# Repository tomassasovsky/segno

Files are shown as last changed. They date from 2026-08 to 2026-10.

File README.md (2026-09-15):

# Segno

A loopstation for recording and layering live music, with a Flutter interface, a native audio engine, and built-in foot controls.

Record a phrase, let it repeat, and add another part over it. Segno brings the recording controls, track state, and audio engine into one application. Its current product direction is a dedicated Linux appliance.

## See the interface

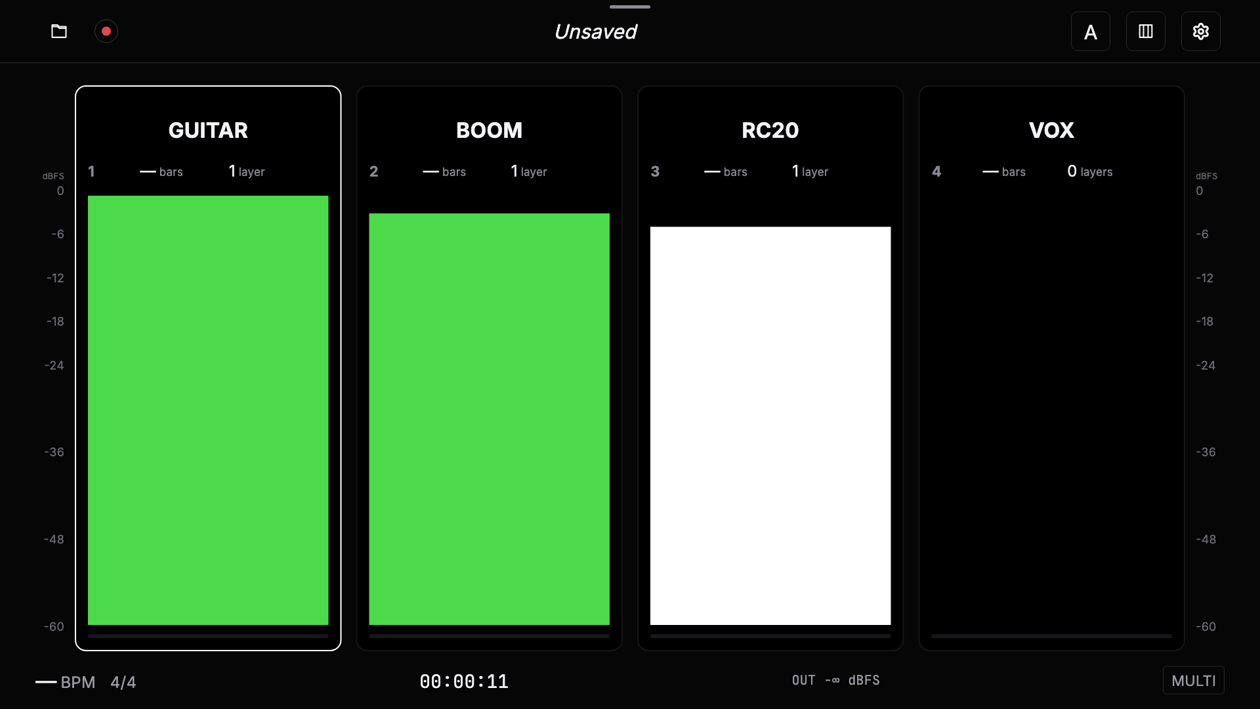
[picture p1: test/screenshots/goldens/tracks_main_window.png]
Segno’s Tracks interface showing four named tracks


*Flutter UI-test capture with simulated track state. Live audio demo pending.*

## Implemented capabilities

- **Record and layer audio.** The native engine implements loop recording, playback, overdubbing, undo, and redo.
- **Operate the looper by foot.** The console board connects ten footswitches, an encoder, and LED feedback to the app. External MIDI controllers use the controller mapping layer.
- **Save a session.** The session layer writes recorded audio and a manifest so the application can restore a loop’s state.
- **Keep the interface and audio engine separate.** Flutter handles the interface; a Dart engine interface connects the application to the native implementation through FFI.

## Explore the engineering

Created by [Tomás Sasovsky](https://github.com/tomassasovsky). The project includes the application, native audio engine, controller integration, pedal firmware, and hardware designs.

- [Audio engine and Dart interface](https://github.com/tomassasovsky/segno/tree/master/packages/segno_engine)
- [Console board and firmware](firmware/console_board/README.md)
- [Controller mapping](https://github.com/tomassasovsky/segno/tree/master/packages/controller_repository)
- [Session storage](https://github.com/tomassasovsky/segno/tree/master/packages/session_repository)

## Development and project status

Start with the [build and test notes](https://github.com/tomassasovsky/segno/blob/master/docs/PROGRESS.md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) for the development environment, native engine checks, and Flutter test commands.

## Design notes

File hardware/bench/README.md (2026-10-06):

# Bench tests

Tools that only mean something with hardware in front of you. They live here
rather than in `firmware/test/` because nothing in CI can run them.

| Script | What it proves |
| --- | --- |
| `midi_din_test.py` | The console board's two DIN MIDI sockets carry exact bytes in both directions ([#1007](https://github.com/tomassasovsky/segno/issues/1007)) |

---

## midi_din_test.py — DIN MIDI, after fitting the SN74AHCT125N

**Resolved on 2026-09-17: the OUT socket had DIN pins 4 and 5 swapped.** The
chip was not the cause. The test below is what proved it, and it is the test to
re-run whenever this wiring is touched.

The record of the September 4 session is
[`docs/research/2026-09-05-din-midi-bench.md`](../../docs/research/2026-09-05-din-midi-bench.md):
MIDI IN passed 48/48 bytes, MIDI OUT sent 48 bytes from the UART and the Scarlett
received none. U1 was fitted with an **SN74HC125N** where the design asks for an
**SN74AHCT125N**, which is a plausible cause and was never confirmed. This script
is that session's procedure, so the retest is one command instead of an evening.

### Before the swap, look at the panel

**The same chip drives the ring and the indicator pills** on this board (U1 gate B
and gate A; MIDI OUT is gate C). They work today with the HC part fitted. So if
the LEDs keep working after the swap but MIDI OUT still fails, the chip was never
the fault, and the DIN wiring or J4 is where to look next. Note what the panel
does now, before you change anything.

### Fit the part

1. Power the console down and unplug it. Fit the **SN74AHCT125N** at U1.
2. Read the top of the part: it must say `SN74AHCT125N`. `HC` is the part that is
   coming out; the letters are the whole difference.
3. Pin 1 goes where pin 1 went: the notch faces the same way as the old part and
   as the silkscreen. Check every pin sits in its hole before soldering.
4. Power up and confirm the ring and the pills still light. If they stopped, the
   part is in backwards or a pin is folded under the body — stop and fix that
   before testing MIDI.

### Cable it up

- Appliance **MIDI OUT** to the interface's **MIDI IN**.
- The interface's **MIDI OUT** to the appliance **MIDI IN**.

Check the labels on the sockets rather than trusting the last person's cabling:
the plugs were deliberately swapped during an earlier diagnostic.

### Run it

Copy the script to the appliance and run it there:

```bash
scp hardware/bench/midi_din_test.py root@192.168.50.124:/tmp/
```

```bash
ssh root@192.168.50.124 'python3 /tmp/midi_din_test.py --preflight'
```

`--preflight` changes nothing. It reports whether `/dev/ttyAMA0` exists, whether
`amidi` is installed, and which MIDI ports ALSA can see. If the UART is missing,
UART0 is not enabled: the earlier session applied the image's own `uart0-pi5`
overlay at runtime, and that does not survive a reboot.

```bash
ssh root@192.168.50.124 'python3 /tmp/midi_din_test.py --loopback'
```

The UART's internal loopback, with no board and no cables in the path. It proves
the script, the UART and the baud rate before any result about the board means
anything. The real test always runs with loopback off.

```bash
ssh root@192.168.50.124 'python3 /tmp/midi_din_test.py'
```

The acceptance test. Three trials per direction — notes 60, 61 and 62 — each one
sixteen bytes: note on, note off, three CC 22 values and a clock byte. It prints
every trial, the bytes when they differ, and the UART's own error counters. It
exits 0 only on a pass.

`--port` names the interface when more than one is connected (`--port scarlett`),
`--only in` or `--only out` runs a single direction, and `--uart` moves off
`/dev/ttyAMA0`. The pedal link's UART is refused by name — it carries the console
board's traffic and must not be reconfigured.

### What counts as a pass

**48 of 48 bytes in each direction, byte for byte, with no framing, parity or
overrun errors, and the internal loopback off.** Anything less is a fail, and a
direction that passes two trials out of three is a fail.

### If OUT still fails

The script prints the measurement list. In short: 5 V at U1 pin 14, enable
(pin 10) at 0 V, about 3.3 V on pin 9 and 5 V on pin 8 with TX idle, then
continuity from J4 through its 220 Ω resistors to the DIN pins. The bench doc has
the full connector map, and a DIN socket's front and rear views are mirrored —
read the pin numbers rather than inferring them.

### What this does not prove

That Segno sends or receives MIDI through these sockets. The app's MIDI input was
connected to ALSA Midi Through, not to this UART, and nothing here makes the UART
configuration persist across a reboot. That integration is separate work; raw DIN
traffic passing is only the hardware half.

Record the result on [#1007](https://github.com/tomassasovsky/segno/issues/1007),
including which cause turned out to be the real one.

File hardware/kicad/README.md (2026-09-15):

# Board generators

SKiDL scripts that emit KiCad netlists. One per board:

| script | board |
|---|---|
| `main_board.py` | standalone pedal — Pro Micro (ATmega32U4) |
| `ring_board.py` | encoder + LED ring + XIAO RP2350, behind the faceplate (4-way link, #987) |
| `console_board.py` | console v3 — Pico 2 on the Pi's GPIO (#747); v3 adds the 4-way ring link (#987) and the CTRL ring sense |

## Running them

```bash
python3.12 -m venv .venv && ./.venv/bin/pip install -r requirements.txt
cd hardware/kicad && ./.venv/bin/python console_board.py
```

**Run from `hardware/kicad/`.** `generate_netlist()` writes `<script>.net` into the
current working directory, so running from the repo root silently drops the netlist
in the wrong place while reporting success.

## Two things that will mislead you

**A netlist diff is not a design change.** SKiDL assigns a *random* `SKiDL Tag` to
every `Part` without an explicit `tag=`, and component `tstamps` derive from it. Two
runs of the **same** version on unchanged source differ by ~190 lines — all tags,
timestamps and the tool version string, with **zero** net changes. Pinning skidl does
not fix this. Judge a run by `0 errors found while running ERC` and the `(net ...)`
blocks, not by `git diff`.

**Prefer upstream footprints.** `segno.pretty/` exists for parts KiCad does not ship
(the NeoPixel Ring 24, the EC11 on its ring board, the module mount-pad and wire-pad
helpers). It is not a place to re-draw something that already exists. The Pico 2, for instance, is KiCad's own
`Module:RaspberryPi_Pico_Common_THT` — its description explicitly says it supports
Pico 2, and it is maintained upstream.

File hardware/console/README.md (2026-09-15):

# Segno Floor Console — hardware design

Hardware for the standalone Pi 5 floor console. The BOM is
[`hardware/segno_console_shopping_list.md`](../segno_console_shopping_list.md).
Footswitches, the encoder, the CTRL jacks, MIDI and the WS2812 drive all
terminate on the **console board v2** — a Pico 2 (RP2350) board on a short
keyed ribbon to the Pi's 40-pin header
([`hardware/kicad/console_board.py`](../kicad/console_board.py), #747). The Pi
reads no controls directly and never bit-bangs WS2812; the earlier plan of a
USB-MIDI pedal board plus a separate RP2040 LED driver is dead. The Pico runs
[`firmware/console_board`](../../firmware/console_board/), and
[`pedal_link.h`](../../firmware/console_board/pedal_link.h) is the wire format
of the link to the Pi.

> **Status:** the board is fab-ready (#747); the enclosure is designed under
> `hardware/enclosure/`; the assembled-unit gates (latency soak, stage-abuse)
> are physical work, tracked as the on-hardware checklist in
> [`docs/RUNNING_ON_RPI.md`](../../docs/RUNNING_ON_RPI.md).

## Power

Canonical since #754: **one 20 V USB-C PD contract at a rear-panel coupler,
two 20→5 V bucks split by rail** — BUCK_PI feeds the Pi (via its USB-C, 25 W
worst case), BUCK_AUX feeds both screens, the console board and the LEDs (34 W
worst case). No mains enters the enclosure; the fuse sits in the 20 V feed.
The full budget, the trim/window arithmetic, and the wiring live in
[`segno_wiring.md` §2](../segno_wiring.md) — this README no longer keeps its
own copy of the table, because two copies of a power budget is how one goes
stale.

Rules that survive any future edit:

- The LED chain must **not** draw off the Pi's 5 V pin (ribbon pins 2/4 are
  deliberately unconnected — the board's `PI_POWER` gate enforces it).
- WS2812 peak is ~60 mA/LED at full white; cap brightness in firmware to keep
  the worst case inside BUCK_AUX's budget.
- The Pi caps downstream USB at 600 mA unless `usb_max_current_enable=1` is in
  `config.txt` — required, the touch panels and audio interface hang off it.

## Thermals

A Pi 5 in a closed enclosure under sustained audio + dual-display GPU load will
throttle without help:

- **Active cooling is required** — the official active cooler or an equivalent
  heatsink+fan, with an intake/exhaust path in the enclosure.
- **Soak gate (on-hardware):** ≥2 h of audio + dual-display + GPU load in the
  closed enclosure with **no thermal throttle** (`vcgencmd get_throttled` stays
  `0x0`) and no xrun-rate regression. Record results in `docs/RUNNING_ON_RPI.md`.

## Enclosure

Designed and generated under [`hardware/enclosure/`](../enclosure/) (sheet
metal, printed platforms, rear-panel stations); `segno_enclosure_design.md`
carries the design story. The 16″ touchscreen and 7″ waveform panel mount up
top; the footswitch + encoder deck is the stomp face; the Pi and the console
board both sit under the 16″ screen with the rear I/O cluster directly above
the board.

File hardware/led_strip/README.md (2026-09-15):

# segno LED strip

> **NOT USED BY THE CONSOLE, and do not order it for one (#930).** The console's
> pill indicators are eight-LED segments cut from 144 LEDs/m bare strip, and the
> diffuser channel is sized for a 12 mm x 0.53 mm strip — this 16 x 8 x 1.6 mm
> board will not go in. `hardware/MANUFACTURING.md` carries it at quantity 0.
> The design below is kept because it is finished and may suit another build.

Single-LED WS2812B indicator puck for the Segno console: **one board per
indicator pedal**, sitting under that pedal's small pill diffuser slot in the
faceplate. One board is 16 x 8 mm, 2-layer, 1.6 mm, carrying **1x WS2812B
5050 addressable LED** (with its 100nF 0603 decoupling cap) and **castellated
half-hole pads on both 8 mm ends**.

```
 left edge                                right edge
 [5V ]──── +5V rail (top edge) ──────────────[5V ]
 [DI ]───────────D1──────────────────────────[DO ]
 [GND]──── GND rail (bottom edge) ───────────[GND]
           + full GND pour on the bottom copper
```

## How boards chain

Boards daisy-chain **pedal to pedal with three short wires** (5V / DATA /
GND, same pad order top-to-bottom on both ends — left-end DATA is DIN,
right-end DATA is DOUT) soldered to the castellated end pads. The
castellations also allow butting boards edge-to-edge (the LED sits 8 mm from
each end, so a butted pair keeps a 16 mm pitch) if a bar is ever wanted.

Console usage:

| row | pedals with LEDs | boards | LEDs |
| --- | --- | --- | ---- |
| above pedal 1 | MODE | 1 | 1 |
| front row | TRACK1..TRACK4 | 4 | 4 |
| mid row | CLEAR, BANK | 2 | 2 |
| per console | | 7 | 7 |

Feed 5V/GND once (seven indicator LEDs draw ~420 mA absolute worst case, far
less in practice). Data enters at DI on the first puck and daisy-chains
through every LED.

## Buy instead of build

Off-the-shelf single-WS2812B modules (round or square breakout pucks, sold in
tens for pocket change) are electrically identical — 5V/DIN/GND/DOUT, one
5050 — and drop into the same slots and wiring. This board exists for a
cleaner form factor and castellated wire pads; use whichever is at hand.

## Ordering (JLCPCB)

- 2-layer, 1.6 mm, any colour; the board is 16 x 8 mm — well under the
  100 x 100 mm cheap-tier limit.
- **Tick the "Castellated Holes" option.** The end pads are full plated 1.6 mm
  pads (0.8 mm drill) centred exactly on the board edge; the castellation
  process mills the edge through them leaving half-holes. Without the option
  the fab may flag the edge-breaking holes.
- Upload `out/segno_led_strip_gerbers.zip` (gerbers + Excellon drills).
- Parts if hand-placing: 4x WS2812B (5050 PLCC4), 4x 100nF 0603 per segment.

## Regenerating

The board is generated programmatically with KiCad 10's `pcbnew` module —
plain `python3` does **not** have it, use KiCad's bundled interpreter:

```sh
cd hardware/led_strip
/Applications/KiCad/KiCad.app/Contents/Frameworks/Python.framework/Versions/Current/bin/python3 ledstrip_pcb.py
```

This runs a geometry assertion suite, builds the board, fills the GND pour and
runs DRC via `kicad-cli` (the run fails loudly if DRC does), and writes to
`out/`:

- `segno_led_strip.kicad_pcb` — openable in KiCad
- `gerbers/` + `segno_led_strip_gerbers.zip` — fab package
- `drc.json` — full DRC report (expected: 0 violations, 0 unconnected)

All dimensions (LED count, pitch, rail widths, via rows…) are parameters at
the top of `ledstrip_pcb.py`; the netlist, routing and silkscreen are derived.

Design notes live as comments in the generator — in particular why the +5V
rail runs on the top edge and GND on the bottom (the WS2812B PLCC4 pinout
1=VDD 2=DOUT 3=GND 4=DIN puts VDD/GND on the package diagonal), and why the
data chain hops on the bottom copper (each LED's rail-to-rail decoupling cap
blocks the top-layer corridor).

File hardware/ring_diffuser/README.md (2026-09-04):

# Ring 16 snap-on diffuser — temporary bench part

A diffuser cap that clips onto a **16-pixel WS2812 NeoPixel ring** with nothing
else involved: no faceplate, no glue, no standoffs. The top face is **solid right
across**; the only opening is a Ø7 hole for the EC11's threaded bush. It exists
so a bare ring on the bench reads as a soft lit face instead of 16 point sources,
before there is any panel in front of it.

**This is not the console ring window.** That one is a Ø67 / Ø51.5 annulus cut
in the faceplate over a **Ring 24**, with the diffuser glued to the faceplate
underside — `RING_OD` / `RING_ID` in [`../enclosure/segno_enclosure.py`](../enclosure/segno_enclosure.py),
issues #791 / #794. The two parts do not interchange.

Generated by [`ring16_diffuser.py`](ring16_diffuser.py) (cadquery); run with the
enclosure venv:

```bash
../enclosure/.venv/bin/python ring16_diffuser.py
```

Outputs in `out/`: `segno_ring16_diffuser.step` (editable CAD) + `.stl` (print)
+ three SVG views. `segno_ring16_diffuser_skirt.*` is the no-hooks variant.

| | |
|---|---|
| fits | Adafruit NeoPixel Ring 16 (1463), Ø44.45 / Ø31.75, 1.6 mm PCB |
| part | Ø47.25 outer, solid face, Ø7 bush hole, 8.9 mm tall, ~3.3 g |
| face | 1.0 mm white PLA, 3.0 mm over the LEDs, 2.5 mm over the encoder body |
| holds on | 3 snap fingers, 0.5 mm under the PCB, 1.6 % strain |
| needs | **1.7 mm of air under the ring** for the hooks to swing under |

## Why the face can be solid

Because the EC11's own top face sits only **~0.5 mm above the LEDs**
(`ENC_FACE_RISE`, measured on the real assembly). Nothing in the middle is tall
enough to need clearing — only the bush carries on upward. That is the single
measurement this whole shape rests on, so the script asserts it: the roof
underside has to clear the encoder's body envelope, or `build()` refuses.

If your encoder turns out to stand proud of the LEDs by more than ~2.5 mm, raise
`AIR_GAP` and the face lifts with it.

### The bush hole

Ø7.0, as asked. Worth knowing: the console faceplate uses **7.2** for the same
encoder — *"M7 thread; 7.0 was nominal-tight, the vendor STEP shows the thread
OD needs the 0.2"* (`D_ENC`, #762). FDM holes also tend to come out under
nominal. If it will not pass the bush, that is why:

```bash
../enclosure/.venv/bin/python ring16_diffuser.py --enc 7.2
```

## Measure your ring first

Sellers ship "NeoPixel Ring 16" clones that are **much** larger than Adafruit's
— 68 mm and up. Electrically identical, mechanically a different part, and one
of those will not go on this cap. Put calipers across the ring before you print:

```bash
../enclosure/.venv/bin/python ring16_diffuser.py --od 68 --id 55 --pads 70 115 205 295
```

`--pads` matters as much as `--od` — and pass **every** pad, since the fingers
are placed in the gaps between the ones you name. Four evenly spaced pads leave
no three-way spread that encloses the centre; that case wants `--arms 4`, and the
assertion says so.

The three fingers are clocked into the gaps
between the ring's four **back-side** solder pads (JP1–JP4), which on the
Adafruit Ring 16 sit at **79° / 124° / 214° / 304°**, r ≈ 21 mm. Those angles are
lifted from `../kicad/segno.pretty/ModuleMountPads_4.kicad_mod`, which was
extracted from Adafruit's own board file for this exact ring — they are geometry,
not a guess, and they do **not** carry across ring sizes. A finger landing on a
soldered wire simply will not seat, so the script asserts the clearance and
warns when you feed it a ring that is not the one those angles came from.

## Print it

- **White PLA**, same call as the pill diffusers in the enclosure (#239). Not
  clear, not natural — white is what scatters.
- **Face down on the bed. No supports.** The face is a solid 1715 mm² disc, so
  the part is flat and well anchored — none of the stilt-warping that bit the
  mini tray. Both barb faces are 45°, so the fingers self-support.
- 0.2 mm layers are fine. The face is 1.0 mm ≈ 5 layers; **solid infill in the
  face** or light leaks through the sparse pattern as a visible grid.
- Do not iron it. The bed's own texture scatters better than a glassy face.

## Fit it

1. Check there is ~1.7 mm of clear air under the ring. Pin-mounted on the ring
   board or on standoffs, there is. **Flat on a bench or bonded down, there is
   not** — print `--skirt-only` instead. Note what that gives up: the hooks are
   the only thing holding the cap on, and the shroud is a **slip fit** (0.20 mm
   radial), so the no-hooks variant will lift straight off. If it has to stay
   put, tighten it — `--skirt-only --clr 0.05` — and expect to adjust once on
   your own printer, because ±0.1–0.2 of FDM tolerance on a Ø44 bore covers both
   "will not go on" and "falls off".
2. Drop it over the bush and line the three fingers up with the bare stretches
   of the ring's back, away from the four solder pads.
3. Press straight down until all three click. Spread them slightly by hand if it
   fights you — the fingers run at 1.6 % strain, which PLA is happy with for a
   handful of cycles, not fifty.
4. To remove: lever one finger out at a time. The 45° retention face is
   deliberately easy to release.

There is ~0.2 mm of axial play once it is on — the barb rests on the PCB's back
corner, and nothing pulls the cap down against a stop. It rattles a little and
diffuses the same. If your bush is long enough to reach past the face, the
encoder's own M7 nut will clamp the cap down and take the play out.

## Tuning

Everything worth changing is a constant at the top of the script.

- `AIR_GAP` (3.0) — the blending knob, and the encoder clearance. 16 pixels at
  r ≈ 19 mm are 7.5 mm apart, so 3 mm reads as *soft dots*. Raise it to 5 mm for
  a continuous band; the part grows by the same amount.
- `ROOF_T` (1.0) — thicker scatters more and passes less.
- `ENC_D` (7.0) — the bush hole. See above.
- `HOOK_ENGAGE` (0.5) / `ARM_T` (0.9) — grip vs. snap strain. `_check()` refuses
  anything over 3 % strain, so you cannot quietly design a finger that snaps off.

The script's `_check_clearances()` probes the finished solid: the bush passage
open end to end, nothing below the encoder's face plane inside its body
envelope, nothing sitting where the ring's PCB and LEDs live, and a face that is
solid at every radius from the bush hole out to the rim. It is there because a
bad boolean in CAD fails *quietly* — an early draft revolved the barb about the
wrong axis, produced a zero-volume solid, and the intersect handed back the full
pie wedges. That STL exported and rendered fine and was completely wrong.

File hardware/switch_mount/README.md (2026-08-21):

# Cherub WTB-006 silent switch platform

The printed platform that carries a silent switch inside a Cherub WTB-006
footswitch shell, replacing the pedal's own clicky switch (#729).

| | |
|---|---|
| Source of truth | Fusion document **"Cherub WTB-006 silent switch platform"** (Default Project) |
| Exports here | `switch_platform.step` (CAD interchange), `switch_platform.stl` (print) |
| Envelope | 66.85 x 57.38 x 10.60 mm, 8.06 cm3 |
| Print | PLA is fine — the part takes compression from the stem, not impact |

## Provenance

Authored **by hand in Fusion**, not generated. An earlier CadQuery attempt
(`generate_stl.py`, box-and-pins parametric) was abandoned: its default
`PIN_CLEARANCE` produced a 12.1 mm box whose stem overshot the pedal interior
by ~3 mm, so the lid could not close, and the fix was never settled. The Fusion
part solves the same problem at 10.60 mm. Do not resurrect the generator —
edit the Fusion document and re-export.

## Re-exporting after a Fusion edit

Open the document, then export the root component to both formats, replacing
the files here (STL: binary, high refinement). Keep the two exports in the same
commit so the STEP and the STL never describe different revisions.

## Still open on #729

The physical fit check. #729 is `blocked-verify`: it closes when a printed
platform is confirmed in the pedal shell with the lid closing and the switch
actuating at the intended pre-travel.

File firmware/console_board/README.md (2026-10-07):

# Segno console board v2 — Pico 2 firmware

The console's pedal firmware: `console_board.ino` on the board's Pico 2 (RP2350,
`hardware/kicad/console_board.py`, #747). A pure thin client, like the pedal it
replaces — it holds no looper state. It sends raw footswitch and encoder events
to segno over the link and renders the encoder ring and all ten eight-pixel indicator pills from
the state frames segno pushes back. segno runs the behavior machine.

| Signal | GPIO | Notes |
|---|---|---|
| Link TX / RX | GP16 / GP17 | UART0 → Pi uart3 (GPIO8/9, `/dev/ttyAMA3`), 115200 8N1 |
| Footswitches | GP2–GP11 | REC/PLAY, STOP, UNDO, MODE, TRACK1–4, CLEAR, BANK. Internal pull-up, active low, 8 ms stable-edge debounce |
| Ring data | GP12 | **v2 only**: via 74AHCT125 → J6 pin 5, one continuous 40-pixel GRB strip. On v3 (#987) the ring board clocks its own LEDs and GP12 is on the expansion header |
| Encoder A / B / SW | GP13 / GP14 / GP15 | **v2 only**: internal pull-ups plus the board's 10 k to the Pi's 3V3; one message per detent, decoded from pin-change interrupts. The push switch (SW) is active low and debounced like a footswitch (8 ms stable edge), one `ENCODER_BUTTON` message per press and per release |
| Ring link | GP13 / GP14 | **v3** (#987): full-duplex UART to the ring board's XIAO RP2350 — GP13 drives, GP14 listens, 115200, PIO UART (neither pin is on a free hardware UART). The console board's 10 k pull-ups hold both lines. **Not implemented in this firmware yet**: it still drives GP12 and reads GP13–15 as an encoder, which is the v2 board |
| Indicator data | GP18 | via 74AHCT125 → J7 pin 2, **80** GRB WS2812 pixels, eight per pill, sent with PIO/DMA |
| CTRL1 / CTRL2 tip | GP26 / GP27 | ADC0 / ADC1: a footswitch at the rails, an expression pedal's wiper between them. The first press on a jack the board has not yet classified is held 200 ms (a plug sliding in drags the tip low the same way); once the jack is known to hold a footswitch, edges are debounced at 8 ms and sent at once |
| CTRL1 / CTRL2 ring | GP20 / GP21 | On v3 a trace from each jack's ring through 4.7 kΩ (R19/R20). **Not a trace on v2** — one wire from each jack's ring pin to the J22 expansion pads does the same. With it, the B switch of a two-switch pedal (a BOSS FS-6's A&B jack) reports as `CTRL n · footswitch B` (its first press on a jack the board has not yet seen a switch on is held 200 ms, so a plug brushing the contact cannot fake it); without it the pin's internal pull-up holds it open and nothing reports |
| CTRL1 / CTRL2 present | GP19 / GP22 | Internal pull-down, **present = low**. On v3 the switched jack's tip-normal contact (Neutrik NJ6FD-V, through 4.7 kΩ R21/R22) drives it high only while the jack is empty; an empty jack reports CTRL kind `NONE` and is classified afresh on the next plug. On v2 these are J22's unpopulated pads: they float low, every jack reads "plugged", and the firmware's plug heuristics (a 40% jump starts a 200 ms quiet period; a jump that parks on the top rail for 1 s is an empty jack) do the same job less certainly |
| SMPS mode | GP23 | Driven high: PWM mode, less ADC ripple |
| PD trigger I2C | GP0 / GP1 | **v3** (J23): I2C0 SDA/SCL to the STUSB4500 on the SparkFun PD board, to read the negotiated contract (RDO 0x91–0x94, capability mismatch; voltage at 0x21) and report it up the pedal link. **Not implemented in this firmware yet.** On v2 the same read is possible from J22's GP20/GP21 when those pads are free |

## Physical rendering and source boundary

Firmware 1.13 uses public UART protocol 9 (protocol 8 plus `ENCODER_BUTTON`;
the STATE layout is unchanged). The physical renderer is reconciled
from PR #1079 (`ecea3af76fdb0708ca04632e260de5aa3fde09cd`), whose old-v2
firmware 1.11 used protocol 7 with a different 21-byte Song queue payload.
PR #1082 also uses public protocol 7 (and historical 6 for PD telemetry), with
a separate new-v3 pin map and private ring link. Neither format is accepted
here. Reconstructed Custom protocol 6 was a software intermediate and is not a
standalone hardware recommendation. Update this firmware and its matching app
together; no downgrade or compatibility format is emitted.

The fitted chain order is Track4, Track3, Track2, Track1, Mode, Undo, Stop,
Record/Play, Clear, Bank. The first eight groups enter from the right;
Clear/Bank enter from the left. Button IDs on the wire keep their existing
Record/Play, Stop, Undo, Mode, Track1–4, Clear, Bank order.

The app supplies every pill's active bit and RGB hue. Inactive means dark;
local switch contact, legacy track colors and mode do not override that fact.
Optical output retains the sourced peak 191, center weights
38/92/201/255/255/201/92/38, color gamma and total channel budget 6000.
The limiter recomputes from the source frame so refreshes do not progressively
dim the display. NeoPixelBus PIO/DMA preserves interrupts during the longer
80-pixel transfer. Forced refresh, goodbye and stale-link darkening cover the
whole chain. RGB black is a valid deliberately dark hue.

The independent 40-pixel ring retains the sourced sustained comet: 1100 ms per
turn, 30 lit positions, fractional circular interpolation, peak duty 192 and
color-only gamma. It freezes position/color on a stopped loaded loop, shows
master gain for 900 ms, and breathes green when empty. Ambient/startup output
retains brightness 96; every transfer has a total channel budget of 11520.
The combined estimated current is about 1.635 A including assumed pixel idle
and logic consumption. This is a planning bound, not a measured guarantee.
The app's semantic activity fields drive the ring independently of pill hue.

Only this physical renderer and its limits are sourced from #1079. Its Song
queue fields and progress-fill behavior, native audio changes, bench diagnostic
and CAD are excluded. New-v3 ring UART/PD firmware is a separate hardware
boundary. No physical deployment or electrical/optical validation is implied
by the host tests or a successful Arduino compile.

## Wire format: the pedal link

`pedal_link.h` / `pedal_link.c` is the whole protocol, plain C99, and it is
mirrored byte for byte by `PedalLinkCodec` in `packages/pedal_repository`. Every
message is one frame: `A5 <type> <len> <payload> <xor>`, where `xor` covers
type, length and payload. Plain 8-bit bytes — no MIDI, no 7-bit packing, no
version byte on the state frame; `HELLO` carries the protocol version so a
mismatched build shows up in segno's log and cannot exchange control/state.
STATE bytes 0–18 retain their current meanings; bytes 19–48 hold ten RGB
triples, and bytes 49–50 hold the physical activity mask (bits 10–15 must be
zero). The parser accepts exactly 51 bytes and preserves the last good frame
on malformed input. Logical track LEDs remain snapshot facts; they do not
compete with the ten-button mask for physical output.

| Type | Direction | Payload |
|---|---|---|
| `0x01 BUTTON` | board → segno | `button (0–9), pressed (0/1)` |
| `0x02 ENCODER` | board → segno | `int8 detents` (positive = clockwise) |
| `0x03 HELLO` | board → segno | `protocol, fw major, fw minor` — at boot and once a second; segno counts the board as connected while these keep coming |
| `0x04 CTRL` | board → segno | `jack, contact, kind, value` (unchanged four bytes) |
| `0x05 ENCODER_BUTTON` | board → segno | `pressed (0/1)` — the encoder's push switch, one message per debounced edge (protocol 9) |
| `0x10 STATE` | segno → board | 51 bytes: flags, mode, looper mode, global colour, bank, selected track, 8 track LEDs, loop length µs (LE32), master gain, ten RGB triples, active mask (LE16) — see `pedal_link.h` |

segno answers every compatible protocol-9 `HELLO` with its current `STATE`, so a board that just
(re)connected is current within a second; the board goes dark if no `STATE`
arrives for `PEDAL_LINK_FRAME_TIMEOUT_MS` (5 s) and on the goodbye flag, and
segno reads the board as disconnected after three silent hello intervals. Both
cadences live in `pedal_link.h`; the package's header test pins them. Frames the parser drops (bad type,
length or checksum) are counted on both ends; segno logs the count.

**Contract test.** `packages/pedal_repository` generates golden frames
(`test/fixtures/*.bin`) from the Dart codec; `firmware/test/run_tests.sh` decodes
and re-encodes every one with this C unit. Run it after touching either side:

```sh
bash firmware/test/run_tests.sh
# after changing the golden frames:
(cd packages/pedal_repository && flutter test tool/generate_golden_fixtures.dart)
```

## Build

Needs `arduino-cli`, the arduino-pico core (`rp2040:rp2040`, RP2350 support) and
`Adafruit NeoPixel@1.15.5` and `NeoPixelBus by Makuna@2.8.4`.

```sh
arduino-cli core install rp2040:rp2040 --additional-urls https://github.com/earlephilhower/arduino-pico/releases/download/global/package_rp2040_index.json
arduino-cli lib install "Adafruit NeoPixel@1.15.5" "NeoPixelBus by Makuna@2.8.4"
arduino-cli compile --fqbn rp2040:rp2040:rpipico2 firmware/console_board --output-dir firmware/console_board/build
```

`build/console_board.ino.elf` is what OpenOCD flashes; `.uf2` is for BOOTSEL drag-and-drop
if the module's USB is ever reachable (it is not, once the board is in the console).

## Flashing

The appliance does it. The image carries this firmware, an OpenOCD built for
the one adapter that reaches the board (`segno-openocd`), and a marker naming
the firmware version and link protocol the app expects; a oneshot before
`segno.service` listens for the board's `HELLO` and reprograms it over SWD only
when it is not already running what shipped (#989). So the two halves of a
build cannot ship out of step, and a board is repaired by a reboot rather than
by a laptop.

The board routes the Pi's GPIO24 (SWCLK, ribbon pin 18) and GPIO25 (SWDIO, pin
22) straight to the module's debug pads, so the Pi is the programmer. SWDIO
needs a pull-up the Pi firmware does not apply by default — `gpio=25=pu` in
`config.txt`, which the image sets.

To flash by hand during bring-up, on the unit:

```sh
segno-openocd -f /usr/lib/segno/console-board/pi5-swd.cfg \
  -c "program /usr/lib/segno/console-board/console_board.elf verify reset exit"
```

Point `program` at your own build to try a change; the next boot puts the
shipped firmware back, which is the intended behaviour — the image is the
source of truth for what the board runs.

## Talk to it from the Pi

With `dtoverlay=uart3-pi5` in place the link is `/dev/ttyAMA3` and segno opens it
itself (`UartPedalLink` in `packages/pedal_repository`). For a bench check
without the app, watch the hellos arrive:

```sh
stty -F /dev/ttyAMA3 115200 raw -echo
od -An -tx1 -w7 -v /dev/ttyAMA3    # a5 03 03 09 01 0d 05 (HELLO, protocol 9, fw 1.13), once a second
```

## Bring-up record

**2026-09-03, first unit.** Flashed over SWD from the appliance image (kernel 6.18,
RP1 = `gpiochip0`); OpenOCD found both Cortex-M33 cores, programmed and verified
the ELF, and the board came up on `/dev/ttyAMA3` at the first try. Verified on the
bench: all ten footswitches (clean DOWN/UP, correct order), encoder button, encoder
rotation (one message per detent, sign fixed so clockwise counts up), Ring 24 lap
in three colours and solid fill via J6, CTRL1/CTRL2 reading full scale through their
pull-ups with nothing plugged in — all with the bring-up text console this
firmware started as. Not yet exercised: indicator chain on J7 (no pucks
fitted), MIDI in/out (Pi side), CTRL jacks with a pedal, and the pedal-link
firmware itself against the app.

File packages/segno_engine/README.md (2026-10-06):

# segno_engine

Native low-latency **duplex audio engine** for Segno, exposed to Dart over FFI.

This is the data-layer foundation of the loopstation: a hand-written
[miniaudio](https://miniaud.io)-based engine that owns the real-time signal path
on the OS audio callback thread, with a typed Dart API for control and state.

> **Phase 1 scope.** Today the engine does duplex passthrough, level metering, a
> loopback round-trip **latency harness**, and ships the lock-free command-ring
> foundation. Recording, overdub, looping, and multi-track mixing arrive in later
> phases on top of this same boundary.

## The FFI boundary contract

```text
Dart (UI isolate)                         Native engine (C)
─────────────────                         ─────────────────
AudioEngine API  ──► le_engine_post_command ──► SPSC ring ─┐
                                                           ▼
snapshot() ◄── le_engine_get_snapshot ◄── atomics ◄── AUDIO CALLBACK THREAD
```

- **Commands** flow Dart → engine through a single-producer/single-consumer
  lock-free ring (`lockfree_ring.[ch]`), drained at the top of each callback.
- **State** flows engine → Dart through per-field atomics, read by
  `snapshot()` on a render-rate timer. Readers never dereference engine memory
  from the audio thread.
- Dart **never** blocks or allocates on the audio thread.

### Real-time safety rules (audio callback)

The audio callback (`le_engine_process` in `src/core/engine_process.c`) must
never:

- `malloc`/`free`, take a lock/mutex, or perform file/socket I/O;
- run an unbounded loop or call back into Dart.

All buffers are pre-allocated before the device starts. State is published with
relaxed atomic stores; control commands arrive only through the SPSC ring.

## Layout

The native sources under `src/` are grouped by concern:

| Path | Role |
| --- | --- |
| `src/core/segno_engine_api.h` | The C ABI consumed by ffigen (POD + opaque handle). |
| `src/core/` | The portable engine, split into per-concern TUs: `engine.c` (control-thread core + shared helpers), `engine_process.c` (the audio-thread TU — `le_engine_process`, transport, `apply_command`), `engine_fx.c` (effects DSP), `engine_commands.c` (control-thread setters), `engine_devices.c`, `engine_snapshot.c`, `engine_session.c`, `engine_convert.c`, `engine_digest.c` (SHA-256, file digests and directory sync; engine-free), `engine_miniaudio.c` (the miniaudio backend), plus the `lockfree_ring` / `loop_clock` primitives and the private/internal headers. |
| `src/platform/` | Per-OS device seams (`engine_apple.c` / `engine_linux.c` / `engine_windows.c`). |
| `src/midi/` | Native MIDI seam: `midi.c` (portable core) + per-OS backends. |
| `src/asio/` | Windows ASIO backend (`win_asio_device` / `win_asio_labels`). |
| `src/miniaudio/` | Vendored miniaudio (MIT-0 / public domain) + `miniaudio_impl.c`. |
| `src/test/` | Native unit tests + `run_native_tests.sh`. |
| `lib/src/audio_engine.dart` | `AudioEngine` interface (the test seam). |
| `lib/src/native_audio_engine.dart` | FFI-backed implementation. |
| `lib/src/generated/` | ffigen output — do not edit by hand. |

Every `src/` subdirectory holding headers is on the compiler include path
(`src/CMakeLists.txt`), so the sources use flat `#include "engine_private.h"`
regardless of which folder they live in.

## Building

The plugin builds automatically as part of `flutter run`/`flutter build` for
macOS, Windows, and Linux:

- **macOS** — compiled via `macos/segno_engine.podspec` (CoreAudio).
- **Linux** — `linux/CMakeLists.txt` → `src/CMakeLists.txt` (ALSA/PulseAudio/JACK
  loaded at runtime by miniaudio).
- **Windows** — `windows/CMakeLists.txt` → `src/CMakeLists.txt` (WASAPI; links
  `ole32`, `winmm`).

C11 is required for `<stdatomic.h>`.

### Regenerate FFI bindings

```sh
dart run ffigen --config ffigen.yaml
```

Requires `libclang` (ships with Xcode / LLVM).

### Run the native core tests

`src/test/run_native_tests.sh` builds and runs both native suites (engine + MIDI)
with the right per-OS toolchain flags and source/include paths:

```sh
bash src/test/run_native_tests.sh
```

It expects "ALL PASSED" from each suite. The engine source list it compiles
mirrors `src/CMakeLists.txt`; keep the two in sync when adding a TU.

## Usage

```dart
final engine = NativeAudioEngine();
final result = engine.start(const EngineConfig(sampleRate: 48000));
if (result.isOk) {
  final snap = engine.snapshot(); // levels, frame counters, latency
  engine.measureLatency();        // requires an output→input loopback
}
engine.stop();
engine.dispose();
```

## Latency measurement

`measureLatency()` emits a single full-scale impulse on the output and counts
the frames until it returns on the input, publishing the round-trip time via
`EngineSnapshot.measuredLatencyMs` (valid when `latencyState == done`). It
requires a **physical output→input loopback** (loopback cable or virtual
loopback device). With no loopback the harness reports `timeout`.

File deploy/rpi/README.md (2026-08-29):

# Segno floor-console kiosk deployment (Raspberry Pi 5)

Boots the Pi straight into Segno full-screen across both displays — 16″ main UI,
7″ waveform — under the **labwc** Wayland compositor chosen in Part 1. No
keyboard or mouse.

> **Status: unverified on hardware.** These units and scripts are written from
> the Part 5 plan but have not been brought up on a real Pi 5 + panels. The real
> acceptance gates — cold boot to the right panels, display pinning stable across
> ≥5 reboots, and usable per-panel scale — must be checked on hardware. See
> [`docs/RUNNING_ON_RPI.md`](../../docs/RUNNING_ON_RPI.md).

## Files

| File | Goes to | Purpose |
|---|---|---|
| `segno-kiosk.service` | `/etc/systemd/system/` | Boots the kiosk on tty1, respawns on crash |
| `boot-integrity-check.sh` | (unit `ExecStartPre=+`, root) | fsck + mount the writable data partition |
| `start-kiosk.sh` | (unit `ExecStart`) | Execs labwc, or shows the "needs attention" screen |
| `compositor/labwc/autostart` | `~/.config/labwc/autostart` | Pins displays, then launches the app |
| `compositor/labwc/rc.xml` | `~/.config/labwc/rc.xml` | Chromeless, maximized, no kill chord |
| `pin-displays.sh` | (run from autostart) | Deterministic output pinning by name |
| `profile-on-device.sh` | (run from your workstation) | Runs a profile bundle + tunnels the VM service for DevTools |
| `overlayfs/README.md` | — | Read-only root + writable data partition setup |

## Install

1. Build the release bundle:
   ```bash
   flutter build linux --release --target lib/main_production.dart
   ```
   segno builds only for the console now: no on-screen tracks toolbar (the
   foot pedals drive transport/mode/clear) and a layout fixed to the 16″
   panel. (The `build-linux-arm64` CI job guards that this compiles for
   arm64.)

   From a Mac (which cannot build a Linux bundle natively), run the containerized
   arm64 build instead — it wraps the exact command above and can `rsync` the
   result to the Pi:
   ```bash
   deploy/rpi/build/build-arm64-bundle.sh --deploy pi@<host>
   ```
   See [`build/build-arm64-bundle.sh`](build/build-arm64-bundle.sh) and
   [`build/Dockerfile.arm64`](build/Dockerfile.arm64).
2. Enable the labwc Wayland compositor (Pi OS default on Pi 5; confirm with
   `wlr-randr`, which must list outputs — see `docs/RUNNING_ON_RPI.md`).
3. Install the kiosk (systemd unit + labwc config) with the one-command installer,
   which sets it up for **your** user — no `pi` user required:
   ```bash
   deploy/rpi/install-kiosk.sh
   ```
   It substitutes your user/home/uid into the unit, copies the compositor config
   to `~/.config/labwc/`, sets the Pi to boot to console (so the kiosk owns the
   display), and enables the service. The boot integrity check is **opt-in** — a
   stock single-partition SD card boots straight to the app; set `SEGNO_DATA_DEV`
   only if you follow the read-only-root + writable-data-partition setup in
   [`overlayfs/README.md`](overlayfs/README.md).
4. **Edit `pin-displays.sh`** for your wiring: run `wlr-randr` to get the real
   connector names (e.g. `HDMI-A-1`, `HDMI-A-2`, or `DSI-1`) and set
   `SEGNO_MAIN_OUTPUT` / `SEGNO_WAVE_OUTPUT` and the per-panel scales.
5. Reboot. The unit starts labwc, which pins the displays and launches Segno.

## Display mapping & fallbacks

- **Pinning** is by connector name in `pin-displays.sh`, so the 16″ and 7″ never
  swap. The app's waveform second window lands on the secondary output; verify
  the actual window→output placement on hardware and adjust positions if needed.
- **Second-window failure is surfaced**, not silent: if the waveform window does
  not become ready, the app shows an operator-visible banner
  (`app_waveformWindowFailed_banner`).
- **Single display**: if only one display is connected, the app skips the
  waveform window and shows a notice (`app_singleDisplay_banner`) instead of a
  half-blank console. The Pi entrypoint wires the real display count
  ([`run_segno.dart`](../../lib/app/run_segno.dart)).
- **Per-display scale** is set with `wlr-randr --scale` in `pin-displays.sh`.
  Final values depend on the Part-6 HDMI-vs-DSI panel choice; tune on hardware.

## Profiling the UI on real hardware

The shipped bundle is **release-mode AOT** — no `kernel_blob.bin`, no Dart VM
service — so DevTools cannot attach to it, and the Yocto image is a pure runtime
with no `flutter`/`dart`/`gcc`/`ninja` so it cannot build a profile bundle
itself. macOS cannot cross-compile a Linux arm64 bundle either.

The containerized builder above (`build/build-arm64-bundle.sh`) is **release-only
today** — `segno-build.sh` hardcodes `flutter build linux --release`. Teaching it
a profile mode is the better long-term answer and would drop the CI round-trip;
until then the arm64 CI runner is the path that needs no local Docker.

1. Get a profile bundle from the `appliance-profile-bundle` workflow
   ([`.github/workflows/appliance-profile.yaml`](../../.github/workflows/appliance-profile.yaml)),
   which runs on demand or on any push to a `perf/**` branch:
   ```bash
   gh run download <run-id> -n segno-linux-arm64-profile -D /tmp/segno-profile
   ```
2. Run it on the device and tunnel the VM service to your workstation:
   ```bash
   deploy/rpi/profile-on-device.sh /tmp/segno-profile
   ```
   The script stops `segno.service` for the duration and restarts it on exit
   however the run ends, stages the bundle under `/data/profile` so the release
   install at `/opt/segno` and the ~1 GB rootfs are both left alone, and
   forwards the VM service to `127.0.0.1:8181` for DevTools.

**Read the result as a split, not a score.** UI thread over budget points at the
snapshot poll cadence and `context.watch` fan-out; raster thread over budget
points at missing `RepaintBoundary`s, the per-sample waveform rects, and card
elevation. Which half is over budget decides the work — see #638.

**Check the appliance is in a sane state first.** A full `/data`, a capture left
running, or a stale bundle all make the numbers measure something other than the
UI. `df -h /data` before you start.

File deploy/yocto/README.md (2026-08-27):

# Segno appliance — Yocto/weston image

The image the floor console boots: a lean Yocto build running the **prebuilt**
aarch64 Flutter GTK bundle under weston, with RAUC A/B updates over the Raspberry
Pi firmware's `tryboot`.

The shipping board is the **Raspberry Pi 5**, booting from NVMe. The Pi 4 is
retired (owner's call, 2026-08-25): its kas project is kept so the layer stays
honestly board-parameterised and the board remains buildable on request, but
nothing publishes for it and push/tag triggers do not build it.

| kas project | MACHINE | Boots from | `SEGNO_BOOT_DISK` | |
|---|---|---|---|---|
| `kas-segno-rpi5.yml` | `raspberrypi5` | NVMe in the M.2 slot | `nvme0n1` | **shipping** |
| `kas-segno-rpi4.yml` | `raspberrypi4-64` | SD card | `mmcblk0` | retired |

Everything the two share lives in **`kas-segno-common.yml`** — put changes there
unless they are genuinely board-specific. The boot device is a single variable
threaded through the WIC layout, the RAUC slot table and the per-slot
`cmdline.txt`, so those three cannot drift apart.

Origin: the Tier 3a spike ([#284](https://github.com/tomassasovsky/segno/issues/284),
child of #271). Pi 5 + NVMe: [#799](https://github.com/tomassasovsky/segno/issues/799).
Plan: [`docs/plan/2026-07-23-spike-tier3a-yocto-gtk-plan.md`](../../docs/plan/2026-07-23-spike-tier3a-yocto-gtk-plan.md).

## What's here

```
kas-segno-common.yml        shared: poky + meta-openembedded + meta-raspberrypi + meta-rauc (walnascar, commit-pinned)
kas-segno-rpi4.yml          raspberrypi4-64, SD
kas-segno-rpi5.yml          raspberrypi5, NVMe (+ dtparam=pciex1)
meta-segno/
  conf/layer.conf
  classes/tryboot-cmdline.bbclass                    rewrites root= per boot slot inside the .wic
  wic/segno-tryboot.wks.in                           A/B layout template (${SEGNO_BOOT_DISK})
  recipes-core/images/segno-kiosk-image.bb           core-image-weston + our bundle + GTK3/Mesa/ALSA
  recipes-core/images/segno-update-bundle.bb         the signed .raucb
  recipes-core/rauc/                                 slot table (templated) + keyring
  recipes-bsp/rauc-rpi-backend/                      tryboot bootloader backend
  recipes-segno/segno-bundle/                        installs the PREBUILT bundle + launcher + units
  recipes-graphics/weston-init/weston-init.bbappend  weston.ini: kiosk-shell + dual outputs
```

**No meta-flutter** — it has no GTK embedder (that's what 3b/ivi-homescreen is for).
This is a stock weston image plus our prebuilt bundle. **ALSA-only** (no
PipeWire/JACK → no `pw-jack`; the engine drives ALSA directly).

## Getting an image

### The easy way — CI

`appliance-release.yml` builds both the `.raucb` and the flashable `.wic`.
Dispatch it, pick the board, and download the image artifact:

```bash
gh workflow run appliance-release.yml -f channel=experimental -f runner=self-hosted -f board=rpi5 -f publish=no
```

The run publishes a `segno-image-<board>-<version>` artifact holding
`*.wic.gz`, its `.bmap` and `SHA256SUMS`. `board` defaults to **rpi5** everywhere, and on dispatch `publish`
defaults to **no**, so a bench build cannot move the OTA channel. Note push to
`experimental` and `v*` tags still publish — that is what they are for. Publishing any
board other than rpi5 is refused outright: `manifest.json` has no board field and
the client selects on version alone, so a channel can serve exactly one board.

### The local way — kas-container

Needs Docker Desktop (or colima/podman) with **≥120 GB disk, ≥16 GB RAM, 4–6
cores**. First build is **~2–5 h**.

1. **Build the aarch64 bundle** and stage it where the container can see it
   (under the repo, so kas's mount picks it up):
   ```bash
   deploy/rpi/build/build-arm64-bundle.sh
   mkdir -p deploy/yocto/prebuilt
   cp -a build/linux/arm64/release/bundle deploy/yocto/prebuilt/bundle
   ```
   (`deploy/yocto/prebuilt/` is gitignored — it's a 26 MB binary artifact.)

2. **Get `kas-container`** (Siemens' image runs **native arm64** on Apple Silicon —
   do **not** use crops/poky, which is amd64-only):
   ```bash
   curl -O https://raw.githubusercontent.com/siemens/kas/master/kas-container
   chmod +x kas-container
   ```

3. **Build:**
   ```bash
   ./kas-container build deploy/yocto/kas-segno-rpi5.yml
   ```
   Keep BitBake's `tmp/`/`sstate`/`downloads` **off** any `/Users` bind mount
   (VirtioFS is a perf cliff); kas-container's default in-container build dir is fine.

## Flashing

The image is ~8.4 GiB whatever the target size — two 3 GiB rootfs slots, two boot
slots, a 2 GiB `/data` seed. `segno-data-grow` expands `/data` to fill the media
on first boot, so a 1 TB NVMe ends up with ~990 GiB of user space.

Decompress **first**: Etcher has a bug where a compressed image yields an
unbootable card.

```bash
gunzip -k segno-appliance-*.wic.gz
diskutil list                      # find the target, e.g. /dev/disk5
diskutil unmountDisk /dev/disk5
sudo dd if=segno-appliance-*.wic of=/dev/rdisk5 bs=4m status=progress
sync
```

(or `bmaptool copy --bmap segno-appliance-*.wic.bmap segno-appliance-*.wic.gz /dev/rdisk5`,
which skips the unwritten blocks.)

### Pi 5: the EEPROM settings no image can carry

The bootloader EEPROM lives on the **board**, not on the drive. Nothing in the
`.wic` can set it, and reflashing never changes it. Do this once per board, from
whatever OS is on it now:

```bash
sudo rpi-eeprom-config --edit
```

```
BOOT_ORDER=0xf416
PSU_MAX_CURRENT=5000
```

- **`BOOT_ORDER=0xf416`** — right-to-left: `6`=NVMe, `1`=SD, `4`=USB,
  `f`=restart the loop. Without it the firmware never looks at the NVMe, and a
  perfectly good image is indistinguishable from a broken one.
- **`PSU_MAX_CURRENT=5000`** — declares a 5 A supply. A Pi 5 that can't confirm
  one budgets **600 mA across all USB ports combined**, which this console blows
  through with a hub, a touch controller, the pedal and the Scarlett. See
  [#740](https://github.com/tomassasovsky/segno/issues/740). Only set this behind
  a real 5 V/5 A supply — on a 3 A brick a loaded bus browns the board out.

The image side of the same two concerns is already baked into
`kas-segno-rpi5.yml`: `usb_max_current_enable=1` (stops the firmware capping USB
when it can't identify the supply — the EEPROM value above is the stronger half)
and `dtparam=pciex1`, without which the kernel never enumerates the NVMe
controller even though the firmware booted from it.

One mechanical trap while you're in there: the M.2 carrier's PCIe ribbon latches
at **both** ends, and a half-seated one enumerates intermittently rather than
failing outright.

### Hostname: the unit is `segno`

The appliance announces itself as **`segno`** (#496) — that is the name on the
router/AP client list (NetworkManager sends it in DHCP requests) and the SSH
prompt. Set as image policy in `kas-segno-common.yml`
(`hostname:pn-base-files`); older images announced the `MACHINE` name
(`raspberrypi5`, or `raspberrypi4-64` before the Pi 5 switch).

No mDNS ships (no avahi), so the name does **not** buy `segno.local` — connect
by IP unless your router resolves DHCP hostnames.

After updating a unit from an old-name image: `known_hosts` entries keyed by
the old name go stale (`ssh-keygen -R raspberrypi5`), but the dropbear host
keys live on `/data` and do not move — expect a re-learn under the new name,
never a key-change warning. IP-keyed entries are untouched.

## Iterating

App-only changes don't need a reflash — `rsync` the bundle to `/opt/segno` on the
running unit. OS changes go out as a `.raucb` through the normal update flow.

## When to bail to a cloud builder

The local container route usually works, but two things can make it painful:
**arm64-host recipe breakage** (any vendor layer shipping prebuilt x86_64 host
binaries) and the **Docker-on-macOS filesystem tax**. If either costs more than it
saves, build on the self-hosted Proxmox runner (`-f runner=self-hosted`) or a
native x86_64 Linux host — the reference arch Yocto/meta-raspberrypi CI validate
against.

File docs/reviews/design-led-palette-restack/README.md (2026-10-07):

# Reusable pedal LED colors

Pedals now includes an LED colors context for all ten physical switches. The
same custom color can be reused on several switches; editing it changes their
shared definition. Assignments and colors share one local draft with Save and
Cancel. The activity of an indicator continues to come from the actual function
state, independently of its hue and the pedal selected for editing.

Base: `27b13351a7ad43828a4bd83d14305ed5978572b4`.
Original proposal parent: `1e1dbc6088ccd438f5c3d93086c6cd6eef2d3310`.
The [source binding](source.json) covers implementation, tests, images and saved
Pen changes before these report-only additions.

## Behavior

- Eight named colors and reusable custom colors. Hue, Saturation and Brightness
  edit an exact RGB value. New setups use full white; black is a valid choice.
- Colors belong to physical switches across banks. Superseded by #1274: the
  palette applies only in Custom mode and only to Custom-assignable switches;
  Record, Mute and FX light in fixed state colours.
- Draft colors preview only in setup. The confirmed pedal frame is unchanged
  until a successful durable Save. Selection never changes the activity mask.
- Saving only colors preserves held contacts, pending Press/Hold gestures,
  accepted Hold ownership, delayed action results and the FX return context.
  Changing the actual assignments still retires those gestures.
- Stable custom IDs, detached immutable maps and canonical serialization
  prevent accidental changes through shared data. Malformed explicit palettes
  are refused through the existing unavailable-settings recovery path.
- Clear custom assignments and Restore retain later color and Track edits.
  Failed writes retain the existing durable rollback and uncertainty behavior.

The accepted hardware geometry is retained. Context buttons sit together above
the lower pedal row without overlapping Clear and Bank. Swatches remain
reachable by touch and encoder as the palette grows. The color editor uses
the shared slider and restores its preview when encoder editing is canceled.
All new strings are present in English and Spanish.

## Verification status

The full application suite passes 2,371 tests with six existing skips and
90.045% line coverage (20,397 of 22,652 lines), above the required 90%. The
source stayed unchanged during the final run. Formatting, strict analysis,
real Bloc lint across 672 files and whitespace checks pass. The one test-only
change after the first run also passes its focused static checks.

The first aggregate found a token-adoption scanner matching the saved hardware
RGB palette. Its existing, documented exception mechanism now names only that
model file: saved physical hues must stay independent of screen theme. Product
code did not change for that repair; the original failure log is retained.

An independent source reviewer completed the bug gate and five quality roles;
the five roles share one reviewer. A separate adversary passed nine model and
real-engine cases plus four widget cases, using expectations frozen before the
implementation. The adversarial report distinguishes fixture corrections and
unexecuted permutations from observed passing cases. No unresolved actionable
finding remains.

Nine setup images were generated and independently inspected. Native macOS
interaction confirms adding a custom color, sharing it between Mode and Bank,
Save and app restart retain the choices. A layout overlap caught in the visual
pass was fixed before the final source freeze. Pen contains the saved color
context and behavior note. These are author desktop/design checks, not device
proof. Remote CI still must pass on the exact published PR head.

No protocol, firmware, native audio or package source changes are part of this
slice. Their earlier checks are reused only after verifying unchanged source,
dependencies and workflow definitions. The current app uses protocol 8 and the
ten-indicator state established by PR #1031; obsolete protocol code is not
restored. No device was flashed. Physical brightness, perceived hue and
electrical behavior still need appliance validation.

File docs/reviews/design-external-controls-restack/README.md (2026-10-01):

# External pedals: complete setup and dispatch

Both CTRL jacks now offer Single, Dual and Expression through one setup page.
Each profile retains its own assignments. Switches support independent actions,
several effect activations and parameter values; expression supports several
heel/toe ranges and directed calibration. Missing targets remain visible for
repair. Draft edits do not affect saved configuration before confirmed Save.

The console UART route remains authoritative. The obsolete generic console
editor and calibration store are removed, while the separate MIDI route remains
available for its next slice. Contact edges, source absence, session changes and
refused writes share one dispatch owner. Accepted source state is distinct from
confirmed persisted state; failed storage remains visible and retryable.

## Evidence

The frozen 100-path candidate is in [source.json](source.json), based on
`63607bdba8e5a41359c83b45087204bec9ca1a2b`. Source hashes include new files,
deletions, firmware, goldens and the saved Pen. Public review documents are
additional evidence, not changes to the tested code.

- [Verification](verification.md): 2,467 app tests and five affected package
  suites pass; all required coverage floors pass, with no input drift.
- [Independent adversarial review](adversarial-review.md): 54 probes pass,
  including three failures reproduced before repair with unchanged assertions.
- [Source review](source-review.md) and the five quality-role reports: no
  unresolved actionable finding. One independent reviewer covered those five
  perspectives; a separate adversary performed behavioral execution.
- [Bug-focused gate](../../code-review/design-external-controls-restack/review.md).

Eleven External and nine parent-page author goldens pass. The native app was
checked after restart: independent Track 5/6 assignments survived, and Cancel
restored the saved Dual configuration after an Expression draft. Pen contains
12 matching native render references in its grouped External section; its save
and file hash were verified. Full older-canvas reconciliation remains M7 work.

Published-head CI is a separate readiness gate. This is not physical hardware
validation: contact bounce, electrical calibration, latency and no-presence-jack
unplug ambiguity remain bench checks. Nothing was flashed, deployed or merged.

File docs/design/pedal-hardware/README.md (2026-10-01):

# Pedal widget reference

The owner requested the actual hardware shape in the pedal setup comparison,
then clarified that it should be reconstructed as a reusable widget.

`pedal-hardware-widget.js` supplies the scalable vector face. Its enclosing
button owns selection, input events and encoder focus; the decorative parts
never add focus stops. The browser prototype supplies the physical label,
selected state and disabled appearance. No audio or physical switch dispatch
is implemented here.

The native Pen counterpart is **Hardware / Segno pedal face**. The accepted A
setup and new performance studies use instances with label, size and appearance
overrides. B and C remain superseded Pen references; A is the only live layout.

## Geometry and lettering

- The live **VAMP console (populated)** Fusion document supplied the case and
  top-pad measurements in `geometry.json`. The body is approximately
  76.35 × 109.87 mm, tapering toward the toe, with side hinges.
- The pad has five columns and six rows of raised grips. Its circular bases
  measure 8 mm in diameter, with 6 mm top surfaces. The widget simplifies
  lighting and bevels while preserving the arrangement and proportions.
- The label plate follows the manufacturing generator's trapezoid:
  54.359 mm at the back, 53.755 mm at the toe, and 19.90 mm long.
- `labels.json` contains outlines generated by
  `segno_enclosure._tile_ink`. Track pedals carry numbers; Record/Play and Stop
  use their physical symbols. The prototype loads these through
  `pedal-hardware-labels.js`, with no browser font dependency.
- PNGs are direct Fusion reference exports, not the UI implementation.
  `manifest.json` identifies the pedal and nameplate paired in each export.

The live Flutter counterpart is
`lib/control/view/pedal_setup/pedal_hardware_face.dart`. It keeps the measured
outlines and paint order while the enclosing setup map owns selection, focus,
labels and LED activity. Its fresh indicator color is RGB `FFFFFF`.

## Validation

Chrome and Firefox checks cover assignment editing, independent gestures,
bank isolation, Save/Cancel, keyboard selection, visible selected state and
single-stop encoder focus. The A and C layouts were visually inspected at
1920 × 1080. Native Pen text and instance counts are recorded alongside the
exported layouts. Physical display comfort remains unverified.

Fusion export isolated visibility temporarily. Geometry, appearances and
references were not changed, and the CAD document was not saved. Assembly
visibility was restored; the viewport was returned to a top view.

## Indicators and availability

The study widget supplies a decorative pill indicator with independent
`color`, `active` and `disabled` inputs. The map uses the hardware's visible
60 × 6 mm lens proportions. Selection belongs to the pedal face/encoder outline;
LED illumination follows the assigned function's active state.

Momentary functions illuminate while held; toggles remain illuminated until
the next activation turns the function off. The widget does not infer either
behavior from switch edges. The live app derives activity from its control
state and offers a color palette for every physical LED in Settings → Pedals.
Normal fixed actions remain disabled, even though their LED color can be edited.

The prototype and Fusion exports record the artwork's origin; the Flutter
setup map is the current application host.

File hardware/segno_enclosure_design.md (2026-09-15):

# Segno — sheet-metal enclosure for the segno Pi loopstation

A wedge-shaped folded-aluminium console that houses this repo's standalone build
(a Raspberry Pi 5 + the [console board v2](kicad/console_board.py), #747)
and **integrates ten foot pedals
into the chassis** the way the real "Chewie II" / Sonnit reference does. Form
(850 × 465 × 100 mm, top sloping toward the player) and layout from the reference;
internals are this project's. Branded **Segno**.

The deliverable is a **manufacturing package** (STEP + DXF + PDF) produced by the
parametric generator [`enclosure/segno_enclosure.py`](enclosure/segno_enclosure.py),
validated by an in-generator **assertion suite** (see §8). Decisions came from
[brainstorm](../docs/brainstorm/2026-06-27-segno-enclosure-brainstorm-doc.md) →
[research](../docs/research/2026-06-27-segno-components-research.md) →
[plan](../docs/plan/2026-06-27-feat-segno-enclosure-rework-plan.md) → technical review.

> **Integrated pedals.** The foot controls are ten **whole Cherub WTB-006
> footswitches** (109.87 × 76.35, 29.3 mm tall incl. anti-slip pads, caliper-
> measured — `hardware/cherub_wtb006_pedal/`), modded so their switch leads wire
> straight to the board. Each **stands on a printed pedestal**; the pedal
> protrudes through a ~79 × 116 mm slot (slot depth is slope-corrected: the slot
> lives in the 12.5° faceplate but the pedal is horizontal). **No top-face
> fasteners; no cables leave the box.**

---

## 1. Overall geometry & construction

| dimension | value | note |
|---|---|---|
| Width `W` | **850 mm** | reference footprint |
| Depth `D` | **397 mm** | sized to a comfortable gap behind the front row (no dead band) |
| Rear height | **100 mm** / front lip **12 mm** | low-raked wedge |
| Top slope | **12.5°** | sloped length 407 mm |
| Material | **2.0 mm 1050 aluminium** (shop stock, owner 2026-09-04) | bend R 2.0, K 0.33 |

**Construction = folded lower body + removable top lid.** **Nothing on this build
is welded.** `segno_base` is ONE flat blank: the bottom plate in the centre with
the front, rear and both side walls as flaps that fold up 90° on its four bottom
edges, and the rear flap folding a second time into the transition shoulder. The
four vertical corners are open butt seams closed by **riveted internal
L-brackets**. That keeps the whole shell inside a cut + bend + powder-coat
instant quote, with no fabrication step that needs a welder. The
**faceplate is a removable lid**. The faceplate is **not a bare plate** — it is a
shallow pan whose front lip, rear edge and **both sides fold down into skirt
flanges**, and the **screws go through those skirt flanges**, never through the
faceplate's top face. The lid drops over the body, **resting on the walls' inward
top flanges** (a support ledge), and M4 screws pass through each **wall web** into
the down-turned **lid skirt** behind it — so every fixing sits on a vertical face
(front lip + the two sides), hidden from the playing surface. Lifting the lid takes
the **screens, the encoder/ring PCB and the indicator LEDs** with it, while the
**pedals stay on their printed platforms** in the lower body (the slots clear the
pedals straight up) — so service is "back out the side + front-lip screws and lift
the lid," and the Pi/board are reached from the open top.

```
  REMOVABLE TOP LID                       FOLDED LOWER BODY (weld-free)
  └ faceplate pan (cutouts) + down-turned ├ front wall (12) + top flange (lid ledge)
    front/side/rear skirt flanges +       ├ rear wall (100) + I/O + vents + top flange
    screens + encoder/ring PCB + LEDs     ├ 2× side panel + top flange (lid ledge)
    (screws through the skirts)           ├ bottom plate (centre of the blank)
                                          └ 10× printed ring + sled + pedals
```

Per-edge intent: the wall **bottom edges fold** up from the bottom plate (they are
the same piece of metal, so there is no joint at all); the wall+side **top edges fold** to an
inward flange that the lid **rests on** (support ledge, no fixings on the top face);
the lid's **down-turned skirt flanges** take M4 screws driven horizontally through
the **wall webs** (front lip + both sides), so no fixing ever pierces the faceplate
surface.

---

## 2. Foot pedals on printed pedestals

Ten whole **Cherub WTB-006** footswitches stand inside on printed pedestals,
toe toward the player, protruding through the top slots — giving the
reference's piano-key look with no visible fasteners and the switch wiring
fully internal.

- **Slot:** `FSW_SLOT_W` 79.35 (u) × `FSW_SLOT_D` 115.61 (v) mm — the WTB-006
  envelope (76.35 × 109.87) + 3 mm clearance, with the slot depth divided by
  cos(slope) because the slot lives in the sloped faceplate while the pedal is
  horizontal. **No mounting holes** in the faceplate.
- **Pedestal = RING + SLED** since #719 (`segno_platform_front_ring` ×8,
  `_mid_ring` ×2, and ONE `segno_platform_sled` ×10). The pedal bolts to the sled
  on the bench, sled and pedal drop into the ring as a unit, and the **four
  existing chassis screws** pass up through clearance holes in the ring's floor
  and thread into the sled — clamping ring + sled + base plate in one joint, so
  the ring needs no fastener of its own and `segno_base.dxf` does not change.
  The ring's seat sits `CONSOLE_SLED_T − 1.0` below the old deck line, so once
  the sled is on it the pedal's CASE TOP still lands **flush with the slot's
  upper (rear) rim** exactly as `platform_h(v)` (front ≈ 15.2, mid ≈ 59.3 mm)
  put it — issue #373's rule is untouched, and an assertion holds the metal base
  to the same z to 1e-9 rather than trusting the arithmetic. Perimeter strips
  outside the opening are relief-shaved to ~0.3 under the real plate
  (drift-calibrated); side-screw bosses keep ~1 mm under the faceplate. The
  bottom anti-slip pad now comes **off** (the base holes are under it), so the
  1.2 mm pad pocket is gone and the joint clamps metal-to-plastic. The
  `PLATFORM_HEADROOM` assertion still enforces headroom against the local lid
  height.
- **Layout (two rows, per the reference):** a front row of **8 evenly-spaced**
  pedals (REC/PLAY · STOP · UNDO · MODE · TRACK 1–4) and an upper pair **CLEAR /
  BANK aligned in `u` over UNDO and MODE**, placed so the **front edge of their
  slot sits ON the 16" aperture's front edge** — the two pedals and the big
  screen share one hard bottom line (issue #796, owner call; this replaced
  #366's label-top anchoring, a soft glyph edge that lined up with nothing). **An LED pill indicator sits
  above EVERY pedal (10 total)** — the board's `indicatorLeds[7]` chain contract
  must widen to 10 (open firmware follow-up). The mid-row platforms are taller (the lid is higher there); the generator
  computes both heights and the depth assertions confirm the 16" screen fits behind.

> The `PEDAL_*` constants are **caliper-measured from a real WTB-006**
> (2026-07-28, issues #358/#360) — unlike the earlier ASP-1 placeholder they are
> no longer provisional. Pedestal **retention** was the last PROVISIONAL piece
> (pocket + gravity; no fastener engaged the pedal) — **retired by #719**: the
> pedal is now bolted to a sled with four M3s.
>
> **Base screw holes (issue #716).** The underside does carry four M3-ish holes
> after all, in two rows — the `PEDAL_BASE_*` constants. They sit *under* the
> anti-slip pad, so both rows are dimensioned off the **side screw axis**, the
> only datum findable without pulling the pad: rear row = axis **+4.0 toward the
> back**, front row = rear row **+80.0 toward the toe**, spans **55.75** (rear)
> and **53.00** (front), symmetric about the centre-line. Bolting through these
> is what will retire the PROVISIONAL retention above — but not before the
> **fit-test jig** proves the pattern on a print (§8).
>
> **The sled (issue #719) — shipped on BOTH the mini console and the 10-pedal
> console.** Those screws go DOWN
> through the base, so the head lands *inside* the pedal and the pedal must be
> open to be fastened. But the shell halves are held by one ~83 mm through-pin
> needing ~91 mm of clear axial run, and the widest gap beside a seated pedal is
> **12.4 mm** in either enclosure — so no wall shape fixes this; the neighbouring
> pedal is the blocker, not the tub. The pedal can therefore only be closed on
> the bench, which means it must be screwed down on the bench too. The deck comes
> out as a separate **sled** (`SLED_T` 7.0) the pedal bolts to, dropped into the
> tub as one unit and retained by a single M3 up through the tub deck. It is a
> `SLED_CLR` 0.2 mm/side slip fit with a 0.6 mm bottom lead-in chamfer — 0.5/side
> printed and seated but wiggled, and since the retention screw only clamps, the
> bore fit is the **only** thing locating the pedal. The clearance lives on the
> SLED (it derives from `SKIRT_IN_*`), so re-tuning it reprints a 19 g part
> rather than the tray. The tub
> deck drops by `SLED_DECK_DROP` = 6.0 so the pedal's metal base lands exactly
> where the pad-on design put it — **nothing above the base moves**, so the
> faceplate, the slot and the flush-at-rim rule are untouched. The bottom
> anti-slip pad comes off (it has to; the base holes are under it), which also
> means the joint clamps metal-to-plastic instead of through 2.2 mm of rubber.
>
> On the **10-pedal console** the ring is a free part, and a ring held only by
> the faceplate keeps 0.30 mm of vertical play — the buzz `SKIRT_GAP` already
> warns about. So it is **SANDWICHED**: the ring gets a floor, the sled lands on
> it, and the four chassis screws pass up through clearance holes in that floor
> into the sled. One joint clamps ring + sled + base plate; the ring carries no
> insert and no fastener. `CONSOLE_SLED_T` 12.633 (thicker than the mini's 7.0,
> because this sled takes M3×5 from **both** faces) leaves `RING_FLOOR` 1.6 on
> the front row and a tall deck on the mid row — same formula, only the front is
> tight. The four stations come from `platform_foot_xy()`, which the ring, the
> sled and `platform_foot_holes()` all read, so **`segno_base.dxf` is unchanged**
> — proven by diffing it to zero substantive lines after the refactor.
>
> **The mini tray is symmetric about `CX = Wt/2`.** It used to inherit the
> pedals' absolute console `u` with its left edge at 0, which left the pair
> 1.74 mm right of centre: the right tub fused into its wall while the left
> needed a filler block, and every hard-coded x — anchors, feet, ribs, lid tabs —
> was tuned around that. Only the *pitch* has to be faithful, so the width now
> follows from the pitch and every x is `CX ± something`; both tubs fuse and the
> filler is gone (195.29 wide, was 198.775). `MINI_SYM` holds it by splitting the
> solid at `CX` and comparing the halves' **mass properties** — volume, centroid
> and inertia tensor. Not by cutting the solid against its own mirror: when the
> part is symmetric the two are geometrically identical, every face is
> coincident, and OCC's boolean returns *empty*, which reads as "totally
> asymmetric" and is the exact opposite of the truth.
>
> **The lid now sits flush on all four sides.** As a flat plate raked to 12.5°
> with square-cut edges, its top face used to stand `T·sin` = 0.43 mm proud of
> the front wall and 0.43 mm shy of the rear, and its square plan corners
> overhung the tray's R6 fillets by `6 − 6/√2` = 1.76 mm. Both dated from the
> first tray. Fixed in one exact operation rather than two computed bevels: the
> lid is built `T·tan` longer at the rear, then — **in the seated frame** —
> intersected with a vertical prism of the tray's own plan outline. Front and
> rear come out plumb and the corners land on the tray's radius at *every*
> height, which a fillet applied in the flat frame could not do (it would rake
> over with the plate). `MINI_FLUSH` holds the seated bbox to the tray outline.
>
> **The case is a wedge in plan, not only in height.** `PEDAL_W` 76.35 is the
> width at the **back edge**; it tapers to `PEDAL_TOE_W` 73.08 at the toe, so a
> clearance quoted off `PEDAL_W/2` is understated by up to 1.63 mm per side.
> Anything sitting close to a side wall must ask **`pedal_half_width(x)`** where
> along the case it actually stands — the faceplate slot already reasons this way
> (its real per-side clearance is ≥1.15, not 1.0), and the fit-test jig's columns,
> scribed outline and clash stand-in all do now too.

---

## 3. Top faceplate — control layout (Chewie-II)

`u` = 0…843 L→R (player's left→right), `v` = 0…468 front→rear.

| feature | qty | size (mm) | maps to |
|---|-----|---|---|
| WTB-006 pedal slot | 10 | 79.35 × 115.61 | 8 front (evenly spaced) + CLEAR/BANK over UNDO/MODE, no fasteners |
| indicator LED pill | 10 | 60 × 6 slot | one above every pedal (#366; `indicatorLeds` chain must widen 7 → 10) |
| 7" touchscreen | 1 | 156 × 88 aperture | waveform / loop view (left), top-aligned |
| 16" touchscreen | 1 | 350 × 199 aperture | main segno UI (right), top-aligned |
| encoder + diffused ring | 1 | Ø7 + Ø58/40 | centred under the 7" screen at `ENC_V` (does NOT follow CLEAR/BANK rearward — it would hit the 7" screen); EC11 + 12 THT LEDs |
| power / mode LED | 2 | Ø8 | bezel, flanking the encoder |

- **Screens mount from behind**; the aperture is **smaller than the bezel** so the
  monitor clamps against the panel. They are retained by **printed stands anchored
  to the base floor** (#762), not by sheet-metal brackets — the old
  `segno_screen_bracket` parts were dropped (see `MANUFACTURING.md`). The
  16" is a ViewSonic TD1655-class portable touch monitor (355 × 223 × 15 mm).
- **LEDs are 5 mm through-hole, cabled.** The ring is a cut annulus with a diffuser
  + 12 THT LEDs behind.
- **No logo cutout** on the panel (removed). "Segno" remains the product/drawing name.

---

## 4. Rear I/O & ventilation

Rear wall (`u` = 0…850, `z` = 0…90). **There is no I/O window and no bolt-on
sub-panel** (#743): the Pi moved inboard and every connector is a panel-mount
part fitted straight into the wall — which is a **folded face of `segno_base`,
not a welded panel** (`segno_base` is one blank: floor + 4 walls, weld-free,
corner brackets rivet). Losing HDMI / Ethernet / SD access from outside is
deliberate — reflashing or a wired network means opening the case.

Nine stations on one centreline at `REAR_IO_Z` (= wall mid-height, 45), left to
right, power first and away from signal:

| ref | cutout | keep-out | note |
|---|---|---|---|
| `PD_IN` | Ø24 D punch + 2 × Ø3.2 diagonal @ 19×24 | 30.4 | USB-C PD coupler (QIANRENON, #754) — the SAME D punch + M3 pair the TRS jacks use; the 9 V DC-099 barrel died with the 9 V architecture |
| `POWER` | **Ø19.5** | 29.2 | APIELE 19 mm **high-round** momentary, stainless. **Unlit**; M19 nut, no screws |
| `FUSE` | Ø12.0 | 18 | generic 5×20 screw-cap holder, 10 A / 250 V AC; panel nut, no screws |
| `MIDI_IN` / `MIDI_OUT` | Ø15.1 + 2 × Ø3.2 @ 22.2 | 28.6 | REAN NYS325 (pitch = RS "Mounting Hole Distance 0.874 in"); **IN needs opto-isolation on the board**, not here |
| `CTRL_1` / `CTRL_2` | **Ø24** + 2 × Ø3.2 diagonal @ 19×24 | 30.4 | **D-series** punch (MEIRIYFA), not a threaded bushing |
| `USB3_1` / `USB3_2` | 22.5 square, **R8.84** | 28.5 | PENGLIN M24 bulkhead: a round barrel with two flats, **nut-mounted, no screws** — the square cut grips the flats; flange Ø28.5 is the keep-out, not the hole |

The keep-out column is the **nut, bezel or flange a spanner has to clear**, not
the hole — for the USB coupler that is 6.4 mm wider than its own cutout, and
spacing on cutouts alone would have the two flanges fouling. `rear_io_layout()`
spreads the nine across `REAR_IO_SPAN` = 360, left-justified against `EDGE`, with
**equal clear gaps** of 15.99 mm.

> **The TRS is D-series.** The chosen jack (MEIRIYFA, "fits standard D Series
> panel mount designs") takes the Neutrik D punch — Ø24 with an M3 pair — not the
> Ø10 round hole a threaded-bushing jack wants. Neutrik's own datasheet calls it a
> "standardized D sized 24 mm panel cutout". This was wrong in the first cut of
> the panel and is the reason `REAR_IO_KEEPOUT_CONTAINS` exists (below).
>
> **Any substitute must also be D-series.** A plain threaded-bushing 6.35 chassis
> jack — the default in most shops — wants ~Ø10 and has nothing to clamp in a Ø24
> punch. The genuine article is the **Neutrik NJ3FP6C**, which is also *latching*,
> so a kicked control-pedal lead cannot pull out; it drops straight into this
> cutout.

That swap took the TRS keep-out from 16 to 30.4 and squeezed the old 290 mm strip
to 7.2 mm gaps, so the cluster was widened to 360. That was only possible because
`REAR_IO_U` used to do **two** jobs — placing the window *and* anchoring the
board, Pi and buck. They are now split: `BOARD_ANCHOR_U` (175) keeps the internal
layout exactly where it was, so a rear-panel change cannot move anything inside.
The width comes out of the vent block, which drops 70 → 63 slots and still runs at
14 880 mm² against a 4 000 minimum.

**22.1 / 24.1 are the coupler's BODY, not the hole it wants**, so the cutout is
body + `USB3_FIT` = **0.2 per side → 22.5 across flats, 24.5 across corners**.
That is deliberately the tight end of a panel fit, because the errors are not
symmetric: too tight is one hole eased with a file in a minute, while too loose
either rattles under the Ø28.5 flange or — if the coupler turns out to be a
snap-in — never grips, and that cannot be undone on a cut blank.

The corner radius is **derived, not typed**: `_rr_from_corner_circle()` solves the
across-flats / across-corners pair, giving **R8.836** and only 4.83 mm of straight
edge — that cutout is much closer to a circle than to a square, which is worth
knowing before someone "fixes" it.

**The D-series fixings ARE cut, on the sourced diagonal.** The two M3 sit on
*diagonally opposite* corners of the flange, not on a horizontal pair. The
pattern was sourced 2026-08-18 from the QIANRENON PD coupler's own listing —
"D-type panel mounting dimensions (19 mm × 24 mm)": hole centres at (±9.5, ∓12)
about the bore, one per diagonal. That puts each screw centre 15.3 mm from the
bore centre, 1.7 mm of land clear of the Ø24 bore + M3 radius, so the land gate
(now measuring the true 2-D distance, not just Δu) passes. The widely-repeated
flat "24 mm" pitch remains provably wrong — on a Ø24 bore it puts the centres on
the bore edge. A D shell is point-symmetric about its bore, so a part whose holes
run the other diagonal mounts by turning it 180°; one cut diagonal fits all of
them. The same pair serves `PD_IN`, `CTRL_1` and `CTRL_2`.

### Gates

Seven, all negative-controlled. The important one is **containment**: each station's
own cutouts must fit inside the keep-out it reserved. Without it a station can
reserve less than it cuts and the overlap check passes *on a lie* — which is
exactly what a Ø24 bore behind a Ø10 keep-out did. Next most useful is **land**:
a fixing hole must leave ≥1.5 mm of metal against its own bore, which is what
disproved the 24 mm D-series pitch. The rest: no two keep-outs overlap, none
crosses `EDGE`, the cluster centre really is `EDGE + span/2`, the gap to the first
vent column still fits the earth stud plus a spanner, and the widest keep-out
leaves 4 mm of wall above and below.

### Provenance — every dimension says where it came from

`REAR_IO_PROVENANCE` tags each number `measured` (user's calipers), `datasheet`
(with the source named) or `UNCONFIRMED`. `rear_io_unconfirmed()` returns the
unsourced ones and the build prints them as a **`DO NOT CUT`** line; a gate
refuses any rear-I/O dimension with no entry at all, so a new connector cannot be
added without declaring where its numbers came from.

Currently unconfirmed — **`D_TRS_SCREW_PITCH`** and **`MIDI_SCREW_PITCH`**, both
fixing pitches. Every bore on the wall is now sourced.

### Power button and fuse

Both were the last stations with no component behind them (they predate #743 and
were briefly mis-recorded as "datasheet: generic …" — "generic" is not a datasheet,
and that was exactly the false authority this table exists to catch). Resolved:

**Button — [APIELE 19 mm high-round momentary](https://www.amazon.com/dp/B079HTQ7XD),
$8.99/2 = $4.50 each.** Stainless, IP65, M19×1, screw terminals, 1,000,000
mechanical cycles, 3-year replacement warranty, **4.7★ over 1,039 reviews**. It
ships a full dimensioned drawing: hole 19 (M19×1), hex bezel **21.9 across flats /
25.0 across corners**, Ø14.1 dome face, 6 mm of dome proud of a 3.5 mm bezel,
24.4 behind the panel.

Chosen over the [UL+CE ZJWZJH](https://www.amazon.com/dp/B09CCPDC1C) at **half the
price**. That part is nicer on paper — UL + CE listed, IP67/IK10, 316 head — but
none of it earns its keep here: this switch is a **dry contact to the Pi's own
3.3 V power-button pads**, not a mains switch on a wet deck, so the certification is
irrelevant to
safety and IP67-vs-IP65 is moot on an indoor rear panel. Against that, APIELE has
1,039 reviews at 4.7 versus 9 at 3.9, and a *taller* head — more dome, more feel.

> **The two constants deliberately bracket both candidates**, so the choice never
> re-cuts the panel. `D_PWRBTN` = **19.5**: an M19×1 thread needs more than 19.0 to
> pass, APIELE's drawing says "19" and ZJWZJH's says Ø19.5, and a Ø25 bezel covers
> the slop either way — cutting 19.0 would jam the ZJWZJH. `PWRBTN_HEAD_D` =
> **25.2**: across hex *corners*, ZJWZJH 25.2 / APIELE 25.0.

**Fuse — a generic 5×20 screw-cap panel holder**, e.g.
[NeoLum, 4 pcs $7.69](https://www.amazon.com/dp/B0GF33P9FF). Generic **by
decision**: it is a small black cap on a rear panel, the one station where generic
costs nothing to look at. Plastic body with a metal cap, which is also the right
way round — an insulating body around a live fuse inside an earthed metal chassis
beats a metal one. 10 A / 250 V AC, far above this job.

`D_FUSE` = **12.0**, from two independent listings ("12 mm diameter aperture";
"Installation Hole 12mm").

> **That 0.5 mm is the whole point of naming the part.** The
> [SCI R3-11](https://www.amazon.com/dp/B0752BGGRY) — the bayonet-cap holder used
> on guitar amps, nickel hex bezel, solder lugs — wants **Ø12.5**, and the panel
> was briefly cut for it. The error is not symmetric: a 12.5 hole around a 12.0
> thread sits loose and lets the holder **spin when the cap is turned**. So the
> hole follows the holder, never the other way round. If the SCI is ever wanted
> back, `D_FUSE` goes to 12.5 and the panel must be re-cut.
>
> **"Generic" is a class, not a part.** 12.0 holds across the screw-cap holders
> checked, but if a different one is bought, read its stated aperture before the
> panel is cut — this is the cheapest station on the wall and the only one whose
> exact part is not pinned.

> **Rating.** The input is **20 V USB-C PD** (#754): the 59 W worst case is
> ~2.95 A on the 20 V side (~3.3 A with buck efficiency), and these holders are
> **10 A / 250 V AC** — no rating problem. (An earlier 9 V-era note here worked
> the same conclusion from the dead architecture's numbers.)
>
> Fuse: **T5A slow-blow** (T5AL250V). Above the ~3.3 A coincident peak, at the
> 5 A PD contract ceiling, well under the holder's 10 A. **Slow-blow is not optional** —
> two bucks charging their bulk caps draw a large inrush, and a fast-blow fuse
> will nuisance-blow at switch-on. A
> [12-value T assortment](https://www.amazon.com/dp/B08779766V) is worth it over a
> single value: start at T5A and step up only if real measured draw says so.
>
> **Nothing on this unit hard-breaks power.** The button is a momentary contact on
> the Pi's own PWR pads — *not* a GPIO input, which on a Pi 5 could not do this job
> at all (RP1 and the SoC are unpowered until the PMIC brings them up); pulling
> the USB-C PD inlet is the only true off (the 9 V barrel died with the 9 V
> architecture — see `PD_IN` above). Deliberate, but worth knowing.

> **Fallout to settle separately:** the `nopi` build (external host, HDMI ×2 +
> USB touch ×2) had no home but that window, so it is **retired** — an
> external-host variant would now need its own rear-wall DXF. And `PI_RISER_H`
> (35.30) existed only to centre the Pi's port stack in the window; it is kept
> unchanged so this change does not move the internal stack, but it is now
> vestigial.

### The rear bay — where the Pi went (#743)

Removing the window did not just change the wall; it changed what has to fit
*behind* it. The Pi used to sit at `(BOARD_ANCHOR_U, bd − 56)`, putting its PCB
port edge **3.5 mm** off the plate's rear edge — correct while a window existed,
because its own USB/Ethernet stack poked through. With the window gone that stack
faces solid folded metal, and those 3.5 mm are exactly where nine connector bodies
and their wiring now live.

`REAR_CONN_DEPTH` = **45 mm**: deepest body ≈30 (D-series TRS, fuse holder), solder
lugs ≈5, wire bend ≈10.

**Sliding it straight forward was not the answer.** It fixed the depth but parked
the Pi on top of the main board with 4.3 mm of head, which made the bespoke 35.3 mm
riser load-bearing — one taller connector on the board and it fails.

**Moving it sideways, onto the floor under the 16" screen, is strictly better** —
and **rotated 90°** while it is there. The Pi 5 carries USB-A ×4 + Ethernet on one
56 mm edge and USB-C + both micro-HDMI on an 85 mm edge. Unrotated, that port edge
faced the **rear**, which made sense pointing at a window and makes none now:
every cable goes **left** — panel USB couplers (u 332/376), buck (u 300), 7" screen
(u 42…196) — and only the 16" screen is overhead. Rotated, the ports face −u and the
runs are straight; depth also drops 85 → 56, buying back rear-bay clearance.

Final position `(SCREEN_16_U, bd − 106)` = **u 625.3, v 313**, hole rect 58 × 49:

| | |
|---|---|
| PCB footprint | u 572.8…657.8, v 285…341 (85 along u, 56 along v) |
| clear bay behind it | **78 mm** (≥45 gated) |
| free height under the screen module | **71.4 mm** against a **44.2 mm** stack |
| stacked over anything | **nothing** |

**The stack now includes the NVMe board and the cooler.** `PI_STACK_H` = 44.2 =
`STANDOFF_H` 15 + `PI_N07_H` 11.6 + PCB 1.6 + `PI_TALLEST` 16. The GeeekPi N07
(B0CWD266XR) is a **bottom** board on an FPC, so it costs height, not footprint;
its 11.6 is the N07 PCB plus the standoffs that lift the Pi over its 2280 SSD. The
official Active Cooler is ~10 above the PCB, so the **USB-A double stack still sets
`PI_TALLEST`**, not the cooler.

That bay was simply empty: the main board, the buck and both mid-row pedestals all
sit left of u 454. And because nothing is stacked, **the bespoke riser disappears** —
`PI_RISER_H` drops from 35.3 to `STANDOFF_H` (15), the same plain M2.5 standoff the
main board uses. One fastener kind instead of two, a lower stack, more air over it,
and it now sits directly in front of the rear exhaust vents.

Cost, for the record: the run to the USB couplers gets ~250 mm longer, and the 7"
HDMI lengthens while the 16" shortens.

> **The buck stays where it is, and that is correct.** It sits inside the 45 mm
> bay, but its clearance is *vertical*: connectors are centred `REAR_IO_Z` up the
> wall, so the lowest metal on the widest of them is at **z 29.8**, and the buck is
> a 22.1-tall brick bolted flat to the floor — it passes 7.7 mm underneath. The Pi
> could not do that trick on a riser, which is what forced it to move in plan.
> Gated, so it is not a shrug.

Four gates hold all of this, each negative-controlled: rear-bay depth, no stacking
(**in both axes** — an earlier version checked only `v` and fired on a Pi 400 mm
away in `u`), the Pi footprint staying inside the screen bay, and the stack fitting
under the screen module.

**Ventilation** (Pi 5 ≤ 12 W; Active Cooler ramps 60/67.5/75 °C): a rear exhaust
vent block + a bottom-plate intake array give ≈ 17 000 mm² open area (`>` the
4 000 mm² floor the `VENT_FREE_AREA` assertion checks). The Pi mounts on **M3
standoffs ≥ 10 mm** off the bottom plate for under-board airflow and Active-Cooler
intake.

**Grounding:** the shell is FOLDED, so walls and bottom plate are literally the
same piece of metal — continuous by construction, no joint to bond across. The
joints that *do* exist are the four riveted corner brackets, and those are
mechanical: powder coat is an insulator, so a rivet through two coated faces is
not a reliable bond. Corner-bracket **faying surfaces must be masked** along with
the bottom-plate perimeter pads, and the rear earth stud is the bond point.
(Previously this paragraph argued from "welded joints are continuous" — true of a
welded shell, and not the shell that gets built.)

---

## 5. Internal mounting & the bottom plate

The pedal platforms hang from the walls at the front + CLEAR/BANK rows, so the
**rear strip of the bottom plate is the clear floor** for the electronics — and the
16" screen above it is shallow (mounts to the faceplate, ~18 mm deep), leaving head
height. The **Raspberry Pi and the console board v2 mount there on
standoffs** (≥ `STANDOFF_H` for under-board airflow), linked by the keyed 2×20
ribbon (~10 cm; they sit side-by-side). The **EC11 ring board** mounts to the
faceplate underside behind the encoder cutout; the **screens** clamp from behind
against **printed stands anchored to the base floor** (#762) — not sheet-metal
`screen_bracket` parts, which were dropped (see `MANUFACTURING.md`).

The **bottom plate** (`board_mounts()` drives the patterns) is the CENTRE of the
folded blank — the wall bottom edges are its own fold lines, not a joint — and carries: the **Pi** (58 × 49) and
**console board v2** (89.5 × 89.5 M3 — the number comes over the
`console_board_mount.json` seam, gated by `BOARD_MOUNT`, not copied by hand)
standoff holes in the rear; an **intake-vent block** in the clear gap between the
two platform rows (air crosses the boards to the rear-wall exhaust); and 4 rubber
feet. The electronics are reached from the **open top** once the lid is lifted.

**Rubber feet (#743).** Screw-on, not adhesive — glue lets go eventually on a
thing that gets kicked. The part is a **uxcell buffer foot, Ø18 (chassis face) ×
Ø15 (floor) × 5 mm tall**, rubber with a **metal washer insert** so the screw
pulls against metal rather than rubber. The screw is **not supplied** — an M4 ×
~12 self-tapping pan head. The plate gets a plain **Ø4.5 clearance hole** and the
screw is driven **downward from inside** the case, so its head lands on the
plate's *top* face. That head is the whole reason the
stations sit where they do: at `FOOT_INSET_X` = 14.3 they are **outboard of the
pedestal tubs** (which start at x 24.6), so no ring floor and no sled needs
relieving to clear a screw head. `foot_relief_xy()` reports any fixing that lands
under a pedestal and the gate asserts it comes back **empty**. A second gate pins
`FOOT_INSET_X` inside the 8.2…20.4 window between the bend relief (`RI + T`) and
the tub edge. Stance is 817 × 329.

---

### The slope convention — `v` is along the plate, so height is `v·sin` (#742)

`v` on the faceplate is measured **along the slope**, not in plan: `FP_V == L_SLOPE`
(406.64), the plate's own length, not `FACE_RUN` (397). Moving `v` along a plane
inclined at `SLOPE_ANGLE` lifts you by **`v·sin`**.

`lid_top_z` used to interpolate over `FACE_RUN` — i.e. treat an along-slope `v` as a
horizontal run — overstating the plate by `v·(tan − sin)` = **0.00525·v**: 0.36 mm at
the front row, 1.42 mm at the mid row, **1.95 mm** at the back of the 16" aperture.

**It was masked, not missed.** `face_drift`'s own docstring named it ("*lid_top_z uses
the tan-slope shortcut, the real plate follows sin*"), and a two-point fit
`face_drift(v) = 1.96 − 0.00533·v` was calibrated in the Fusion doc to cancel it. That
slope was never the plate: **−0.00533 is the tan/sin error (0.005253) to within 1.5 %.**
The fit was measuring the bug.

Re-reduce the same three measurements against a **sin** slope and they land on
**+1.955 / +1.942 / +1.939** — a constant, to within 0.016 mm. Three independent points
agreeing that closely is the evidence. So `FACE_SEAT = 1.95` is the real, physical
seating offset, and `SKIRT_DRIFT_ROW1/ROW2` (1.6 / 0.5 — the same fit, duplicated)
collapse into it.

> **Nothing already made is invalidated.** Correcting both together moves `platform_h`
> by **−0.0003 mm** at the front row and **+0.015 mm** at the mid row, and **every DXF
> is byte-identical apart from timestamps and GUIDs**. The printed rings and sleds stay
> valid.
>
> What it *does* fix is the **uncompensated** call sites — `lid_under_z` for screen
> depth and Pi headroom never had drift added, so the interior was overstated by up to
> 1.95 mm, in the direction that makes you think there is more room than there is.

Gated at the **top** of `_check()`, before anything derived from it: `FP_V == L_SLOPE`,
`lid_top_z` is exactly `H_FRONT + v·sin`, the top of the slope is `H_REAR`, and
`face_drift` is **constant** — the moment it grows a `v` term again it is almost
certainly re-absorbing a unit error, which is exactly how this hid. All four
negative-controlled.

## 6. Sheet-metal notes

- Folded edges (wall bottom flanges): 90°, inside R = `t` = 2.0, **K 0.33** → bend
  allowance 4.18 mm. The vertical corner seams are open butt joints (relief hole
  each) closed by riveted L-brackets, so they take no allowance.
- **Lid seam fixings — NO clinch nuts / PEM anywhere** (superseded; see
  `MANUFACTURING.md`). The lid front lip + rear lap screw into **hand-tapped Ø2.5
  M3 pilots** in the body (one tap, one screw SKU); no drawing carries PEM clinch
  holes or masks any more. The old Ø6.3-clinch-in-the-side-skirt scheme is gone.
- DXF layers: `CUT` (thru) · `BEND` (score) · `VENT` · `ENGRAVE` · `NOTE`.
  There is no `WELD` layer: it was declared in all seven DXFs and **empty in every
  one** — a vestige of the original welded-shell plan — so it was removed.
- Finish: deburr → powder coat (mask bond pads).

---

## 7. Material & weight

| material | thickness | mass |
|---|---|---|
| **5052-H32 aluminium** *(default)* | 2.0 mm | **≈ 5.3 kg** |
| Mild steel (CRS) | 2.0 mm | ≈ 15.4 kg |

---

## 8. Generating the package & the assertion gate

```bash
cd hardware/enclosure
python3.12 -m venv .venv && .venv/bin/pip install ezdxf cadquery matplotlib  # one-time
.venv/bin/python segno_enclosure.py            # check + STEP + DXF + PDF -> out/
.venv/bin/python segno_enclosure.py --report   # report + assertions only
.venv/bin/python segno_enclosure.py --no-step   # DXF + PDF only
.venv/bin/python _pedal_base_fit_test.py       # base-hole fit-test jig -> out/
.venv/bin/python _print_check.py out/segno_pedal_base_fit_test.stl   # FDM check
```

**Base-hole fit-test jig** (`_pedal_base_fit_test.py`, issue #716) — a
throwaway print that carries *only* four locating pins on the `PEDAL_BASE_*`
pattern plus the two side columns that capture the horizontal screw bosses
(same `SKIRT_BOSS_CH_*` idiom as the tray tubs). Print it, drop a pedal on it:
all four pins in, both bosses in their channels, case sitting flat = the
pattern is right and the pedestal decks can be bored for heat-set inserts. Its
`SEAT` assertion intersects the jig with a seated pedal stand-in, so a jig that
cannot accept the pedal fails in CAD instead of on the bed. Pins engage only
3.0 mm past the pad — the hole *depth* is unmeasured, and a pin that bottoms
out would hold the pedal proud and read exactly like a placement error.

Before any output the generator runs `_check()` — **the real acceptance gate**.
It raises (build fails) unless every geometry rule holds:

| assertion | guards |
|---|---|
| `WIDTH_BUDGET` | the 10-pedal row + gaps fit across the faceplate |
| `NO_OVERLAP` / `BOUNDS` | no two cutouts intersect; all inside the usable area |
| `PLATFORM_HEADROOM` | foot-plate flush+proud, body fits under the sloped lid |
| `SCREEN_DEPTH` | each module + cable clears the interior; pedal row clears the 16" |
| `VENT_FREE_AREA` | open vent area ≥ target; standoff gap adequate |
| `SCREEN_RETENTION` | aperture < bezel (mount from behind) |
| `PEM` | bottom-flange edge distance ≥ `PEM_EDGE`+2 — a frozen guard named for the **retired** clinch scheme; there are no clinch nuts now, but the land width stays pinned |

Outputs in `enclosure/out/` (mm): **STEP** (`segno_assembly` + per-part incl.
`segno_platform_*_ring`, `segno_platform_sled`, `segno_bottom`), **DXF** flat patterns, **PDF** drawing sheets
(the platform parts are print-only). Verification renders
(`out/_hero.png`, `out/_fp_top.png`) confirm 7" left / 16" right.

Everything is parameterised at the top of the script — change a value, re-run, and
the assertions re-validate before re-cutting every panel.

---

## 9. Bill of materials (enclosure only)

| item | qty | note |
|---|-----|---|
| 2.0 mm 5052-H32 sheet | ~1.1 m² | shell + bottom + platforms + brackets |
| M3 × 8 lid-seam screws | ~18 | front lip + rear lap, into **hand-tapped Ø2.5 M3 pilots** — **NO clinch nuts / PEM** (#760, replaces the old M4-skirt-into-PEM scheme) |
| M3 standoffs (≥10 mm) | ~6 | Pi / board, airflow gap |
| M6 earth stud + hardware | 1 | chassis bond |
| Rubber feet (uxcell Ø18×15×5, screw-on) | 4 | bottom, `FOOT_INSET_X/Y`; screws not supplied |
| M4 × 12 self-tapping pan head | 4 | foot fixings, driven from inside |
| Diffuser disc (ring) + 12 THT LEDs | 1 | encoder ring |

Screens are retained by **printed stands anchored to the base floor** (#762), a
3D-printed part — not the sheet-metal `segno_screen_bracket` this table used to
list, which was dropped. See `MANUFACTURING.md`.

Pedals, screens, encoder, LEDs, Pi, board and the (external) audio interface are in
`segno_console_shopping_list.md` and the board BOM
(`kicad/fab/segno_console_board_bom.csv`).

---

## 10. Confirm before cutting

The pedal figures (`PEDAL_*`) are now caliper-measured (2026-07-28); the one
family still to confirm from physical parts is the exact **`BIG_*`/`SMALL_*`**
touch modules (one-line param changes, then re-run — the assertions
re-validate).

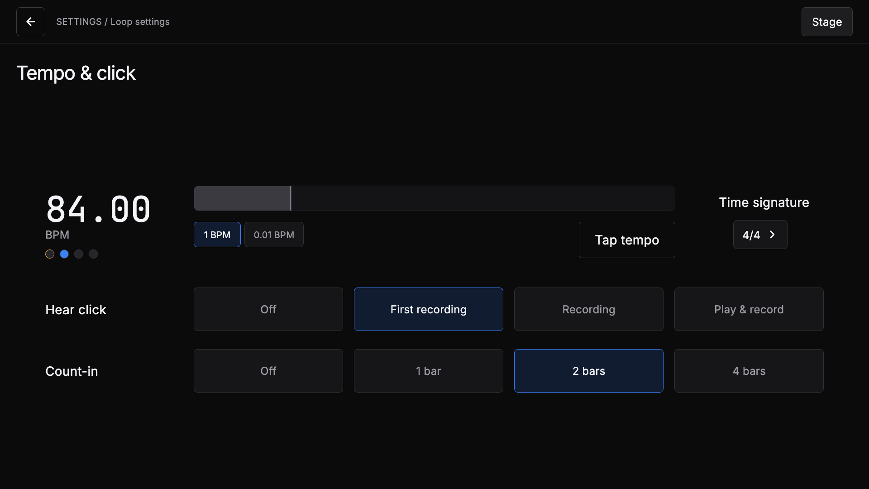
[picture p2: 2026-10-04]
docs/design/native-record-start/tempo_count_in_2.png

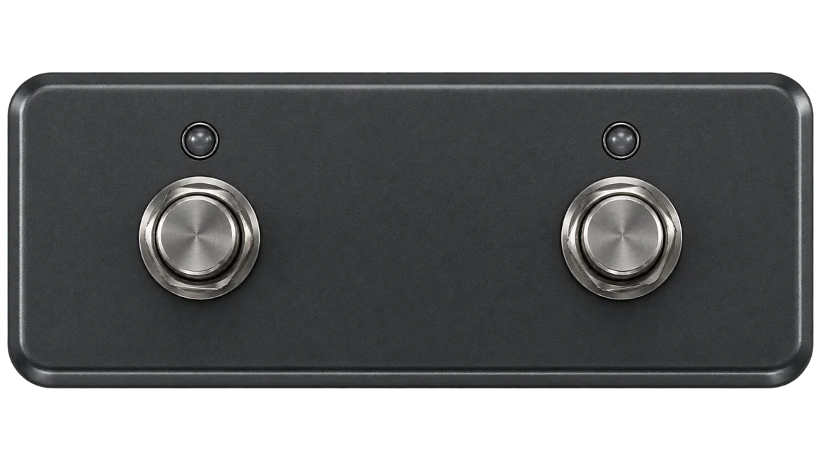
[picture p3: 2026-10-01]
assets/hardware/external_dual.webp

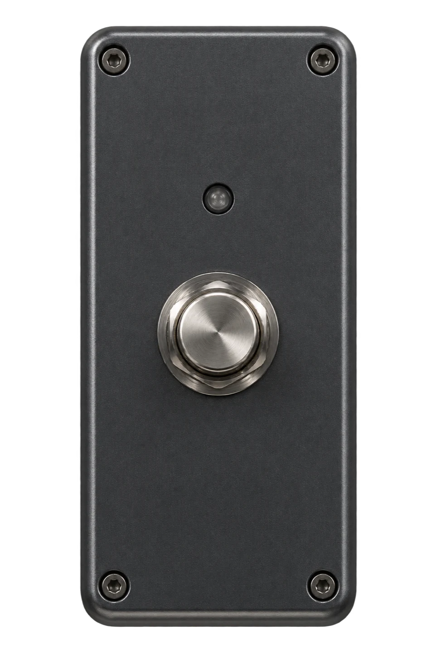
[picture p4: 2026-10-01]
assets/hardware/external_single.webp

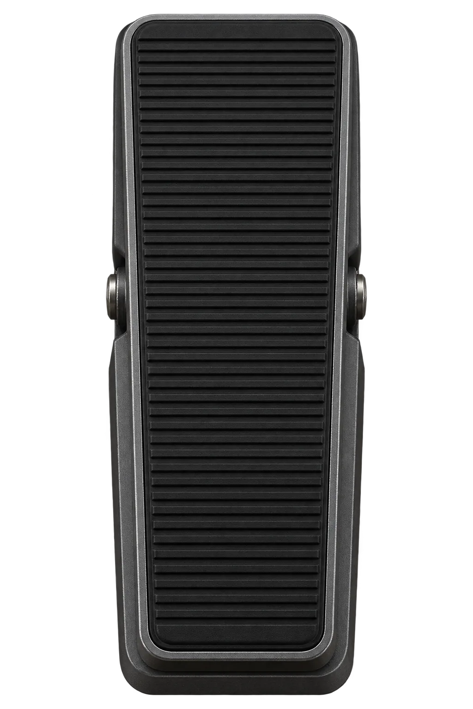
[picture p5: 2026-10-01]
assets/hardware/external_expression.webp

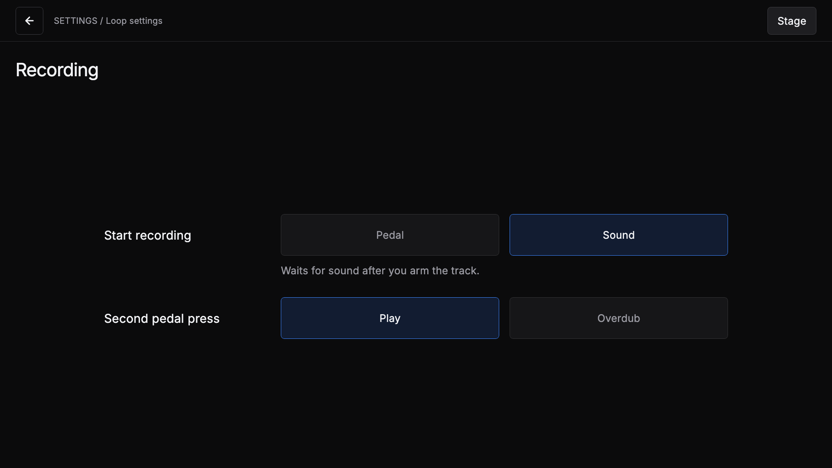
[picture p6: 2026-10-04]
docs/design/native-record-start/recording_sound_on.png

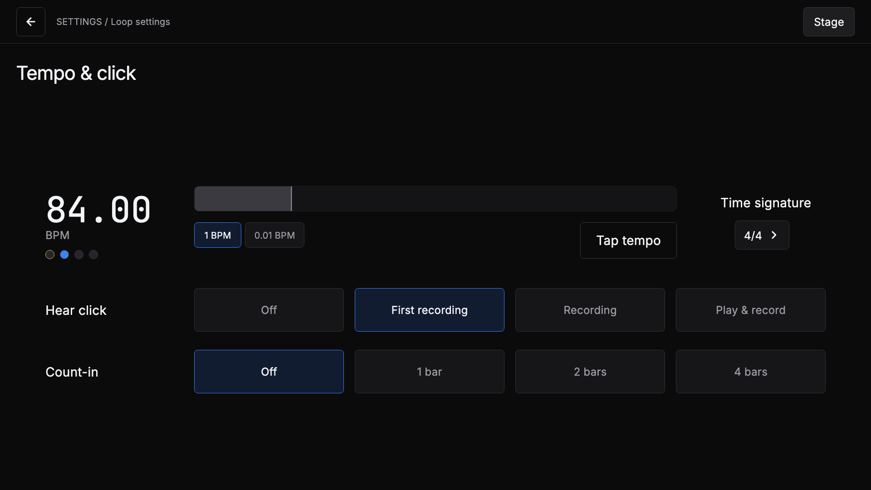
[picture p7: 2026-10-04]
docs/design/native-record-start/tempo_count_in_off.png

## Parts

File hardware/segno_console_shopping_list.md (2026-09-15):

# Segno Floor Console — Local Shopping List (Argentina)

Quantities are **per console**. All parts are standard and available at local
electronics shops / MercadoLibre, except the Pi 5, screens, and USB interface
(import or specialty).

> The console is a **standalone Pi 5 appliance**. The foot controls
> (footswitches + encoder), the WS2812 drive and the MIDI front end all live on
> the **console board v2** — a Pico 2 (RP2350) board linked to the Pi's 40-pin
> header over a short keyed ribbon (`hardware/kicad/console_board.py`, #747).
> The Pi reads no controls directly and never bit-bangs WS2812. The console is
> the only product; there is no separate USB-MIDI pedal.

---

## Compute + displays

- [ ] Raspberry Pi **5** (8 GB recommended; 4 GB OK) ×1
      *(Pi 4 Model B 8 GB also works — see the Pi-4 note in
      [`docs/RUNNING_ON_RPI.md`](../docs/RUNNING_ON_RPI.md); tighter latency/thermal margin.)*
- [ ] Pi 5 **active cooler** (official, or a heatsink+fan) ×1 — **required** for a
      closed enclosure under sustained audio + GPU load
- [ ] microSD card, A2, 64 GB+ ×1
- [ ] **16″ touchscreen** monitor, 1080p, HDMI + USB-touch ×1 — main UI
- [ ] **7″ HDMI** display ×1 — waveform. **HDMI, not DSI** (decision below)
- [ ] micro-HDMI → HDMI cables (Pi 5 has 2× micro-HDMI) ×2
- [ ] USB-A → USB-B/-C cable for the touchscreen's touch panel ×1

## Audio

- [ ] USB **class-compliant** audio interface, Scarlett-class (e.g. Focusrite
      Scarlett 2i2 / Clarett, or any UAC2 interface) ×1
- [ ] Instrument (TS) + mic (XLR) cables as needed
- [ ] TS→TS loopback cable ×1 *(one-time latency calibration only)*

## Foot controls

Terminated by the **console board v2** (`hardware/kicad/console_board.py`, #747)
— the loose parts here are only what bolts to the panel and plugs into it.

- [ ] Momentary **SPST footswitches** (stomp-rated, Cherub WTB-006 per
      [`MANUFACTURING.md`](MANUFACTURING.md)) ×10 — one per pedal, J10..J19
- [ ] **EC11 rotary encoder** (with push switch) ×1 — mounts on the encoder
      ring PCB (also in `MANUFACTURING.md`)
- [ ] Knob for the EC11 ×1
- [ ] JST-XH pre-crimped 2-pin leads for the footswitch looms ×10
- [ ] **CTRL jacks, board v3: Neutrik NJ6FD-V ×2** — D-series 6.35 mm TRS
      **with switching contacts**. Same Ø24 D punch and M3 pair as the MEIRIYFA
      jack it replaces; what it adds is the tip-normal contact the board reads as
      "something is plugged in" (J20/J21 pin 4), which is what makes plugging a
      pedal in or out clean. Four leads per jack: tip, ring, sleeve, TN. A v2
      board keeps the plain jack (3 leads) and the firmware's heuristics.

## LEDs

Driven by the console board's own Pico 2 — there is **no separate LED-driver
board, shifter, bulk cap or series resistor to buy**; all of that is on the v2
board's BOM.

- [x] WS2812 **ring, 24 LEDs** — Adafruit NeoPixel **Ring 24**, 65.5 mm OD /
      52.3 mm ID / 3.2 mm thick. **Owner already has it.** This line said
      "Ring 16, 44.5 mm OD" until 2026-08-28 — stale since #792/#794 moved
      the faceplate window to Ø67 and the ring board to Ø68 for the 24.
      A Ring 16 will NOT fill the window it is now cut for
- [ ] WS2812B **indicator pills** — **144 LEDs/m, bare/non-waterproof
      (labelled IP20 or IP30 — the same uncoated strip either way), 12 mm
      wide**, ×**1 m**. Cut into **10** eight-LED segments of 55.56 mm,
      one per pedal. You need 0.556 m; 1 m covers mis-cuts.
      Candidate: LOAMLIN WS2812B 144LED/m, 3.2 ft, **IP30 non-waterproof**,
      white PCB, DC5V —
      [LOAMLIN 144/m 3.2 ft](https://www.amazon.com/dp/B0BDS7NHQM), $9.99. Right part on every axis that
      matters, and its own listing states 0.1 W/LED per colour, which confirms
      the power model below.
      The spec is load-bearing, not a preference:
      **144/m** because the pill only has 3.2 mm of diffuser to spread through,
      so anything sparser reads as separate dots (60/m is 5.2:1 — three blobs),
      and because the pill is rendered as a gradient, which needs steps to be
      smooth; **non-waterproof** because it is inside a sealed console and is the
      thinnest — IP65/IP67 add 0.87/1.72 mm and push the LED further from the
      lens.
      ⚠️ **MEASURE THE STRIP BEFORE PRINTING THE DIFFUSERS.** The candidate's own
      listing contradicts itself on width — product image says 12 mm, its
      compare-with-similar row says "IP30/65 - 10mm; IP67 - 12mm". The channel
      grips 0.4 mm per side, so 2 mm of error either jams the strip or drops it
      straight through. Width reaches **only the 3D-printed diffuser**, never
      anything a shop cuts, so print those after the strip lands. Confirm width,
      pitch and PCB thickness together.
      Note it is built from 50 cm PCBs, so there is a **solder joint every
      50 cm**. 80 LEDs are needed of 144, so there is room to cut around it

## Power (#754 — one 20 V PD contract, two bucks)

- [ ] **CTRL jacks: Neutrik NJ6FD-V ×2** — 6-pole switching 1/4" jack, vertical
      PCB pins, rear-mounted through the panel's Ø12 hole with its snap-on cap
      (Neutrik: panel 1.2–1.5 mm, which is why the rear panel is 1.5 mm). Solder
      leads to T/R/S. Mouser/TME stock it; the Amazon listing is B09ZNHVYG8 (25-pack).
- [ ] **USB-C PD panel coupler**, D punch — QIANRENON
      [B0CQ4VD2N2](https://www.amazon.com/dp/B0CQ4VD2N2) ×1 (100 W, 10 Gbps —
      the 10 Gbps grade matters: all 24 ways wired means CC reaches the trigger;
      charge-only couplers drop CC and nothing powers up)
- [ ] **STUSB4500 PD trigger board** (SparkFun) ×1 — program the PDO to
      **20 V / 5 A** before first power-up; the shipped default asks 20 V at
      only 1 A
- [ ] **20 V → 5 V buck** (eleUniverse 8–36 V→5 V 10 A IP67,
      [B0GGHN97TK](https://www.amazon.com/dp/B0GGHN97TK)) ×**2** — BUCK_PI and
      BUCK_AUX, split by rail, never paralleled (wiring doc §2)
- [ ] **100 W-class USB-C PD supply** (20 V / 5 A capable) + 5 A-rated C-to-C
      cable ×1 — the external brick; no mains enters the enclosure
- [ ] **2×20 keyed IDC ribbon**, ~10 cm ×1 — console board J2 → Pi header
- [ ] **Panel fuse holder**, generic 5×20 screw-cap, 10 A / 250 VAC, **Ø12.0**
      aperture ×1 — e.g. [NeoLum 4-pack](https://www.amazon.com/dp/B0GF33P9FF).
      Generic by decision. NOTE the aperture: the SCI R3-11 upgrade wants
      Ø12.5 and the panel is no longer cut for it
- [ ] **T5A slow-blow** 5×20 fuses (T5AL250V) ×1 pack — NOT fast-blow; the two
      bucks' inrush will nuisance-blow a fast fuse
- [ ] **Momentary HIGH-ROUND** push button, 19 mm hole (Ø19.5), **unlit**,
      stainless ×1 — [APIELE, $4.50 ea](https://www.amazon.com/dp/B079HTQ7XD).
      Must be momentary: it pulses the Pi 5's own power-button pads (its J2,
      through the console board's J8→J9 lead) — no GPIO is involved and it does
      not break power. Domed, not flat — the dome is what gives it a real click
> **Everything on this list is bought from Amazon.com** (decision, 2026-08-17).
> A MercadoLibre comparison was run and is in git history at `d5295b69` /
> `1621f676` if local sourcing ever comes back up; the one finding worth keeping
> is that a plain local 6.35 chassis jack will NOT fit a D punch. Moot since
> 2026-09-04: the CTRL jacks are Neutrik NJ6FD-V in a plain Ø12 hole (#993).

- The power budget is [`segno_wiring.md` §2](segno_wiring.md) — canonical since
  #754.

## Console board v2 (#747) — supersedes the link + MIDI daughterboard (#746)

MIDI, the pedal link, the footswitch headers, the CTRL jacks and the LED
buffers all live on the **console board v2** now. Its parts list is generated
with the board — order from
[`kicad/fab/segno_console_board_bom.csv`](kicad/fab/segno_console_board_bom.csv),
not from a list transcribed here. What died with the daughterboard: the
1k8/3k3 divider (the RP2350 link is 3.3 V at both ends — no level shifting,
only a 10 k series pair bounding cross-domain current), the perfboard, and the
"do not populate J4/J5/U2" note for the V1 board — the console does not use
the V1 board at all. The DIN-5 sockets stay in the rear-panel list and wire to
the v2 board's J4/J5.

One purchasing rule from that BOM that is easy to violate under stock pressure:
**U1 must be AHCT (74AHCT125), not HC or HCT.** The TTL-level inputs
(V_IH = 2.0 V) are the whole point — a 74HC125 at 5 V wants V_IH ≈ 3.15 V, and
a 3.3 V drive would leave all three 3.3→5 V crossings (MIDI OUT, ring data,
indicator data) ~0.15 V of margin: works on the bench, flaky in the field.

## Mechanical / enclosure

- [ ] Enclosure material (plywood / aluminium / 3D-printed panels) — tilted body
- [ ] M2.5/M3 screws + standoffs for the Pi, the console board, and screen mounts ×1 set
- [ ] Stomp-panel face (steel/aluminium) for the footswitches ×1
- [ ] Rubber feet / non-slip base ×1 set
- [ ] Cable strain reliefs / grommets ×1 set

---

### 7″ display: **HDMI, not DSI** (spike outcome)

Both screens are wired as **HDMI** outputs, so they enumerate as uniform
`HDMI-A-1` (16″) / `HDMI-A-2` (7″) wlr outputs. This gives clean, deterministic
`wlr-randr` output-name pinning (matching Part 5's
[`deploy/rpi/pin-displays.sh`](../deploy/rpi/pin-displays.sh)) with no DSI ribbon
or DSI-specific compositor mapping. The official 7″ DSI panel's only advantage —
freeing a micro-HDMI port — is moot here since nothing else uses the second
HDMI, and its 800×480 is lower-res than an HDMI 7″. Resolution matters little for
a waveform, so pick any 7″ HDMI panel; set its per-output `--scale` in
`pin-displays.sh`.

### Notes

- Keep the engine at **48 kHz** with the PipeWire **Pro Audio** profile for the
  full channel count + lowest stable latency (see
  [`docs/RUNNING_ON_LINUX.md`](../docs/RUNNING_ON_LINUX.md)).
- The LEDs and foot controls all terminate on the **console board v2**
  (`hardware/kicad/console_board.py`); Pi GPIO14/15 carry MIDI, and the pedal
  link rides uart3 (GPIO8/9) over the ribbon.

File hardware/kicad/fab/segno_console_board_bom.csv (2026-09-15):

Comment | Designator | Footprint | LCSC | Qty | Type
MIDI_IN, PWR_BTN, PI_PWR_PADS, FSW_RECPLAY, FSW_STOP, FSW_UNDO, FSW_MODE, FSW_TRACK1, FSW_TRACK2, FSW_TRACK3, FSW_TRACK4, FSW_CLEAR, FSW_BANK | J5,J8,J9,J10,J11,J12,J13,J14,J15,J16,J17,J18,J19 | JST_XH_B2B-XH-A_1x02_P2.50mm_Vertical |  | 13 | Component
100nF | C1,C2,C3,C4,C5,C6,C7,C8,C9,C10,C11,C20 | C_Disc_D5.0mm_W2.5mm_P2.50mm |  | 12 | Component
10k | R6,R8,R10,R11,R12,R17,R18 | R_Axial_DIN0207_L6.3mm_D2.5mm_P10.16mm_Horizontal |  | 7 | Component
5V_IN, RING_LINK, CTRL_TRS_SW, CTRL_TRS_SW | J3,J6,J20,J21 | JST_XH_B4B-XH-A_1x04_P2.50mm_Vertical |  | 4 | Component
4.7k | R19,R20,R21,R22 | R_Axial_DIN0207_L6.3mm_D2.5mm_P10.16mm_Horizontal |  | 4 | Component
MIDI_OUT, INDICATORS, PD_I2C | J4,J7,J23 | JST_XH_B3B-XH-A_1x03_P2.50mm_Vertical |  | 3 | Component
220 | R3,R4,R5 | R_Axial_DIN0207_L6.3mm_D2.5mm_P10.16mm_Horizontal |  | 3 | Component
10nF | C13,C14 | C_Disc_D5.0mm_W2.5mm_P2.50mm |  | 2 | Component
100k | R14,R16 | R_Axial_DIN0207_L6.3mm_D2.5mm_P10.16mm_Horizontal |  | 2 | Component
1k | R7,R9 | R_Axial_DIN0207_L6.3mm_D2.5mm_P10.16mm_Horizontal |  | 2 | Component
470uF 25V low-ESR <=0.15R | C30 | CP_Radial_D10.0mm_P5.00mm |  | 1 | Component
100uF 16V | C31 | CP_Radial_D6.3mm_P2.50mm |  | 1 | Component
74AHCT125N | U1 | DIP-14_W7.62mm |  | 1 | Component
H11L1 | U2 | DIP-6_W7.62mm |  | 1 | Component
1N4148 | D1 | D_DO-35_SOD27_P7.62mm_Horizontal |  | 1 | Component
PI_RIBBON | J2 | IDC-Header_2x20_P2.54mm_Vertical |  | 1 | Component
EXPANSION | J22 | PinHeader_2x03_P2.54mm_Vertical |  | 1 | Component
330 | R2 | R_Axial_DIN0207_L6.3mm_D2.5mm_P10.16mm_Horizontal |  | 1 | Component
Pico2 | J1 | RaspberryPi_Pico_SMD_HandSolder |  | 1 | Component

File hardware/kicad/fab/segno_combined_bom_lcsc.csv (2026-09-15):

LCSC | Comment | Value | Package | Qty | Designator | Notes
 | Ceramic capacitor | 100nF | C_Disc_D5.0mm_P5.00mm (THT) | 2 | RING:C2,C3 | Any in-stock 100nF 50V THT disc or 5mm-pitch MLCC
 | Electrolytic | 470uF 16V low-ESR <=0.15R | CP_Radial_D8.0mm_P3.50mm | 1 | RING:C1 | Low-ESR grade (e.g. Panasonic FC / Nichicon PW) -- GP parts in the same can run ~0.5R and ripple the LED rail
C202365 | Rotary encoder | EC11 | EC11 vertical w/switch 20mm | 1 | RING:ENC1 | ALPS EC11E type
C157972 | JST B8B-XH-A | 8P 2.5mm | JST_XH vertical | 1 | RING:J1 | Board-to-board link to J6 on the console board (one cable between them)

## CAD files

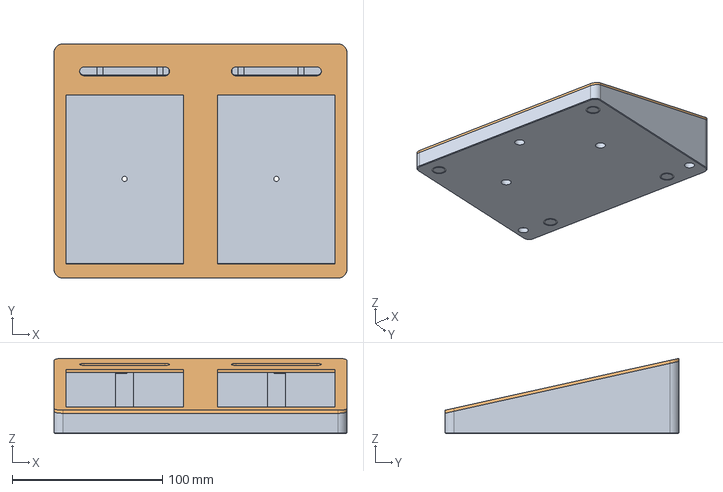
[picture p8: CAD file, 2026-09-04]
hardware/enclosure/out/segno_mini_console_assembly.step
195.3 x 156.2 x 50.3 mm

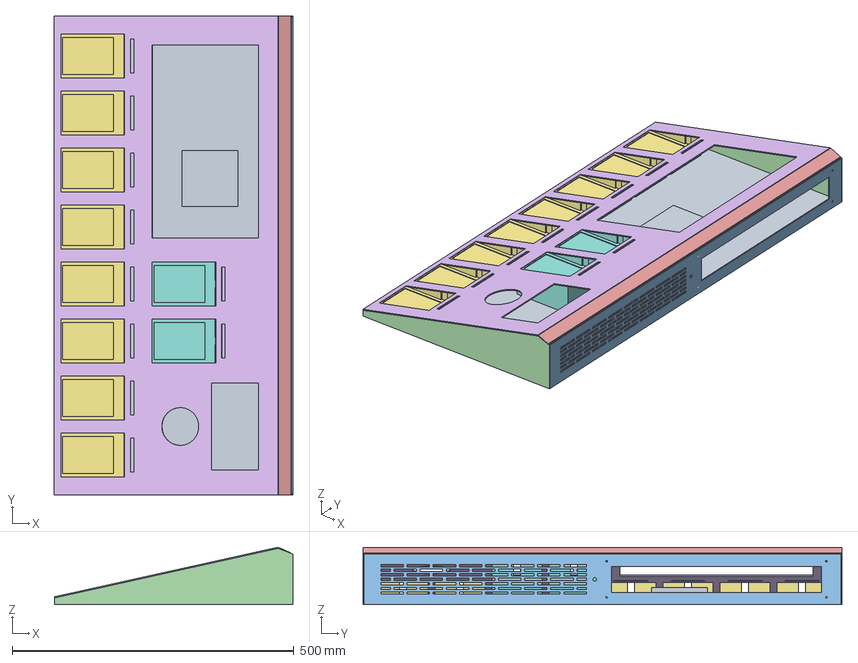
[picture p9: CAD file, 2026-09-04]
hardware/enclosure/out/segno_assembly.step
423.4 x 850.0 x 102.0 mm
bottom
front
rear
side_L
side_R
transition
faceplate
platform_0
platform_1
platform_2
platform_3
platform_4
platform_5
platform_6
platform_7
platform_8
platform_9
console_board
console_board_standoff_u515_d229
console_board_standoff_u515_d318
console_board_standoff_u604_d229
console_board_standoff_u604_d318

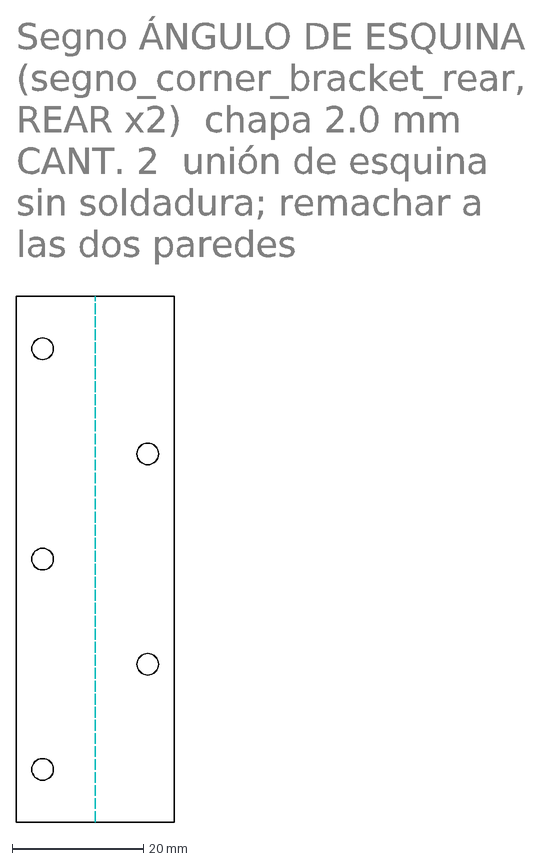
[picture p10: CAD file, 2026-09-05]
hardware/enclosure/out/segno_corner_bracket_rear.dxf
Segno ÁNGULO DE ESQUINA
(segno_corner_bracket_rear,
REAR x2) chapa 2.0 mm
CANT. 2 unión de esquina
sin soldadura; remachar a
las dos paredes

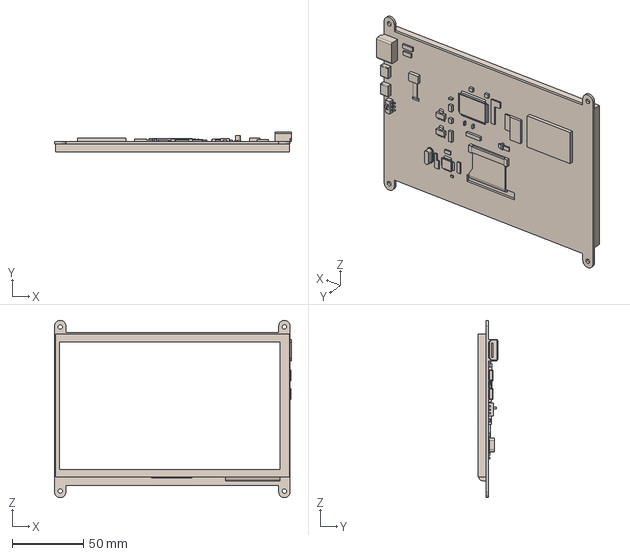
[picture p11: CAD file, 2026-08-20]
hardware/enclosure/ref/screen7_module_measured.step
166.1 x 13.7 x 124.3 mm

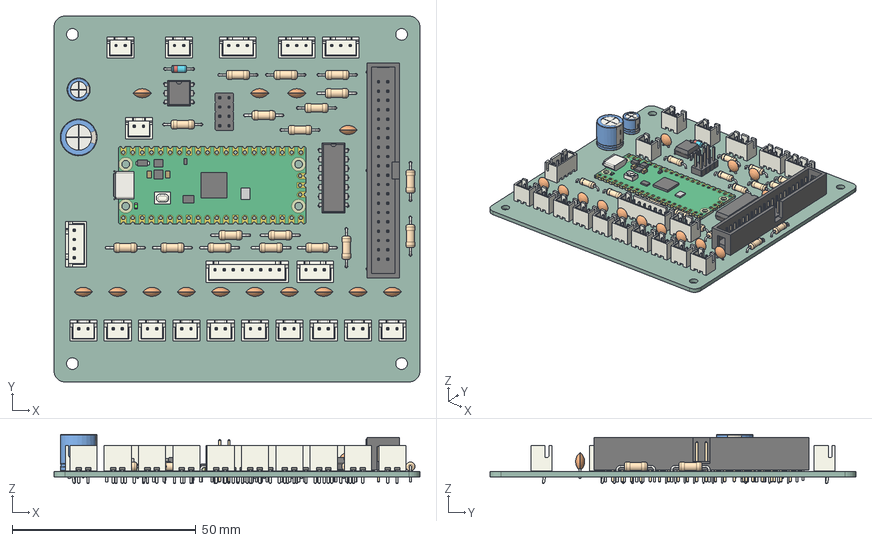
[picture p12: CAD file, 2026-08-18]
hardware/kicad/out_console/segno_console_board.step
99.5 x 99.5 x 13.4 mm
C_Disc_D50mm_W25mm_P250mm x 14
R_Axial_DIN0207_L63mm_D25mm_P1016mm_Horizontal x 18
JST_B2B_XH_A x 13
CP_Radial_D100mm_P500mm
JST_B3B_XH_A x 4
CP_Radial_D63mm_P250mm
D_DO-35_SOD27_P7.62mm_Horizontal
PinHeader_2x04_P254mm_Vertical
JST_B8B_XH_A
JST_B4B_XH_A
RaspberryPi_Pico_Module_KiCad
DIP-6_W7.62mm
DIP-14_W7.62mm
IDC_Header_2x20_P254mm_Vertical
segno_console_board_PCB

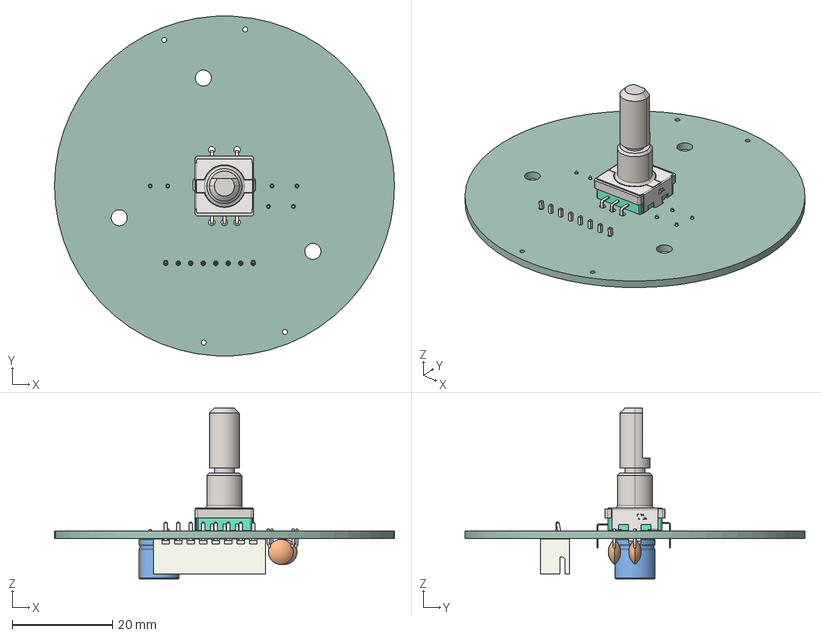
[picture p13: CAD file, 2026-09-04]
hardware/kicad/out_ring/segno_ring_board.step
68.0 x 67.9 x 34.2 mm
SW-TH_EC11XXXXXXXX-L11.7-W12.0-H24.5-P2.5-LS14.5
C_Disc_D50mm_W25mm_P500mm x 2
JST_B8B_XH_A
CP_Radial_D80mm_P350mm
segno_pedal_ring_PCB

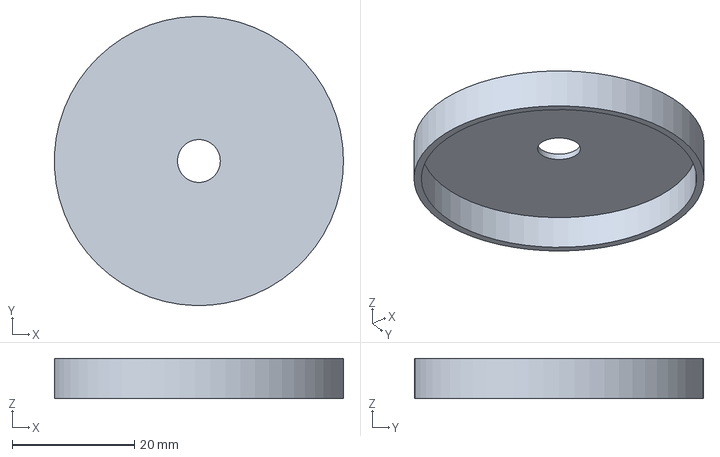
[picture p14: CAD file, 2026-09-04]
hardware/ring_diffuser/out/segno_ring16_diffuser_skirt.step
47.2 x 47.2 x 6.60 mm

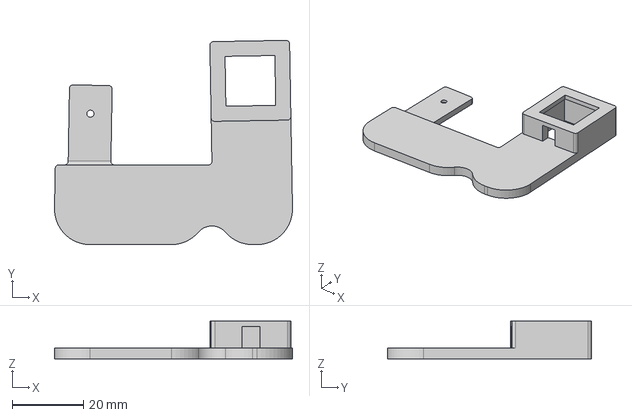
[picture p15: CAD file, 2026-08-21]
hardware/switch_mount/switch_platform.step
66.8 x 57.4 x 10.6 mm

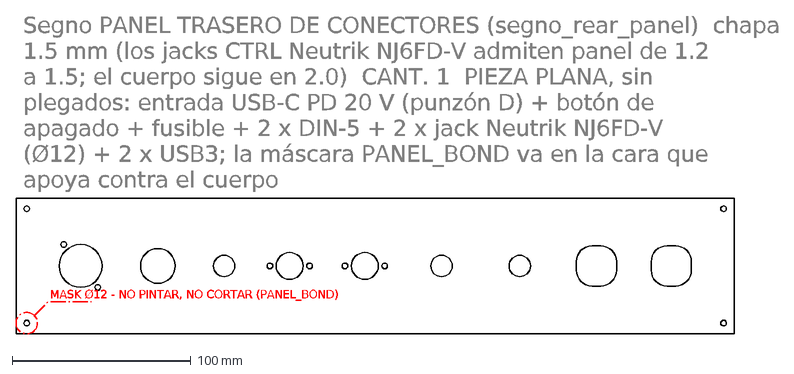
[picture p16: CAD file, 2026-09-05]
hardware/enclosure/out/segno_rear_panel.dxf
MASK Ø12 - NO PINTAR, NO CORTAR (PANEL_BOND)
Segno PANEL TRASERO DE CONECTORES (segno_rear_panel) chapa
1.5 mm (los jacks CTRL Neutrik NJ6FD-V admiten panel de 1.2
a 1.5; el cuerpo sigue en 2.0) CANT. 1 PIEZA PLANA, sin
plegados: entrada USB-C PD 20 V (punzón D) + botón de
apagado + fusible + 2 x DIN-5 + 2 x jack Neutrik NJ6FD-V
(Ø12) + 2 x USB3; la máscara PANEL_BOND va en la cara que
apoya contra el cuerpo

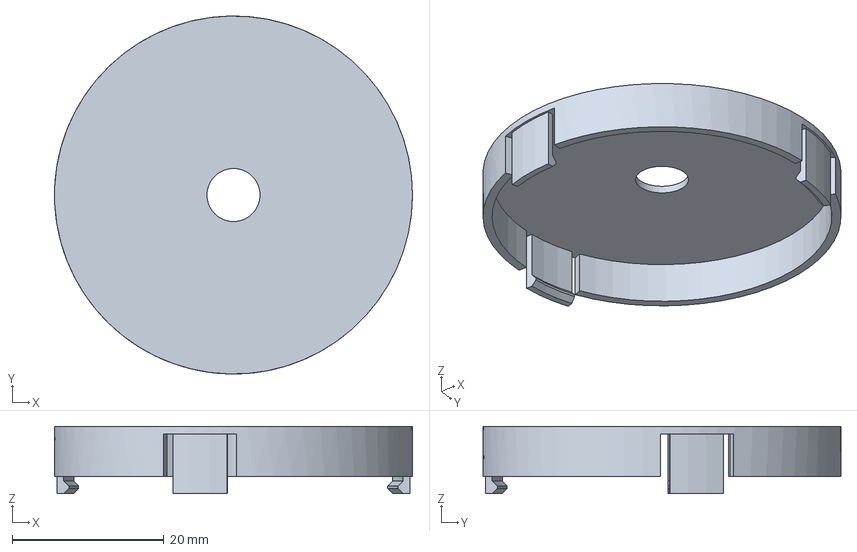
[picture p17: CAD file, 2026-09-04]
hardware/ring_diffuser/out/segno_ring16_diffuser.step
47.2 x 47.2 x 8.90 mm

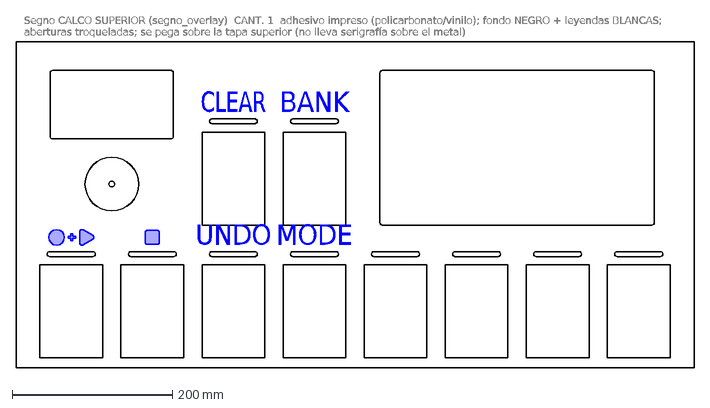
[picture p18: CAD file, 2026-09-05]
hardware/enclosure/out/segno_overlay.dxf
UNDO
MODE
CLEAR
BANK
Segno CALCO SUPERIOR (segno_overlay) CANT. 1 adhesivo impreso (policarbonato/vinilo); fondo NEGRO + leyendas BLANCAS;
aberturas troqueladas; se pega sobre la tapa superior (no lleva serigrafía sobre el metal)

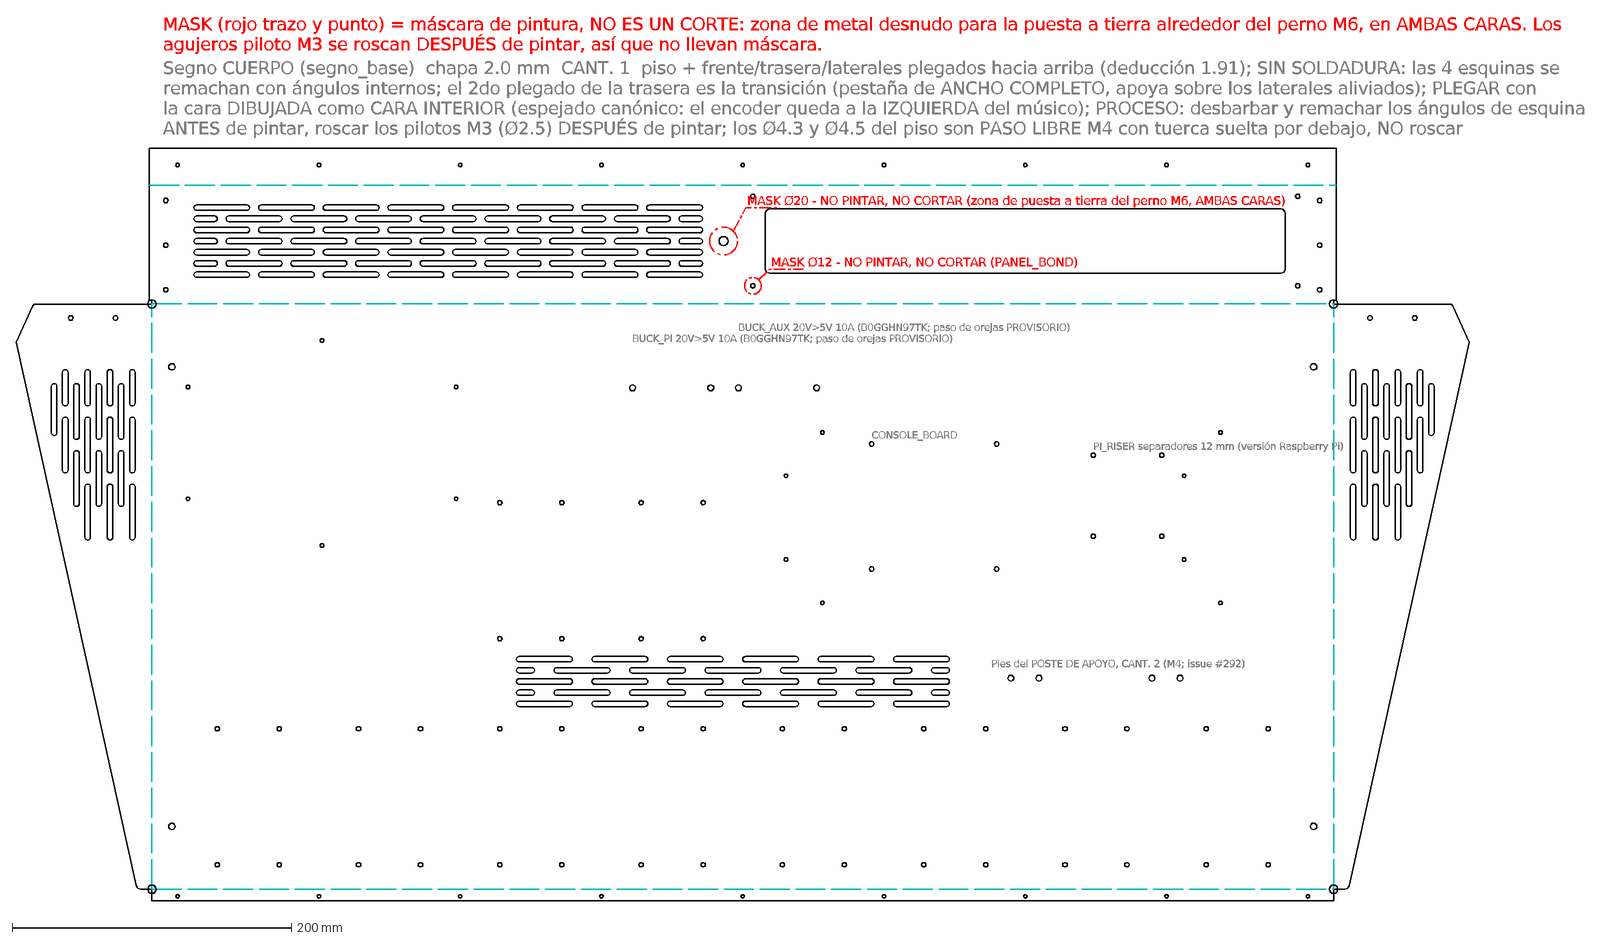
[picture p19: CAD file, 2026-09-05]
hardware/enclosure/out/segno_base.dxf
CONSOLE_BOARD
PI_RISER separadores 12 mm (versión Raspberry Pi)
BUCK_PI 20V>5V 10A (B0GGHN97TK; paso de orejas PROVISORIO)
BUCK_AUX 20V>5V 10A (B0GGHN97TK; paso de orejas PROVISORIO)
Pies del POSTE DE APOYO, CANT. 2 (M4; issue #292)
MASK Ø12 - NO PINTAR, NO CORTAR (PANEL_BOND)
MASK Ø20 - NO PINTAR, NO CORTAR (zona de puesta a tierra del perno M6, AMBAS CARAS)
Segno CUERPO (segno_base) chapa 2.0 mm CANT. 1 piso + frente/trasera/laterales plegados hacia arriba (deducción 1.91); SIN SOLDADURA: las 4 esquinas se
remachan con ángulos internos; el 2do plegado de la trasera es la transición (pestaña de ANCHO COMPLETO, apoya sobre los laterales aliviados); PLEGAR con
la cara DIBUJADA como CARA INTERIOR (espejado canónico: el encoder queda a la IZQUIERDA del músico); PROCESO: desbarbar y remachar los ángulos de esquina
ANTES de pintar, roscar los pilotos M3 (Ø2.5) DESPUÉS de pintar; los Ø4.3 y Ø4.5 del piso son PASO LIBRE M4 con tuerca suelta por debajo, NO roscar
MASK (rojo trazo y punto) = máscara de pintura, NO ES UN CORTE: zona de metal desnudo para la puesta a tierra alrededor del perno M6, en AMBAS CARAS. Los
agujeros piloto M3 se roscan DESPUÉS de pintar, así que no llevan máscara.

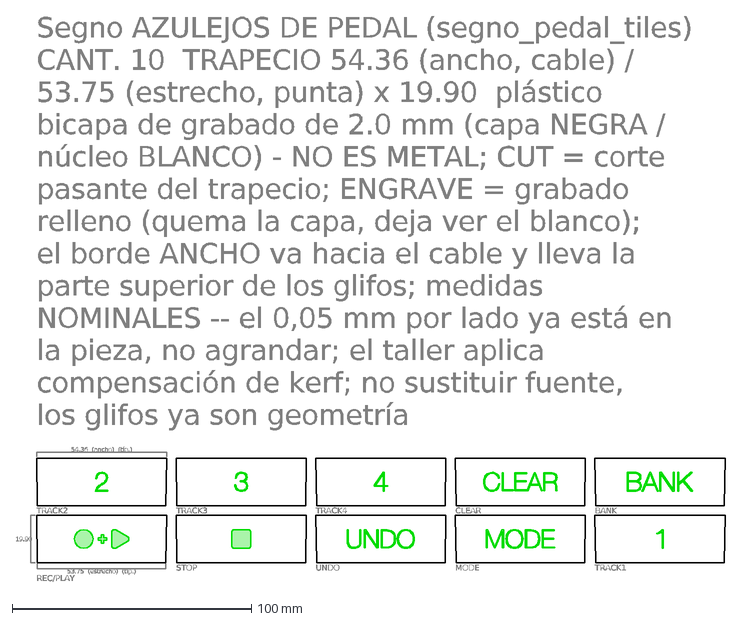
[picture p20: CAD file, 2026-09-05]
hardware/enclosure/out/segno_pedal_tiles.dxf
REC/PLAY
STOP
UNDO
MODE
TRACK1
TRACK2
TRACK3
TRACK4
CLEAR
BANK
53.75 (estrecho) (típ.)
19.90
54.36 (ancho) (típ.)
Segno AZULEJOS DE PEDAL (segno_pedal_tiles)
CANT. 10 TRAPECIO 54.36 (ancho, cable) /
53.75 (estrecho, punta) x 19.90 plástico
bicapa de grabado de 2.0 mm (capa NEGRA /
núcleo BLANCO) - NO ES METAL; CUT = corte
pasante del trapecio; ENGRAVE = grabado
relleno (quema la capa, deja ver el blanco);
el borde ANCHO va hacia el cable y lleva la
parte superior de los glifos; medidas
NOMINALES -- el 0,05 mm por lado ya está en
la pieza, no agrandar; el taller aplica
compensación de kerf; no sustituir fuente,
los glifos ya son geometría

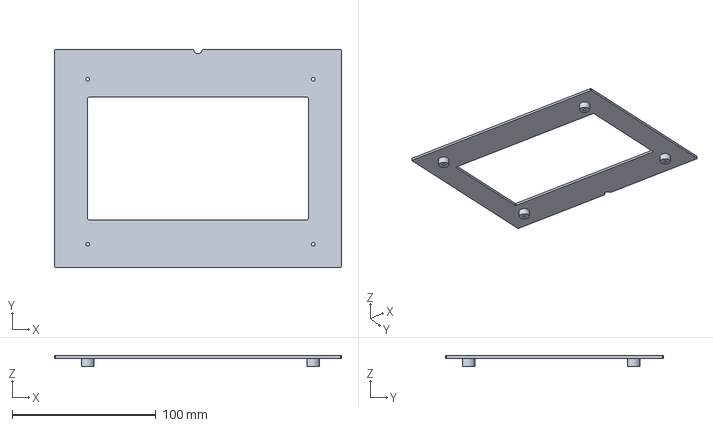
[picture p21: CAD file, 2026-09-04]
hardware/enclosure/out/segno_screen7_fit_test.step
200.0 x 152.0 x 7.40 mm

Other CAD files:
hardware/enclosure/out/segno_pedal_tile_TRACK2.step
hardware/enclosure/out/segno_pedal_tile_CLEAR.step
hardware/enclosure/out/segno_mini_console_tray.step
hardware/enclosure/out/segno_screen16_stand_L.step
hardware/enclosure/out/segno_encoder_knob.step
hardware/enclosure/out/segno_encoder_knob.stl
hardware/enclosure/out/segno_faceplate.dxf
hardware/enclosure/out/segno_faceplate.step
hardware/enclosure/out/segno_led_diffuser.step
hardware/enclosure/out/segno_led_diffuser.stl
hardware/enclosure/out/segno_mini_console_lid.step
hardware/enclosure/out/segno_mini_console_lid.stl
hardware/enclosure/out/segno_mini_console_sled.step
hardware/enclosure/out/segno_mini_console_sled.stl
hardware/enclosure/out/segno_mini_console_tray.stl
hardware/enclosure/out/segno_pedal_base_fit_test.step
hardware/enclosure/out/segno_pedal_base_fit_test.stl
hardware/enclosure/out/segno_pedal_base_gauge.dxf
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

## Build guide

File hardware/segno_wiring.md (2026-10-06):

# Segno console — system wiring plan

How the console's subsystems connect: the **console board v2** (Pico 2 / RP2350,
`hardware/kicad/console_board.py`, #747), the **ring board** (`segno_pedal_ring`),
the **Raspberry Pi 5**, the two touchscreens, the external audio interface,
power (#754), and the rear panel.

The console is the only product. It stopped sharing a board with the retired
standalone pedal when #747 gave it a board of its own, so the constraint this file
used to open with ("the main board is in production — it is NOT modified") no
longer applies to anything.

---

## 1. Block diagram

```
   POWER (#754)
     USB-C PD inlet -- rear panel, D punch, QIANRENON coupler (all 24 ways wired)
              |   STUSB4500 trigger: ONE 20 V / 5 A contract
              |   fuse, T5A slow-blow, in series with the 20 V feed
              +--> BUCK_PI  (20->5 V) --> Pi 5 via its USB-C  --> Pi USB + NVMe
              +--> BUCK_AUX (20->5 V) --> 7" + 16" screens | board J3 | WS2812

   DATA / CONTROL
     console board <---- keyed 2x20 ribbon, ~10 cm ----> Pi 40-pin header
        link  Pico uart0 (GP16/17) <-> Pi uart3 (GPIO8/9), 10 k series each way
        MIDI  DIN IN -> H11L1 (at 3V3) -> Pi uart0 RX (GPIO15)
              Pi uart0 TX (GPIO14) -> 74AHCT125 -> 220R loop -> DIN OUT
        SWD   Pi GPIO24/25 -> the Pico's debug pads (cold flashing)
     console board <-- footswitches x10 | ring board (4-way) | CTRL TRS x2
     Pi --HDMI x2--> 7" + 16" screens ;  screen touch --USB--> Pi (2 of 4 ports)
     Pi's other 2 USB --> internal leads to the rear USB couplers
                          (the audio interface plugs in there, outside the box)
     power button --J8 -> board -> J9 flying lead--> the Pi 5's own J2 pads
                          (PMIC wake -- no GPIO can wake a Pi 5)

   GND: single common ground -- the scheme, the earth-stud rules and the bench
        audit are Section 6's
```

---

## 2. Power distribution (#754)

**20 V in, 5 V made next to the loads.** 5 V at the inlet was tried and dropped:
the usable window is **5.0–5.25 V** (the Pi 5 browns out under ~4.8 V and it and
both screens cap at 5.25 V, so trimming low eats brown-out margin and trimming
high eats the ceiling), and at the console's ~12 A even a heavy 1.5 m lead drops
~0.3 V — *load-dependently*, so no single supply trim holds both idle and
full-tilt inside that 250 mV band without remote sense. At 20 V the same 59 W is
under 3 A, the lead drop is regulated away by the bucks, and the tight 5 V
tolerance only has to survive ~100 mm of internal wiring.

- **Inlet:** panel-mount USB-C coupler on a D punch (QIANRENON B0CQ4VD2N2,
  100 W, 10 Gbps). The 10 Gbps matters only because it means **all 24 ways are
  wired**, so CC reaches the trigger and PD can negotiate — a charge-only
  coupler drops CC and nothing powers up.
- **Trigger:** SparkFun STUSB4500 board, programmed to request **20 V / 5 A**.
  Its shipped default asks 20 V at only 1.0 A, which contracts 20 W — set the
  PDO before first power-up.
- **Is the contract really 20 V / 5 A?** The chip is I2C-readable: its RDO
  (`0x91`–`0x94`) carries the current the source actually granted and a
  capability mismatch bit that is set when that was less than the PDO asked for;
  `0x21` holds the negotiated voltage. A 65 W brick grants 20 V / 3.25 A with
  mismatch set: everything boots and the console browns out only when 26
  WS2812s go white under two lit screens. Console board **v3** has a 3-way
  JST-XH for it, **J23 `PD`** (GND, SDA, SCL on the Pico's GP0/GP1, I2C0),
  under the module's left end next to `5V IN`. Three wires on purpose: the
  breakout's VDD comes off VBUS on its own board and its I2C pull-ups go to
  that; the console's 3V3 is downstream of the contract being measured, so it
  must not feed the trigger. ~250 mm unshielded past two bucks: 100 kHz,
  twisted with the ground wire. On a v2 board the same read works from J22's
  GP20/GP21 (I2C0) unless those pads carry the CTRL ring wires. Firmware
  reads it and reports it up the pedal link; **not implemented yet**.
- **Fuse:** 5×20 **T5A slow-blow** in the 20 V feed, ahead of both bucks.
  Worst-case draw is ~3 A at 20 V, the PD contract ceiling is 5 A, and buck
  inrush wants the slow curve.
- **Two bucks (B0GGHN97TK ×2), split BY RAIL, never paralleled.** Two outputs
  tied together have no current sharing: one hogs the load until it limits,
  then they hunt.

| buck | loads | design figure |
|---|---|---|
| **BUCK_PI** | Pi 5 (via its USB-C) + its USB devices + NVMe | 5.0 A / 25 W (worst case) |
| **BUCK_AUX** | 7" + 16" screens + console board (J3) + all 104 WS2812 | 6.4 A / 32 W (**normal**, not worst case — see the state table) |

BUCK_PI's worst case is capped by device limits, not estimated: the Pi's own 5 A
budget. BUCK_AUX's figure is the screens' ratings plus the LEDs **as they are
actually driven** — see below, because the naive all-white number for 104 WS2812
is misleading in both directions.

**The LED load is dominated by COLOUR and the pill gradient, not by the count
(#930).** The pills went from 6 single LEDs to ten 8-LED segments of 144/m, and
the ring is a Ring **24**, so BUCK_AUX carries **104 WS2812**. The naive
"104 × 60 mA" reading of that is 6.2 A and it is wrong for two reasons: 60 mA is
all three channels at full (an indicator is normally ONE channel, ~20 mA), and
a pill is never all-on — it is rendered **centre-bright, dimming to both ends**,
which sums to ~62% of all-at-full. The vendor's own figure agrees: 0.1 W per LED
per colour at 5 V is exactly 20 mA.

| state | LED | BUCK_AUX | of 10 A |
|---|---|---|---|
| all off (controller quiescent only) | 0.10 A | 5.24 A | 52% |
| **normal — pills one colour + gradient, ring half** | **1.24 A** | **6.38 A** | **64%** |
| pills amber (2 ch) + gradient, ring one colour | 2.48 A | 7.62 A | 76% |
| pills white + gradient, ring full white | 4.44 A | 9.58 A | 96% |
| everything full white, no gradient | 6.24 A | 11.38 A | **114%** |

Normal operation is **1.24 A of LED**, and **the rail does not need a brightness
cap** — the gradient is inherent to how a pill is drawn, not a limiter bolted on.
Two things to keep in view: **white is the expensive colour**, and pills-white
*and* ring-white together reach 96% with no margin — so if a white lamp test or a
white "clipping" state is ever added, it is that combination, not the LED count,
that needs the thought.

**The rail is not the binding limit — the board path is.** BUCK_AUX is a 10 A
buck, but the LEDs reach it through J3 (two parallel JST-XH contacts, ~6 A) and
the console board's 0.6 mm +5 V track (~2 A per IPC-2152), both sized when the
chain was 26 WS2812. **Anything above ~2 A of LED is already past the track** —
which is rows 3, 4 and 5 of the table, and row 3 (pills amber, ring one colour)
is an ordinary operating state, not a lamp test. Only the top two rows are
comfortable. That is an **open call (#930)** and it is a board/firmware question,
not a rail one — see the J3 bullet below.

**And the whole table is a model of software that does not exist.** The gradient
duty (62%) and "one channel per indicator" are how a pill is *intended* to be
drawn; there is no console pixel renderer yet (`firmware/led_driver/` is the
standalone RP2040 driver, sized 24 ring + 8 indicators, with a fixed
`setBrightness(120)` ≈ 47%). So the numbers below are a design target for that
renderer to hit, not a measurement — and the 2 A track is the number it has to
hit them against. And the 5.14 A non-LED baseline is **rated maxima** for two
screens and the board, not measured; real draw is likely well under half, so the
true headroom is larger than this table admits. Measure it on the bench before
trusting either direction.

**The console firmware drives every LED at `LED_BRIGHTNESS = 128`, half of full
(#1064).** The table is at full, so each LED figure halves: normal ~0.6 A, pills
amber with the ring one colour ~1.2 A, everything full white ~3.1 A. That last
row is still past the 2 A track, so the open call stands. The ring's comet at 128
draws ~0.1 A in green and ~0.2 A in yellow.

- **The Pi is fed through its USB-C, not the header.** Ribbon pins 2/4 are
  deliberately not connected (`PI_POWER` gate): tying them would put BUCK_PI in
  hard parallel with the Pi's PMIC rail and land the WS2812 load on the Pi's
  5 V pin.
- A plain 5 V feed is not a PD source, so the Pi caps its downstream USB at
  600 mA unless **`usb_max_current_enable=1`** is set in `config.txt`. Required
  here: the touch panels and the audio interface hang off that budget.
- The console board takes 5 V from **BUCK_AUX on J3** — four ways as two
  parallel pairs, because JST-XH is ~3 A per contact. That pair is ~6 A, which
  covered the chain when it was 26 WS2812. **It no longer covers the all-white
  case**: 104 WS2812 flat out is 6.24 A through J3 *and* through the board's
  0.6 mm +5 V track, which IPC-2152 rates at ~2 A. Normal draw (1.24 A) is
  nowhere near either. **Open call (#930)** — cap global brightness in firmware,
  feed the pills from BUCK_AUX directly rather than through the board, or respin
  the board's 5 V path. See `kicad/console_board_pcb.py` (`TRACK_W`).
- **Unverified until a build (carried from #754):** the UPERFECT 15.6" is a
  USB-C portable monitor, and many of those expect PD and run dim — or refuse
  to light — on a plain non-PD 5 V feed. BUCK_AUX is exactly that. Verify the
  panel at full brightness on bench 5 V **before** committing the harness; the
  fallback is a dedicated PD trigger for the screen off the 20 V rail.

---

## 3. The console board's two internal data cables

### Console board ↔ Pi: the ribbon

One **keyed 2×20 IDC ribbon, ~10 cm** — both boards sit under the 16" screen
and the Pi is ~30 mm from the board (`board_mounts()` in `segno_enclosure.py`).
J2 is rotated so both connectors' pin-1 ends face the front: pin 1 meets pin 1
with no fold in the cable. 16 of the 40 ways carry something;
`console_board.py`'s `PI_HDR` is the authority:

| Pi pins | signal |
|---|---|
| 1, 17 | 3V3 — the board's 3V3 rail (opto + pull-up bias, ~15 mA) |
| 6, 9, 14, 20, 25, 30, 34, 39 | GND |
| 8 / 10 | uart0 TX / RX = MIDI OUT / MIDI IN (GPIO14/15) |
| 21 / 24 | uart3 RX / TX = pedal link (GPIO9/8, `dtoverlay=uart3-pi5`), **10 k series** |
| 18 / 22 | GPIO24/25 = SWD to the Pico's debug pads (flashing only) |
| 2, 4 | 5 V — deliberately **not connected** (`PI_POWER`) |

The link needs **no level shifting**: RP2350 and Pi are both 3.3 V. The old
1k8/3k3 divider and the AHCT gate on this path were the retired 5 V board's needs
and died with it. The series 10 k in each link line is not level shifting — it
bounds the cross-domain current when one side is powered and the other is not
(rationale and arithmetic: R17/R18 in `console_board.py`).

The **74AHCT125** remains for MIDI OUT's current loop and the indicator chain.
Its third gate still drives the ring-data pin (J6 pin 5) and that pin now goes
nowhere: since #987 the ring board generates its own WS2812 timing behind a XIAO
RP2350, so the level shifting for the ring moved onto **that** board. Gate B, R15
and J6 pin 5 stay fitted because the console board exists in copper and its
netlist has to keep matching it. **MIDI IN's H11L1 runs at 3.3 V** and
feeds the Pi directly — no shifter. GPIO4 (pin 7) is left alone: the GeeekPi
N07 NVMe board under the Pi claims it (`PI_RESERVED`).

### Console board ↔ ring board: the 4-way (#987)

The ring board carries its own **XIAO RP2350**, which owns the encoder and
generates the WS2812 timing 20 mm from the LEDs. What used to be eight
conductors across ~600 mm of box is now four.

**On console board v3 the cable is a plain 1:1 4-way, JST-XH at both ends:**

| ring J1 | console v3 J6 | console v2 J6 | conductor |
|---|---|---|---|
| 1 | 1 | 1 | +5V |
| 2 | 2 | 3 | GND |
| 3 | 3 | 6 | LINK_TO_RING — GP13 drives, the XIAO listens |
| 4 | 4 | 7 | LINK_TO_CONSOLE — the XIAO drives, GP14 listens |

**On a v2 console the cable is asymmetric and that was the whole hazard:** the
fabbed 8-way J6 stays, and the ring's 4-way lands on four of its eight positions
(the v2 column). Crimp *that* one 1:1 by position and pin 2 of the ring end lands
on J6 pin 2, which is +5V: the LED rail straight onto a link line. v3 removes the
hazard by construction; `RING_CONTRACT` asserts the map is the identity there.

The link is **full duplex** (owner call). One wire would have carried the traffic
— 115200 is ~11.5 kB/s against a 72-byte pixel frame and a few bytes per detent —
but a single wire forces a master-polled, collision-avoiding protocol on the
firmware, and the second conductor buys that away for one crimp. It cost nothing
in copper: J6 pin 7 was already wired to GP14 with its 10 k pull-up, doing
nothing. Neither pin is on a free hardware UART (GP13 is UART0 RX, but UART0 is
the Pi link on GP16/17, and GP14 is on neither), so the console end is a PIO
UART — of which the RP2350 has plenty spare.

The table above is *not* the source of truth — `RING_PINMAP` in
`console_board.py` is, and `RING_CONTRACT` checks it against `ring_board.net` on
every run.

Notes that are load-bearing:

- **GND is the middle pin** so the pulsed amp-scale LED return does not run
  beside the one signal in the cable.
- **The link pull-ups are on the console board** (J6 pin 6/7's 10 k to *its* 3V3).
  The ring board deliberately fits none — a second pull-up on the other board's
  rail is the split-rail fault `RING_LEVELS` exists to catch, and `LINK_BARE` in
  `ring_board.py` rejects it from the other side.
- **On v2, J6 pins 2, 4, 5 and 8 stay fitted and carry nothing.** Pin 5 could
  never have carried the link anyway: it is the AHCT125's gate-B output with /OE
  tied low, so it is only ever driven by the console. On v3 the ring-data path
  (GP12, gate B, R1, R15) is gone and GP12/GP15 went to the expansion header.
- One 5 V pair, not two: 24 LEDs at the firmware's brightness (128, #1064) are
  0.72 A even all white, half the 1.44 A figure the doubled pair was sized for,
  and the comet the firmware actually draws is ~0.2 A at most. If a bench
  measurement of the *capped* worst case exceeds ~0.7 A, a v2 console still has
  J6 pins 2/4 for a second pair; v3 would need a 6-way.

---

## 4. Raspberry Pi connections

- **Power** — BUCK_PI into the Pi's USB-C. Not the header, not BUCK_AUX.
- **USB** — the four ports are exactly consumed: 2× screen touch, 2× internal
  A-to-A leads to the rear-panel couplers. No hub, no hat. The audio interface
  plugs into a rear coupler from outside the box.
- **Screens** — 2× micro-HDMI out; touch comes back over USB.
- **Storage** — NVMe on the N07 board under the Pi (PCIe — no GPIO use beyond
  the GPIO4 claim noted above).
- **Position** — under the 16" screen (#743, #753). Its own ports face inward
  and are serviceable only with the case open, by intent; everything the build
  needs comes back out through the rear stations.

---

## 5. Rear panel mapping

Nine stations plus the earth stud, on one centreline. The list is generated:
the enclosure writes `rear_io_stations.json` and the board's `REAR_IO_COVER`
gate checks its connector set against it, so this table is commentary, not a
source of truth.

| station | wiring note |
|---|---|
| USB-C PD inlet (`PD_IN`) | D punch; coupler → STUSB4500 → fuse → both bucks. Never touches the console board |
| power button (`POWER`) | momentary, **unlit** → J8, through the board to J9 → the Pi 5's own J2 solder pads. Two wires; no 5 V run to the rear panel. The machine has no power indicator — the screens are the indicator |
| fuse (`FUSE`) | 5×20 screw-cap holder — value and placement are §2's (T5A slow-blow, in the 20 V feed) |
| MIDI DIN-5 ×2 (`MIDI_IN`/`MIDI_OUT`) | IN is opto-isolated **on the board** — the socket alone is not enough. IN's pin 2 stays unbonded (that isolation is the point) |
| Neutrik NJ6FD-V ×2 (`CTRL_1`/`CTRL_2`) | 6-pole switching 1/4" jack, rear-mounted through a Ø12 hole with its snap cap (needs the 1.5 mm panel). Vertical PCB pins, no lugs. On v2 connect T / R / S and leave TN / RN / SN open. An expression pedal OR footswitch on the same jack, auto-detected (tip → ADC with pull-up, ring → 3V3 through 1 k). A two-switch pedal on one TRS plug (BOSS FS-6 A&B) puts its B switch on the ring, which firmware ≥ 1.1 reads on GP20/GP21: a trace through 4.7 kΩ on board v3 (R19/R20); on v2 one wire from each jack's ring pin (J20/J21 pin 2) to J22's GP20/GP21 pads. Without either, use the pedal's separate A and B mono jacks, one per CTRL. **v3 jacks are Neutrik NJ6FD-V** (switched): a fourth lead, the tip-normal contact, tells the board whether anything is plugged in (J20/J21 pin 4 → GP19/GP22), so an empty jack never reads as a pedal at full toe |
| USB 3.0 coupler ×2 (`USB3_1`/`USB3_2`) | internal A-to-A leads to two Pi ports |
| M6 earth stud | between the cluster and the vent block; rules in the grounding doc |

---

## 6. Grounding & ventilation

Single common ground; DIN **IN** opto-isolated; exactly **one** hard chassis
bond, at the board's H1. The full scheme — what goes on the earth stud, what
deliberately does not, and the bench audit to run before trusting any of it —
lives in `docs/design/console-grounding-and-bonding.md` (#751). Vents: intake
in the bottom plate, exhaust in the rear wall; air crosses the boards and the
Pi's active cooler.

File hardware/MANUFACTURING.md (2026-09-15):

# Segno console — manufacturing package

Everything needed to build one console, grouped by vendor. All enclosure
outputs regenerate from `enclosure/segno_enclosure.py` (run it before quoting —
it also refreshes the vendor quote zips below, so they can never go stale).

The zips are **not tracked in git** (#236): they are per-quote artifacts,
rebuilt with a freshness gate by `build_quote_packages()`. **On each real
vendor order, freeze the record**: regenerate, let the freshness gate pass,
send, then attach the exact zips sent to a git tag / GitHub Release for that
order. The tag is the immutable record of what the vendor received; the
working tree never is.

## 1. Sheet metal (laser cut + bend + powder coat)

Send **`enclosure/out/segno_sheetmetal.zip`** (DXF flat patterns + PDF drawings
for every part) plus **`enclosure/out/segno_sheetmetal_step.zip`** (3D reference
STEPs incl. the folded assembly). The zip carries **metal only** — the printed
overlay is a separate package (section 4).

| Part | Qty | Material | Notes |
|---|---|---|---|
| `segno_base` | 1 | 2.0 Al | ONE folded blank: floor + 4 walls + rear transition. Weld-free (corner brackets rivet). |
| `segno_faceplate` | 1 | 2.0 Al | Sloped lid, full-width blank. Fold conventions in the drawing NOTE (chirality matters). |
| `segno_rear_panel` | 1 | **1.5 Al** | Dismountable I/O sub-panel (#751); flat, no bends. 1.5 mm, not 2.0: the CTRL jacks are Neutrik NJ6FD-V, whose snap cap only reaches a 1.2–1.5 mm panel (#993). |
| `segno_corner_bracket_rear` | 2 | 2.0 Al | Internal L-brackets; ONE part serves both corners (left = flipped). |
| `segno_ring_disc` | 1 | 2.0 Al | Encoder LED-ring centre disc. |
| `segno_post` | 2 | **1.6 CR steel** | Faceplate support posts — **1.6 mm cold-rolled STEEL**, not the 2.0 Al of the shell. |

(The old `segno_screen_bracket` ×8 row is gone deliberately: the screens mount
on printed stands anchored to the base floor (#762), not on sheet brackets.)

This table is the source of truth for quantity and material: `PART_SPECS` in
`segno_enclosure.py` carries the same numbers onto every PDF title block, and the
generator asserts it. Before #775 the drawing writer defaulted both, so every
sheet claimed "2.0 mm 5052-H32 Al, qty 1" — including the steel post, ×2.

### Reading the drawings

- **The sheets are written in SPANISH** (issue #778). The parts are fabricated in
  Argentina and the shop floor reads Spanish, so every instruction a fabricator
  acts on — part notes, bend tables and their footnotes, the layer legend, title
  blocks, mask callouts, the tolerance block — is Spanish. What is deliberately
  **not** translated: layer names (`CUT`, `BEND`, `VENT`, `MASK`, `NOTE`,
  `ENGRAVE`, `SILK`) and part stems (`segno_base`, …), because they are the
  identifiers inside the DXFs and the zips and are how a printed sheet is paired
  to its file; numbers, units, `Ø ± °` and standard designations (5052-H32, M3,
  K-factor, R2). The title block prints the Spanish part name **and** the stem.
- **Every sheet-metal drawing carries a general tolerance block**
  (`TOLERANCIAS (salvo indicación contraria)`): hole position ± 0,15 mm, hole
  diameter ± 0,10 mm, bend angle ± 0,5°, outside/flat dimensions ± 0,3 mm, and
  dimensions measured across a fold ± 0,5 mm. The last row is the honest one: a
  dimension that crosses a bend stacks deduction, springback and gauge scatter,
  and ± 0,3 mm is not holdable across the base's five folds.
- **Every sheet with folds carries a bend table**: line position, length, fold
  rotation, included angle, direction relative to the drawn face, inside radius
  and the development deduction the flat was built with. The base's five rows are
  printed **in fold order** — transition first while the blank is flat, then
  front and rear walls, then the two sides (their punch has to fit between the
  already-standing walls). The transition fold is **65.556° rotation / 114.444°
  included**, neither 90 nor 180; guess it and the lid's rear lap and its nine M3
  pilots all land in the wrong plane.
- **`CUT` and `VENT` are one and the same operation — both cut clean through.**
  `VENT` is 127 louvres, ~18 425 mm² and ~5.6 m of cut path. It must be in the
  quote; the alternative is a sealed box with a Raspberry Pi 5 inside it.
- **`BEND` lines are fold references only** (`no cortar, no marcar, no rayar ni grabar`).
  There are 3 380 mm of them on the base alone.
- **`MASK` is a no-paint coating mask, never a cut** — red dash-dot, and every
  ring carries its own `NO CORTAR` callout. The Ø20 ring on the base is the M6
  earth-stud bonding land: cut it and the base is scrap and the safety earth is
  gone.

Material: **2.0 mm 1050 aluminium** (the shop's stock; softer than 5052 and folds R2 without complaint), K-factor 0.33, R2 tooling (bend notes
on each drawing). `segno_post` is the exception: **1.6 mm cold-rolled steel**.
Finish: black powder coat, outside faces.

**Lid-seam threads (18x M3).** The Ø2.5 pilots on the base front wall and rear
transition are laser-cut, **tapped M3 after bending**, and the threads must be
**masked before coating or chased after it** — powder in a 2 mm-deep thread
binds the screw, and there are only ~4 threads to lose. (The old note here said
"front-lip M4": wrong on both counts since the #762 seam conversion — the lip
carries Ø3.4 *clearance* holes, the base carries the taps, and the size is M3.)

**Lid-to-base fit — READ THIS BEFORE FOLDING THE LID.** In CAD the lid's front
lip lands *flat* against the front wall: lid-to-base minimum distance measures
**0.0000 mm**. Both faces are outside faces and **nothing is masked** (owner
call: coat everything), so as drawn the joint is roughly 0.16 mm of interference
before any tolerance.

The fix is a **fit, not a dimension**: fold the front lip slightly open so that,
**after coating**, the lip inner face clears the front wall outer face by
**0.3 mm** — tight, but it slips on without force. Check it against the finished
base before setting the fold. The same note is on the lid drawing.

## 2. 3D printing (FDM)

Send **`enclosure/out/segno_3dprint.zip`** (STEP + STL for each part).

| Part | Qty | Material | Notes |
|---|---|---|---|
| `segno_platform_front` | 8 | **BLACK** PETG/ASA, ≥40% infill | Pedal pedestal TUB, 115.4×88.8 (deck 13.2, walls to ~37 with sloped top ~0.3 under the faceplate; deck raised for flush-at-rim seating, issue #373 — pedal case top flush with the slot's upper rim, pad above the metal). Perimeter strips outside the slot opening are relief-shaved to the same under-plate plane. Wall inner faces tucked 0.4 behind the slot cut line, so from above only faceplate shows and the reveal reads as a dark channel. Full-height boss drop-in channels in the side walls; 12-wide rear cable notch. Heat-set pilots Ø4.5 from below — the taller deck now takes the standard **M3 5×5 inserts** (4 per pedestal; short M3×3 no longer needed); 1.2-deep pad pocket in the deck. |
| `segno_platform_mid` | 2 | **BLACK** PETG/ASA, ≥40% infill | Tall CLEAR/BANK tub (walls to 73.7 — row 2 sits on the 16in aperture's front edge since #796, 37.6 mm forward of the #366 label-top position; deck raised for flush-at-rim seating #373), hollow with boss columns — standard **M3 5×5 inserts** (4 per pedestal) + the same pocket, channels, notch and perimeter relief. |
| `segno_led_diffuser` | 10 | **White PLA** | Pill lens on a 4 mm shoulder, pushes into the faceplate slot from inside; **the shoulder is GLUED to the faceplate underside**, so keep that face clean. 68 × 14 × 6.33. **Print LENS-DOWN** — the lens face is then the bed face, with no layer lines across the light; a TEXTURED bed frosts it for free. ⚠️ Lens-down also makes the shoulder a **4.1 mm-per-side unsupported step** onto the glue face, and the retaining lips cantilevers over open air; **slice it before printing ten** and decide whether that face takes support (support marks land on the glue seat) or the part goes on its side instead. An **8-LED, 55.56 mm segment of 144 LEDs/m bare IP20 12 mm strip** snaps into the channel on the back: **bow it slightly, drop it past the lips, let it flatten**. Its own adhesive is useless — the LEDs face the lens, which turns the tape to face away into the console. The strip is the spring; nothing printed flexes. Grip 0.4 mm per edge; both ends open for the 3 wires. One per pedal — all ten since #930 restored the four transport pills #792 had removed.
| `segno_pedal_tile_*` | 10 | **BLACK + WHITE** PLA/PETG | Pedal name tiles, one per pedal, dropping into the WTB-006 top pad's window. **TRAPEZOID**, 54.36 (back) / 53.76 (toe) × 19.90 × 2.20 — the pad is a wedge in plan, and the window keeps a 5 mm wall each side at every station, so the tile's sides run parallel to the pad's. Both widths are derived from the pad measured in the Cherub Fusion doc (window 54.46 / 53.86, less 0.05/side). **Fit the WIDE edge toward the cable end**; it carries the top of the glyphs, so the wrong way round reads upside down. The pad is a uniform 2.2 slab on a case top tilted to match, so the window is a parallel-sided pocket in depth and the tile is flat in Z. **Print FACE-DOWN with a filament change at z = 0.4**: the glyphs stand proud of the body, so face-down they are the first 0.4 mm off the bed — print that in white, swap to black, flip. One extruder. The letters finish flush with the pad and the black field sits 0.4 mm below it, out of the scuff line. Text is generated from the same `PEDALS`/`SILK_SYMBOLS` source as the faceplate legends, so REC/PLAY and STOP carry the dot+plus+triangle and square rather than words. |
| `segno_ring_diffuser` | 1 | **White PLA** | Annular lens for the encoder LED ring. Cut for the **Ring 24** (Ø67 window); its back-plate radii are hardcoded, not derived — re-derive them with any window resize. The back plate is OPEN over the LED circle (r 25.6–33.2): the PR #990 board carries the Ring 24 on a 2.54 mm pin strip, and a web there collided with it; the ring glows through the 2.4 mm lens. |

The Cherub WTB-006 has **no base screws** (one horizontal through-screw per
side): retention = the deck pocket + gravity + foot pressure, **PROVISIONAL**.

FDM tiles stay the prototype / fit-check path. Production nameplates are the
2-ply pack in the next section.

## 2b. 2-ply engraved plastic (pedal name tiles)

Send **`enclosure/out/segno_pedal_tiles.pdf`** to a 2-ply laser shop
(1:1, red cut / black fill). The zip also carries the DXF if they ask for
CAM. **Not metal, not vinyl, not a 3D print.**

| Part | Qty | Material | Notes |
|---|---|---|---|
| `segno_pedal_tiles` | 10 | **2.0 mm 2-ply** (black cap / white core) | Same trapezoid as the FDM tiles: 54.36 (back) / 53.76 (toe) × 19.90. 2.0 mm is the closest standard stock to the 2.2 mm pad pocket — the tile sits 0.2 mm recessed. **CUT** = outline (through-cut). **ENGRAVE** = filled glyphs (burns the black cap so the white core reads). Glyphs are geometry, never TEXT — do not substitute a font. **Fit the WIDE edge toward the cable end**; it carries the top of the glyphs. REC/PLAY and STOP are the same symbols as the faceplate overlay. Dimensions are nominal: the 0.05 mm per-side clearance is already in the part; the shop applies kerf compensation and must not enlarge the outline. |

Regenerate with `segno_enclosure.py` (or `--tiles-only`). The zip is a
per-quote artifact, same freshness gate as the other vendor packs (#236).

## 3. PCBs

| Board | Files | Qty | Notes |
|---|---|---|---|
| **Console board v3** (`console_board.py`, #990) | `kicad/out_console/segno_console_board_gerbers.zip` (run `route_console_board.sh` to produce) + `kicad/fab/segno_console_board_bom.csv` | 1 | Hardware work in progress: Pico 2, MIDI front end, sensed CTRL jacks, ring-board link and PD header. The ring-link and PD firmware are unfinished; this is not the v2 board running release 137. See the [integration record](../docs/APPLIANCE_INTEGRATION.md). |
| Encoder ring PCB (#987) | `kicad/fab/segno_pedal_ring_gerbers.zip` + `kicad/fab/segno_combined_bom_lcsc.csv` | 1 | Ø68 Ring 24 board with a XIAO controller and a four-conductor link to v3 J6. The XIAO firmware and console-side ring link are unfinished. Existing direct-encoder v2 wiring does not apply to this board. See [the ring design](kicad/ring_board.py). |
| LED puck (single WS2812B) | `led_strip/segno_led_strip_gerbers.zip` | 0 | **NOT ORDERED for the console.** Owner call 2026-08-28: the indicators are eight-LED segments cut from a **144 LEDs/m bare IP20 strip**, and the diffuser channel is sized for that (**12 mm wide, 0.53 thick**, 56.96 long), not for this 16×8 board. The design is kept because it is finished and the footprint may suit another build — but ordering it will not fit the current diffuser. |

## 4. Printed overlay

Send **`enclosure/out/segno_overlay.zip`** (`segno_overlay.dxf` + `.pdf`) to a
label/overlay printer → die-cut adhesive vinyl/polycarbonate top overlay,
846 × 406.6 mm, black field, white legends, die-cut apertures. Replaces all
silkscreen on the metal.

**Not a metal part.** It used to ride inside `segno_sheetmetal.zip` with a title
block reading "2.0 mm 5052-H32 Al, qty 1" — 0.34 m² of aluminium cut and powder
coated for nothing, roughly a third of the metal spend. It now has its own
package and its own material string.

## 5. Purchased parts

Full list with links: **`segno_console_shopping_list.md`**; the console board's
parts are `kicad/fab/segno_console_board_bom.csv`. Headlines:

- 10× Cherub WTB-006 footswitches; 15.6" 5V USB-C touch panel; APROTII 7" monitor
- Raspberry Pi 5 + Active Cooler
- 5V bucks: **eleUniverse 8–36V→5V 10A IP67** (Amazon B0GGHN97TK) **×2** —
  BUCK_PI + BUCK_AUX, fed 20 V from the USB-C PD inlet (#754); the 9 V brick
  is gone
- 1× **encoder knob, Ø50 × 18, Ø6 bore, black aluminium, plain (un-knurled) barrel** —
  the ring window and `segno_ring_diffuser` are sized around this Ø50. `out/segno_encoder_knob.step`
  is a REFERENCE model of it for the assembly, deliberately **not** in the 3D-print pack.
  Check one thing with calipers before the faceplate is cut: the model assumes a Ø22 × 4.5
  underside relief clearing the EC11 nut. If the real knob's underside is solid it will sit
  ~3 mm proud of where the model puts it.
- 1× NeoPixel **Ring 24** — 65.5 mm OD / 52.3 mm ID / 3.2 mm thick (the ring the owner has;
  the faceplate window and `segno_ring_diffuser` are cut for THESE numbers, not the Ring 16's 44.5 mm)
- Heat-set inserts: **M3 5×5 throughout** (5.0 long × 5.0 OD, pilots Ø4.5), brass —
  40× console pedestals (4 per pedestal) + 8× mini-console pedestals + 3× mini lid.
  (Short M3×3 obsolete since the #373 deck raise gave the front pedestals full pilot depth.)
- Fasteners: 40× M3×8 (platform bolts, from below), 18× M3×8 (lid seam: front
  lip + rear lap, into hand-tapped Ø2.5 pilots — NO clinch nuts anywhere; the
  old "PEM M4 nuts per drawing" line is obsolete, no drawing carries PEM holes
  or masks any more), 10× Ø3.2 pop rivets (corner brackets), 4× M2.5×35.3 Pi
  risers (stack or turn — 35.3 mm is derived, see `PI_RISER_H`), 4× M3×12 +
  standoffs 15 mm (console board), 4× M4 (buck ears — two bricks, two ears
  each), 4× M4 (support post feet)
- Cabling per **`segno_wiring.md`** (HDMI ×2, USB, the 20 V PD feed + 5 V buck
  runs, the 2×20 keyed ribbon, JST looms)

## 6. Reference (do not send to vendors)

- `enclosure/out/segno_assembly.step` — full folded assembly
- `segno_enclosure_design.md`, `segno_wiring.md` — design + wiring
- Fusion cloud docs: "Segno sheet metal" (native sheet-metal validation) and
  "Segno console (populated)" (full visual assembly + exploded storyboard)

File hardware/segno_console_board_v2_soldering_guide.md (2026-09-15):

# Segno console board v2 — soldering guide

Hand-assembly walkthrough for the **console board v2** (`hardware/kicad/console_board.py`,
issue #747): the Pico 2 / RP2350 control board that lies beside the Raspberry Pi 5 in the
floor console. Everything on it is through-hole except the Pico 2 module itself, which is
soldered down by its castellations.

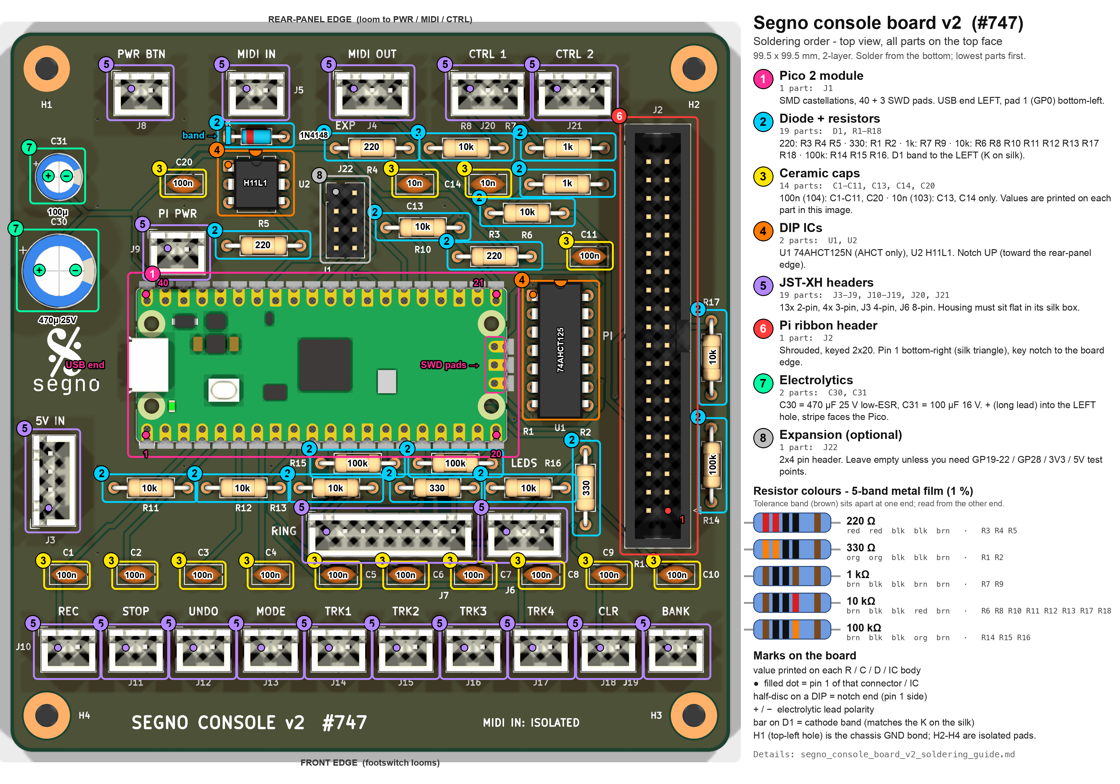
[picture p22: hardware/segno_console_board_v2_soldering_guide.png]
Soldering order, annotated top view


The image is the routed board (`kicad/out_console/segno_console_board.kicad_pcb`, DRC
0 / 0) rendered from the top with every part outlined in the colour of its step. Every resistor, capacitor,
diode and IC has its **value printed on its body** in the image, so you can solder straight
from the picture. A filled dot is pin 1, the half-disc on a DIP is its notch, `+`/`−` are
the electrolytic leads, and the bar on D1 is its cathode band.

Sources of truth, in case this page and a file disagree: the netlist generator
`kicad/console_board.py`, the layout generator `kicad/console_board_pcb.py`, the BOM
`kicad/fab/segno_console_board_bom.csv`, and the purchase list
`segno_console_board_v2_lista_compras.txt`. This guide does **not** cover the encoder ring
PCB (`segno_pedal_ring`, see `MANUFACTURING.md` §3) or the V1 pedal board.

---

## 1. Before you pick up the iron

### Tools

| Item | Notes |
|---|---|
| Temperature-controlled iron, chisel or bevel tip ~2 mm | 320–350 °C leaded, 350–370 °C lead-free |
| Solder 0.6–0.8 mm, flux-cored | Plus a flux pen for the Pico castellations |
| Flush cutters, fine tweezers, Kapton or masking tape | Tape holds the Pico flat while tacking |
| Multimeter with diode/continuity mode | Used for sorting and for every check below |
| Isopropyl alcohol + brush | Clean flux off around U2 (the isolation barrier) |
| Optional: DIP-14 + DIP-6 sockets | Not on the BOM; fine to add for U1/U2 |

### Sort the parts with the meter, not the colour bands

The resistors are ¼ W **metal film, 1 %**: blue body, **five bands**. Four bands sit
together (three digits + multiplier) and the fifth, the brown 1 % tolerance band, sits
apart at the other end. Read from the grouped end. The same key is drawn in the image.

| Value | Qty | Refs | 5-band code (digit · digit · digit · multiplier · tolerance) |
|---|---|---|---|
| 220 Ω | 3 | R3, R4, R5 | red · red · black · black · brown |
| 330 Ω | 2 | R1, R2 | orange · orange · black · black · brown |
| 1 kΩ | 2 | R7, R9 | brown · black · black · brown · brown |
| 10 kΩ | 8 | R6, R8, R10, R11, R12, R13, R17, R18 | brown · black · black · red · brown |
| 100 kΩ | 3 | R14, R15, R16 | brown · black · black · orange · brown |

Brown-black-black-*x*-brown is three of the five values; only the fourth band tells 1 k,
10 k and 100 k apart (brown, red, orange). Meter them.

| Capacitor | Qty | Refs | Marking / size |
|---|---|---|---|
| 100 nF ceramic disc, 2.5 mm pitch | 12 | C1–C11, C20 | `104` |
| 10 nF ceramic disc, 2.5 mm pitch | 2 | C13, C14 | `103` |
| 470 µF **25 V low-ESR (≤0.15 Ω)** radial | 1 | C30 | Ø10 mm, 5 mm pitch. A 16 V part is Ø8/3.5 mm and will not fit |
| 100 µF 16 V radial | 1 | C31 | Ø6.3 mm, 2.5 mm pitch |

Semiconductors: U1 **74AHCT125N** (it must be AHCT — HC or HCT will not take a 3.3 V input
reliably), U2 **H11L1**, D1 **1N4148**, and the **Raspberry Pi Pico 2** (non-W).

Connectors: 13× JST-XH 2-pin (J5, J8, J9, J10–J19), 4× JST-XH 3-pin (J4, J7, J20, J21),
1× JST-XH 4-pin (J3), 1× JST-XH 8-pin (J6), 1× shrouded keyed 2×20 IDC header (J2),
and optionally 1× 2×4 pin header (J22).

### If you have a v3 board

v3 is the same board with the ring-board link (#987) and the CTRL ring sense
(firmware 1.1) in copper. What differs from everything below:

| | v2 | v3 |
|---|---|---|
| J6 `RING` | JST-XH 8-pin; the ring board's 4-way lands on pins 1, 3, 6, 7 | **JST-XH 4-pin**, cable 1:1 with the ring board's J1 |
| R1 (330 Ω), R13 (10 kΩ), R15 (100 kΩ) | fitted | **not fitted, no pads** — the ring-data path is gone; U1's gate B is parked |
| R19, R20 | — (bench wires from J20/J21 pin 2 to J22's GP20/GP21 pads instead) | **4.7 kΩ**, in the row under the Pico where R13 and R15 used to be (R20 in the slim band by R16, R19 in the row below): the ring-sense series parts. Far from the jacks on purpose — DC sense lines, and the column under `CTRL 1` stays J22's |
| J20 / J21 `CTRL` | JST-XH 3-pin: tip, ring, sleeve | **JST-XH 4-pin**: tip, ring, sleeve, **TN** (the jack's tip-normal contact). The jacks themselves are **Neutrik NJ6FD-V** (switched, same D punch). The pair sits 2.6 mm further left than on v2 |
| R21, R22 | — | **4.7 kΩ**, the row under R11/R12, left of R19: presence series parts (TN → GP19/GP22) |
| R11, R12 | row under the Pico at y 63 | On the slim band right under the Pico's bottom pads, with R20 and R16 |
| J22 `EXP` | 2×4, right of U2: +3V3, +5V, GP19, GP20, GP21, GP22, GP28, GND | Same place, **2×3**: +3V3, +5V, **GP12, GP15, GP28**, GND. Pin 1 top-left; odd pins are the left column |
| J23 `PD` | — | **JST-XH 3-pin, new**, in the `RING` / `LEDS` row under the Pico's left end, right of `5V IN`: pin 1 GND, 2 SDA (GP0), 3 SCL (GP1). I2C to the STUSB4500 PD trigger, three wires only — do not run the trigger's VDD from this board |

Use the resistor colour key as printed; the only new value is **4.7 kΩ = yellow · violet · black · brown**.

### Check the bare board

- No visible scratches across the ground pour, no lifted pads, holes all drilled.
- Continuity: `+5V` to `GND` open (J3 pin 1 to pin 2), `+3V3` to `GND` open
  (J2 pin 1 to J2 pin 6). If either reads a short on the bare board, stop.
- Orientation: the silk reads correctly with the **five rear-panel headers
  (PWR BTN, MIDI IN, MIDI OUT, CTRL 1, CTRL 2) along the top edge** and the **ten footswitch
  headers (REC … BANK) along the bottom**. `5V IN` is on the left, `PI` on the right.

---

## 2. Soldering order

All parts go on the **top** (silkscreen) face and are soldered from the bottom, except the
Pico, which is soldered from the top. Lowest parts first so the board still lies flat on
the bench for each step.

### Step 1 — Pico 2 module (J1)

The only surface-mount job on the board, and the one to do first while nothing is in the
way. The module lies flat on the board and its 40 castellated half-holes sit on 40 SMD pads
underneath.

| Check | What you should see |
|---|---|
| Orientation | **USB connector at the LEFT end**, toward the `5V IN` header. |
| Pad 1 (GP0) | Bottom-left corner of the module. Pads 1–20 run left→right along the **bottom** row. |
| Pad 40 (VBUS) | Top-left corner; pads 21–40 run right→left along the **top** row. Pad 39 (VSYS) sits next to it and is the module's 5 V feed from J3. |
| SWD pads | The three `DEBUG` holes at the module's **right** end (SWCLK, GND, SWDIO) sit on the board's pads D1/D2/D3. |

1. Flux the 40 board pads and the 3 SWD pads.
2. Lay the module down and slide it until every castellation is centred on its pad. Tape
   it across the middle.
3. Tack **pad 1** (bottom-left) and **pad 21** (top-right). Re-check alignment along both
   rows; reheat and nudge if any half-hole is off its pad.
4. Solder every castellation: tip touching the board pad and the half-hole together, feed
   a little solder, let it wick up the half-hole. Do the 8 GND pads (3, 8, 13, 18, 23, 28,
   33, 38) last; they sink more heat.
5. The three SWD pads: put the tip into each `DEBUG` hole on the module and feed solder
   until it fills the hole and flows onto the board pad below. These are what the Pi uses
   to reflash the board, so they have to be real joints, not cosmetic ones.
6. Meter, before moving on: pad 39 (VSYS) ↔ J3 pin 1 continuity; pad 2 (GP1) ↔ pad 3
   (GND) **open**; pad 40 (VBUS) ↔ pad 39 **open** (VBUS goes nowhere on this board);
   a quick sweep along each row for bridges between neighbours.

If your Pico 2 has a 3-pin JST-SH debug socket instead of three holes (some later batches
and every "H" variant), the castellations still solder as above and SWD needs three short
wires from that socket to the board's D1/D2/D3 pads.

### Step 2 — D1 and the 18 resistors

Flat axial parts, 10.16 mm lead pitch for the resistors, 7.62 mm for the diode. Bend the
leads at the body, insert, splay slightly, solder, trim.

| Ref | Value | Where | Note |
|---|---|---|---|
| D1 | 1N4148 | Between `MIDI IN` (J5) and U2 | **Cathode band to the LEFT**, on the `K` printed on the silk. It is the reverse clamp across U2's LED. |
| R5 | 220 Ω | Left of U2, below `PI PWR` | MIDI IN series resistor |
| R4 | 220 Ω | Under `MIDI OUT` (J4) | MIDI OUT +5 V leg |
| R3 | 220 Ω | Right of centre, under C13 | MIDI OUT signal leg from U1 gate C |
| R6 | 10 kΩ | Right of R3 | U2 output pull-up to 3V3 |
| R8, R7 | 10 kΩ, 1 kΩ | Under `CTRL 1` | R8 tip pull-up, R7 ring current limit |
| R10, R9 | 10 kΩ, 1 kΩ | Under `CTRL 2` (R10 is lower, R9 right of R6) | Same for CTRL 2 |
| R11, R12, R13 | 10 kΩ | Row under the Pico, left | Ring-link pull-ups to 3V3 (#987; before that, encoder A / B / SW). v3 has no R13 |
| R1 | 330 Ω | Same row, right of R13 | Ring data series, U1 gate B → J6 pin 5. v2 only |
| R18 | 10 kΩ | Same row, right of R1 | Link RX series (Pi → Pico) |
| R15, R16 | 100 kΩ | Just under the Pico's bottom pad row | Ring / indicator data pull-downs. v3 has no R15 |
| R2 | 330 Ω | **North-south**, right of `LEDS` | Indicator data series, U1 gate A → J7 pin 2 |
| R17 | 10 kΩ | **North-south**, right of the ribbon header, upper | Link TX series (Pico → Pi) |
| R14 | 100 kΩ | **North-south**, right of the ribbon header, lower | MIDI TX pull-down (holds MIDI OUT quiet when the Pi is off) |

Resistors have no polarity. R2, R14 and R17 are the only ones that stand rotated 90°;
all are flat against the board.

### Step 3 — 14 ceramic capacitors

2.5 mm pitch discs, no polarity, no lead forming. Seat each one down to the board.

| Refs | Value | Where | Role |
|---|---|---|---|
| C1 … C10 | 100 nF | The row above the ten footswitch headers, one per switch, left→right REC … BANK | Debounce (with the RP2350's internal pull-up) |
| C11 | 100 nF | Right of R9, above U1 | U1 +5 V decoupling |
| C20 | 100 nF | Left of U2 | U2 +3V3 decoupling |
| **C13, C14** | **10 nF** | Under `MIDI OUT` / `CTRL 1`, next to R8 | CTRL 1 / CTRL 2 anti-alias. The only two `103`s on the board. |

### Step 4 — U1 and U2

| Ref | Part | Where | Orientation |
|---|---|---|---|
| U2 | H11L1, DIP-6 | Directly under `MIDI IN`, in its own copper-free pocket | **Notch / pin 1 at the top** (toward the rear-panel edge). Pins 1–3 down the left side. |
| U1 | 74AHCT125N, DIP-14 | Between the Pico's right end and the ribbon header | **Notch / pin 1 at the top.** Pins 1–7 down the left side, 8–14 up the right. |

Both packages have their notch pointing at the rear-panel (top) edge. Solder two diagonal
pins first, check the package is flat and the right way round, then the rest. If you use
sockets, orient the socket's notch the same way and press the IC in after everything else
is done.

U2 is the MIDI isolation barrier: after soldering, clean the flux off around it and D1.
Conductive flux residue across that 2 mm gap defeats the whole point of the opto.

### Step 5 — the 19 JST-XH headers

The pad pattern will not stop a 2-pin or 3-pin header going in backwards, so use the silk:
the printed box is the housing's footprint and a header that is rotated 180° will not sit
flat inside it. Pin 1 of every header is the dot in the image. Solder one pin, press the
housing flat while reheating it, then solder the rest.

| Refs | Size | Silk label | Pin 1 side |
|---|---|---|---|
| J8, J5, J20, J21 | 2/2/3/3-pin | `PWR BTN`, `MIDI IN`, `CTRL 1`, `CTRL 2` (top edge) | Left |
| J4 | 3-pin | `MIDI OUT` (top edge) | Left |
| J9 | 2-pin | `PI PWR`, below J8 | Left |
| J3 | 4-pin | `5V IN`, left edge, vertical | **Bottom** (pins run upward 1→4) |
| J6 | 8-pin | `RING`, under the Pico | Left |
| J7 | 3-pin | `LEDS`, right of J6 | Left |
| J10 … J19 | 2-pin | `REC STOP UNDO MODE TRK1 TRK2 TRK3 TRK4 CLR BANK` (bottom edge) | Left |

### Step 6 — J2, the Pi ribbon header

Shrouded, keyed 2×20 box header on the right edge, silk `PI`.

- **Pin 1 is bottom-right**, marked by the small silk triangle beside R14. Odd pins run up
  the right-hand column, even pins up the left-hand column.
- The shroud's polarising notch faces the board's right edge; the silk outline of the
  shroud shows the notch, so match the plastic to the silk.
- Only 16 of the 40 pins carry anything. Pins 2 and 4 (the Pi's 5 V) are deliberately
  **not connected** on this board and must never be jumpered to `+5V`.

Solder two diagonal corner pins, check it is flat and square, then the other 38. The
ground pins (6, 9, 14, 20, 25, 30, 34, 39) sit in the pour and need a second longer.

### Step 7 — C30 and C31, the electrolytics

The tallest parts, so they go last on the left edge.

| Ref | Value | Where | Polarity |
|---|---|---|---|
| C31 | 100 µF 16 V | Upper-left, under `C31` | **+ (long lead) in the LEFT hole**, the one with the silk `+`. Stripe faces the Pico. |
| C30 | 470 µF 25 V low-ESR | Below C31, under `C30` | Same: **+ left**, stripe toward the Pico. |

Both are across `+5V`/`GND`. Backwards, C30 vents at the first power-up; check the stripe
twice before soldering.

### Step 8 — J22 expansion header (optional)

2×4 pin header labelled `EXP`, right of U2. It carries `+3V3`, `+5V`, GP19–GP22, GP28 and
GND and nothing on the board depends on it. Leave it empty unless you want it — but note
that pins 1 (`+3V3`), 2 (`+5V`) and 8 (`GND`) are the handiest test points on the board,
which is a good reason to fit it on the first unit. Pin 1 is top-left; odd pins are the
left column.

### Mounting holes

H1–H4 are M3 with 6.4 mm plated pads. Nothing to solder. **H1 (top-left, nearest
`PWR BTN`) is the one chassis-ground bond**: it is wired to GND, so its standoff must make
metal contact with the case. H2–H4 are isolated pads; use whatever standoffs you like.

---

## 3. Inspection and meter checks before power

1. Clip every lead flush and look at the bottom under a lamp: each joint a wetted cone,
   no bridges between the C1–C10 row and the J10–J19 row, none along U1/U2, none between
   Pico castellations.
2. Clean flux around U2, D1, R5 and J5.
3. Meter checks (board unpowered, nothing plugged in):

| Between | Expect | Catches |
|---|---|---|
| J3 pin 1 (`+5V`) ↔ J3 pin 2 (`GND`) | Open, or a slowly rising reading (C30 charging) | Bridge on C30/C31/U1/J6/J7, Pico VSYS to GND |
| J3 pin 1 ↔ J3 pin 3 | Short (they are the same rail) | J3 soldered on the wrong pins |
| J2 pin 1 (`+3V3`) ↔ J2 pin 6 (`GND`) | Open | Bridge on C20, U2, the pull-ups |
| J2 pin 2 and pin 4 ↔ anything | Open to `+5V` and `GND` | These must stay unconnected |
| J5 pin 1 and pin 2 ↔ GND | Open (> 1 MΩ) | MIDI IN isolation compromised: bridge or flux across U2 |
| J5 pin 1 ↔ pin 2, diode mode | ~0.6–0.7 V one way (D1), ~1.1–1.3 V the other (U2's LED), through R5 | 0 V either way = bridge on D1/U2 |
| Pico pad 39 ↔ J3 pin 1 | Short | VSYS castellation not wetted |
| Pico pad 40 ↔ pad 39 | Open | VBUS bridged to VSYS |
| J10 pin 1 ↔ Pico pad 4 (GP2) | Short | REC footswitch path; repeat for one or two others if you like |
| J6 pin 5 ↔ U1 pin 6 | ~330 Ω (R1) | Ring data path through the buffer |

---

## 4. First power-up (bench, no Pi)

Keep the Pi out of it until the board has run on its own.

1. **USB only.** Hold BOOTSEL, plug the Pico's USB into a computer. An `RP2350` drive
   appears. VBUS is not connected to the board, but the module's own VSYS feed puts
   ~4.8 V on the `+5V` rail, so U1 and the electrolytics are live; nothing should warm up.
   Drop a `blink` UF2 from `pico-examples` onto the drive and confirm the green LED blinks.
2. **5 V from a bench supply on J3**, USB unplugged, current limit 300 mA: `+5V` on pins
   1 and 3, `GND` on pins 2 and 4. Idle draw is a few tens of mA. Confirm 5 V at J22 pin 2
   (or on C30's `+` lead) and that the blink still runs.
3. **3V3 domain.** With no Pi attached the `+3V3` rail is dead — it comes in over the
   ribbon, not from the Pico. To exercise U2 and the pull-ups on the bench, feed 3.3 V into
   J22 pin 1 (or J2 pin 1) from the supply's second channel, limit 100 mA. Then:
   `MIDI_RX` (J2 pin 10) idles at 3.3 V; driving 5 V through a 220 Ω resistor into J5
   pin 1 (return on pin 2) pulls it to 0 V.
4. **Footswitch path.** With the internal pull-up enabled in firmware, shorting J10 pin 1
   to pin 2 reads GP2 low; release is an RC of a few ms through the 100 nF.
5. **Ribbon.** Only after all of the above: Pi off, ribbon on with pin 1 to pin 1 at both
   ends (both headers have pin 1 at the front/SD-card end by design, so the cable does not
   fold), then power the Pi from its own supply and the board from BUCK_AUX per
   `segno_wiring.md` §2.

Firmware note: the Pico runs `firmware/console_board/`; `firmware/console_board/pedal_link.h`
is the wire-protocol reference. Whatever runs on the Pico
must enable the internal pull-ups on the ten footswitch inputs, the encoder inputs and
the two CTRL tips, or those inputs float (see the notes in `console_board.py`).

---

## 5. Connector pinouts for the looms

| Header | Pin 1 | Pin 2 | Pin 3 | Pin 4 … |
|---|---|---|---|---|
| J3 `5V IN` | +5V | GND | +5V | GND (1/3 and 2/4 are parallel pairs) |
| J4 `MIDI OUT` | DIN pin 5 (via R3) | DIN pin 4 (via R4 from +5V) | DIN pin 2 (shield → GND) | |
| J5 `MIDI IN` | DIN pin 4 | DIN pin 5 | — (pin 2 stays unconnected by MIDI 1.0) | |
| J6 `RING` | +5V | +5V | GND | GND, RING_DATA, ENC_A, ENC_B, ENC_SW |
| J7 `LEDS` | +5V | IND_DATA | GND | |
| J8 `PWR BTN` | button | GND | | |
| J9 `PI PWR` | to the Pi 5's J2 button pad | GND | | (flying lead, not the 40-pin header) |
| J20 / J21 `CTRL` | tip (wiper / switch) | ring (3V3 via 1 kΩ) | sleeve (GND) | v3: pin 4 = TN, the NJ6FD-V's tip-normal contact (presence) |
| J10 … J19 | switch | GND | | one per pedal, REC … BANK |
| J22 `EXP` | +3V3 | +5V | GP19 (v2) / GP12 (v3) | v2: GP20, GP21, GP22, GP28, GND · v3 (2×3): GP15, GP28, GND |
| J23 `PD` (v3) | GND | SDA (GP0) | SCL (GP1) | I2C to the STUSB4500 trigger; no VDD wire |
| J2 `PI` (used pins) | 1, 17 = 3V3 | 6, 9, 14, 20, 25, 30, 34, 39 = GND | 8 = MIDI OUT (Pi TXD), 10 = MIDI IN (Pi RXD) | 24 = link RX (Pi GPIO8), 21 = link TX (Pi GPIO9), 18 = SWCLK, 22 = SWDIO |

---

## 6. Things the design says not to do

- Do not substitute 74HC125 or 74HCT125 for U1.
- Do not add a third wire to J5 or bond the MIDI IN shield anywhere on the board.
- Do not connect J2 pins 2/4 (Pi 5 V) to `+5V`; the two supplies must only share GND and 3V3.
- Do not fit 5 V pull-ups on the ring board's encoder lines; the pull-ups are R11–R13
  here, at 3V3, on purpose.
- Do not power the Pi through this board or this board through the Pi.
- Do not stuff caps or bleeders on H2–H4; only H1 is a chassis bond.

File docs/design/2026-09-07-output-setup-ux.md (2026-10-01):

# Output setup proposal

The owner accepted input setup and asked to continue to the next flow. Output
setup is the subsequent proposal, not yet accepted. It lives in Settings → Audio
routing → Output setup, with Output names in the header. The same header action
is available while choosing output routes.

## Controls

Main output (physical outputs 1–2) and Monitor output (3–4) are the two sample
stereo destinations. Each has independent level, balance, stereo/mono and mute.
Names are appliance aliases; renaming preserves routing and FX identity, and the
name appears in Routing, FX and expression destination labels. Save/Cancel and
the existing touch/encoder keyboard apply. Aliases survive session recall.

Level runs from silence to unity (0–100%) in this proposal. Mute does not change
the stored level; unmuting restores it. Balance favours Left or Right without
collapsing stereo. Mono proposes an attenuated L+R sum sent to both jacks; Balance
is disabled and shown centred. Returning to Stereo restores the prior balance.
The native mix law and real hardware channel inventory remain implementation work.

Level and balance use direct sliders, double tap for unity/centre, and encoder
press/turn/press with Back to cancel. Output mute is explicitly labelled and has
its own selected state. Output level and balance share the parameter values used
by expression and external-button value mappings. Output mute and format are not
yet offered by those mapping pickers.

Output setup applies to all signals routed to that destination, after its output
FX. It does not rewrite recordings, alter source routing, start/stop tracks or
change the independent live-input Mixer levels. Settings other than physical
aliases belong to the session and carry into New Loop.

## Performance capture boundary — proposal

Capture the performance mix after output FX but before final destination level,
balance/mono and mute, so adjusting the PA or monitor during a performance does
not alter or interrupt the saved performance. This tap point is a new proposal to
review, not a claim about the Looper X engine or a previously approved requirement.
The current silent prototype does not process audio at either tap.

## Verification and reference

`verify_output_setup.cjs` passes in Chrome and Firefox for independent controls,
mute without lost level, retained balance across Mono, touch resets, encoder
commit/cancel, shared output names, cold reload, session recall and atomic write
failures. All six browser layouts are checked. Input routing/setup, Mixer and
expression regression suites also pass. [Browser/native gallery](output-setup-previews/index.html).

The six matching Pen screens are saved and exported at full size. Native checks
cover 165 text nodes and 579 elements without alignment or containment errors.
The gallery manifest records the saved design hash and verification results.

Looper X's extracted `OutputSetup.qml` and `Output.qml` expose physical outputs
with their own level controls. Segno's named stereo destinations, explicit mute,
software mono output and capture boundary are design proposals for this product.
Meters are fixed review samples; no live audio metering, DSP or device validation
is implied by these browser or Pen checks.

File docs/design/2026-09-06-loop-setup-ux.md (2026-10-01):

# Loop setup interaction study

Design work under appliance roadmap issue 919. The owner tested the revised FX
journey, described it as intuitive, and requested continued UX work. This slice
extends the same submenu, touch and encoder patterns to recording setup. The
owner rejected generic form pages and asked for the personality of musical gear,
then cautioned that a full visual preview was too much for mode selection. It is
a browser simulation, not production engine integration or hardware validation.

[Open Loop settings](fx-ux-prototype.html?review=loop-settings).

## Design authority

The owner explicitly confirmed that these designs define the target product's
features, behavior and UX. Looper X is a reference, and the roadmap must follow
the reviewed target. Current Segno code establishes implementation gaps and
reusable work, not limits on what can be designed.

Earlier examples carried current engine restrictions into the prototype. The
MIDI fixed-length/count-in restrictions, blanket recording locks and content
lock on mode changes are not approved target rules merely because they appear
in the current code. Review each against the intended musical behavior and
define transition/recovery behavior before retaining a restriction. Earlier
references below describe the study's history; they do not override this decision.

For the next Playback & overdub slice, define per-track Loop/Once and decay in
all five modes. The existing Free/Song-only auto-stop and global feedback
coefficient are implementation gaps, not restrictions to copy into this UI.

| Entry | Current interactive scope |
|---|---|
| Loop mode | Multi, Sync, Song, Band and Free, with one sentence describing the track relationship |
| Recording | Record → Play → Overdub or Record → Overdub → Play; immediate/count-in start versus waiting for sound after arming |
| Tempo & click | Direct whole-BPM slider, tap tempo, time signature, click policy and count-in length |
| Length & quantize | New-recording defaults and per-track length/timing overrides in one editor |
| Playback & overdub | Per-track Loop/Once and 0–100% overdub decay, with independent default inheritance |
| Audio & tempo | Per-track tempo following and pitch preservation, with defaults and effective original-speed state |

The hub shows the current choice beside each submenu. Loop mode keeps five
choices with compact static diagrams; the cards are slightly narrower and
shorter while text stays at the shared size. The owner accepted the diagram
approach and requested that final size reduction.

Recording has two compact rows: how recording starts (Pedal or Sound), and what
the second pedal press does (Play or Overdub). The separate pedal simulator,
large pictogram cards and reset controls were rejected and removed.

Tempo, time signature, click behavior and count-in remain on one page. A tempo
area has priority, followed by aligned Hear click and Count-in rows. The owner
rejected competing panels and the proposed submenu split, clarifying that this
was a layout problem. Small beat lights respond to taps, not an audio clock.
The owner accepted Recording and timing as the provisional baseline before
moving on to loop length and quantization.

All pages use the shared 1920 × 1080 canvas, 56 px sliders, at least 64 px buttons,
24 px control labels and visible encoder focus. Display roles remain undecided.
The diagrams add no controls, playback simulation or encoder stops.

Tempo is edited directly. Encoder press starts an adjustment, turning changes it,
press commits, and Back/Escape restores the opening value. Double tap restores
the tempo prepared at the start of this demo. A pedal event cannot persist an
unfinished tempo draft. Touch and encoder use the same value. Naming and FX
editing remain in their own journeys.

The reference for structure is Looper X
[UX04–UX09](../research/sheeran-looper-x-1.0.2/ux-paths.md#ux04--record-a-first-loop)
and its [looping features](../research/sheeran-looper-x-1.0.2/features.md#f02--five-looping-modes).
The five mode descriptions are proposed product semantics based on that
reference; they are not a claim that all those modes work in Segno today.
The [mode-change contract](2026-09-07-loop-mode-transitions-ux.md) now supersedes
the earlier content lock. Compatible choices apply immediately while stopped;
playing loops require explicit Stop loops and switch. Actual track lengths
determine incompatible choices. No audio conversion is offered.

The recording choices correspond to `RecordOptionsCubit.recDub` and
`autoRecord`. Waiting for sound requires a Record press on an empty track;
it is not an always-listening recording trigger. The sensitivity threshold and
interaction with count-in/quantized execution are not represented as recovered
controls. This is a configuration study, not a live transport trace.

Tempo bounds (30–300 BPM), 17 time signatures and count-in choices (Off, 1, 2, 4
bars) follow `TempoCubit` in this checkout. This differs from the Looper X guide's
documented upper tempo bound. Click choices follow `ClickMode`: off, defining
first recording, any recording/overdub, or playing/recording. Output routing and
click gain remain separate from when the click sounds.

Lock examples are explicit fixtures:

- [Recording active](fx-ux-prototype.html?review=loop-recording-locked) disables recording behavior changes and explains why.
- [MIDI clock](fx-ux-prototype.html?review=loop-midi) owns tempo and disables count-in. An empty loop can still choose a time signature.
- Mode changes check actual recorded durations and require recording and queued
  actions to finish first. Existing audio alone does not lock all choices.

Configuration is stored separately from the FX objects inside the demo's browser
state. Review links reset their fixtures on reload. Loop-mode checks now share recorded parts, durations and playback state with the
main session. Older configuration-only examples remain illustrative fixtures.

## Remaining journeys

This is the first Loop settings slice, not the complete settings surface:

- Tempo-change transition and resource/quality failure paths, plus the wider loop-transform journey.
- Fractional tempo entry and precise tap/count-in interactions on the appliance.
- Pedal-menu customization, audio/MIDI connections, session creation and recall.

These need distinct controls and engine mapping. They are not folded into Audio
hardware setup or represented as working by this study.

## Verification

`verify_loop_journeys.cjs` checks configuration isolation, navigation, tempo
commit/cancellation/reset, signature selection, and disabled/reenabled controls.
It captures seventeen views and checks the shared canvas, aligned horizontal edges and minimum target sizes.
The FX regression suites separately cover adding, ordering, preset copying,
replacement, removal, scrolling and pedal/encoder behavior. Native Pen screenshots
are reviewed independently of browser captures. No audio was recorded or heard.

## Length and quantization: current proposal

The owner authorized this next slice after accepting the provisional Recording
and timing layout. [Open the fixed-length example](fx-ux-prototype.html?review=loop-length-fixed).
It adds one Loop settings submenu, **Length & quantize**, for defaults used by
new recordings. Existing recorded audio is not resized by editing these values.

- **Auto** lets the performer finish the take; **Bars** shows a direct 1–64 bar
  stepper. Touch minus/plus changes by one. Encoder press on the value begins an
  edit, turn adjusts it, press commits, and Back cancels. Returning from Auto to
  Bars remembers the last bar count within the study.
- **Record timing** uses one explicit choice: Immediately, Loop start, 1 bar,
  1/2 note, 1/4 note, 1/8 note or 1/16 note. The fractions mean note values, not
  fractions of the whole loop or signature-dependent beats. Its short sentence
  describes record/overdub requests; it does not claim that every pedal action
  uses that setting. The defining first recording follows Recording settings; its count-in or sound
  trigger remains separate from waiting for an existing musical grid.
- Fixed length stays independent of audible click in the proposed product.
  Its automatic end follows the selected Play/Overdub behavior. These are
  intentional engine changes, not claims about current native behavior.
- Recording locks these edits. The external-clock fixture keeps the recovered
  fixed-length restriction explicit while leaving quantization selectable.
  Clocked fixed length is not presented as a working capability in this slice.

The source inspection also confirmed that sound activation and count-in are
mutually exclusive. Choosing Sound now clears count-in; enabling a count-in
restores pedal start. The retained Recording page makes the effective start
behavior visible in its one contextual sentence.

### Implementation evidence and follow-through

| UI intent | Current code evidence | Required implementation work |
|---|---|---|
| Absolute bar count | `segno_engine_api.h` track length preset API supports Auto and 1–64 bars for the defining recording; global `default_multiple` uses whole base-loop multiples for other captures | Create one explicit ownership model for new-recording defaults, shared length in Multi, and per-track overrides; never label base-loop multiples as bars |
| Fixed length without audible click | Native preset × click matrix auto-finishes only with click enabled and a known tempo; click-off derives tempo from the take | Separate length scheduling from click audibility; define no-tempo, early finish, resource-capacity and mode-specific behavior before engine binding |
| Automatic Play/Overdub choice | Current fixed non-defining captures auto-finish into overdub independently of `rec_dub` | Make the chosen outcome consistent for manual and automatic finish, with native regression coverage |
| Immediately / loop start / musical grid | `QuantizeCubit` controls the arm gate; `TempoCubit.quantizeDiv` selects a division; `engine_process.c` consumes the live subdivision ratio | Map a single product setting atomically to gate and division, and clear obsolete alternative UI paths. Off must not accidentally mean a loop-start wait |
| Per-track timing | Native per-track override is a boolean; musical division is global | Implement optional per-track timing enums with field-level inheritance; the proposed UI allows divisions to differ per track, beyond the current boolean override |
| Sound / count-in | `le_engine_set_count_in` contract and record-arm path define exclusivity | Keep the two settings and published state consistent, including pending-arm cancellation |

The first version covered defaults. The per-track extension below uses the same
editor; neither is a transport simulator. Sync/Band primary-track constraints, Free mode behavior, content locks,
capacity failures and the first-loop versus later-track distinction still need
explicit integration. Native API comments include older phase notes; the live
subdivision consumer in `engine_process.c` was inspected rather than treating
those old comments as evidence that quantization is absent.

The initial browser checks covered twelve views, including Auto, fixed length,
recording-locked and MIDI-clock variants. They exercise the bar edit commit and
cancel paths, bounds, retained values, all seven timing choices, count-in/sound
exclusivity, and the proposed independence from audible click. These are author
checks of a UI simulation; they do not validate audio scheduling or hardware.

The owner tried the Length & quantize study, accepted it as okay, and asked to
continue. The owner then authorized per-track setup, followed by the Playback &
overdub slice below.

## Per-track length and timing

[Open the per-track example](fx-ux-prototype.html?review=loop-track-custom).
Defaults and all eight tracks use one canonical editor. The owner rejected nine
large navigation cards, accepted a compact selector, and requested more
horizontal padding with consistent alignment. The page now uses a 100 px inset
for its title, selector and both settings sections on the 1920 px canvas. The
selector uses a static Tracks label, then Defaults followed by eight numbered
64 px touch targets. The owner chose that order and removed the New recordings
label. The Defaults button aligns with the controls below in both selection
states; no negative margin or selection-background offset is needed. A named track shows
its full name to the right; each track control also has its complete accessible
name. Names exceeding the available line are truncated in the visual readout.

Each field displays its actual selected value, with **Default** or **Custom**
beside its label. Editing length only overrides length; timing continues to
follow its default. Selecting **Use default** removes that field's override, so
later default changes propagate again. A custom value equal to the current
default remains custom. Auto is an explicit value and can override a fixed
bar-count default.

Encoder edits preserve both the opening value and its ownership. Back cancels;
press commits. Switching tracks cancels an unfinished bar edit on the previous
track. A pedal-triggered browser save cannot accidentally commit that preview.
Committed overrides survive reloading the ordinary demo URL. Review links reset
their examples, as in the FX study.

In Multi, tracks show the shared default length and disable independent length
controls with **Shared in Multi** beside the label. Record timing can still be
customized. Independent-mode lengths remain stored but inactive while Multi is
selected; returning to an independent mode restores them. This is an empty-loop
configuration example, not permission to switch mode over existing audio.
Recording and MIDI restrictions retain their prior behavior. Track selection
remains available while edits are locked so the performer can inspect values.

The study now proposes per-track timing divisions, not just boolean quantization.
Production work must implement that ownership model, mode-specific scheduling,
capacity handling and session serialization before these controls are wired to
the engine. Stored new-recording lengths do not resize an existing take. Sync and
Band alignment constraints and their primary-track roles still require explicit
engine integration; the study does not claim to validate that audio behavior.

Additional checks exercise inherited-value propagation, matching explicit
values, independent Auto, per-field reset, target-switch cancellation, isolated
tracks, Multi shared length, recording/MIDI locks and persistence without drafts.
The five added views cover inherited, custom, shared-length, recording-locked
and MIDI-clock states. Chromium and Firefox are checked separately.

A later native text review corrected the Pen import itself across the 39-screen
study. Button labels had been moved to the top by an overbroad fitting rule.
The native copy now preserves browser line anchors, centering, weight and letter
spacing; it uses matching Arial metrics through Arimo. The accepted browser
layout and interactions were unchanged. See the
[native typography review](fx-ux-previews/pen-sizing/review.md#native-text-alignment-correction).

## Playback and overdub: target behavior

[Open the per-track example](fx-ux-prototype.html?review=loop-playback-custom).
The owner authorized this slice and clarified that the designs specify the
product we want. There is one **Playback & overdub** submenu, using the accepted
Tracks / Defaults / 1–8 selector, 100 px inset and direct filled slider.

- **Loop** repeats until stopped. **Once** plays to the track's end and stops
  that track. Both choices are available in all five modes. Enabling Once during
  a pass finishes that pass; it does not restart the track or its clock.
- Once ends an active overdub at that boundary as well. It does not stop other
  sounding tracks or the shared clock, change the selected Song section, or
  automatically launch another section. A subsequent launch from the automatic
  end starts at the beginning. A manual mid-pass stop follows the ordinary
  transport resume policy, which remains to be defined in the Stage journey.
  These are proposed target semantics; shared-clock/Sync/Band implementation
  must honor the explicit stop without automatically restarting that track.
- **Overdub decay** is 0–100%. Zero, shown as **Off**, keeps earlier audio at its
  previous level. Each overdub pass retains `1 - decay / 100` of existing audio
  before adding the new input. At 25%, the original audio retains 75%, 56.25%,
  42.1875% and 31.640625% after four passes. New input is not attenuated by decay
  on its first pass. At 100%, the new pass replaces the previous audio, including
  with silence. Normal playback does not cause further decay.
- Playback and decay inherit independently from Defaults. A matching explicit
  value remains Custom. **Use default** removes that field's override. Double
  tapping the decay slider restores inheritance on a track and resets decay to
  Off when editing Defaults. The persistent labels are Keep layers / Replace
  layers; the short sentence explains the effective amount.
- These controls remain available during playback, recording and overdubbing.
  Changing a setting does not stop transport. The production implementation
  needs smooth, predictable live updates. Recording-state changes cancel an
  unfinished encoder draft consistently with the existing prototype grammar.
- Encoder press edits decay, turning changes it by one percentage point, press
  commits, and Back cancels. Changing tracks cancels the former track's draft.
  Draft values are excluded from unrelated saves; committed settings survive
  reload at the ordinary prototype URL. Review URLs reset example data.

The extracted Looper X [one-shot/decay journey](../research/sheeran-looper-x-1.0.2/ux-paths.md#ux09--change-one-shot-decay-and-time-stretch)
provides the feature reference. The percentage direction and detailed rules
above specify Segno's target; they do not assert Looper X's exact DSP law.

| Target | Current implementation evidence | Work needed to fulfill the design |
|---|---|---|
| Independent Loop/Once in all five modes | `le_engine_set_one_shot` stores a per-track flag in every mode; `advance_track_clock_frame` only auto-stops Free/Song | Define per-track end boundaries and stop/relaunch behavior for the shared-clock modes; retain the setting through clear, save/restore and undo |
| Per-track decay, live controls, independent inheritance | `le_engine_set_overdub_feedback` takes one global coefficient and applies it only during overdub | Add per-track ownership and inherited defaults; map decay to feedback, preserve layered audio/undo and define smoothing, capture/replay and session recall |
| Target UI independent from current limitations | Earlier study fixtures copied MIDI/recording/mode locks from current code | Reconcile those fixtures against intended musical behavior; record justified product rules and implementation gaps separately |

`verify_loop_playback.cjs` passes in Chromium and Firefox. It exercises field
inheritance, explicit matching overrides, all five modes, live overdub edits,
slider endpoints, touch/encoder parity, cancellation, reset, scope changes,
draft-safe persistence, reload and FX isolation. It checks all eight tracks are
visible, aligned rows, 1920 × 1080 geometry and minimum touch targets. Existing
Loop checks pass in both browsers and the FX journey regression passes.
These are author-side UI checks, not audio or appliance validation.

## Audio and tempo: reviewed configuration

[Open Audio & tempo](fx-ux-prototype.html?review=loop-audio-tempo-pitch).
The owner reviewed this page, said it looked great, and redirected the next
slice to FX Pre/Post placement and output effects. The page uses the same
compact selector and 100 px inset. Follow tempo is Off/On. With following On,
Pitch is Unchanged/Follows speed. Each field independently inherits Defaults;
matching explicit choices stay Custom and Use default restores inheritance.
With following Off, Pitch becomes an Unchanged readout, not a disabled choice.
The saved pitch preference returns when following is reenabled. Resetting an
inherited field returns encoder focus to its effective choice. Defaults are
Follow tempo On and pitch Unchanged.

This adds no second tempo editor. Song BPM stays in Tempo & click. Choices apply
to the selected track's recorded material; live-input monitoring is unaffected.
The target permits configuration in all five modes and during playback/capture,
including opting out when the song follows MIDI clock. Source QML makes Looper X
following mandatory under MIDI receive; this is an intentional Segno departure.

The [official user guide, page 35](https://cdn.inmusicbrands.com/sheeran/looper-x/Sheeran%20Looper%20X%20-%20User%20Guide%20-%20v1.0.0.pdf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)
separates Sync Audio to Tempo from pitch-preserving Time Stretch and describes
half-speed to double-speed stretching. Segno's labels express the consequences.
The page models settings, not transformed audio or measured stretch quality.
At a recorded tempo of 84 BPM and song tempo of 100 BPM, following requests a
100/84 speed ratio. Preserving pitch keeps notes unchanged; following speed
couples pitch to that ratio. Following Off retains original playback speed and
pitch. It can consequently drift from the changing song grid.

Before audio integration, define phase-continuous switching, original-tempo
metadata and imported audio with unknown tempo, capture/overdub mapping into
original material, mode/shared-length interactions, resource/quality failures,
undo, session recall and performance replay. In particular, opting out must not
silently truncate audio to a newly shortened master grid. These unresolved
transport contracts are implementation planning work; the configuration choices
are not proof that those audio paths exist today. The current public engine API
inspection did not identify a binding for this target; the roadmap's stretching
slice and measured appliance work remain required.

`verify_loop_audio_tempo.cjs` passes in Chromium and Firefox for per-field
inheritance, retained versus effective pitch, all five modes, MIDI opt-out,
live overdub edits, touch/encoder selection, focus recovery, reload, the existing
tempo-editor return path and FX isolation. The Loop and Playback regression
checks also pass in Chromium. Minimum targets, aligned controls, all eight
tracks and the shared 1920 × 1080 geometry were checked. Browser and native Pen
review remain separate from acoustic and physical display validation.

Additional reference clarification: Looper X labels decay as Feedback, with
100% keeping old audio intact. Segno's reviewed Decay label runs in the opposite
direction: Off/0% keeps it intact, and increasing decay removes more per pass.

## Pedals: owner-directed revision

The owner rejected the first per-track Press/Hold form and state preview and
requested an approach closer to Looper X. That prototype module and its test
were removed, and its four Pen frames were replaced. It is not an accepted
per-track customization requirement.

The replacement separates shared pedal behavior from custom-mode assignment:

- **Pedals:** Hold Record / Play (Undo recording or Peel layer), Hold track pedal
  (Arm overdub or Clear track), Mode pedal (Mute, Tuner, FX or Custom), entry to
  Customize, and whether new loops keep or reset custom assignments.
- **Custom pedals:** select the function on a pedal to open a compact chooser.
  Changes remain a draft until Save. Cancel and Back discard that draft; closing
  a chooser returns to its pedal. Clear assignments affects the draft across
  both banks and is recoverable through Cancel. Editing a custom layout does
  not change the selected Mode function. MODE remains Exit in Custom mode.
- The Record/Play sequence stays on the existing Recording page. There is no
  second independent sequence setting or duplicate per-track defaults editor.

### The physical layout is Segno's

Looper X is the interaction reference, not the physical layout. The owner
explicitly corrected this distinction. The verified faceplate has ten pedals:

| Rear pair | Position |
|---|---|
| Clear | Above Undo |
| Bank | Above Mode |

Front row, from the player's left: **Record/Play, Stop, Undo, Mode, Track 1,
Track 2, Track 3, Track 4**. All ten appear in the editor. MODE is a fixed,
non-editable Exit tile, excluded from encoder focus. BANK changes the displayed
bank on its own tile. The four transport assignments are shared between banks;
the four physical track pedals have separate A/B custom assignments. Physical
track labels remain 1–4 in either bank. This is ten physical pedals, not ten
independent editable function slots.

Evidence: `hardware/enclosure/segno_enclosure.py`, `_ROW1` and `PEDALS`, and
`hardware/segno_enclosure_design.md`, section 2. The faceplate PDF was also
rendered and inspected. The screen retains the actual relative positions;
it is not a manufacturing scale drawing. Neither CAD nor firmware was changed.
Physical display roles remain open despite older hardware documentation naming
roles for them.

### Hold targeting: explicit owner decision

The owner chose **follow the newly selected track**. Until the hold action
fires, a change of selection changes its target. Resolve the track identity at
execution time. After the hold action fires, further selection changes and
release must not fire it again. A bank change that does not change the selected
track does not invent a new target. The old proposal to freeze the original
track was superseded. The hold action itself must not silently change mid-gesture
because setup was edited. Disconnect cancels a pending gesture.

This is a target interaction contract. The configuration prototype does not
execute pedal gestures or audio, and does not claim that the production resolver
implements it. Thresholds, pending-hold feedback, press/hold arbitration,
quantized actions and current-track selection need end-to-end hardware tests.
Arm overdub requires a stopped track with audio. Clear and Peel require explicit
undo/recovery behavior in the implementation; a choice label alone does not
implement that history.

### Reference and verification

Official Looper X guide pages 36–37 show shared hold settings and a custom pedal
menu with an anchored assignment picker, Save, Cancel, Clear, and fixed Exit.
Unmodified embedded screenshots are saved in the reference atlas as
`global-general-official-guide.jpg`, `loop-customize-pedal-official-guide.jpg`,
and `custom-pedal-menu-official-guide.png`, with provenance sidecars. The guide
is version 1.0.0; the extracted QML independently corroborates the interaction,
not every native option or gesture transition.

`verify_pedal_setup.cjs` passes in Chrome and Firefox for setting selection,
encoder focus, all ten positions, fixed Mode, bank isolation, shared transport
slots, Save/Cancel/Clear, persistence, and draft preservation during unrelated
FX/capture events. Chooser entries cover the Looper X function families plus
Segno transport actions; they are assignment definitions, not proof that every
function is implemented. No audio, physical controller, or session-creation
lifecycle is exercised by this browser study.

Historical routes `loop-pedals`, `loop-pedals-custom`, `loop-pedal-actions` and
`loop-pedal-hold` are superseded. The accepted A layout now lives in Settings →
Pedals in the main prototype (`pedal-setup`). Loop settings has six destinations.

### Performance behavior requires its own definition

The owner identified that assigning function names does not define their
behavior. A function entered with a footswitch must be fully operable and
escapable by foot; opening a screen that then requires touch is insufficient.
The label Exit is accepted for returning to normal track controls. See the
[pedal performance contracts](2026-09-06-pedal-performance-contracts.md) for
the owner decisions, initial Transpose/FX proposals and remaining catalogue.
The existing setup prototype is not proof that those performance journeys exist.

The owner subsequently required independent Press and Hold function assignments
on a footswitch, such as entering FX on press and Custom on hold. The revised
prototype now exposes both Mode entries and both gestures on each editable
custom pedal, using the same physical layout. This replaces the single-action
assignment model; the rejected per-track form is not reinstated. Mode is still
Exit within the custom context and Bank switches its four track-pedal pairs.
See the performance contract for the verified configuration journey and the
still-open runtime arbitration, context and transport timing decisions.

The later `loop-mode-hold` and `loop-pedals-bank-b` study routes are also
superseded by the accepted Pedals layout. Earlier Pen frames are marked
superseded. The accepted setup keeps the physical map visible while editing a
pedal's Press and Hold, with shared track actions and explicit fixed controls.
See the [locked pedal decision](../brainstorm/2026-09-06-pedal-setup-layout-brainstorm-doc.md)
for current routes, persistence and verification.

### Native capacity refusal (October 1 implementation refinement)

Choosing Bars reveals its count even if the engine cannot accept that length.
The rejected count remains editable, with a short note identifying the length
that is still active. Further minus/plus or encoder edits can reach a supported
count; refusal never changes the confirmed setting, default inheritance or saved
preferences. Only accepted counts replace each scope's remembered bar value.
Auto, leaving the page, changing scope/session or starting capture discards the
unapplied candidate. The saved Pen reference includes this refusal state.

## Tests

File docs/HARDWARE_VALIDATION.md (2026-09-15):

# Hardware validation checklist

The on-device checks that **cannot run in CI or headless** — they need a real
audio interface, the console's pedal board, or a second display in front of you. Every
software gate around these is already green (native tests, fuzzer, per-OS builds,
plugin CTests); this is the remaining physical bench work. Check items off as you
confirm them.

> Context: these were tracked across `docs/PROGRESS.md` ("On-hardware validations
> still open") and the pedal/LED memory. Collected here so there's one list.

## 1. Round-trip latency gate (Phase-1 acceptance: ≤ 10 ms)
- [ ] Plug in a class-compliant interface + a loopback path (a physical cable
      out→in, or a virtual device like BlackHole/VB-Cable).
- [ ] Run the app; trigger the loopback latency auto-measure in audio setup.
- [ ] **Pass:** measured round-trip ≤ 10 ms at a sane buffer (e.g. 128 frames).
- [ ] Confirm the **latency-compensated** overdub lands tight (record over a click,
      listen for flam) and that undo/redo clicks are acceptably small.

## 2. ASIO full-count interface (Windows)
- [ ] Plug in a multi-channel interface (e.g. Focusrite Scarlett/Clarett) on
      Windows; select the ASIO backend + its driver in audio setup.
- [ ] **Pass:** all input/output channels enumerate at the interface's real count
      (e.g. 18 in / 20 out) — not the WASAPI-limited pair.
- [ ] Record/monitor/route across several channels; confirm the WASAPI↔ASIO device
      match and the loopback-exclusion (a "Loopback" input is hidden).
- [ ] Confirm the exclusive-mode / fallback status row reflects reality.

## 3. Secondary-window waveform visualizer (2nd display)
- [ ] With a second display attached, open the waveform window (the toggle in Big
      Picture settings / the `desktop_multi_window` sub-window).
- [ ] **Pass:** the whole-loop output waveform renders with a moving playhead bar
      and tracks the audio; it survives a device reconnect.

---

When an item passes, tick it and (optionally) note the interface/OS used. If one
fails, capture the symptom — those become software bugs to file, since the code
paths themselves are unit-/integration-covered but never hardware-exercised.

## Results — 2026-07-13 (first bench pass)
- **#2 ASIO full-count: ✅ PASS** — 18 in / 20 out on a Clarett OctoPre+ (Windows).
  Validates the whole multichannel/ASIO effort (previously build-verified only).
- **#1 latency: ⚠️ 15.15 ms** — over the 10 ms gate, but it's the *monitoring*
  path (recording stays tight via latency compensation) and buffer-dependent.
  Re-measure at 128 frames; if still >10 ms it's the interface floor and the gate
  should be revised to ≤16 ms. Not a correctness bug.
- **#3 waveform window: ⚠️ works, but should go full-screen on the 2nd monitor.**
  Addressed — the output window now detects a secondary display, moves onto it,
  and fullscreens (windowed fallback when there's one screen). Needs a re-check
  on the 2-monitor bench.

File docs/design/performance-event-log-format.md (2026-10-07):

# Performance event log format

<!-- cspell:ignore numer retime retimed retiming RETIME -->

Part 3 of the performance-recording / DAW-export umbrella
(`docs/plan/2026-07-05-feat-performance-recording-daw-export-plan.md`). This
pins the on-disk format for `events.log`, the sample-accurate record of every
audibility-affecting change made during an armed performance-recording
session — the backbone the offline renderer (parts 7-8) and the `.als`
generator (parts 9-10) build on. It is written so a reader can parse the file
without importing engine code.

## Where it lives

`events.log` sits alongside the audio parts (`master-NNN.wav`,
`input-<N>-NNN.wav`; `master.pcm` and `input-<N>.pcm` before #1198) and
`performance.json` under the capture directory passed to `le_perf_arm`
(`packages/segno_engine/src/core/perf_drain.c`). It is opened once at arm,
appended to every ~250ms drain cycle, and never truncated or rewritten —
unlike `performance.json`, which is atomically replaced each cycle.

## File layout

```
[header: 12 bytes]
[entry 0: 28 bytes]
[entry 1: 28 bytes]
...
```

### Header (12 bytes, written once)

| Offset | Size | Field | Notes |
|---|---|---|---|
| 0 | 4 | magic | ASCII `"PLEV"` (Perf Log EVents) |
| 4 | 4 | version | `uint32`, little/native-endian; `12` today — see below |
| 8 | 4 | sample_rate | `int32`, the session's sample rate |

#### What `version` means

The version covers the **code vocabulary** as well as the record layout, so it
moves whenever a reader's interpretation of an existing code changes — not only
when the 28-byte record does.

| Version | Meaning |
|---|---|
| `1` | The original vocabulary. An **aborted** take — armed, then stopped having captured nothing — was logged as `LE_PLOG_RECORD_END`, so a version-1 capture is subject to #264: a reader that anchors on the first `RECORD_END` can place a track's settled image at the abort frame instead of at the finalize that produced it. |
| `2` | An aborted take logs `LE_PLOG_RECORD_ABORT` (314). A `RECORD_END` in a version-2 file always means content was captured. |
| `3` | A `RECORD_ABORT` may appear **unpaired**: a count-in cancelled by the immediate-finalize primitive (#405, `LE_CMD_FINALIZE_TAKE`) logs 314 for the counting channel even though no `RECORD_START` ever preceded it (the count-in's commit is what logs the start). In a version-2 file every 314 closes an open `START`; from 3 on, a reader must treat an ABORT with no open `START` as a no-op, not a malformed file. |
| `4` | Two new transport facts (#262) — `LE_PLOG_PERF_ARMED` (315) recording the master loop phase at arm, and `LE_PLOG_TRANSPORT_HELD` (316) marking a mid-capture transport hold — and `LE_PLOG_RECORD_END` (301) now carries the `take` arm `{channel, take_id}` instead of a bare channel (#819). The offline renderer **requires** these: the two inferences it used before — the race-stale `armSnapshot.clockFrame` phase anchor and the "first `RECORD_END` while the channel is content-free" disarm-image proxy — were **deleted with no fallback** (AGENTS.md). A pre-4 file has neither fact, so it has no supported phase anchor and no take identity; it still parses (below), but renders correctly only if re-captured. |
| `5` | Applied Clear restoration (322) and restored source state, phase and retirement (323), with exact capture-local image identity. |
| `6` | Every callback-applied history image logs 322 (#1143): Clear Undo, layer Undo and Redo, and recovery from empty each stage an immutable image at admission and the callback names it at the exact frame it first mixes the slot, so a channel may carry several 322 facts per capture and a reader switches images on each (in version 5 a channel carried at most one, for Clear Undo). 323 keeps its meaning; `image_id` 0 with state EMPTY now also follows any slot that became live without a staged image (staging refused, loop-close restoration, session import), whatever the previous source was. `LE_CMD_UNDO_TO_EMPTY` (39) is logged raw at its exact apply frame next to the semantic 304: emptying is exact silence, not lost provenance. `LE_PLOG_LAYER_RETIRED`'s fourth payload field (`frames`) is reserved for the staging-gap follow-up under this same version; until it lands the writer does not define those four bytes and a reader must not interpret them. |
| `7` | Reverse (#1162): `LE_PLOG_REVERSE` (324) carries a track's read direction as a callback fact — every accepted toggle or install logs the exact dry index the callback continues from and the equal-gain turn window it mixes the old head over; every material reset (Clear, Undo to empty, a new capture, import) logs forward with `read_index` -1; a track already reversed at `PERF_ARM` logs its direction and index at capture frame 0. The offline renderer steps a reversed segment's phase -1 per frame from the logged index and reproduces the turn; a version-6 reader has no direction and renders a reversed track forward. Peel (#1164): `LE_PLOG_PEEL` (325) is a control-side admission record for each accepted peel; the callback's 322 names the staged image it mixes. A version-7 file may contain either fact or both; a reader that does not consume them skips them as unknown codes. |
| `8` | Speed (#1179): `LE_PLOG_SPEED` (327) carries a track's read rate as a callback fact, with the exact index the callback reads in Q32.32 — every accepted change of the global Speed logs one per track (an equal request is receipt-only and logs nothing), and a track not at 1x at `PERF_ARM` logs its rate and index at capture frame 0. The offline renderer steps a segment's index by the rate and reads it as the callback does (interpolated off whole samples, a box of `floor(rate)` samples in the head's direction at 2x and up); a 324 or a 322/323 phase that logs an integral index keeps the renderer's own exact fraction when the integral parts agree. A version-7 reader has no rate and renders a track at 1x. |
| `9` | Transpose (#1179 Part 3a): `LE_PLOG_TRANSPOSE` (328) carries what a track SOUNDS — its stored and its sounding pitch — at every change of the sounding one (the cache worker's render engaged, a dry fallback, bypass), with the exact index in Q32.32 and the equal-power window the old source is mixed out over, and at `PERF_ARM` for a track sounding transposed. The offline renderer renders the image through the same function, preset, seed and loop fold as the cache worker and reads it through the head from the logged index. A version-8 reader has no pitch and renders a transposed track dry. |
| `10` | Length edits (#1168): `LE_PLOG_LENGTH` (326) logs each applied Double, First half or Last half, and each Undo or Redo of one, with the slot now live, its length and the staged image id the callback's 322 names at the same frame. The renderer does not replay it yet (#1143); a reader that does not consume it skips it as an unknown code. |
| `11` | Audio & tempo follow (#1179 Part 4a): `LE_PLOG_HEAD_SPAN` (329) names the span a track's take plays over when a song-tempo change retimed the shared clock (0 = its own length), so the head's rate is speed x take length / span, with the exact index in Q32.32 and the window still mixing; `LE_PLOG_RETIME` (330) carries the new song tempo and the master length and position the clock continues from. The renderer derives the rate from the last 327 and 329 and re-anchors on 330 for a later RECORD_END's phase. A version-9 reader plays a retimed take at its own speed. |
| `12` | Pitch across a retime (#1179 Part 4a-ii): `LE_PLOG_SOURCE_LEN` (331) names the length of the render a track sounds, just before every 328: a stretch render (Pitch Unchanged, the take time-stretched to the span it plays over, within 0.5 %) is read with its index mapped by its length over the take's. The renderer renders the image to that length through the same loop render and reads it mapped. A version-11 reader plays the dry take through the varispeed head (the pitch off by the tempo ratio). |

Neither reader in this repo (`perf_render.c`'s `le_pr_load_log`, the Dart
`EventLogReader`) gates on the field — both check the magic and skip these four
bytes — and that is deliberate: a capture already on disk still parses rather
than being refused, and the version-4 facts are simply absent (not misread) in
an older file. The field exists so a reader *can* tell the vocabularies apart,
because the absence of a code in a file is otherwise indistinguishable from a
writer that never knew about it.

### Entry (28 bytes each, one per logged event)

| Offset | Size | Field | Notes |
|---|---|---|---|
| 0 | 8 | frame | `uint64`, frames elapsed since arm (same epoch as `performance.json`'s `capture_frames` and the PCM files) |
| 8 | 4 | code | `int32`, one of the codes in the table below |
| 12 | 16 | payload | raw union bytes; interpretation keyed on `code`, see below |

Every field is written via explicit fixed-width `fwrite` calls
(`perf_drain.c`'s `le_pd_write_events_header` / `le_pd_write_log_entry`)
rather than one `fwrite` of `sizeof(le_perf_log_entry)` — that in-memory
struct is actually 32 bytes (its `uint64_t frame` gives it 8-byte alignment,
padding 4 trailing bytes onto the 28 bytes of real content), so a naive dump
would write 4 bytes of uninitialised garbage per entry. Writing exactly 28
bytes across three `memcpy`s sidesteps that trailing pad; a portable reader
only needs to know the two fixed record sizes above.

### Two independent streams, not one global timeline

Every entry is produced by one of two single-producer rings:

- **`log_ring`** (audio thread producer): the audited `LE_CMD_*` commands
  below, plus the four transport facts, tagged at the exact frame they were
  applied.
- **`log_ctrl_ring`** (control thread producer): the handful of direct-atomic
  setters that bypass the command ring entirely (FX/monitor params, the
  limiter, overdub feedback) plus the common in-track undo/redo swap, tagged
  with a snapshot of the elapsed-frame counter at the moment the setter ran
  (accurate within one buffer).

Each drain cycle appends `log_ring`'s backlog, then `log_ctrl_ring`'s. Within
a single stream, `frame` is monotonically non-decreasing. **Across the two
streams, entries are not globally frame-sorted** — a control-side param
change and an audio-thread command from the same ~250ms interval can appear
in either order in the file. A reader that needs one merged, time-ordered
timeline must sort all entries by `frame` before use (a stable sort keeps
same-frame entries in file order, which is the best tie-break available
without finer-grained timestamps). Splitting into two rings by producer
thread is what keeps each one single-producer/single-consumer with no new
synchronization primitive — see `perf_log_ring.h`.

## The audited command table

Every `LE_CMD_*` the audio thread applies (`engine_process.c`'s
`apply_command`) was audited for whether it affects audibility. The logged
subset reuses `le_command`'s own code and union arm verbatim — the `payload`
bytes are that command's union, unchanged, so a reader already familiar with
`segno_engine_api.h`'s command-arm documentation can interpret them directly.

| Code (from `segno_engine_api.h`) | Value | Arm | Logged? | Why |
|---|---|---|---|-----|
| `LE_CMD_MEASURE_LATENCY` | 1 | — | No | Device-calibration workflow, not a performance action |
| `LE_CMD_RECORD` | 2 | generic | Yes | Explicitly required (record/play/stop) |
| `LE_CMD_STOP` | 3 | generic | Yes | ” |
| `LE_CMD_PLAY` | 4 | generic | Yes | ” |
| `LE_CMD_CLEAR` | 5 | generic | Yes | Erases a track: audible |
| `LE_CMD_UNDO` | 6 | — | No* | Never posted to the ring (control-thread swap) — see `LE_PLOG_UNDO` below |
| `LE_CMD_SET_VOLUME` | 7 | generic | Yes | Track volume |
| `LE_CMD_SET_MUTE` | 8 | generic | Yes | Track mute |
| `LE_CMD_SET_RECORD_OFFSET` | 13 | generic | No | Calibration/config value, not changed mid-performance |
| `LE_CMD_SET_INPUT_MASK` | 14 | trackmask | Yes | Track record-source routing |
| `LE_CMD_SET_OUTPUT_MASK` | 15 | trackmask | Yes | Track playback routing |
| `LE_CMD_ARM` | 16 | — | No | Scheduling intent only — the eventual fire is `LE_PLOG_RECORD_START` |
| `LE_CMD_DISARM` | 17 | — | No | Cancels an intent that was never logged |
| `LE_CMD_SET_LANE_FX` | 20 | fx | Yes | FX type change |
| `LE_CMD_SET_LANE_FX_COUNT` | 21 | fxcount | Yes | FX chain length |
| `LE_CMD_COMMIT_SESSION` | 23 | — | No* | Logged as `LE_PLOG_LOOP_LENGTH_LOCKED` (the semantic fact, not a raw copy) |
| `LE_CMD_SET_LANE_INPUT` | 26 | lanei | Yes | Lane record-source routing |
| `LE_CMD_SET_LANE_OUTPUT` | 27 | lanei | Yes | Lane playback routing |
| `LE_CMD_SET_LANE_VOLUME` | 28 | lanef | Yes | Lane volume |
| `LE_CMD_SET_LANE_MUTE` | 29 | lanef | Yes | Lane mute |
| `LE_CMD_SET_MONITOR_INPUT` | 30 | generic | Yes | Monitor enable |
| `LE_CMD_SET_MONITOR_INPUT_FX` | 31 | fx | Yes | Monitor FX type change |
| `LE_CMD_SET_MONITOR_INPUT_FX_COUNT` | 32 | fxcount | Yes | Monitor FX chain length |
| `LE_CMD_SET_MONITOR_INPUT_OUTPUT` | 33 | trackmask | Yes | Monitor playback routing |
| `LE_CMD_SET_MONITOR_INPUT_VOLUME` | 34 | generic | Yes | Monitor volume |
| `LE_CMD_SET_MONITOR_INPUT_MUTE` | 35 | generic | Yes | Monitor mute |
| `LE_CMD_SET_MASTER_GAIN` | 36 | generic | Yes | Explicitly required |
| `LE_CMD_SET_OUTPUT_ENABLED` | 37 | generic | Yes | Structural output gate |
| `LE_CMD_DUB_SHADOW` | 38 | — | No | Internal shadow-pool bookkeeping, not itself an audible change |
| `LE_CMD_UNDO_TO_EMPTY` | 39 | generic | Yes | From version 6 (#1143): logged raw at its exact apply frame (`arg_i` = channel), in addition to the semantic `LE_PLOG_UNDO`, following the raw-command-plus-transport-fact convention below. The offline renderer appends silence from this frame, as it does for `LE_CMD_CLEAR`. Also logged for the cancelled take of `LE_CMD_CANCEL_TAKE`, which empties the track through the same body |
| `LE_CMD_REDO_FROM_EMPTY` | 40 | — | No* | Logged as `LE_PLOG_REDO` (the from-EMPTY edge case) |
| `LE_CMD_PERF_ARM` / `LE_CMD_PERF_DISARM` | 41/42 | — | No | Meta — arming/disarming the session isn't part of what it captures |
| `LE_CMD_SET_ONE_SHOT` | 47 | — | No | The setter changes no output at the moment it applies. Its audible consequence — the auto-stop at the track's own loop wrap (Free/Song, `advance_track_clock_frame`) — logs a **synthetic `LE_CMD_STOP`** (`arg_i` = channel) at the exact wrap frame (#420), so a replay stops the track where a listener heard it stop. No `LE_PLOG_RECORD_END` accompanies a wrap mid-overdub, matching a manual Stop on an OVERDUBBING track — `RECORD_END` means "left RECORDING", and the dub pass's end is logged by its `LE_PLOG_LAYER_RETIRED`. |
| `LE_CMD_SET_TRACK_FX` | 49 | fx | No | No replay — manifest-only; stems stay per-stage dry-of-downstream (part 9), arm manifest carries track/master chains (part 3) |
| `LE_CMD_SET_TRACK_FX_COUNT` | 50 | fxcount | No | ” (same manifest-only verdict) |
| 51, 52 — *retired* | 51/52 | — | — | The Master insert family; slice 3b made the Master insert output bus 0's chain, so these were deleted and the codes left unallocated |
| `LE_CMD_FINALIZE_TAKE` | 56 | — | No | The `ARM`/`DISARM` rationale from the other side: finalize *intent*, and the transport fact it causes is what's logged — `LE_PLOG_RECORD_END` from the finalize it triggers, or `LE_PLOG_RECORD_ABORT` (unpaired, header version 3) when it cancels a count-in. A refused/no-op apply logs nothing: nothing audible happened. |
| `LE_CMD_RESTORE_TEMPO` | 58 | generic | No | Restores the tempo/grid owner; no direct change to the recorded sample stream |
| `LE_CMD_SET_ONE_SHOT_MASK` | 59 | generic | No | Sets Once for a complete track mask; the actual end logs the same synthetic Stop as single-track Once |
| `LE_CMD_SET_AUTO_RECORD` | 60 | generic | No | Selects sound-triggered start and cancels incompatible count-in; the actual capture start remains a transport fact |
| `LE_CMD_SET_LENGTH_PRESETS` | 61 | presets | No | Atomic future length settings; subsequent capture facts describe the result |
| `LE_CMD_SET_LANE_PAN` | 62 | lanef | Yes | Lane pan (slice 3): the lane's recorded image plus the track's pan, as the engine holds it |
| `LE_CMD_SET_TRACK_SOLO` | 63 | generic | Yes | Track solo: an audibility gate, like mute — the offline render and the DAW export honour it |
| `LE_CMD_SET_MONITOR_INPUT_PAN` | 64 | lanef | Yes | Monitor pan (slice 3); the monitor tap is already post-pan, so the logged value is what was heard |
| `LE_CMD_SET_OUTPUT_LEVEL` | 67 | lanef | Yes | Output destination level (slice 3b). The capture tap is BEFORE it by default, so it changes nothing a default take contains; a Follow output take is captured after it, and `le_pr_render_master` replays it (filtered on the take's captured destination) so the render matches |
| `LE_CMD_SET_OUTPUT_MUTE` | 68 | lanef | Yes | Output destination mute — same rule as 67 |
| `LE_CMD_SET_OUTPUT_MONO` | 69 | lanef | Yes | Output destination Stereo/Mono. Hardware output format; excluded from the performance capture policies |
| `LE_CMD_SET_OUTPUT_BALANCE` | 70 | lanef | Yes | Output destination balance — same as 69 |
| `LE_CMD_SET_OUTPUT_FX` | 71 | fx | Yes | Captured destination output-chain entry type; replay filters on the frozen destination |
| `LE_CMD_SET_OUTPUT_FX_COUNT` | 72 | fxcount | Yes | Captured destination output-chain length |
| `LE_CMD_CUT_SOUND` | 73 | — | Yes | Stop recorded sources and clear existing effect tails and the current click pulse. Every stopped track also logs a synthetic `LE_CMD_STOP`. Replay handles Cut itself to clear delay memory and keep sources silent until explicit Play or a new recording start; a finalizing `RECORD_END` does not restart them. Live monitoring and future click preferences remain unchanged |

Atomic mix transactions (`LE_CMD_SET_MIX`, 65) are not stored as raw
commands in this format: their bounded payload exceeds the sixteen-byte event
payload. Successful application emits the addressed volume, pan, Solo and output-control
primitive events at the same frame. Refused transactions emit none of them.
The recording-image wrapper (`LE_CMD_RECORD_IMAGE`, 66) likewise uses existing
recording transport facts and applied lane-image events rather than serializing
its larger command payload. The checked per-track requests with a callback
receipt — `LE_CMD_FADE` (81), `LE_CMD_RESET_TRANSFORMS` (82),
`LE_CMD_REVERSE` (83), `LE_CMD_SET_LENGTH` (84), `LE_CMD_SET_SPEED` (85), `LE_CMD_TRANSPOSE` (86) and
`LE_CMD_TRANSPOSE_BYPASS` (87) — are not stored raw either
(`le_log_extract` refuses them): a refused request changed nothing, and an
accepted one logs the primitive fact the callback applied (`LE_PLOG_FADE` 321,
`LE_PLOG_REVERSE` 324, `LE_PLOG_SPEED` 327, `LE_PLOG_TRANSPOSE` 328, `LE_PLOG_LENGTH` 326). The
Follow tempo setting, `LE_CMD_SET_FOLLOW_TEMPO` (120), is refused the same
way and logs `LE_PLOG_HEAD_SPAN` 329 for every track whose span it moves; a
retiming tempo change logs `LE_PLOG_RETIME` 330. The Pitch setting, `LE_CMD_SET_PITCH_MODE` (121), is
refused raw too; what it changes reaches the log as the 331 and 328 of the
swap it causes. Input capture trim is already present in captured
PCM and is not applied a second time by replay.

The tuner's commands are not logged at all: `LE_CMD_SET_TUNER_INPUT` (53)
changes no output, and `LE_CMD_SET_TUNER_MUTE` (132, #1229) silences the
live monitors of the inputs being tuned without touching any recorded
material. A captured monitor stem already holds that silence, exactly as
heard, through the same path a monitor mute takes, so replay has nothing to
apply.

Recording images retain source balance and position separately from live
lane level and track pan. The volume/pan events contain their effective
composition at application time, so replay does not apply the image twice.
Arming freezes the source image, not the player's live fader controls.

Track FX parameter/enabled state remains in the arm manifest. Output FX
changes are logged separately: the selected chain is seeded at actual arm,
then output type/count and parameter/enabled events update its reconstruction.
Each output event is filtered by the take's frozen destination. Already captured
master PCM is not sent through that reconstruction a second time.

\* Logged under a different, semantically unified code — see below.

A command that changes output but isn't in this table is a standing
review-checklist item for every future part that touches `apply_command`
(umbrella-plan note).
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

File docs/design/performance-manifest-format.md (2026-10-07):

# Performance manifest format (`performance.json`)

Part 6 of the performance-recording / DAW-export umbrella
(`docs/plan/2026-07-05-feat-performance-recording-daw-export-plan.md`). This
pins the schema of `performance.json`, the sidecar manifest that is the
**canonical machine-readable record** of a performance capture — the input
`daw_export` (parts 9-10) and the offline renderer (parts 7-8) build fixtures
and read logic against. It is written so a reader can parse the file without
importing engine or Dart code — every field is plain JSON.

## Where it lives

`performance.json` sits at the root of a capture's bundle directory
(`{documents}/exports/perf-YYYYMMDD-HHMMSS/`, D-NAME) alongside `events.log`
(`docs/design/performance-event-log-format.md`), the master and input audio
parts (see "Audio parts" below), and `loops/`. Unlike `events.log`, it is **atomically replaced**,
not appended to: `perf_drain.c` rewrites it in full every ~250ms while armed,
and `performance_repository` (`packages/performance_repository`) rewrites it
once more at finalize (normal disarm, or crash recovery) to fold in the
fields below `finalized: true`.

## Two authors, one file

| Phase | Author | Fields written |
|---|---|---|
| While armed (~250ms cadence) | `perf_drain.c` (native) | `slug`, `sample_rate`, `channel_layout`, `capture_frames`, `overrun_count`, `overrun_gaps`, `layers`, `take_id`, `encoding`, `volume_generation`, `ring_seconds`, `overs`, `parts`, `stopped_early?`, `finalized: false` (always) |
| At finalize (disarm, or crash recovery) | `performance_repository` (Dart) | `armSnapshot`, `disarmSnapshot?`, `finalized: true` — every native field above is preserved verbatim, never re-derived |

A reader only ever needs to parse the file **once it is finalized**
(`finalized: true`) to see the complete picture; a capture found with
`finalized` absent or `false` is either still in progress or is exactly what
`PerformanceRepository.findUnfinalized` flags for crash recovery (D-SALVAGE).

## Salvage sibling files (`.boot-recovery`, `.recovered-at`)

Boot-time crash salvage (D-SALVAGE, silent since #679) leaves two tiny
sibling files beside `performance.json` at different points of a bundle's
life. They exist because `finalized` alone cannot carry the whole salvage
story: a finished take the user kept and a salvage output stranded mid-move
are **byte-identical by sidecar**, and filesystem mtimes are too fragile to
hang provenance on (copies and moves rewrite them; an RTC-less
console boots near the epoch until its first NTP sync).

| File | Format | Written by | Removed by |
|---|---|---|---|
| `.boot-recovery` | empty file (its presence is the datum) | `PerformanceRepository.runBootRecovery`, immediately before a bundle's salvage begins | the move into `recovered/` completing — its deletion is what declares the salvage done |
| `.recovered-at` | epoch milliseconds, UTF-8 text, nothing else | the same move, stamped on the **source** bundle strictly before the rename, so the rename carries it atomically | never — it stays with the bundle as the record of when it arrived under `recovered/` |

What a standalone tool should conclude from each combination:

| Observation | Meaning |
|---|---|
| `finalized` `false`/absent (exports root) | still armed, or crashed while armed — the salvage candidate `findUnfinalized` flags; `.boot-recovery` may also be present from an earlier attempt that could not finalize |
| `finalized: true` + `.boot-recovery` (exports root) | **stranded salvage output**: finalize completed but the move to `recovered/` did not (a crash in that window, or a stem-render timeout); the next boot re-attempts the render and finishes the move |
| `finalized: true`, no `.boot-recovery` (exports root) | a normal finished take — never touched by salvage or pruning |
| `.recovered-at` present (under `recovered/`) | landed there via salvage at the stamped instant. Never deleted automatically: recovered audio stays until the user removes it (#1198; the 30-day prune of #679 is gone) |
| under `recovered/` without `.recovered-at` | not placed there by the salvage (e.g. dragged in by hand) |

## Top-level fields

```jsonc
{
  "slug": "perf-20260706-143015",
  "sample_rate": 48000,
  "channel_layout": { "master_channels": 2, "captured_inputs": [0, 1] },
  "capture_frames": 4800000,
  "overrun_count": 0,
  "overrun_gaps": [ { "frame": 12000, "duration_frames": 64 } ],
  "layers": [ /* see below */ ],
  "take_id": "9f2c41d07a5e4b3c8e61f0a2b7d93c54",
  "encoding": "f32",
  "volume_generation": -1,
  "ring_seconds": 2,
  "overs": 2,
  "parts": [ /* see below */ ],
  "stopped_early": "disk_full",
  "armSnapshot": { /* see below */ },
  "disarmSnapshot": { /* see below */ },
  "finalized": true
}
```

| Field | Type | Notes |
|---|---|---|
| `slug` | string | The bundle directory's own name (D-NAME); redundant with the path but kept so the file is self-describing if moved. |
| `sample_rate` | int | Negotiated device sample rate at arm time. Every PCM file in the bundle shares this rate (D-RATE — no resampling). |
| `channel_layout.master_channels` | int | Channel count of the master parts (D-MASTER: stereo, or mono on a mono device). |
| `channel_layout.captured_inputs` | int[] | Hardware input indices monitored at arm time (frozen for the session, D-INPUT); each has its own `input-<n>-NNN.wav` parts, stereo. |
| `capture_frames` | int | Total frames elapsed since arm, regardless of any ring drop. In a MID-CAPTURE sidecar this is elapsed *as of that cycle's start*, not as of the moment the file was written (the cycle samples the frame count before it drains a single ring — see #710 — so audio produced while the cycle was writing is counted next cycle instead). The final sidecar is unaffected, since no audio is produced after it; only a crash-recovered bundle, whose newest sidecar is a mid-capture one, ever sees the difference. |
| `overrun_count` | int | Capture-ring overruns (frames the audio thread could not enqueue) since arm. Not the whole story — see `zero_filled_frames`. |
| `zero_filled_frames` | int | Frames of digital silence the drain actually wrote into the capture files since arm, summed over every file it writes. Since #1198 a dropped frame is never silence-filled: it ends the take (`slow_storage`). What is filled is audio counted but never tapped, which is how #710's takes carried audible silence while `overrun_count` read `0`. Counts bytes that reached disk, so a pad the disk refused (a `disk_full` stop mid-pad) is excluded even though `overrun_gaps` may still name the span. Absent from any sidecar written before #710. |
| `overrun_gaps` | array | Up to 128 individually-logged `{frame, duration_frames}` gaps — where a file fell behind and by how much it was *asked* to pad. Beyond 128, frames are still silence-filled, just not itemized here; `zero_filled_frames` stays exact regardless. |
| `layers` | array | Every retired overdub layer's raw PCM, persisted before pool eviction/clear/redo could destroy it (part 5, D-LAYER) — see below. |
| `take_id` | string | The take's 16-byte identity as 32 lowercase hex digits, minted by the repository before arm and written into every part's `sgno` chunk (#1198). |
| `encoding` | string | `"f32"`: every part holds 32-bit float samples exactly as captured. |
| `volume_generation` | int | The removable volume generation the take was armed on, or `-1` for Internal. |
| `ring_seconds` | int | Seconds each capture ring was granted at arm, after the 64 MiB total cap. |
| `overs` | int | Samples with a magnitude above 1.0 across every part, sealed and open. Kept as written, never clipped. |
| `parts` | array | The take's audio parts in playback order — see "Audio parts" below. |
| `stopped_early` | string? | Why the take stopped before a normal disarm; absent otherwise. `"disk_full"`: a write failed (a full disk, a quota, a read-only remount, an I/O error). `"device_changed"`: the audio device changed. `"reserve_reached"` (#1198): the destination reached its reserve, and every stream ends at the last whole frame it could hold above it. `"slow_storage"` (#1198): a capture ring overflowed because the storage fell behind, and every stream ends at the first frame that could not be kept, with nothing filled in after it. For the last two, `capture_frames` is the frame the take ends at. |
| `armSnapshot` | object? | See below. `null`/absent only if the app crashed before arm's own crash-survival file (`arm-snapshot.json`, deleted at finalize) could even be written. |
| `disarmSnapshot` | object? | See below. Absent for a capture recovered from a crash — there is no live engine left for a second pass. |
| `finalized` | bool | `true` once finalize completed. The salvage *trigger* (D-SALVAGE): `false`/absent is what routes a bundle to crash recovery — but since the silent boot salvage (#679) it is no longer the sole salvage marker; the `.boot-recovery` / `.recovered-at` sibling files carry the move half of the story (see "Salvage sibling files" above). |

## Audio parts (#1198)

The drain writes each captured stream straight into ordered 32-bit float WAV
parts: `master-NNN.wav` (stream 0) and `input-<n>-NNN.wav` (stream `1 + n`),
`NNN` counting from `001`. A part holds at most 2,000,000,000 bytes including
its header; the next part continues the stream with no gap. Nothing converts
them at finalize: a sealed part is the delivered audio.

Each part starts with the same 84-byte header: `RIFF`, the RIFF size, `WAVE`,
a 16-byte `fmt ` chunk (format tag 3, IEEE float, 32 bits), a 32-byte `sgno`
chunk (the 16 take-id bytes, the stream as u16, the part index as u16, 12
zero bytes), then `data` and its size. All integers are little-endian. The
sizes are written as 0 when a part opens and patched when it is sealed; a
part still open when the process died keeps 0 there, and finalize patches it
from the file's length, floored to whole frames.

```jsonc
{ "stream": 0, "index": 1, "file": "master-001.wav", "frames": 249999989, "bytes": 1999999996, "overs": 0, "sha256": "…" }
```

| Field | Type | Notes |
|---|---|---|
| `stream` | int | 0 for master, `1 + n` for captured input `n`. |
| `index` | int | The part's position in its stream, from 1. |
| `file` | string | The part's file name in the bundle directory. |
| `frames` | int | Frames in the part, as of this sidecar. |
| `bytes` | int | Header plus `frames` whole frames. |
| `overs` | int | Samples in this part with a magnitude above 1.0. |
| `sha256` | string? | SHA-256 of the part's data payload, 64 lowercase hex digits. Present once the part is sealed; absent on the open part. |

### `layers[]` entries (part 5, unchanged by part 6)

```jsonc
{ "channel": 1, "slot": 4, "generation": 2, "frame": 4800, "frame_count": 480, "lane_count": 1, "filename": "layer-1-4800-4.pcm" }
```

`frame` is a best-effort, buffer-granularity snapshot (not sample-accurate);
cross-reference `channel`/`slot`/`generation` against `events.log`'s
`LE_PLOG_LAYER_RETIRED` entries for the exact retire frame. These raw files
are **not** copied into `loops/` — they exist for the offline renderer (parts
7-8) to reconstruct overdub-pass-by-pass audibility, not as a directly
playable deliverable of this part.

## `armSnapshot`

The capture's initial state. Lane, monitor and track chains come from the
caller-supplied `PerformanceChains`. The selected output chain, destination,
policy, level and mute come from the engine after the audio callback acknowledges
arming. These facts must not be substituted with a pre-arm read taken before
asynchronous file work. The settled snapshot is published atomically; an
incomplete arm must not leave plausible but incorrect recovery metadata. The master phase comes from the sample-accurate `PERF_ARMED` event, not this control-thread snapshot. If publication fails after capture starts, the repository retains the live capture and its settled in-memory facts so Stop can finalize it; it does not silently become idle.

```jsonc
{
  "masterGain": 1.0,
  "limiterOn": true,
  "limiterCeiling": 0.99,
  "latencyOffsetFrames": 128,
  "tempoBpm": 96.0,
  "followOutput": false,
  "captureBus": 0,
  "captureMask": 3,
  "outputEnabledMask": 3,
  "outputLevel": 1.0,
  "outputMuted": false,
  "fxStagesVersion": 1,
  "tracks": [ /* see below */ ],
  "monitors": [
    { "input": 0, "enabled": true, "outputMask": 3, "volume": 1.0, "muted": false, "chainEnabled": false, "effects": [ /* see FX entries */ ] }
  ],
  "trackChains": [
    { "channel": 0, "chainEnabled": false, "effects": [ /* see FX entries */ ] }
  ],
  "outputEffects": [ /* see FX entries */ ],
  "outputChainEnabled": false
}
```

| Field | Notes |
|---|---|
| `masterGain` | Master output gain at arm time. |
| `limiterOn` / `limiterCeiling` | Master peak limiter state at arm time. |
| `latencyOffsetFrames` | The active device profile's record-offset latency compensation. |
| `followOutput` | Required capture policy, frozen at arm. Both policies capture after the selected destination FX. Default excludes final output controls. Follow applies that destination’s current level and mute; arm values seed replay and later events change them. Neither policy applies destination Mono/Balance, final hardware master gain or limiter. |
| `captureBus` | The destination actually captured: the first with an enabled channel at successful arm, not a pre-I/O guess. It remains fixed for the take. Its selected output chain is captured at the same boundary. Omission means bus 0; a provided value must be an integer from 0 through 15. |
| `captureMask` | Required nonzero unsigned 32-bit mask confined to the selected pair, frozen at arm. Missing/disabled jacks are not invented as routes. Invalid or absent identity is refused before reconstruction. |
| `outputEnabledMask` | The complete structural output gate at arm. Source fan-out uses this mask; a destination-local mask cannot stand in for the entire interface. |
| `outputLevel` / `outputMuted` | `captureBus`'s level and mute at arm time, the starting point of that replay. Written only when off their defaults (unity, unmuted). |
| `tempoBpm` | The engine tempo at the arm instant, verbatim (`0` = unset, the same sentinel `session.json`'s `tempoBpm` uses; absent = written before the field existed — both read as "no tempo evidence"). The **crash-salvage fallback** for a DAW export's tempo, not the authoritative value: D6's tempo lock only engages once grid content exists, so a tempo dialed in (or derived by the first loop) after an arm-over-empty-grid is only knowable at disarm — see `disarmSnapshot.tempoBpm`. |
| `fxStagesVersion` | FX-stage schema revision (FX v3, R20): `1` = the four-stage model below. **Absent = a legacy snapshot** written before those fields existed; see "FX stages" below. |
| `tracks` | One entry per **non-empty** track (empty tracks are omitted); carries the **Loop** stage, per lane. |
| `monitors` | The **Input** stage: one entry per hardware input the caller supplied chain/routing state for. Each entry's `chainEnabled` is that monitor chain's bypass flag, written only when `false` (absent = engaged, or legacy — see the marker below); `enabled` beside it is the input's own monitor gate, not an FX flag. |
| `trackChains` | The **Track** stage: one entry per track channel with bus FX or a non-default chain flag. Omitted when there are none. |
| `outputEffects` / `outputChainEnabled` | The actual captured destination’s output chain and bypass flag, captured by the engine at arm. The chain is applied once by reconstruction to audio before that stage; the already captured top-level master audio is never processed a second time. Empty effects and an engaged chain use the writer’s default omission rule. |
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

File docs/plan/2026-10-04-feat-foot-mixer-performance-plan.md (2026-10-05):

# Foot Mixer performance

Issue #1123; parent #1026; `autonomy:merge-gate`. Base `5704e2fed795274368ff5bad2fcbba22c8d73d6e` (track-mute durability #1129), branch `codex/foot-mixer-performance`. Implementation is authorized; technical review precedes code changes.

## Delivery boundaries

Independent scope, VGV and simplicity reviews split this into working-product
changes, each with its own checks and human merge gate:

1. [Shared input gain](2026-10-04-fix-live-input-gain-part-1-plan.md), issue #1124:
   correct existing controls and saved-data admission without exposing a new mode.
2. [Complete Foot Mixer](2026-10-04-feat-foot-mixer-performance-part-2-plan.md),
   issue #1123: deliver Tracks and Inputs together after the dependency is ready.
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

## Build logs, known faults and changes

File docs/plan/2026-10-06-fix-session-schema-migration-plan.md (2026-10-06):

# Convert saved sessions from older schemas on open

Tracking: #1196, `autonomy:merge-gate`. Owner decisions, 2026-10-06:

- Sessions saved by the shipped app (schema 7, on master and on the
  appliances) must keep opening after the trunk lands.
- The oldest sessions convert too, back to schema 1. Use conservative
  defaults: no FX chains, and a tempo derived from the loop length where none
  was saved. Keep the original as a backup and show the same notice.

This is a deliberate, owner-made exception to the AGENTS.md rule against
migrations. It is kept to one module
(`packages/session_repository/lib/src/session_migration.dart`), and the strict
current-schema decoder (`Session.fromJson`) is unchanged.

## Schema history

Reconstructed with `git log -G'formatVersion = '` on
`packages/session_repository/lib/src/models/session.dart`. Schemas 8 and 9
were each written by two histories that the trunk later merged: the September
slices (#1016) and the October 1 reconstruction (#1061), whose merge commits
are the trunk's first parents. Their key sets differ, so the steps for 7, 8
and 9 accept both spellings.

| Schema | Written by | What changed |
| --- | --- | --- |
| 1 | `8547affe7` | Tracks with one `stem` WAV, `volume`, `muted`. Saved and re-applied `tempoBpm`, `syncLoopToTempo`, `quantizeMode` (`off`/`beat`/`bar`), `metronomeOn`, `countInEnabled` (one bar). |
| 2 | `93f2f0cb5` (#112) | Drops the transport keys; adds `laneChains` and `monitors` (with `enabled`), chains as bare arrays. |
| 3 | `319a7dc9d` (#151) | `lanes` with ordered `layers` and undo/redo counts replace `stem`. |
| 4 | `7e2515802`, `fb8d7cc2b` (#280, #295) | Tempo grid, click, count-in; per-track `lengthPresetBars` and `oneShot`; `looperMode`, `primaryTrack`, `oneShotChannels`. |
| 5 | `b52c3d276` (#388) | `trackChains`, `masterChain`; chains become envelopes. |
| 6 | `4dc33ac10` (#412) | `pedalBindings`. |
| 7 | master `990a60f5b` (#611), every appliance | Monitor gate by name (`mode`) beside `enabled`. Master saved tempo, grid, click and count-in but never re-applied them on load. Rec dub, auto record, sync, default length and record timing were global settings, not in the file. |
| 7 (slices) | `7a8c7c3bd`..`7a29dda18` | Same number with extra optional keys: `recordTiming`, `overdubDecay`, `defaultOnce`, `onceOverrides`, `lengthPresetOverrides`, `defaultLengthPresetBars`; track `pan`, `recordTiming`, `overdubDecay`; lane `pan`/`balance`; `inputSetup`, `outputSetup`. From slice 3b (`f628c7412`) `masterChain` already meant output bus 0's chain; see the limitation below. |
| 8 (slices) | `919e337d2` | Adds `allTracksChain`. `masterChain` is output bus 0's chain. |
| 9 (slices) | `30b38ea69` | `outputChains` replaces `masterChain`, which it drops. |
| 8 | `9264ccd9f`..`a0a54e57e` | Track settings become session maps; `syncTempo`, `recDub`, `autoRecord`, `defaultMultiple` become session settings; monitors keep only `mode`; undo/redo counts required; track pans, lane routing, input and output setup. `masterChain` is output bus 0's chain. |
| 9 | `a52fe34d4`..`623a5a7ba` | `allTracksChain` required, `trackLevels`; `0d601db8e` replaces `masterChain` with `outputChains`; `623a5a7ba` caps monitor volume at 1. |
| 10 | `a921bd9a9` | Fade durations. |
| 11 | `19a6faa8d` | Required per-track `fadeAmount`. |
| 12 | Peel P2 (#1164, PR #1194) | Per-lane `history` entries with kinds. |
| 13 (in flight) | Reverse P2, #1162 | Required per-track `reversed`. |

## Design

- `sessionMigrationSteps` maps each schema from 1 to one step, `vN → vN+1`,
  over the decoded manifest. `decodeSessionManifest` runs the steps from the
  bundle's schema up to `Session.formatVersion`, then the strict decoder. A
  test fails when any schema lacks its step.
- `SessionRepository.open` reads, converts in memory and validates; it writes
  nothing. `read`, the Library preview and the stems export decode through the
  same conversion without the player's settings.
- `SessionCubit.open` opens with the player's current settings
  (`SessionSettingsCoordinator.current`). After the rig applies it calls
  `commitConversion`: the original manifest is kept byte for byte as
  `session.v<N>.json` (an existing backup with other bytes moves the new one
  to `session.v<N>.2.json`, one with the same bytes is reused), then the
  converted manifest replaces `session.json` through `session.json.tmp` and a
  rename. A failed write deletes the temporary file.
- Until the next save the backup shares the audio with the converted session,
  so putting it back as `session.json` restores the original. The next save
  (which writes a whole new bundle and swaps it in) moves the backup manifest
  and the layer files it names out of the previous bundle into a
  `session.v<N>/` folder in the new one, which opens as a bundle of its own.
  Later saves move that folder along. The move happens after the swap; until
  it finishes the previous bundle is kept as `<id>.old`, and the catalog's
  recovery finishes the move before deleting it. The folder is assembled
  inside `<id>.old` (layer files first, the manifest last) and then renamed
  into the new bundle in one step, so a power cut never splits a backup: a
  folder without its manifest is an unfinished assembly, and the next run
  reuses it. A save over a bundle whose
  write-back failed does the same with its own older manifest. A failed save
  leaves the previous bundle, original included, as it was.
- The notice says the session was converted and the original kept, or, when
  the write-back failed, that the original file is unchanged. It adds a
  sentence for each audible change: the Master effects (and their pedals) now
  on All tracks, a live input lowered to 100%, and a tempo set from the loop
  length for a session that saved none. The notice only claims the backup
  when `commitConversion` reports that it wrote it. The conversion notes go to
  the log.
- A newer schema is refused as before (`SessionUnsupportedVersion`). A
  manifest older than schema 1, or one a step or the strict decoder refuses,
  is refused with `SessionUnconvertible` and its own message, in the session
  notice, the Library preview and the Library's refusal banner. Every refusal
  happens before anything is written.

## Defaults and decisions

Rule numbers are the owner rules (1 preserve existing behaviour, 2 fail safe,
3 no silent change, 4 consolidate, 5 drop uncertain state with a notice).

| Field (first schema) | Value for an older session | Why |
| --- | --- | --- |
| Schema 1 `tempoBpm`, `syncLoopToTempo`, `quantizeMode`, `metronomeOn`, `countInEnabled` | Manual tempo in 4/4 (when 30–300), `syncTempo`, record timing and grid `off`→immediately/off, `beat`→quarter, `bar`→bar, click while playing or recording, one-bar count-in | Schema 1 saved and re-applied them. |
| Stem (1–2) | Lane 0: the track's level and mute, both outputs, no input, one live layer | Master's own reading of these tracks. |
| Lane and monitor chains (2), Track and Master chains (5) | Empty | No FX chains where none were saved. Bare-array chains of 2–4 are kept; the current decoder reads them. |
| Tempo (4) where none was saved (2, 3, or 1 out of range) | Derived from the base loop as the engine does with loop sync: whole 4/4 bars, the tempo nearest 120 within 30–300 (`le_grid_derive_bpm`), `derived`, `loopBars` = those bars; none without a loop | Owner decision. |
| Grid, click, count-in, looper mode, crown (4) | Off, multi, no crown | Master's reading of pre-4 bundles. |
| `pedalBindings` (6) | Empty | The global remap applies, as on master. |
| `syncTempo`, `recDub`, `autoRecord`, `defaultMultiple`, `recordTiming` (8) | The player's live value at open | Master kept these as global settings and opening a session never changed them (rule 1). A file that saved them keeps its value. |
| `trackRecordTimingOverrides` (8) | Empty | Per-track timing did not exist before (slices aside); every track followed the global setting. Live values would carry the previous session's choices across. |
| Tempo, signature, grid, click, count-in, looper mode, crown (4–7) | As saved | The file's own data. Master saved them without re-applying them; the trunk applies them, and the notice says the session was converted (rule 3). |
| `trackOneShotOverrides`, `trackLengthPresetOverrides` (8) | From `oneShotChannels` and per-track `oneShot`, and presets above 0 | Master reset every other track to Loop and Auto. |
| `loopBars` (8) | 0 unless derived above | Master committed loops with no bar count. |
| `overdubDecay` (8) | 0, none | Decay did not exist. |
| Monitor `mode` (7) | `mode`, else `enabled ? on : off` | Master's own fallback. |
| `masterChain` in a schema 5–7 file | `allTracksChain`, and Master-stage pedal bindings retargeted to All tracks (slot kept); told in the notice | Master's insert ran on the summed tracks before live monitoring joined. Difference: master processed only the first enabled output pair, All tracks every destination's recorded mix. Identical when tracks use one pair. |
| `masterChain` in a schema 8 or 9 file | Output bus 0's chain, and its pedal bindings to output 0 | From slice 3b the Master insert was bus 0's chain. A file that also has a bus 0 chain cannot be converted (rule 2). |
| `allTracksChain` (8/9), `outputChains` (9) | Empty | No such stage before. |
| `trackLevels`, `trackPans`, `inputSetup`, `outputSetup`, lane `pan`/`balance`, lane routing maps | Unity, centre, empty | They reproduce how the takes were recorded and heard. |
| Monitor `volume` above 1 (cap from 9) | 1, noted, told in the notice | Unity is the live-input ceiling (#1124); lowering is safer than refusing (rule 2). |
| Fade durations (10), `fadeAmount` (11) | 4000 ms and none; 1 | Fade did not exist. |
| Lane `history` (12) | One `layer` entry per undo and redo entry | Schema 11's recall filed every entry as `LE_HIST_LAYER`; images and counts are unchanged. |
| A Master binding in a schema 10 or 11 file | Unchanged | It was already inert as written; making it live would change the session. |

Every filled, moved or changed field is recorded in the conversion notes.

**Known limitation.** A slice-era schema-7 file written between slice 3b
(`f628c7412`) and the slices' own bump (`919e337d2`) stored output bus 0's
chain as `masterChain`. The conversion cannot tell it from master's and moves
it to All tracks, where live monitoring no longer passes through it. Such files
exist only on development machines from those two weeks.

## Fixtures

`packages/session_repository/test/fixtures/sessions/` holds bundles written by
each schema's own code; `fixtures/generators/` holds each generator, with the
commit in its name.

- `v7_master_full`, `v7_master_empty`: master `bedcecf27`, its native engine,
  `LooperRepository`, `chainsFromLooper`, `SessionRepository.save` and
  `PedalBindingSet.encode`.
- `v1_loopy_8547affe7` to `v6_loopy_4dc33ac10`, `v8_*`, `v9_*`, `v10_*`,
  `v11_*`, `v12_peel_097e1ef68`: each commit's `SessionRepository.save` over
  its own fake engine. Schemas 2–4 encode their chains with their own
  `encodeTrackEffects`; later ones carry the strings master encoded.

Tests open every fixture and check its values, apply converted 1, 2, 4 and 7
bundles to the native engine, check backup, write-back order, the backup
folder after a save, byte-identical refusals and failed saves, and the notice
and Library messages.

## Adding a schema bump

Add the step to `sessionMigrationSteps` and a fixture from the bumping commit
to the lists in `session_migration_test.dart` and `session_conversion_test.dart`.
The coverage test fails until the step exists. Reverse P2 (13) adds
`12: _v12ToV13`, setting every track's `reversed` to `false`.

## Library (#1178)

The lenient catalog row lists an older bundle normally and counts a
`masterChain` in its effects. The preview and the stems export decode through
the conversion; rename only edits `name` in the manifest and leaves the schema
as it was.

## Design write-back

No new surface. The notice adds sentences to the existing session toast; an
unconvertible session uses the existing version refusal places with its own
text.

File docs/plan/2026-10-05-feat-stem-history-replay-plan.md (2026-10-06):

# Replay ordinary audio-history changes in performance stems

Tracking: #1143 (parent #1026), `autonomy:merge-gate`, human merge gate.
Status: plan approved with required review edits E1-E8, which are applied in
this text; Part 1 built on branch `claude/stem-history-replay-1143` (the build
record at the end lists where the build departed from the amended text and why).
Base: `origin/claude/manifest-failure-1144` at `cee9685ac` (PR #1155, stacked on
#1145 `codex/fade-clear-history` `270209fbc`). Unless a branch is named, every
`file:line` below is on that head. Precedent:
`docs/plan/2026-10-05-feat-fade-clear-history-plan.md` and its
captured-restoration amendment; format:
`docs/design/performance-event-log-format.md`.

## 1. Problem and current boundary

A layer Undo or Redo is a control-thread swap of `a_live` (`engine_commands.c:268-274` `le_undo_swap`, `:2242-2249` redo swap, `:2205-2240` redo-from-empty, `:1971-2035` `le_restore_clear`), all funneled through `le_track_publish_live` (`engine_core.h:116-120`). The audio thread reads the new slot at the next frame (`engine_process.c:5287-5291`). The only logged record is the control-side `LE_PLOG_UNDO`/`LE_PLOG_REDO` (304/305, `engine_commands.c:2118-2119`, `:2247-2248`), stamped within one buffer and naming neither the PCM nor its first audible sample. The offline renderer ignores 304/305 entirely (`perf_render.c:908-1061` handles only 322/323, `RECORD_END`, `LAYER_RETIRED` and `LE_CMD_CLEAR`), so after an ordinary swap it keeps playing the previous image and reports success.

#1142/#1145 closed this for Clear restoration only: the control thread stages an immutable copy of the retained slot (`engine_commands.c:1995-2002` -> `le_stage_retired_layer` `:535-587`, kind 1, `restore_id`), the callback publishes `LE_PLOG_CLEAR_RESTORE` (322) at the exact mixer frame and `LE_PLOG_RESTORE_TRANSPORT` (323) for later state/phase changes (`engine_process.c:5369-5390`), and any later same-span swap ends the source with `323/0`, failing the stem (`:5375-5378`, `perf_render.c:919-924`). `test_fade_restore_history_replacement` (`test_engine_fade.h:701-729`) and `test_fade_restore_source_end_edges` (`:795-821`) currently assert that failure.

This plan generalizes that mechanism to every callback-applied history transition. No second transport or history state machine: the existing control-side history (`undo_stack`/`redo_stack`, `engine_private.h:909-912`), the existing staging ring and drain (`layer_staging_ring.h:51-61`, `perf_drain.c:860-918`) and the existing renderer segment builder (`perf_render.c:660-728`) remain the only owners.

## 2. Provenance model

### 2.1 Definitions

- **Image**: an immutable copy of one pool slot's PCM across the track's active lanes, written by the drain as `restore-<channel>-<id>.pcm` and listed in `performance.json` `layers` with `kind: 1` and a capture-local nonzero `restore_id` (`perf_drain.c:863-865`, `:904-916`). Wire names stay; the doc redefines `kind 1` as "callback-applied immutable source image" regardless of whether the admission was a Clear Undo, a layer Undo/Redo or a Redo-from-empty (decision D1).
- **Admission**: the control-thread operation that will change which slot is live. Before it publishes `a_live`, it stages the target slot and records the image id for that slot in a new per-capture table `perf.slot_image[LE_MAX_TRACKS][LE_POOL_SLOTS]` (`_Atomic uint32_t`, 8 KB, zeroed with `engine->perf` at configure `engine.c:363` and at arm `engine_commands.c:4095-4125`). Staging refusal stores 0 in the table and counts `a_perf_layer_overruns` as today (`:567-586`).
- **Application**: the frame at which the callback first mixes the new slot while the track is PLAYING or STOPPED. The callback identifies the image by reading `slot_image[t][a_live]` at that frame and logs it. Nothing control-side is ever interpreted as the application frame.

### 2.2 Callback state (replaces `perf_restore_*`, `engine_private.h:977-978`)

Per track, audio-thread-local: `perf_source_slot` (-1 = none; the lane-0 slot the stem currently reproduces), `perf_source_id` (0 = snapshot/kind-0 provenance, nonzero = staged image), `perf_source_state`, `perf_source_next_pos`. Rules, evaluated once per frame per track while `e->perf.armed` at the existing site `engine_process.c:5369-5390`.

Application boundary (review E2, as built; see the build record): `mix_tracks_frame` loads `lanes[0].a_live` ONCE per frame per track with acquire into `live_idx[t]`, for every track including idle ones; the mixer's `buf[t][0]` and the tracker both use this value, so a fact can never name a slot the mixer did not mix at that frame, and the relaxed lane-0 load at `:5289` is replaced by this load. (The review described the load as once per block; the code loads it per frame, inside `mix_tracks_frame`, which `le_engine_process` calls from its per-frame loop at `:6252`/`:6302`.)

1. State PLAYING or STOPPED and `live0 != perf_source_slot`: set `perf_source_slot = live0`; `id = slot_image[t][live0]`. If `id != 0`: `perf_source_id = id`, `perf_source_state = -1` so the next step emits 322 `{channel, id, state, phase}` at this frame, `phase = trk_play_pos % len` as today (`:5372`). If `id == 0`: emit `323 {channel, 0, EMPTY, 0}` unconditionally (a slot became live without a staged image; provenance is lost whether the previous source was an image or the arm snapshot), then `perf_source_id = 0`. (E1.)
2. State PLAYING or STOPPED and slot unchanged, `perf_source_id != 0`: emit 323 on state change or phase discontinuity exactly as today (`:5380-5387`).
3. State RECORDING or OVERDUBBING: if `perf_source_id != 0` emit `323/0` (uncaptured material, unchanged policy) and set `perf_source_id = 0`; set `perf_source_slot = live0` so the written slot is the current snapshot-provenance source and no table lookup happens at `RECORD_END`. As built, additionally: if the slot changed and `slot_image[t][live0] != 0`, emit `323/0` too (a staged image overwritten before it was ever mixed PLAYING or STOPPED: a restore, Redo-from-empty or layer swap followed by Record in the same block; see the build record).
4. State EMPTY: no fact here. Every material reset (`le_fade_reset`, `engine_process.c:189-195`, reached from `handle_clear` `:2135`, `apply_undo_to_empty` `:1857`, void finalize `:1318`, fresh record `:1751`/`:1768`, `LE_CMD_RESET_FADE` `:2988`) sets `perf_source_slot = -1`, `perf_source_id = 0`. Safe for `LE_CMD_RESET_FADE` (82) because 82 is only pushed on EMPTY tracks (`engine_session.c:136`, `:292`); a future non-EMPTY caller must not reset provenance (E8). `apply_undo_to_empty` additionally logs the raw `LE_CMD_UNDO_TO_EMPTY` (39) at the exact apply frame (section 3). `le_perf_restore_end`'s `323/0` is no longer emitted from `apply_undo_to_empty` (`:1856`): emptying is exact silence, not lost provenance.
5. `LE_CMD_PERF_ARM` (`:3643`): `perf_source_slot = EMPTY ? -1 : a_live`, `perf_source_id = 0` for every track, so the arm snapshot stays the provenance of content that was already live, and anything that becomes live later goes through the table.

### 2.3 Which fact identifies which image for each operation

| Operation | Admission (control, before publish) | Application fact |
|---|---|---|
| Layer Undo (`le_undo_swap`) | stage `undo_stack[top].slot`, len `a_len`; `slot_image[ch][slot] = id`; publish | 322 `{ch, id, state, phase}` at the first frame the callback mixes the slot, PLAYING or STOPPED |
| Layer Redo (`le_engine_redo` swap, `:2242-2249`) | stage `redo_stack[top].slot`, len `a_len` | same |
| Redo-from-empty (`:2205-2240`) | stage `redo_stack[top].slot`, len `empty_len`; publish; push `LE_CMD_REDO_FROM_EMPTY` | the handler flips PLAYING; the mixer sees `live0 != -1` (EMPTY reset) and emits 322 with the staged id and the restored phase (`le_restore_track_clock`, `:2859`) |
| Clear Undo (`le_restore_clear`) | unchanged staging, now through the shared helper; `source_slot`/`image_id` leave `le_command.restore` (`lockfree_ring.h:129-130`) | 322 as today, discovered through the table instead of the command |
| Undo-to-empty / cancel take | none | raw 39 at the apply frame; renderer appends silence (as `LE_CMD_CLEAR` does, `perf_render.c:1056-1058`) |
| Several admissions before one callback (Undo, Undo, Redo in one block) | each stages its own target and overwrites the table entry for that slot | exactly one 322, for the slot the callback actually mixes first, with that slot's latest id. Intermediate images are listed but unreferenced; a slot's content cannot change between its staging and its application (only a live or shadow slot is written by the callback, and either state ends the source by rule 3), so a later re-staging of the same slot is byte-identical |
| Loop-close restoration commit (`le_restore_commit_layer`, `:344-404`) | publishes with image 0 (table cleared) | `323/0`: truthful failure, as the amendment already specifies for processed-material swaps |
| Fresh capture (`le_begin_empty_capture`, `:940-967`) | clear `slot_image[ch][0..LE_POOL_SLOTS)` before the RECORD push | none; rule 3 marks the written slot during RECORDING |

Invariant (E3): every control path that writes PCM into a pool slot or publishes `a_live` outside `le_publish_live_image` zeroes `slot_image[ch][0..LE_POOL_SLOTS)` first. Sites: `engine_session.c:118-136` (`le_engine_import_track_lane`, before its `memcpy`), `le_engine_import_layer` (before its `memcpy`) and `:289` (`le_engine_finalize_layers`; publish through `le_publish_live_image(…, 0)`), `engine_commands.c:845-856` and `:961` (fresh-capture zero and regrow: one call in `le_begin_empty_capture`, which precedes both and the `le_prepare_image_capture` buffer replacement of `LE_CMD_RECORD_IMAGE` in the same admission), `:367-402` (`le_restore_commit_layer`, publishes image 0). Verified during the build: `le_prepare_image_capture` only replaces the EMPTY track's live slot and a free (non-live, non-outstanding) shadow with zeroed buffers, and runs before `le_begin_empty_capture` in `le_engine_record`, so that one row zero covers it.

Memory ordering: the table store is relaxed, `le_track_publish_live` stores `a_live` with release (today relaxed, `engine_core.h:118` via `store_i32` `engine_private.h:1978-1980`), and the callback's shared lane-0 load of `a_live` is acquire. A callback that sees the new slot therefore sees its table entry.

### 2.4 Shared control helper

`le_stage_source_image(engine, channel, slot, len) -> uint32_t` in `engine_commands.c`: returns 0 without side effects when `engine->perf.drain == NULL` (nothing to stage; same gate `le_restore_clear` uses at `:1995`, which includes a queued ARM), else allocates `++perf.next_image_id` (renamed from `next_restore_id`; `UINT32_MAX` guard counts an overrun as at `:1996-1997`), calls `le_stage_retired_layer(..., len, id)` (which now returns success), and stores the id or 0 in the table. A companion `le_publish_live_image(engine, t, slot, id)` (static inline in `engine_core.h`, next to `le_track_publish_live`, so `engine_session.c` reaches it too) stores the table entry then calls `le_track_publish_live`; it becomes the only `a_live` publisher in `engine_commands.c` (`:271`, `:2011`, `:2229`, `:2244`, `:402`) and `engine_session.c` (`:289`). `le_forget_slot_images(engine, channel)` (same header) is the row zero of the E3 invariant. Staging refusal never refuses the musical operation (precedent `test_fade_restore_staging_and_manifest_capacity`, `test_engine_fade.h:859-863`).

## 3. Log format: events.log version 6

Bump `perf_drain.c:814` from 5 to 6 and add the row to the version table (`performance-event-log-format.md`), fixing the F4 blank line from the #1145 review while there. Changes covered by the bump:

- **322** is renamed in code to `LE_PLOG_SOURCE_APPLIED` and **323** to `LE_PLOG_SOURCE_TRANSPORT` (`perf_log_ring.h:139-140`; wire values unchanged, no FFI exposure). From version 6 a channel may carry several 322 facts; each names the staged image that became live at that frame. A reader switches images on every 322. 323 keeps its meaning: same image, new state/phase; `image_id == 0` with state EMPTY means provenance was lost and the stem is not reconstructible.
- **39 `LE_CMD_UNDO_TO_EMPTY`** is logged raw from `apply_undo_to_empty` at the exact apply frame (generic arm, `arg_i` = channel), next to the existing 304. The audited table row changes from "No*, logged as 304" to "Yes, plus 304", following the documented raw-command-plus-transport-fact convention.
- **303 `LE_PLOG_LAYER_RETIRED`** `evt` arm gains a fourth field `int32_t frames` (the pass length `dub_len`), mirrored verbatim from `LE_EVT_LAYER_RETIRED` (`engine_process.c:1492-1503`). Zero in older files. Part 2 adds it on the control side under this same version (E4; the version-6 row says so).
- The Reverse plan (`origin/claude/reverse-plan-1162:docs/plan/2026-10-05-feat-foot-reverse-plan.md:257-263`) also bumps 5 to 6 and allocates 324. This plan allocates no new code; whichever lands second takes version 7. The reverse plan's `perf_restore_next_pos` note (`:170-171`) applies to `perf_source_next_pos` after the rename.

Neither reader gates on the version (`perf_render.c:558-563`, `packages/daw_export/lib/src/event_log_reader.dart:13-23` reads only mix codes), so no compatibility path is needed and none is added.

### Renderer replay (`perf_render.c:829-1096`)

- 322: already resolves the image by exact `kind/channel/restore_id` with duplicate rejection and bounds (`:634-656`), appends a segment at the fact frame with the logged phase and `silent = state == STOPPED` (`:925-929`). Repeated 322 already works because each initial segment owns its image, and the error path already frees only the image the failing 322 loaded itself (`:908-918`, `if (initial) free(restore_image)`): no change needed there (E5). The only renderer change is 39.
- 323: unchanged (`:930-935`); `id == 0` fails (`:919-924`).
- 39: append a silence segment at the fact frame and clear `restore_id`, the same arm as `LE_CMD_CLEAR` (`:1056-1058`).
- Phase: the segment counter runs from the logged first-sample index (`:1088-1090`), so same-span swaps are sample-exact and Stop/Play after a swap follows 323 facts. Mute and Fade are untouched: lane mute commands pushed ahead of a redo or restore are logged on apply and replayed in the wet pass (`:1379-1386`); Fade uses 321 (`:1372-1375`); layer Undo/Redo does not reset Fade (`le_undo_swap` touches no fade field).
- Segment capacity: each swap adds one segment against `LE_PR_MAX_SEGMENTS` (`:68`); overflow already fails rather than truncates (`:696-699`).

## 4. Truthful failure

| Condition | Where it is detected | Result |
|---|---|---|
| Staging ring full, copy allocation failure, missing or short pool buffer, id exhaustion | `le_stage_retired_layer` `:562-586`, helper stores table 0 | callback emits `323/0` at the application frame; the stem fails; `a_perf_layer_overruns` reaches the sidecar as `layer_overruns` (`perf_drain.c:1258-1262`) |
| Manifest full (2048 entries) | drain drops the image, `layers_dropped` (`perf_drain.c:871-875`) | 322 names an unlisted id; `le_pr_restore_image` returns NULL (`:646`); stem fails |
| Image file missing, short or long | `le_pr_read_layer_lane0` exact-size check | stem fails (covered by `test_fade_restore_capture_lifetime`, `test_engine_fade.h:668-684`) |
| Layer file write failure | `le_pd_write_staged_layer` returns 0, drain self-stops `disk_full` (`:1503-1506`) | no manifest entry; stem fails; master and sidecar up to the stop stay usable (existing posture, unchanged) |
| Log ring overrun (`a_perf_log_overruns`, `a_perf_log_ctrl_overruns`, today not surfaced: `engine_private.h:1508`) | Part 2 writes `"log_overruns": N` to the sidecar | renderer fails every stem of that capture (a missing fact makes any stem untrustworthy); master unaffected |
| Fact lost to any other path | none claimed | not a supported success |

The master is never affected: `master.pcm` and monitors are written by the drain independently of the layer path (`perf_drain.c:1356-1367`), and only the per-stem `succeeded` flag changes (`le_perf_render_track_status`, `segno_engine_api.h:2958-2966`), which the recorder already maps to `PerformanceRecordPartial` (#1155).

## 5. Capture-staging gaps from the #1145 and #1155 threads

| # | Gap (source) | Decision |
|---|---|---|
| G1 | Kind-0 staging gated on `a_perf_armed`, and `le_perf_disarm` (`engine_commands.c:4212-4286`) never drains `evt_ring`, so a pass retiring in the last armed block is logged but never staged (#1145 follow-up gap 1) | In plan, Part 2: gate all staging on `perf.drain != NULL` (one gate, `:539-542`), and pop `evt_ring` with `le_handle_event(..., 0)` after the quiescent handshake and before `le_perf_drain_stop` (`:4274`), so the final drain cycle writes the file |
| G2 | A retire handled after a racing CLEAR reads `a_len == 0` and is skipped (`:545-546`), although the image is still in the slot (gap 2; also the review's "frozen predecessor never staged") | In plan, Part 2: `LE_EVT_LAYER_RETIRED` carries `frames = dub_len`; `le_stage_retired_layer` uses it for kind 0. Part 1 independently makes the later peel exact by staging at admission |
| G3 | Device change and destroy stop the drain without handling queued events (`engine.c:346-348`, `:1106-1108`; gap 3) | In plan, Part 2: pop `evt_ring` immediately before each `le_perf_drain_stop(..., DEVICE_CHANGED)`. With #1158 this is the pop that `le_engine_reopen_file_retired` performs at `origin/claude/engine-reopen-1140:engine_commands.c:855`, moved ahead of the stop inside `le_engine_quiesce_workers` (`engine.c:384-387` on that branch). Destroy needs nothing: no render follows |
| G4 | Renderer takes the first manifest entry matching `(channel, slot, generation)`; dub, undo, dub again in one generation repeats the key (gap 4; `perf_render.c:986-1000`; generation bumps only on clear, `engine_commands.c:1272`) | In plan, Part 2: consume kind-0 matches in manifest order per channel (retire log order, control FIFO and staging order agree) |
| G5 | A retire parked on a full `evt_ring` is dropped by `handle_clear` (`engine_process.c:2162`) and never reaches history (review "preexisting limitations" 1) | Out of plan: never logged, so no stem impact; a history-completeness issue |
| G6 | `le_restore_clear` queues lane mutes before the RESTORE push; a refused push leaves them queued (`:1983-2003`) | Out of plan: command-ring admission ordering, not provenance; note for a follow-up |
| G7 | Restore then Undo-to-empty before any mixed frame fails the stem although silence is correct (limitation 4) | Fixed by Part 1 as a consequence of the 39 fact |
| G8 | Ordinary staging refusal rendered stale success (final-delta F1) | Already fixed in #1155 (`layer_overruns`); Part 1 adds the callback-side `323/0` so the failure no longer depends on the sidecar count |
| G9 | Log ring overruns are invisible to the renderer | In plan, Part 2 (beyond the threads' list; required by the issue's capacity clause) |

## 6. Composition

- **#1155 (`layers_dropped`, `layer_overruns`, whole-render failure)**: unchanged. The flag at `perf_render.c:406-408` still governs unlisted kind-0 retires; kind-1 misses always fail. Staged Undo/Redo images consume manifest capacity (one entry per admission), so a long session can now reach the 2048 cap sooner; the consequence is dropped later images and failed stems, never stale success, and the master continues (`perf_drain.c:871-875`).
- **#1161 (capture-prep guard)**: orthogonal. The guard refuses PCM regrow/zero on an EMPTY track until its emptying command is published (`origin/claude/capture-prep-guard-1146:engine_commands.c:1607-1612`). This plan only reads pool slots that are not live or are the EMPTY track's unwritten live slot, never writes PCM, and keeps `le_undo_swap`/redo as `a_live` publications, so no ticket is needed. The `empty_command` stamp sites (`:436-454`) are untouched; a Record refused `NOT_READY` after an Undo-to-empty has no provenance effect.
- **#1158 (reopen)**: a reopen mid-capture ends the capture with `stopped_early: device_changed`: `le_engine_reopen` calls `le_engine_quiesce_workers` (`origin/claude/engine-reopen-1140:engine.c:946`), which stops the drain with `LE_PERF_STOP_DEVICE_CHANGED` (`:385`) and zeroes `engine->perf` (`:401`), clearing the table. Facts and images from the last armed block are flushed by the final drain pass inside `le_perf_drain_stop` (`perf_drain.c:1513`), provided the queued retires are popped before the stop (G3). Retained tracks come back STOPPED outside any capture; the next arm re-initializes ids and the table. Settled partial-pass reverts (`le_engine_reopen_settle`) happen after the drain stopped and are not logged, which is correct because no capture exists.
- **Reverse plan (#1162)**: the direction fact (324) and its `perf_source_next_pos` stepping compose with the renamed fields; the renderer's phase math for 322/323 segments must apply direction when that plan lands (`:264-268` there). Version sequencing as in section 3.

## 7. Parts

### Part 1: exact provenance for callback-applied history images (about 220 production lines)

Files: `packages/segno_engine/src/core/engine_private.h` (table in `le_perf_capture` `:1275-1336`; rename `perf_restore_*` `:977-978`), `engine_core.h:116-120` (release store, `le_publish_live_image`, `le_forget_slot_images`), `engine_commands.c` (helper, call sites `:271`, `:402`, `:1995-2011`, `:2229`, `:2244`, `:963`, arm reset `:4125`; `le_stage_retired_layer` returns int), `engine_session.c:118-136`, `:184-230`, `:289` (E3 sites), `engine_process.c` (`:182-195`, `:1856-1872`, `:2874-2909`, `:3643`, `:5283-5291`, `:5369-5390`), `lockfree_ring.h:122-131`, `perf_log_ring.h:139-140`, `perf_drain.c:812-819`, `perf_render.c:905-935`, `:1056-1059`, `docs/design/performance-event-log-format.md`.

Tests (patterned literal PCM, distinct per layer, through production entry points; new file `packages/segno_engine/src/test/test_engine_history_replay.h` included like `test_engine_fade.h` at `test_engine_core.c:33032`):
- `test_history_undo_redo_literal_parity`: base ramp A, overdub passes writing B and C (three distinguishable layers), Clear, arm after the layers exist, Undo (restore), layer Undo, layer Undo, Redo, Redo, Stop, Play, disarm, finalize, render; wet stem equals live output sample for sample (pattern of `test_fade_actual_arm_render`, `test_engine_fade.h:337-375`); segment boundaries at the exact frames; phase nonzero at every swap. A second leg pumped with 128-frame blocks asserts the 322 frame equals the first frame of the block that first mixes the slot (E2). Replaces the `expected 0` in `test_fade_restore_history_replacement` with parity.
- `test_history_redo_from_empty_parity`: Undo-to-empty while armed yields silence from the 39 frame; Redo-from-empty resumes with the staged image at the restored phase; muted lane stays muted through Undo-to-empty and comes back unmuted; Fade amount unchanged across layer swaps and reset across emptying.
- `test_history_batch_before_callback`: Undo, Undo, Redo admitted between two single-frame `le_engine_process` calls; exactly one 322, naming the final slot's latest id; `A -> B -> A` within one block produces no fact; the unreferenced manifest entries are listed; stem parity.
- `test_history_restore_then_empty_same_block`: G7, now succeeds with silence.
- `test_history_stopped_swap_then_play`: Undo on a STOPPED track emits 322 STOPPED at the observed frame, 323 PLAYING at Play, silent until then.
- `test_history_staging_refusal_fails_stem_keeps_undo`: staging ring held full (pattern `test_engine_fade.h:839-863`), Undo succeeds musically, `323/0` logged, stem fails, master frames intact, `layer_overruns` reported. Two legs (E1): snapshot provenance (content live at arm, no Clear first, arm image supplied) and image provenance (Clear Undo first).
- `test_history_missing_image_and_manifest_full`: delete `restore-0-N.pcm` for a layer Undo image: stem fails; manifest-full capture: later Undo image dropped, stem fails, capture continues.
- `test_history_capture_namespace`: arm, Undo (id 1), disarm, rearm, Redo (id 1 again in the new namespace); each capture renders only its own image; `test_fade_restore_capture_lifetime`'s queued-ARM leg extended with a layer Undo.
- `test_history_loop_close_restore_fails_truthfully`: `le_restore_commit_layer` during capture gives `323/0`.
- `test_history_import_during_capture_fails_truthfully` (E3): layer Undo stages slot X, Undo-to-empty keeps X live, a session import rewrites X; Play logs `323/0`, never the stale image; one leg per import entry point.
- Existing: `test_fade_restore_source_end_edges` updated to parity (both legs; see the build record), `test_fade_restore_overdub_source_end` unchanged.

```success-criteria
GOAL: Every layer Undo, Redo and recovery from empty admitted during an armed capture is replayed sample-exactly in the derived stems from an immutable staged image identified by a callback-applied fact, and every case without exact provenance fails the stem while the master stays usable.
SUCCESS CRITERIA:
- Literal stems equal live output across Clear/Undo, layer Undo/Redo, Redo-from-empty, Stop/Play and batched admissions, with nonzero phase and preserved mute and Fade. | verify: bash packages/segno_engine/src/test/run_native_tests.sh
- Staging refusal, manifest capacity, missing images and id exhaustion fail the affected stem, never report stale audio, never refuse the musical operation, and leave master.pcm complete. | verify: bash packages/segno_engine/src/test/run_native_tests.sh
- No callback allocation or blocking is added; sanitizer and telemetry-off builds pass; events.log header reads 6 and the format doc's version table has the new row. | verify: EXTRA_CFLAGS="-fsanitize=address -fno-omit-frame-pointer -g" bash packages/segno_engine/src/test/run_native_tests.sh && EXTRA_CFLAGS="-DLE_CALLBACK_TELEMETRY=0" bash packages/segno_engine/src/test/run_native_tests.sh
- No public API, FFI, snapshot field or Dart production change; bindings unchanged. | verify: git diff --stat origin/claude/manifest-failure-1144 -- packages/segno_engine/lib packages/segno_engine/src/core/segno_engine_api.h
NON-GOALS:
- Overdub-pass write-trajectory reconstruction, multi-lane offline rendering, Stop replay for snapshot-provenance tracks, reopen, Reverse, UI.
VERIFICATION COMMAND: bash packages/segno_engine/src/test/run_native_tests.sh
```

### Part 2: staging gaps and capacity reporting (about 90 production lines)

Files: `engine_commands.c:535-546` (gate, `frames`), `:592-597` (pass `evt->evt.frames`), `:4260-4275` (event pop before drain stop), `engine_process.c:1490-1504` (`frames` in the event), `lockfree_ring.h:69-72` and `perf_log_ring.h:193` (`evt` arm), `engine.c:346-348` (pop before `DEVICE_CHANGED` stop; with #1158, inside `le_engine_quiesce_workers`), `perf_drain.c:1252-1262` (`log_overruns`), `perf_render.c:339-460` (parse), `:978-1055` (ordered kind-0 matching), `:1545-1653` (fail all stems on log overruns), format doc.

Tests: `test_staging_last_block_retire_before_disarm` (pass retires in the final armed block; file present, stem renders it), `test_staging_retire_after_racing_clear` (image staged with `frames` from the event; frozen predecessor peel renders exactly), `test_staging_device_change_flushes_queued_retire` (configure with a queued retire; manifest lists it; sidecar `device_changed`), `test_render_ordered_key_matching` (synthetic manifest with two entries sharing `(channel, slot, generation)`; stem uses them in order), `test_render_log_overruns_fail_all_stems` (synthetic sidecar `log_overruns: 1`), `test_perf_layer_no_staging_when_unarmed` (`test_engine_core.c:11893`) still passes with `drain == NULL`.

```success-criteria
GOAL: Every logged retire has its staged image on disk, retires are matched in order, and every capacity failure a stem depends on is visible to the renderer.
SUCCESS CRITERIA:
- A retire logged in the last block before disarm, after a racing Clear, or before a device change is staged and listed; the renderer uses it. | verify: bash packages/segno_engine/src/test/run_native_tests.sh
- Repeated (channel, slot, generation) keys resolve in manifest order. | verify: bash packages/segno_engine/src/test/run_native_tests.sh
- A capture with log overruns reports `log_overruns` and renders no successful stem; master.pcm is complete. | verify: EXTRA_CFLAGS="-fsanitize=address -fno-omit-frame-pointer -g" bash packages/segno_engine/src/test/run_native_tests.sh && EXTRA_CFLAGS="-DLE_CALLBACK_TELEMETRY=0" bash packages/segno_engine/src/test/run_native_tests.sh
NON-GOALS:
- Parked retires lost to a full event ring at Clear (G5); queued restoration mutes on a refused push (G6).
VERIFICATION COMMAND: bash packages/segno_engine/src/test/run_native_tests.sh
```

### Part 3: production manifest handoff proof and documentation (no production lines expected)

Files: new `packages/performance_repository/test/history_replay_native_test.dart` (fuzz-tagged, self-skips without `SEGNO_ENGINE_LIB`, pattern `packages/segno_engine/test/render_failure_flag_test.dart:1-33` and `packages/looper_repository/test/fade_native_test.dart:13-15`; the existing `packages/performance_repository/test/helpers/native_capture_fixture.dart` is the preferred fixture pattern, E7), `.github/workflows/main.yaml:324-365` (run it in the `fuzz` job that builds the library), `docs/PROGRESS.md` entry. The test arms through the repository, performs layer Undo/Redo and Redo-from-empty against the real engine, disarms and finalizes, asserts the finalized `performance.json` keeps `kind: 1` entries and `layer_overruns`/`log_overruns` verbatim (`packages/performance_repository/lib/src/models/performance_manifest.dart:678-690`), and that `renderPoll` reports `failed == false` with the expected stems, and `failed == true` after deleting one image. If `PerformanceLayerEntry` (`:535-580`) needs `kind`/`restoreId` for an assertion, add the two fields only then.

```success-criteria
GOAL: The repository handoff preserves image provenance end to end and reports partial renders truthfully.
SUCCESS CRITERIA:
- Native-backed repository journey passes against a freshly built library; analyzer and format are clean. | verify: SEGNO_ENGINE_LIB=$(bash packages/segno_engine/tool/build_test_lib.sh) /Users/Tomas/development/flutter/bin/flutter test packages/performance_repository/test/history_replay_native_test.dart && dart analyze --fatal-infos packages/performance_repository
- Package suites without the library still pass (self-skip). | verify: (cd packages/performance_repository && /Users/Tomas/development/flutter/bin/flutter test)
NON-GOALS:
- New Dart owner, model schema, or banner wording.
VERIFICATION COMMAND: SEGNO_ENGINE_LIB=$(bash packages/segno_engine/tool/build_test_lib.sh) /Users/Tomas/development/flutter/bin/flutter test packages/performance_repository/test/history_replay_native_test.dart
```

Part 2 depends on Part 1 (the version-6 bump). If Part 2 must land first, it carries the bump and Part 1 adds no further bump (E4). Part 3 follows Part 1. Each part runs normal, ASAN and telemetry-off native suites, `dart analyze --fatal-infos`, and independent architecture, test and adversarial review before the human merge gate.

## 8. Required proof mapped to tests

| Issue proof item | Tests |
|---|---|
| Patterned audio with multiple distinguishable layers; literal samples and phase after Undo/Redo | `test_history_undo_redo_literal_parity`, `test_history_stopped_swap_then_play` |
| Clear/Undo followed by layer Undo/Redo and Stop/Play | `test_history_undo_redo_literal_parity` (restore first), `test_fade_restore_history_replacement` (parity oracle) |
| Recovery from empty and multiple operations admitted before a callback | `test_history_redo_from_empty_parity`, `test_history_batch_before_callback`, `test_history_restore_then_empty_same_block` |
| Exact capture namespace through arm/disarm/rearm; capacity, missing-image and write failures never report stale audio | `test_history_capture_namespace`, `test_history_staging_refusal_fails_stem_keeps_undo`, `test_history_missing_image_and_manifest_full`, `test_history_import_during_capture_fails_truthfully`, existing write-failure legs of `test_fade_restore_capture_lifetime`, `test_render_log_overruns_fail_all_stems` |
| Current native matrix, production manifest handoff, independent reviews | run_native_tests normal/ASAN/telemetry-off; Part 3 Dart journey; reviews per part |

## 9. Decisions under the owner rules

- D1 (rule 4): reuse `kind 1`/`restore_id`/`restore-*.pcm` and codes 322/323 for all applied images instead of a new kind or new codes; rename only code identifiers. Rule 1: existing sidecars and logs parse unchanged.
- D2 (rules 2, 5): a slot made live without a staged image (loop-close restoration, import during capture, any unknown path) logs `323/0` and fails that stem. This turns today's stale successes for those paths into reported Partial renders; not silent (rule 3), master untouched.
- D3 (rule 4): stage a fresh image at every admission rather than tracking slot-content invalidation to reuse earlier images; cost is one loop-length copy per lane per press, the same as a retire. Each admission copies `len × lanes × 4` bytes on the control thread and writes the same to disk (a 30 s stereo-lane loop is about 11.5 MB per press); disk growth, not capacity, is the ordinary-use cost (E6). Capacity itself is not a routine risk: the staging ring is `LE_MAX_TRACKS × 256` entries drained every 10 ms, the manifest is 2048 per capture, and the fastest consumer remains one retire per overdub pass, unchanged by this plan; "fail the stem" is acceptable. Unreferenced images stay under the existing drain cleanup owner.
- D4 (rule 2): overdub or record on an image-sourced track keeps ending the source with `323/0` (accepted in the #1142 amendment); kind-0 behavior for snapshot-provenance tracks is unchanged.
- D5 (rule 1): staging refusal never refuses Undo/Redo; the musical operation and its history stay exactly as today.
- D6 (rules 2, 5): log overruns become visible and fail every stem of the capture; the master is reported complete.
- D7 (rule 4): no Dart production change; the manifest passes native fields verbatim (`packages/performance_repository/lib/src/models/performance_manifest.dart:684-690`).
- D8 (rule 1): at a mid-capture reopen the capture ends `device_changed` as it does on configure today; no attempt to continue a capture across devices.
- D9 (rule 3): `LE_CMD_UNDO_TO_EMPTY` is logged raw in addition to 304 rather than changing 304's meaning.

## 10. Findings outside this plan (no product-direction question identified)

- Kind-0 retired images are pre-pass images: `le_dub_boundary`/drain retire the backup-on-write shadow (`engine_process.c:5595-5601`, `:1627-1634`, `engine_private.h:920`), while the renderer activates the retired image as new content at the retire frame (`perf_render.c:1017-1046`) and the part-7 plan describes a post-pass image (`docs/plan/2026-07-05-feat-performance-recording-daw-export-part-7-plan.md:26-31`). No real-engine test renders an overdubbed stem (`test_perf_render_overdub_stitching` writes a synthetic post-pass file, `test_engine_core.c:18918-18931`). Overdubbed stems therefore do not contain the pass. This plan's proofs arm after layers exist so the result does not depend on it; filed as #1169.
- The dry render does not model `LE_CMD_STOP` for snapshot-provenance tracks (no handler in `perf_render.c`; only `LE_CMD_CUT_SOUND` silences, `:1360-1366`); image-sourced segments do, via 323. Filed as #1170.
- A restore admitted before `le_perf_arm` and applied in the same block as `PERF_ARM` has neither snapshot nor fact provenance (pre-existing; `engine_process.c:2895`).

## 11. Budget and review ceiling

Production additions per part stay under 700 lines (estimates: 220, 90, 0). Stop for review on any new public function, FFI change, Session schema, second history ledger or Dart owner. Tests, bindings and documentation are counted separately. Independent architecture, test-quality and adversarial reviews precede each part's publication; actual Claude review, published-head CI and the human merge gate remain separate.

## 12. Part 1 build record

Review edits E1-E8 are applied in the text above. The build departed from the amended text in these places, each checked against the code:

- **E2, application boundary.** The review's premise ("`buf[t][l]` is loaded once per block, before the per-frame loop") does not hold: `mix_tracks_frame` takes the frame index `f` as a parameter and is called from `le_engine_process`'s `for (uint32_t f = 0; f < frames; ++f)` loop (`engine_process.c:6252`, `:6302`), so the `a_live` load at `:5287-5291` is per frame. Making it once per block would have changed when the production mixer applies a control-side swap (deferring a mid-block publish to the next block), a product change outside this issue. The built rule keeps the review's intent at the granularity the mixer actually has: one acquire load of lane 0's `a_live` per frame per track (idle tracks included), shared by the mixer and the tracker through `live_idx[t]`, replacing the relaxed lane-0 load. The 128-frame block leg is kept as a block-boundary placement check (a swap admitted between blocks lands on the block's first frame under either design); the leg that discriminates the two is `test_history_mid_block_swap_frame`, which admits the swap from the stage-5 test hook at frame `f` of a 128-frame block, after that frame's live-slot loads, and asserts the fact at `block_start + f + 1`, where a per-block load would place it at the next block start (PR #1173 review, finding 3).
- **Rule 3 extension.** With the lookup moved from the restore handler to the first PLAYING/STOPPED frame, a restore (or Redo-from-empty, or layer swap) followed by Record in the same block would have produced no fact at all, and the existing `test_fade_restore_overdub_source_end` `before_first_sample` leg would have reported stale success. Rule 3 therefore also logs `323/0` when the slot changed under RECORDING/OVERDUBBING and the new slot's table entry is nonzero (a staged image overwritten before it was ever mixed). A fresh take from EMPTY is unaffected: `le_begin_empty_capture` zeroes the row (E3), so its entry is 0 and no fact is logged.
- **`test_fade_restore_source_end_edges`.** The plan said to keep its failing legs where provenance is genuinely absent and flip the racing-swap leg to parity. Neither leg has absent provenance after this change: the racing-swap leg mixes the staged Undo target in the frame the mid-frame Redo was admitted (the Redo takes effect at the next frame, which never comes), and the undo-to-empty leg is exact silence from its raw 39 (G7). Both legs now assert parity.
- **`test_history_restore_then_empty_same_block` (G7).** With only a never-mixed restore and an emptying on the channel, the renderer has nothing to collect (no 322/323 fact, no snapshot entry) and produces no stem for it, which is correct but asserts nothing. The test follows with a Redo-from-empty so the channel is collected: the stem renders silence then the staged image, with one 322 (the Redo's), one raw 39 and the unreferenced restore image listed.
- **`test_perf_layer_persists_through_redo_invalidation`.** Its manifest count of 2 counted kind-0 retires only; the layer Undo in it now stages a kind-1 image between them. The oracle is 3 entries with `restore-0-1.pcm` present, and the retire checks address entries 0 and 2.
- **`le_publish_live_image` placement.** Defined as a static inline in `engine_core.h` (next to `le_track_publish_live`) rather than in `engine_commands.c`, because E3 requires `engine_session.c` to publish through it. `le_forget_slot_images` sits beside it.
- **Arm window (PR #1173 review, finding 1).** A swap admitted after `le_perf_arm` returned and before the callback applied `LE_CMD_PERF_ARM` stages its image (the drain exists) but the handler adopted the already-swapped `a_live` as snapshot provenance, so no fact was logged and the arm image (exported before `perfArm`) rendered as success. The handler now acquire-loads `a_live` and leaves the track unresolved (`perf_source_slot = -1`) when the live slot's table entry is nonzero, so rule 1 logs 322 at capture frame 0; any nonzero entry at that point was staged after the arm's row zero, so it is this capture's. `test_history_arm_window_swap` fails without it. The sub-window before `le_perf_arm` (section 10, pre-existing) is a repository ordering question, not this part's.
- **Lane order (finding 2).** `le_track_publish_live` now stores lanes `n..1` before lane 0 (release on each), so no lane can still mix the previous slot in the frame lane 0's fact names; a lane `k >= 1` may still mix the new slot one frame before the fact. The fact is exact for lane 0, which is all the lane-0 renderer consumes; the format doc records the lane `1..n` tolerance for a future multi-lane renderer.
- **Production size.** the production diff over `packages/segno_engine/src/core` adds about 255 lines and removes 81, comments included; within the estimate.
- **Fail-without-fix evidence.** Recorded in the PR description from a run of the new test file against the base production sources (`origin/claude/manifest-failure-1144`): the parity, G7, batch, namespace, missing-image and import legs fail there, and the refusal legs fail because no `323/0` is logged for a snapshot-provenance track.

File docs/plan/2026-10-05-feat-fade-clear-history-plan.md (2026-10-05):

# Restore stationary Fade amounts through Clear history

Tracking: #1142, parent #1026, human merge gate. Implementation is authorized
within this reviewed scope. Independent review and publication gates remain.
Base is published
`c2e1d728293e2db03848362d6027cbc84692c468` (#1141). Scope excludes #1140 reopen.

## Outcome and boundary

Clear/Clear All reset removed material to unity. Undo restores each affected
track's coefficient **at the native Clear application boundary**, stationary
(amount=target, seconds=0), before restored playback can sound. Ordinary Fade/time
edits add no audio-history entry and retain Redo. Ordinary Undo-to-empty and Redo
from empty never resurrect an old moving Fade. Existing gain, duration, FX,
per-track/group history, transport and later independent edits retain their rules.

Implement ordinary, frozen-capture and grouped Clear together. One is a complete
vertical increment; shipping only ordinary Clear would leave the same action
incorrect for captured/grouped material. No Fade UI, Session schema change,
coefficient persistence owner, resampling or device-loss policy is included.

## Source binding and resolved mechanism

The original source analysis uses immutable c2e1. Its native tree is
`6f6d86e5ef4844a04585a32e1a7d1357bd368134`, identical to a921. The accepted
contracts are the parent Fade plan and Part 2. The captured-restoration amendment
below records the additional requirements found during implementation review.

The current ordinary point is filed control-side (`engine_commands.c`,
`le_build_restore_point`, `le_finish_clear`), before callback Clear. Frozen Clear
instead waits for `LE_EVT_CLEAR_FROZEN`; that event is currently discarded on a
full event ring. Neither a pre-post Fade snapshot nor extending that lossy event
is acceptable. Use **one bounded, latched native Clear-completion mailbox per
track**, replacing frozen event delivery and also serving ordinary Clear.

Keep ordinary restore points filed synchronously and keep
`clear_restore_pending` **frozen-only**. Making ordinary Clear pending would
change LooperRepository._clearTrack's existing pending→frozen/muted=false
interpretation. Avoid that regression and any extra ordinary candidate/cache.

Mailbox protocol (private to native, no generic abstraction):

1. Add atomic sequence plus atomic tuple fields for Clear operation tag, captured
   Fade amount bits, finalized length and master length. Reuse the local SC
   sequence/atomic-field bounded-copy pattern in `engine_snapshot.c:21–67`.
   Plain payload fields under a sequence guard still race in C and are forbidden.
   One bounded incoherent read returns not-ready; no spin, locks or allocation.
2. `handle_clear` samples Fade amount into a local before any finalize/reset.
   After finalization it has frozen length/grid, including zero-length void
   capture. At the end of Clear, publish the tuple and then the existing
   state-ack release. Thus collectors require both coherent identity and the
   corresponding Clear acknowledgement before exposing completed recovery.
3. Tag by the existing Clear/dub operation generation, not the Fade material
   generation observed before posting. A queued restore→Clear has effective
   content while the wire remains EMPTY; its callback amount belongs to the
   restored material that actually exists when Clear executes.
4. Add exact operation tag, amount and amount-ready to `LE_HIST_CLEAR` metadata.
   Ordinary entries start not-ready; completed mailbox data attaches only to
   the matching top CLEAR entry. Frozen entries are completed using the current
   pending slot/generation and callback length/grid, with STOPPED/unmuted rules
   unchanged. Do not write control-owned stacks from callback or pass pointers
   to movable entries. Layer entries leave these extra fields zero/unused.
5. Keep publication latched. If callback runs between post and `le_finish_clear`,
   a drain that cannot yet find the matching entry must leave the image available
   for the next drain. Match current identity and committed control bookkeeping;
   never re-arm a pending point already completed by an interleaved drain.
6. Removing the event removes its FIFO relation with preceding retired layers.
   After acquiring ready mailbox data, drain the preceding event-ring retirement
   reports **before** filing a frozen point, then revalidate pending identity.
   A drain performed only before acquiring readiness is insufficient. Implement
   this within existing `le_engine_drain_events`, not recursive public API calls.
7. Keep `history_mode_gate` read-only. After its existing Clear-ack acquire,
   `le_restore_clear` must collect/revalidate again and require amount-ready
   before copying the entry or queuing mutes/restore. This closes drain-before-ack
   races. Not-ready returns the existing refusal; no default unity or history pop.
   Existing frozen pending queries/drains and grouped deferred Undo remain intact.

A one-slot mailbox is sufficient: another accepted Clear supersedes old pending
recovery; Clear while effectively EMPTY drops the ordinary point; Undo moves CLEAR
to Redo and the next Clear drops that Redo; fresh capture drops erased history.
No live old point needs a report after a newer Clear on that channel. Atomic
payload ownership makes overwrite race-free even if control is reading. Prove
these schedules; do not rely on that argument without regression coverage.

## Dependency-ordered implementation

1. **Metadata and reliable completion.** In `engine_private.h`, extend the existing
   history entry and track-private mailbox; initialize all added fields in
   `engine.c` configure while callback/workers are quiescent. Adapt Clear capture,
   completion and reset retirement in `engine_process.c` and `engine_commands.c`.
   Preserve push-before-bookkeeping: command-ring refusal changes no history,
   coefficient or pending ownership. Full **event** ring cannot lose accepted
   Clear completion. Raw/internal/destructive Clear keeps its existing semantics;
   ignored mailbox images do not create recovery for raw Clear.
2. **Stationary restoration.** Extend existing `LE_CMD_RESTORE_CLEAR` payload in
   `lockfree_ring.h` with amount. Apply it before publishing restored transport or
   producing any sample; set amount=target with zero full-travel seconds and emit
   existing `LE_PLOG_FADE`. Playback phase follows native restoration semantics. Never restore old generation/lifetime. Keep Clear/New Loop/
   empty-refill fencing and ordinary nonempty layer Undo/Redo behavior unchanged.
   Re-clear after an independent Fade edit captures the newer actual amount.
3. **Remove obsolete event path.** Remove `LE_EVT_CLEAR_FROZEN=102` delivery,
   dispatch and unused frozen payload fields, including internal log-copy members
   only if unused. All surviving command/event numeric values must remain exactly
   unchanged. Existing Fade fact 321 reconstructs the coefficient; applied
   restored-material and state/phase facts 322/323 identify the audio it affects.
   These use the fixed 16-byte payload and event-log version 5, as described in
   the approved captured-restoration amendment.
   The enum lives in `segno_engine_api.h`; regenerate FFI and format the generated
   bindings, allowing only that obsolete constant deletion. Add no public
   function or snapshot field; escalate if needed instead of widening silently.
4. **Composed behavior and tests.** Extend `test_engine_fade.h` and the relevant
   existing ordinary/frozen/history fixtures in `test_engine_core.c`. Update the
   old test that pops/reinserts a frozen event to hold/inject a tagged mailbox
   completion through test-only seams, preserving its stale-report oracle.
   Add a small real-native repository group journey in existing
   `packages/looper_repository/test/fade_native_test.dart` or the existing history
   test file. Prefer no Dart production changes: native query contracts remain.

## Required observable oracles

- **Applied amount:** retain earlier published .75 while callback-owned amount
  becomes .5 before Clear consumption. Undo gives stationary .5, and known .5 PCM
  produces literal .25 at its first restored sample; no unity sample or old ramp.
- **Post-before-finish:** force callback Clear between command posting and control
  bookkeeping completion. Ordinary and frozen reports attach once to the correct
  point; no stuck pending or lost amount. Queued restore→Clear captures the amount
  after restore, not the earlier EMPTY/unity wire image.
- **Ring pressure:** fill evt_ring with valid benign reports, apply ordinary and
  frozen Clear, drain, Undo and verify PCM/amount/history. Saturate command ring:
  refused Clear leaves all state unchanged and later retry works. Delayed
  mailbox read across overwrite must yield a coherent matching tuple or refusal.
  This proves reliable Clear completion, not lossless unrelated layer/performance
  events when their existing event ring is saturated.
- **Frozen:** non-unity overdub Clear captures exact boundary, restores STOPPED
  with original layer/window semantics; early Undo follows existing pending
  behavior. Zero-frame initial capture remains void. Preceding layer retirement
  remains below CLEAR, so the next Undo still peels that layer.
- **Group/mute:** mixed playing, stopped/muted, frozen and empty/armed members
  restore their own .25/.6 amounts through one group action. Ordinary mute stays
  muted in engine/repository/persistence; frozen capture remains unmuted. Preserve
  group order, gain/FX/duration changes and existing partial-refusal semantics.
- **Lifecycle/history:** layer Undo/Redo keeps live Fade and Redo; Undo-to-empty and
  new capture reset runtime; ordinary Redo does not resume old Fade. Re-clear after
  a newer Fade edit restores the newer amount. Old tagged completion and old Fade
  requests cannot act on new recording, Session import or reset lifetime.
- **Performance:** live/restored literal output matches offline capture rendering
  using the Fade coefficient and exact restored material/state/phase facts;
  source PCM is unchanged. Test no callback allocation,
  blocking or unbounded retry; existing RT instrumentation remains valid.

## Budget, failure boundary and validation

The combined scope, including captured restoration, has a review ceiling of
500 added production lines. Count tests, generated bindings and documentation
separately. Stop for review above that ceiling, or for any new public function,
Session schema, generic mailbox framework, second history ledger, new Dart owner
or broad grouped-history rewrite. Event-log version 5 is explicitly included. Existing
pool/history limits remain; no new silent fallback from undoable to raw Clear may
be introduced. If full-history capacity prevents preserving an admitted point,
prove the existing bounded invariant or refuse before native mutation; do not
invent eviction of accepted history. This is a review checkpoint, not permission
to redesign all existing capacity handling.

Resolve dependencies before explicit formatting. Native change requires normal,
ASAN and telemetry-disabled native suites, documented C++ shim/header checks,
FFI regeneration/parity and a fresh matching library for Dart native tests.
Run focused tests first, then affected Looper ordinary coverage (95% without
native credit), matched native group tests, appropriate app Clear/Control tests,
strict analyzer, explicit format and positive Bloc. Reuse unchanged Session
capture/schema checks by source binding. Maximum two task-wide processes;
reviewers inspect evidence instead of rerunning suites. Freeze source/library
before independent architecture, test-quality, simplicity and readiness review.
Root owns remote CI, actual Claude review, publication and human merge gate.

## Success Criteria

```success-criteria
GOAL: Clear history restores each track's actual pre-clear Fade amount as stationary state without losing recovery or disturbing independent edits.

SUCCESS CRITERIA:
- Ordinary/frozen Clear and Undo preserve exact amounts, PCM/history and first audible samples under delayed callback, full event ring and refused commands. | verify: bash packages/segno_engine/src/test/run_native_tests.sh
- Grouped Clear/Undo and existing mute/transport ownership remain coherent using a fresh source-matched native library. | verify: manual inspect bound actual-native repository group/ordinary-mute/frozen-control logs and literal output assertions.
- Native lifetime, performance replay, sanitizers, telemetry-disabled, C++ and unchanged symbol/code parity pass on frozen source. | verify: manual inspect native matrix logs, generated diff and surviving command/event value comparison.
- Applicable coverage floors, formatting, strict analysis, positive Bloc and independent current-source reviews pass. | verify: manual inspect source-bound local readiness evidence; retain remote CI and human merge gate.

NON-GOALS:
- Reopen/material retention or resampling (#1140), UI/mappings, duration settings, new Session schema, generic recovery framework or new public API.

VERIFICATION COMMAND: bash packages/segno_engine/src/test/run_native_tests.sh
```

## Approved implementation amendment: captured restoration

The original capture-across-Clear oracle exposed missing dry-source restoration
in offline rendering. Keep that oracle and repair its provenance in the existing
performance staging, drain and rendering owners. Do not move capture arm after
Undo or interpret generic Undo records as restoration. Root approved this
bounded amendment on issue #1142; the combined production-addition review ceiling
is now 500 lines, with tests, generated bindings and documentation counted
separately.

- Stage an immutable copy of the exact retained PCM on the control thread before
  restoration admission. Reuse the existing layer staging ring and disk owner;
  distinguish restored images by explicit kind and unique nonzero capture-local
  image ID. Preserve all active lanes in the file. Offline parity remains scoped
  to the existing lane-0 renderer. No new recorder, queue or callback allocation.
- Publish a typed applied restoration fact with channel, image ID, state and
  phase in the existing fixed 16-byte log payload. Read the resolved first-sample
  coordinate at the existing mixer boundary; do not duplicate mode math or use
  the previous block's playhead. Subsequent state/phase facts apply only to that
  restored image until Clear or replacement material retires it.
- Staging ownership includes a successfully queued PERF_ARM before its callback
  publishes armed. Never produce a successful armed restoration with image ID
  zero or missing provenance. Preserve joined disarm/rearm namespaces and prove
  callback completion between restoration posting and live-slot publication.
- Preserve the new metadata through native sidecar and real repository manifest
  finalization. Match kind/channel/ID exactly, validate lane/frame bounds and
  exact file size, and fail the affected stem on missing/truncated material or
  segment capacity exhaustion. Reuse existing incomplete/overrun reporting for
  copy, queue, ID, disk or manifest failure; capture failure must not refuse an
  otherwise valid musical Undo. A refused restore keeps history unchanged and
  may leave an unreferenced staged image under the existing cleanup owner.
- Validate moving and stationary literal PCM across Clear/Undo, patterned
  nonzero phase with a surviving grid, STOPPED restore and later Stop/Play,
  frozen partial capture, repeated/grouped restores, missing material, capacity
  and capture-lifetime schedules. Generic duplicate Undo records and ordinary
  layer history must not activate this typed path. General history/transport,
  multi-lane offline rendering, monitors/plugins and engine reopen remain out
  of scope; stop for review if they become dependencies.

Two related bounded corrections are included: the existing repository Clear
snapshot must include mute-only lanes, and a pending frozen Clear may retain
only its immediately preceding retirement generation. Pending frozen Clear must
not replenish new shadow slots. After its mailbox readiness acquire, drain those
retirements before clearing pending or filing CLEAR; fresh capture or superseding
Clear removes this permission. Prove exact PCM/layer order and stale rejection.

General layer-history reconstruction is tracked separately in #1143. A supported
same-span layer or processed-material swap, Undo to empty, or new overdub after
restored Clear explicitly ends unsupported source provenance and fails the
affected derived stem; the independently recorded master remains usable.
This limitation must not be reported as a storage or queue overrun.

Arm snapshots retain metadata-only empty lanes (including gain, mute, pan,
routing and effects) without exporting PCM. Applied restoration facts discover
stems absent from both snapshots; empty arm metadata alone creates no stem.
This uses the existing PerformanceRepository snapshot owner and model fields.

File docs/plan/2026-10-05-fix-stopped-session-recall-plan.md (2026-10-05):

# Stopped Session recall prerequisite

Tracking: #1134, stage:build, autonomy:merge-gate. Prerequisite for the
[durable Fade slice](2026-10-04-feat-foot-fade-part-2-plan.md); no merge authority.

Session recall must establish imported tracks stopped while the device callback
continues processing. The current native commit starts playback before mix/FX
restore finishes, and the later boot-settings barrier only prevents device
restart. Change the existing commit contract to STOPPED and extend the existing
repository Session admission predicate through boot persistence. Reuse the current
Play command, Session block and failure/retry owners; add no transport option.

Before disarm, storage writes or destructive mutation, refuse audio-bearing loads
without a processing device. Preserve empty/settings-only loads. On accepted
loads, keep controls blocked through complete boot persistence and bindings;
release on success, retain on boot failure, and cancel the block when apply fails.

Files: native Session commit and API documentation; AudioEngine documentation and
generated bindings; LooperRepository preflight/reservation/confirmation;
SessionCubit preflight/block lifetime; corresponding fakes and behavior tests.
Performance render reconstructs material directly and has no import/commit caller.

Verify real native silent recall and first explicit-play PCM, loaded master/grid,
callback publication and cleanup failures, boot-storage delay/failure/retry,
unavailable-device refusal before side effects, and settings-only restore.
Update fixtures that intentionally need playing material with explicit Play;
do not weaken PCM or phase assertions. Run applicable native normal/ASAN/
telemetry-disabled, C++ shim, FFI generation/symbol parity, Dart tests/coverage,
strict analyzer, formatter and positive Bloc lint. Freeze after focused checks
before independent review and aggregate validation. No Fade duration, reconnect,
Clear-history, UI, deployment or device-validation work belongs to this slice.

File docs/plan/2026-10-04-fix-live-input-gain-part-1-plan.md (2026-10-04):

# Correct shared live-input gain

Issue #1124, a prerequisite of the Foot Mixer journey in #1123, human merge
gate. Base: the published Count-in mappings. This correction improves existing
controls and restoration before adding a new performance mode.

## Accepted behavior

Live-input volume ranges from silence to unity (0–100%), independently of
capture trim. A normalized mapping position of 0, 0.5 or 1 means exactly
0%, 50% or 100% live gain. Tracks and recorded lanes retain their existing
0–200% logarithmic fader conversion. This corrects the October 1 implementation
plan's inclusion of live inputs in the recorded-track gain law: the current
accepted prototype and September 7 Mixer decision both specify input unity as
the ceiling. It does not introduce a separate Foot Mixer range.

## Implementation

1. Separate `MonitorVolumeTarget` in
   `lib/control/binding/control_value_target.dart` from recorded gain conversion.
   Update the scope comment in `mix_value_scale.dart`; keep its recorded law.
   Retain existing mapping identity and the existing source interpreter.
2. Correct ordinary gain admission in `lib/app/mix_settings_coordinator.dart`
   and the repository's monitor-gain boundary. Constrain any actual input gain
   editor to the same range. Input percent readout must report the resulting
   gain. Do not change track/lane dB readouts or capture trim.
3. Trace monitor levels through `MixSettingsSnapshot`, Settings restore,
   `MonitorCubit` and Session decoding/restoration. Unsupported saved gain must
   follow an explicit existing invalid-data/error path before any partial rig
   mutation. Settings decoding rejects bad data with FormatException during
   the all-input read phase; writing uses its ordinary invalid-value outcome.
   Observe Monitor startup load failures so the startup future cannot leak an error.
   Validate SessionMonitor decoding and direct SessionRig application before
   mutation. Session load reads and validates its candidate before disarming
   an active performance recording. Do not silently migrate, clamp old state
   on page entry, or retain an obsolete interpretation. Keep native engine
   capacity unchanged.
4. Update focused tests with literal expected monitor values. Existing scenarios
   that intentionally relied on >100% monitor gain are changed explicitly to
   legal scenario values; tests protecting other gain domains remain intact.

No new owners, timers, persistence queues, target versions, feature destinations,
packages or native DSP changes belong in this part. The existing application
remains fully usable after this correction without the new Mixer mode.

## Verification

Test forward/reversed endpoints, absolute/relative sources, simultaneous held
sources, ordinary edits at unity, durable Released projection, unavailable
inputs, failed writes and save/reload. Reject non-finite/out-of-range stored
monitor values without affecting accepted track/lane gains or the active session.
Add narrow existing-suite cases for every changed admission boundary. Compare
actual native monitoring and capture samples where existing bound evidence does
not already cover the exact path. Root runs the affected package suites and
application aggregate once the source is frozen, then analysis, explicit-path
formatting and positively scanned Bloc lint. Independent review covers the final
source; actual Claude review and current-head CI remain required before readiness.

## Success Criteria

```success-criteria
GOAL: Every existing live-input volume path uses the accepted 0–100% range without changing recorded-track gain or capture audio.

SUCCESS CRITERIA:
- Monitor mappings produce literal silence, half gain and unity; track and lane laws remain unchanged. | verify: flutter test test/control/binding/control_value_target_test.dart
- Ordinary edits, holders and persistence use the same accepted input range. | verify: flutter test test/app/mix_settings_coordinator_test.dart test/audio_setup/cubit/monitor_cubit_test.dart
- Invalid saved monitor gains are rejected before partial restoration; valid Session and Settings values round-trip. | verify: flutter test test/session
- Changed app and package code passes strict analysis and Bloc lint. | verify: dart analyze --fatal-infos lib test packages && bloc lint lib test packages

NON-GOALS:
- Foot Mixer navigation, gesture changes, native gain-capacity changes, migration/compatibility, deployment or merging.

VERIFICATION COMMAND: flutter test test/control/binding/control_value_target_test.dart test/app/mix_settings_coordinator_test.dart test/audio_setup/cubit/monitor_cubit_test.dart test/session && dart analyze --fatal-infos lib test packages && bloc lint lib test packages
```

Commands are obligations, not evidence of execution. The final report records
all affected package/native checks and actual results, including skips and
hardware limits. Use the repository's documented SDK and worktree lint wrapper.

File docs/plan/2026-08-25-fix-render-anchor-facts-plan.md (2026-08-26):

---
title: "fix(render): explicit anchors — the PERF_ARM transport fact (#262) and the disarm-image take identity (#819)"
type: fix
date: 2026-08-25
issue: 262
---

# Render anchoring: replace two inferences with two facts (#262 + #819)

One design, two issues. The performance render places audio on the capture
timeline using **two inferred anchors**, and both inferences are wrong in the
same way: the data that would make them exact exists in the engine at a
precise audio-thread instant, and the capture simply never records it.

- **#262** — the arm-image anchor. `perf_render.c` anchors a track that was
  already playing at arm time at `armSnapshot.clockFrame`, indexing
  `(clockFrame + f) % image_len` (`le_pr_render_track`, the arm-image
  segment). But `clockFrame` is sampled **control-side** —
  `PerformanceRepository.arm()` reads `snapshot.masterPositionFrames`
  (`packages/performance_repository/lib/src/performance_repository.dart:304`)
  — *before* lane WAV export and manifest I/O, while capture frame 0 begins
  only when `LE_CMD_PERF_ARM` reaches the audio thread
  (`engine_process.c:2514`), an unbounded I/O gap later. The renderer's own
  comment marks this "KNOWN RESIDUAL (#262) … render-side, this is as good
  as the data gets."
- **#819** — the disarm-image anchor. The same function places
  `disarmSnapshot`'s lane-0 image at "the **first** `LE_PLOG_RECORD_END` on
  this channel while `build.has_content` is still false" — ordinal position
  plus a content flag, not an identity. #816 made the rule *currently* true
  by routing void takes to `LE_PLOG_RECORD_ABORT`, but any future finalize
  path that logs an END before content exists re-breaks #264 silently.

Fixing them together is right because they are the same shape: an
engine-side fact logged at the exact audio-thread frame, versioned into
`events.log` / `performance.json`, preferred by the renderer over the
inference.

## Killing one premise first

Issue #819 says "`perf_drain.c` writes it at disarm." **It does not.**
`disarmSnapshot` is written Dart-side: `PerformanceRepository._finalizeArmed`
builds it from `_captureSettledLanes` (`performance_repository.dart:404-411`,
`:900-966`), which reads the engine snapshot and exports each settled lane's
PCM via `_engine.exportTrackLane`. `perf_drain.c` writes `events.log`, the
master/monitor rings, and layer segments — never the manifest. The
consequence is real, not pedantic: **the take identity must cross the FFI
boundary** (engine → `le_snapshot` → Dart → `performance.json`), it cannot be
written by the drain thread as the issue implies. That determines the seams
below.

## Current state, verified

- `LE_CMD_PERF_ARM`'s audio-thread application (`engine_process.c:2514`) is
  zero-payload: reset callback telemetry, set `e->perf.armed = 1`, store the
  atomic. Nothing is logged; the loop clock's position at that instant —
  `e->clock.position`, sitting right there — is discarded.
- The event-log vocabulary is versioned (`docs/design/performance-event-log-format.md`,
  header `version`, currently `2`; the doc's own table shows version 1→2 was
  exactly this kind of vocabulary change, for #264).
- `le_pr_record_end_phase` (`perf_render.c:600-680`) already reconstructs a
  fresh take's phase from `RECORD_START` + `LOOP_LENGTH_LOCKED` facts, and
  falls back to `arm_clock_frame` when no lock happened inside the capture —
  so #262's staleness contaminates the RECORD_END phase math too, not just
  the arm image. One fact fixes both consumers.
- The perf-log entry payload is `le_command` (`perf_log_ring.h`), whose `fx`
  arm carries four `int32`s — room for a fact carrying more than
  `arg_i`/`arg_f`.
- The mid-capture transport hold (`engine_process.c:3213`: playback with
  nothing active pins `clock.position = 0`) is unlogged — the sibling
  unlogged-phase-reset #262's issue text flags.

## Decisions for the owner

### Decision A — what the PERF_ARM fact carries (#262)

A new transport fact, `LE_PLOG_PERF_ARMED` (315), pushed inside the
`LE_CMD_PERF_ARM` case at the capture's frame 0.

- **Option a — position only** (`arg_i = clock.position`). Fixes the arm
  image's rotation. Leaves the multi-loop sub-cycle ambiguity (#260) and a
  master-length change in the arm gap unrepresented.
- **Option b — position + master length + loop iteration (recommended),**
  via the `fx` arm's four ints (or two adjacent generic entries if that
  reads better in the format doc). Same cost, and it retires the #260
  sub-cycle ambiguity and the stale `masterLenFrames` in one move — the
  renderer then needs *nothing* from `armSnapshot` for phase math.

**Recommendation: option b.**

### Decision B — whether to log the transport hold

- **Option a — log it (recommended):** a `LE_PLOG_TRANSPORT_HELD` fact when
  the hold pins the clock, so the renderer's phase math can't silently run a
  clock the engine had frozen. Cheap, and it closes the last unlogged
  phase-reset.
- **Option b — defer.** Defensible only if renders never span a
  hold-then-resume; nothing guarantees that.

### Decision C — the take identity (#819)

- **Option a — monotonic per-channel take id (recommended).** Engine keeps a
  per-track counter bumped at each `RECORD_START`; `RECORD_END` logs it
  (move 301's payload to a two-int arm: channel + take id); `le_snapshot`
  exposes each track's *settled take id*; `_captureSettledLanes` writes it
  on the lane-0 entry as `takeId`; `le_pr_render_track` anchors the disarm
  image at the `RECORD_END` whose id matches. Identity survives any future
  finalize path by construction.
- **Option b — finalize frame as the identity.** No counter, but it is still
  a *rendezvous by value*: Dart must read "the frame lane 0 last finalized
  at" from the snapshot, and two ends at the same frame (channel-adjacent
  edge cases) collapse. Weaker for no real saving.

**Recommendation: option a.**

### Decision D — compatibility posture

`AGENTS.md` is explicit: no compatibility layers, fallbacks, or migrations.
But #262's issue text asks that "old captures without it must keep rendering
(fallback to clockFrame)."

- **Option a — follow AGENTS.md (recommended):** bump `events.log` header to
  version 3; the renderer *requires* the PERF_ARMED fact and the take id and
  the `!has_content` proxy is deleted, not kept as a fallback. Pre-upgrade
  unfinalized captures (the only old data the renderer ever revisits, via
  D-SALVAGE) render as well as they ever did only if re-captured; that is
  the documented one-time cost.
- **Option b — versioned fallback:** keep the clockFrame anchor and the
  first-END scan for version-2 files. Preserves salvage of old captures at
  the price of keeping the exact heuristic #819 exists to kill, forever
  testable in two forms.

**Recommendation: option a** — the format doc's version table records the
semantics change, same as version 1→2 did.

## Implementation outline

Two PRs, both `autonomy:auto` (engine + renderer, mutation-provable, narrow):

1. **PR 1 — the PERF_ARMED fact (#262):**
   - `perf_log_ring.h`: `LE_PLOG_PERF_ARMED = 315` (+ `TRANSPORT_HELD = 316`
     under decision B-a); `engine_process.c`: push at the `LE_CMD_PERF_ARM`
     case and at the hold site (`:3213`); bump the events.log header version;
     update `docs/design/performance-event-log-format.md`'s audited table.
   - `perf_render.c`: prefer the fact over `arm_clock_frame`/`arm_master_len`
     in both consumers (`le_pr_render_track`'s arm segment,
     `le_pr_record_end_phase`'s no-lock branch); delete the KNOWN RESIDUAL
     comment.
2. **PR 2 — the take identity (#819):**
   - Engine: per-track take counter; `RECORD_END` payload gains the id;
     `le_snapshot` exposes the settled take id per track (**ffigen regen
     in-PR** — the B3 heap-overflow lesson).
   - Dart: `_captureSettledLanes` writes `takeId`;
     `performance_manifest.dart` round-trips it;
     `docs/design/performance-manifest-format.md` documents it
     (presence-keyed, like the FX stages).
   - Renderer: anchor on the matching id; delete the first-END scan and the
     `!build.has_content` gate; retire the carve-out prose on 301's
     declaration.

PR 1 lands first — PR 2's fixture wants the format-version bump already in.

## Verification plan

- Native suite (`run_native_tests.sh`) + ASAN. New fixtures:
  - **#262:** arm mid-loop against a playing track with a deliberate delay
    between snapshot read and `LE_CMD_PERF_ARM` application; assert the stem
    is *not* rotated by the delay (fails against `clockFrame`, passes
    against the fact). Force the gap the way
    `test(engine): force the alloc-watch zero-fill gap` (#828) forces its
    race — deterministically, not by sleeping.
  - **#819:** the issue's own acceptance fixture — a capture where the first
    `RECORD_END` on a content-free channel is **not** the take the disarm
    image belongs to (e.g. finalize, clear, re-record within one capture)
    must render the image at the second END's frame.
- Dart: manifest round-trip tests in `performance_repository`; `dart analyze`;
  `bloc lint`.
- Mutation checks: revert the renderer to `arg_i`-from-armSnapshot / to the
  first-END scan one at a time; the new fixtures must be the tests that fail.

## Acceptance criteria

- `events.log` header version 3; `LE_PLOG_PERF_ARMED` in the audited table;
  renderer phase math consumes it in both branches.
- `performance.json` lane-0 entries carry `takeId`; the disarm image anchors
  by identity; `!build.has_content` no longer exists in `perf_render.c`.
- The #264-class regression (an END before content) is impossible by
  construction, and the fixture proving it is in the suite.
- Both issues closed by their PRs (`Closes #262` / `Closes #819`).

## Non-goals

- Re-rendering or migrating existing capture bundles.
- The #279 musical-grid export (it *consumes* the PERF_ARMED fact; planned in
  `2026-08-25-feat-bar-aligned-als-export-plan.md`).
- Any change to arm/disarm UX, D-GUARD windows, or the drain thread's
  ring/budget design.

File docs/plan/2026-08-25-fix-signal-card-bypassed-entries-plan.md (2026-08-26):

# A card reads the same whether its entries are bypassed or not (#601)

Status: **idiom options defined, one recommended; the pen drawing is the
blocker, the code change is mechanical.** Follow-up from #600, which fixed
the chain-level case (`Chain off · Drive → Tremolo`) and deliberately left
this one because there was no mockup for a per-entry marker.

## Current state (verified 2026-08-25)

- `TrackEffect.enabled` is documented as bit-exact passthrough (R16,
  `packages/looper_repository/lib/src/models/track_effect.dart:143-149`) and
  is reachable from the surface — the FX editor toggles it
  (`lib/looper/view/signal/signal_fx_editor.dart:556-558`; the issue's
  `:351` line reference has drifted, the toggle survives).
- `chainSummary` (`lib/looper/view/signal/signal_cards.dart:473`) reads only
  the chain-level `enabled` flag. Bypass both entries of `Drive → Tremolo`
  and the card still reads `Drive → Tremolo` — the same false promise #525
  was about, one level down.
- `sameChainLine` (`signal_cards.dart:521`) compares type / name+ref only,
  on purpose (its doc: a knob in an open plugin window rewrites the entry at
  poll rate). So even a corrected summary would not redraw on a bypass
  toggle until `enabled` joins the comparison — safe to add: `enabled` is a
  bool flipped by an explicit user action, not a polled value.
- The summary renders as a single `Text` in `signal_card.dart` (`maxLines:
  2` on the card face, `maxLines: 1` in the compact rows) — a per-segment
  visual treatment therefore means moving those sites to `Text.rich`
  (`InlineSpan`s), or the idiom must survive in plain text.

## Decision for the owner — the idiom

How does a one-line run mark a bypassed entry?

- **Option A — dimmed segment.** `Drive → Tremolo` with the bypassed name at
  muted color. Needs `Text.rich`; and color/opacity alone conveying state
  fails the WCAG 1.4.1 bar the codebase already respects elsewhere
  (`track_column.dart` adds chain state to labels for exactly this reason).
- **Option B — dimmed + struck-through segment** (recommended). Same
  `Text.rich` move, two visual channels (weight *and* decoration), the
  universal audio idiom for "in the chain but not sounding". Reads at card
  size, keeps the run's order intact, marks *which* entry, and the a11y
  string carries it textually (below).
- **Option C — textual marker, plain `Text`.** e.g. an interpunct or
  parentheses: `Drive → (Tremolo)`. No rich-text change, but parentheses
  read as annotation, not state; and it collides with the plugin
  placeholder/loading vocabulary the cards already use.
- **Option D — count suffix.** `Drive → Tremolo · 1 off`. Cheapest, keeps
  the run clean, but names no entry — on a two-entry chain it forces the
  panel open to learn which, which is the false-promise gap half-fixed.

**Recommendation: Option B**, with two riders:

1. **All-bypassed reads like chain-off.** When every entry is bypassed the
   audible result equals `Chain off`; the run shows all segments struck
   rather than borrowing the `Chain off` prefix (the chain's own switch is
   still on — the card must not claim otherwise; this mirrors the settled
   #535 rule that chain power and entry bypass are distinct facts).
2. **Text is not the only carrier.** The card's semantic label appends the
   bypassed entries by name, in the spirit of `a11yTrackTileFxOff`.

**Pen prerequisite (gating, per the design-source rule):** draw the idiom in
`segno-ui.pen` before build — the struck/dimmed segment on the `SIGNAL`
card summaries (`signal-input` and the track/lane cards), plus the
all-bypassed state, with a `c/` note recording the rule and the 1.4.1
reasoning. #600's chain-level case borrowed the panel's own `Chain off`
word; this one gets its vocabulary pinned the same way.

## Implementation outline

1. `chainSummary` grows per-entry awareness: return structured segments
   (name + bypassed flag) or an `InlineSpan` list; the l10n `Chain off`
   composition is unchanged.
2. `signal_card.dart` summary sites move to `Text.rich`, styling bypassed
   segments muted + `TextDecoration.lineThrough`; `maxLines`/overflow
   behaviour unchanged.
3. `sameChainLine` compares `enabled` per entry so a toggle redraws the
   card (`sameChainShape` already forwards to it from both faces'
   `buildWhen`).
4. Semantic label composition extends with the bypassed names.

## Verification plan

- Unit tests: a bypassed entry reads differently from an active one; the
  all-bypassed run differs from both the normal run and the `Chain off`
  form; `sameChainLine` returns false on an `enabled` flip and true on a
  param-only rewrite (guarding the poll-rate rebuild concern its doc pins).
- Widget test: toggling an entry in the FX editor while the card is up
  redraws the summary (the issue's own acceptance line).
- Golden/screenshot regen + eyeball on the author machine for the Signal
  cards.
- `dart analyze`, `bloc lint`, `flutter test`.

## Acceptance criteria

- A card whose entries are partly or wholly bypassed is visually and
  semantically distinct from the same card fully active, and from `Chain
  off`, at both `maxLines: 1` and `maxLines: 2` renderings.
- The marked entry is identifiable (not just counted).
- The pen carries the drawn idiom + `c/` rationale before the PR lands.

## Non-goals

- Chain-level display (shipped in #600) and the FX-mode stage surface
  (#692).
- Any behavioural change to bypass itself — `TrackEffect.enabled` semantics
  are untouched.
- Redrawing on plugin param changes — the poll-rate exclusion stands.

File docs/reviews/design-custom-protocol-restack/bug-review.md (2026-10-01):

# Bug-focused review — final M3.3

Base: `45ec78fb8b2b5e2e118b910677c172646ca4f761`. The complete 15-path source/test/fixture manifest is `final-hashes.json`, fingerprint `1969ff20d13e9144b6b3c65196dd425d189f0a80728e94d69cfc37f04a9e024a`. Final hashes match the builder freeze and coordinator manifest without drift. One independent non-author reviewer performed these five quality roles and the complete bug review. A separate independent reviewer ran the raw-byte probes. This reviewer changed no product source or tests and ran no duplicate builds.

No unresolved actionable findings. Complete review of the intended delta is finished for the bound files.

Reviewed the original incoming change against current contracts before using author tests as evidence. The fourth mode retains identity 3 on UART protocol 6; Rec/Play/FX indices, HELLO3, STATE19, flags, bank, selected track, eight LEDs, little-endian duration and gain are preserved. Mode 4 remains invalid. Decoder validation still precedes C output mutation; framing/resynchronization remains the existing implementation.

Traced strict version admission and all input/output callers. Versions 5 and 7 remain incompatible rather than falling back, while version 6 recovers through the established HELLO path. Independent literal probes confirm trust, adjacent fields, malformed values and liveness with source/oracle hashes unchanged. No behavioral failure arose in this bounded review.

Custom Mode amber is explicit in both the sketch and simulator. The actual sketch output test preserves Bank B indices and bank indication; source confirms independent ring color and existing clear/goodbye/watchdog behavior. No action routing, CTRL classification, source release ownership, native callback or FFI invariant is removed.

The final fixture comparison confirms only the intended HELLO amendment among existing bytes. The original SysEx downgrade paths and obsolete firmware trees remain absent. Final app/package/static/firmware evidence is green; raw independent probes are distinguished from those author/coordinator runs.

This is representation support only. The Custom action interpreter and accepted final Mode Hold → Custom behavior remain the next runtime slice. No physical UART, LED hue/brightness, firmware installation or appliance-validation claim follows from host checks. Exact publication-head review and remote CI remain separate coordinator gates.

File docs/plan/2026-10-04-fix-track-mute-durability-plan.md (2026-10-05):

# Preserve accepted track mute across restart

Issue #1127, prerequisite of Foot Mixer #1123. Human merge gate. Build after
monitor-mute admission #1125; do not mix the two publication diffs.

## Reproduced problem

An ordinary whole-track mute reaches audio and a saved Session but does not
update the existing lane-mute Settings keys. Cold bootstrap restores the old
value. The equivalent individual-lane action does persist. Session boot
synchronization also omits lane-mute keys, leaving the previous session's values.

## Existing ownership

Keep native admission and remembered intent in LooperRepository. Keep Settings
access at the application boundary. Native admission is immediate; durability
completes asynchronously and must not be inferred from that admission. Reuse the existing persistence owner and
its Session/shutdown barriers; do not add another queue, mutable mute cache,
storage format, migration, native API or Foot Mixer destination.

1. Validate lane identity and publish intent only after native admission. Preserve the existing whole-track
   result aggregation, which already retains any lane failure. Reuse
   remembered intent when composing rapid toggles rather than a stale polled
   snapshot. Accept valid stopped-engine intent explicitly and verify restart replay.
   Check startup replay, bootstrap lane restore and imported Session lane-mute
   results, using their existing stop/failure paths rather than discarding refusal.
2. Persist accepted lane values through the existing lane-address save path and
   existing `lane_mute` keys. Serialize and verify scalar writes using existing
   Settings facilities. Reuse retained failure and explicit flush/retry behavior.
3. Share the small application operation between Looper and Control; neither
   state owner may call the other. Preserve transport decisions in Control.
   Extract only an immediately used operation, with no new timer or state owner.
   Before any ordinary native write, honor the existing Session transition guard.
   Report non-success native results at Looper and Control callers. Observe the
   existing `saveConfirmed` Future for asynchronous write errors through their
   existing error paths; scheduling a save alone is not evidence of durability.
   Retain the same failed write for flush/shutdown retry, without another stream.
4. Include each accepted lane's mute in the existing immutable Session boot
   image. Reset omitted lane slots so stale mute cannot return after restart.
   Keep the existing load barrier until storage and read-back succeed.

## Caller behavior

- Ordinary whole-track, individual-lane, and mapped mute actions persist actual
  accepted lane state.
- Mute/Rec transport gestures keep their current park, play and recording rules.
  A failed prerequisite mute cannot advance a dependent transport action.
- Clear resets mute durably through the shared path. Fresh takes and Redo from
  empty also clear remembered mute; their existing lane persistence notification
  must save that accepted reset. Session import keeps its separate boot image.
  Parking membership alone remains a transport fact, with no invented mute write.
- Bootstrap reads saved intent. Session import uses the existing Session boot
  transaction, not ordinary user-toggle persistence.

Native lane mute is not an atomic all-lane command. If some lanes accept and
another refuses, keep and persist the accepted lane values, report failure for
the group, and allow deliberate retry. Do not claim rollback or save a rejected
requested value. Whole-track mute continues to reflect all active lanes.

## Bounded paths

Production candidates: LooperRepository, SettingsRepository scalar lane-mute
write, FxChainPersistence lane/Session image, LooperBloc and ControlCubit callers,
and one small immediately used application operation if it avoids duplication.
Change AppRuntime only if that operation requires composition. No native or
firmware changes. Review scope before building; avoid an ownership rewrite.

## Verification

Use real application/repository owners and the existing AudioEngine seam.
Keep the original ordinary-mute regression and passing lane control. Verify
actual stored values and cold bootstrap, not just method calls.

- Accepted whole-track and lane changes survive cold bootstrap and Session load.
  Include existing `test/app/audio_bootstrap_test.dart` and
  `packages/settings_repository/test/settings_repository_test.dart` suites for
  the changed storage and restart boundaries.
- Multi-lane refusal preserves each actual accepted value; explicit retry works.
- Ordinary mute during a Session transition reaches neither native nor storage.
  Startup, bootstrap and Session lane-mute refusal stop or fail through existing
  mechanisms instead of reporting a successful restore.
- Rapid mute/unmute with blocked first storage ends unmuted after flush/restart.
- Mutation-then-error storage keeps recovery pending and prevents a successful
  shutdown until retry. Session replacement excludes stale writes.
- Pending FX plus lane mute settles through the existing shared boundary without
  deadlock or a lost update. A delayed controller FX save cannot overwrite a
  newer mute; both use the same lane-address drain. No premature durability claim.
  Preserve already-admitted controller saves through owner close, including
  their actual receipt and storage failures; do not retry failed work on close.
- Clear and Mute-mode transport keep their accepted behavior.

Run focused behavioral tests, then full affected package/application coverage,
strict analysis, explicit formatting and positively scanned Bloc lint on frozen
source. Independent VGV, architecture, test-quality, simplicity, readiness and
bug-focused reviews are required. Additional Claude and device evidence remain
separate from local test claims. No merge or deployment is authorized here.

## Success Criteria

```success-criteria
GOAL: Track mute represents accepted audio state and survives restart through the existing persistence boundary.

SUCCESS CRITERIA:
- Partial and complete native admission remain truthful. | verify: flutter test packages/looper_repository/test/looper_repository_test.dart
- Ordinary and mapped mute preserve transport and persist accepted values. | verify: flutter test test/looper/bloc/looper_bloc_test.dart test/control/control_cubit_test.dart
- Saved Session and shutdown retain or report lane-mute storage failures. | verify: flutter test test/app/fx_chain_persistence_test.dart test/app/application/app_runtime_test.dart test/session/cubit/session_cubit_test.dart
- Edited code passes the project static gates. | verify: dart analyze --fatal-infos lib test packages && bloc lint lib test packages

NON-GOALS:
- Foot Mixer UI, new persistence owners, schemas, DSP, protocols, migrations, deployment or merging.
```

Use the documented SDK and worktree lint wrapper. These are planned obligations,
not executed proof. Review the plan before implementation.

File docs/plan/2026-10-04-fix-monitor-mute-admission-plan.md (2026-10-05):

# Preserve monitor mute truth on refusal

Issue #1125, prerequisite of Foot Mixer #1123. Human merge gate.
Base: live-input gain correction #1126.

## Reproduced problem

When native input mute refuses a command, the repository currently remembers and
announces the requested value anyway. Monitor presentation then shows it and the
confirmed-envelope writer saves it. A behavioral probe with real repository,
Monitor, Settings and FX-persistence owners observed applied mute false while
repository, presentation and saved mute were true. An accepted-command control
passes. Correct this existing flow before adding another consumer.

## Bounded implementation

1. In `packages/looper_repository/lib/src/looper_repository.dart`, validate the
   monitor input and request native admission before publishing changed running
   intent. A refusal leaves remembered mute and change notifications untouched.
   Preserve valid stopped-engine intent and its existing restart replay. Do not
   invent a rollback transaction: one input command has one admission result.
2. In `lib/audio_setup/cubit/monitor_cubit.dart`, check the returned result before
   emitting success or saving. Refusal retains the prior view and produces an
   observed error through the existing owner/presentation path. A deliberate
   retry must remain possible. Awaiting callers retain failed completion on
   admission or storage refusal. Accepted mute continues through
   `FxChainPersistence.saveConfirmed`, including its existing held-FX projection,
   retained failures from `saveConfirmed`/`flush`, and Monitor’s `addError`
   observation path. Reuse these mechanisms; do not add an error stream.
3. Handle and test ignored refusal in Monitor restore (`_applyMonitor`),
   Session monitor reset/application, and direct native startup replay. Use each
   caller’s existing failure mechanism; do not report a completed restore when
   mute admission failed. Admit saved active mute before enabling or routing an
   input. When clearing mute, apply mode and routing first, including explicit
   Off state. Omitted Session monitors remain disabled before mute is cleared.
   Audit other immediate setter callers for false success after refusal. Keep the fix limited to monitor-mute admission and reporting;
   do not rewrite Session restoration, add a new cache, timer, queue, settings
   envelope, adapter or Foot Mixer destination.

Existing storage failure must not be converted into durable success. If the
current persistence owner already reports and retains that failure, prove and
reuse it. If not, report the concrete missing lifetime boundary before expanding
this slice. Whole-track and individual-lane mute persistence are a separate
correction because they have different storage and transport callers.

## Verification

Promote the red probe into normal behavioral tests. Use the existing AudioEngine
seam and real repository/application owners; preserve a passing admission control.

- Refusal: applied, intended, presented and saved mute remain unchanged; no
  rejected change announcement. A later unrelated envelope save remains correct.
- Accepted retry: all owners agree and saved intent restores on engine restart.
- Invalid input identity: no native call or cached entry.
- Stopped engine: valid intent can be saved and replayed after start.
- Failed storage: live accepted mute remains true, failure is observed, and an
  explicit retry/flush preserves it without claiming premature durability.
- Teardown or device/session replacement cannot publish a stale success.

Focused tests belong in existing repository, Monitor and FX-persistence suites.
Run the full affected package/application gates once source is frozen, strict
analysis, explicit formatting and positively scanned Bloc lint. Independently
review correctness, architecture, test quality and simplicity. Native DSP and
FFI are unchanged; reuse source-bound engine proof only after comparing hashes.
Physical appliance/controller tests and additional Claude review stay separate.

## Success Criteria

```success-criteria
GOAL: A refused live-input mute never appears or persists as accepted, while valid mute retains the existing save and restart behavior.

SUCCESS CRITERIA:
- Accepted, refused, invalid and stopped-engine monitor writes retain truthful repository intent and announcements. | verify: flutter test packages/looper_repository/test/looper_repository_test.dart
- Monitor presentation and storage follow accepted admission; refusal and retry are observable. | verify: flutter test test/audio_setup/cubit/monitor_cubit_test.dart
- Confirmed-envelope storage failures remain recoverable and preserve unrelated held effects. | verify: flutter test test/app/fx_chain_persistence_test.dart
- Changed application and package code pass strict static checks. | verify: dart analyze --fatal-infos lib test packages && bloc lint lib test packages

NON-GOALS:
- Track mute persistence, new Foot Mixer controls, new persistence owners, native DSP, protocol changes, migration, deployment or merging.

VERIFICATION COMMAND: flutter test packages/looper_repository/test/looper_repository_test.dart test/audio_setup/cubit/monitor_cubit_test.dart test/app/fx_chain_persistence_test.dart && dart analyze --fatal-infos lib test packages && bloc lint lib test packages
```

Use the repository SDK and worktree lint instructions. Commands above are required
checks, not execution evidence. Bind the final report to the reviewed source and
record conditional skips and limits explicitly.

## Reviewed restore recovery follow-up

At base `05900df`, a refused saved monitor restore is observed but its completed
load future prevents retry. Add a failure fact to the existing Monitor state and
make explicit load retry in-flight-deduplicated. Expose Retry through the existing
settings notice, including initial post-frame reconciliation, external resolution
and shutdown-overlay suppression. Preserve failure through ordinary state copies;
clear only on complete restore or successful Session projection.

Use one attempt-local ownership predicate after every asynchronous stage and
before later native/storage admissions or publication: owner open, same Session
revision and attempt, no Session reservation, no newer authoritative projection.
Canceled attempts do not roll back already admitted work. Do not reset audio,
change routing order, retry automatically or add another owner/queue.

This correction is independent of later scalar mute persistence. Prove failed
true/false mute and read/settlement restores followed by explicit retry without
intervening unrelated edits. On this head, unrelated-envelope preservation after
ordinary mute is not claimed. Test actual App Retry, early failure, Session and
disposal supersession, concurrent/repeated retries and notice dismissal across
Power overlay. Reuse English/Spanish toast layout and the existing Retry label.

## Session recovery notice ownership

The adversarial re-review confirms the failed-restore Retry correction, but its
notice can compete with an active Session load. Keep Monitor's incomplete-restore
fact and suppress its notice while the existing Session reservation or boot-image
debt owns recovery. Reconcile on the existing Session state stream so cancellation
can restore a genuine Monitor Retry even when its failure flag has not changed.
Do not suppress unrelated Session save/export work or change either restore owner.

A real Sessions-dialog test also reproduces an inaccessible boot-recovery Retry:
its Snackbar is behind the modal. Present only that existing Session recovery
action through the shared settings-notice presenter and remove its old Snackbar,
leaving other Session outcomes unchanged. Reuse its existing localized text and
retryLoadedSession operation, including Power suppression and lifetime guards.

Prove success-overlap has no false Monitor notice, pre-apply failure restores a
working Monitor Retry, and post-apply boot failure exposes a hit-testable Session
Retry through the actual dialog. Failed Retry retains its debt; successful Retry
projects the replacement only after the Session owner finishes. No new recovery
coordinator, stream, timer, state copy, persistence format or native change.

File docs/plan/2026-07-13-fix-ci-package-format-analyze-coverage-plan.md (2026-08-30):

---
title: CI format + analyze steps must cover packages/*, not just root lib/test
type: fix
date: 2026-07-13
---

## CI format + analyze steps must cover packages/*, not just root lib/test - Minimal

`.github/workflows/main.yaml`'s `build` job invokes VeryGoodOpenSource's
reusable `flutter_package.yml@v1` without overriding `format_directories` or
`analyze_directories`. Both default to `"lib test"` relative to
`working_directory: "."`, so `dart format --set-exit-if-changed lib test` and
`flutter analyze lib test` only ever check the root app. None of the 13
packages under `packages/` (daw_export, performance_repository, wav_codec,
segno_engine, controller_repository, local_storage_client,
looper_repository, midi_client, midi_device_repository, pedal_repository,
routing_graph, session_repository, settings_repository) get any format or
analyze gate in CI, so analyzer lints and `dart format` drift in package code
can merge silently (confirmed in brainstorming: this already happened —
`packages/looper_repository/test/looper_repository_test.dart` is currently
unformatted).

Fix: extend `format_directories`/`analyze_directories` on the existing
`build` job to also glob every package's `lib` and `test` directories, and
fix the one pre-existing format violation so the new gate is green on
merge.

## Success Criteria

```success-criteria
GOAL: Every package under packages/ is format-checked and analyzed by the
existing CI `build` job, the same way the root app already is, with no new
job and no change to test execution (test_recursion stays false) or to
license_check.yaml.

SUCCESS CRITERIA:
- main.yaml's build job passes explicit format_directories and analyze_directories inputs to flutter_package.yml@v1 that include both the root ("lib test") and every package's lib+test via a glob | verify: grep -A2 'format_directories' .github/workflows/main.yaml | grep -q 'packages/\*/lib' && grep -A2 'analyze_directories' .github/workflows/main.yaml | grep -q 'packages/\*/lib'
- dart format --set-exit-if-changed over root + all packages' lib/test exits 0 (no formatting drift left in the tree) | verify: cd /Users/Tomas/Documents/Work/opensource/segno/.claude/worktrees/agent-a7e71863edb276596 && dart format --set-exit-if-changed lib test packages/*/lib packages/*/test
- flutter analyze over root + all packages' lib/test exits 0 (no analyzer issues) | verify: cd /Users/Tomas/Documents/Work/opensource/segno/.claude/worktrees/agent-a7e71863edb276596 && flutter analyze lib test packages/*/lib packages/*/test
- The workflow YAML is still valid YAML | verify: cd /Users/Tomas/Documents/Work/opensource/segno/.claude/worktrees/agent-a7e71863edb276596 && python3 -c "import yaml; yaml.safe_load(open('.github/workflows/main.yaml'))"
- A deliberately-introduced lint/format violation in a package is demonstrated to be caught by the new directory list (already proven once during brainstorming; re-confirm after the final diff is in place) | verify: manual 1) temporarily add a badly-formatted function with an unused local variable to any packages/*/lib file 2) run the two dart format / flutter analyze commands above with the new directory args and confirm non-zero exit + the issue reported 3) revert the temporary change and re-run to confirm clean exit 0 again
- license_check.yaml is untouched | verify: git diff --name-only master... | grep -qv 'license_check.yaml' && ! git diff --name-only master... | grep -q 'license_check.yaml'

NON-GOALS:
- Adding a package-level unit-test job or flipping test_recursion to true (separate, already-known intentional gap).
- Touching license_check.yaml's path filter (owned by a separate parallel fix).
- Any refactor of package source beyond the one mechanical dart-format fix required to make the new gate pass at merge time.
- Parallelizing or matrix-izing per-package CI (out of scope; see brainstorm doc's Approach B rejection).

VERIFICATION COMMAND: cd /Users/Tomas/Documents/Work/opensource/segno/.claude/worktrees/agent-a7e71863edb276596 && dart format --set-exit-if-changed lib test packages/*/lib packages/*/test && flutter analyze lib test packages/*/lib packages/*/test && python3 -c "import yaml; yaml.safe_load(open('.github/workflows/main.yaml'))"
```

## Context

- Brainstorm doc: `docs/brainstorm/2026-07-13-ci-package-format-analyze-coverage-brainstorm-doc.md`
  — contains the full investigation: fetched the reusable workflow's actual
  source (`VeryGoodOpenSource/very_good_workflows/.github/workflows/flutter_package.yml`)
  and confirmed `format_directories`/`analyze_directories` are spliced
  unmodified into plain bash `run:` steps, so a glob like `packages/*/lib`
  expands normally — no special multi-dir support needed from the reusable
  workflow. This was verified empirically in this worktree, not assumed:
  - `dart format --set-exit-if-changed lib test packages/*/lib packages/*/test`
    surfaced one real pre-existing violation in
    `packages/looper_repository/test/looper_repository_test.dart`.
  - `flutter analyze lib test packages/*/lib packages/*/test` found **zero**
    issues across all 13 packages (they're already lint-clean).
  - A deliberately-introduced violation in `packages/wav_codec/lib/wav_codec.dart`
    was correctly caught by both commands, using that package's own
    `analysis_options.yaml` (`package:very_good_analysis`) — proving
    per-package lint config is respected — then reverted.
- Current `build` job (`.github/workflows/main.yaml` lines ~19-27):
  ```yaml
  build:
    uses: VeryGoodOpenSource/very_good_workflows/.github/workflows/flutter_package.yml@v1
    with:
      flutter_version: "3.47.x"
      run_bloc_lint: true
      min_coverage: 90
      coverage_excludes: "**/window_chrome.dart **/waveform_window*.dart **/run_segno.dart **/bootstrap.dart **/session_directory.dart"
  ```
- `run_bloc_lint: true` runs a separate, hardcoded `bloc lint .` step in the
  reusable workflow that already scans the whole repo regardless of
  `format_directories`/`analyze_directories` — untouched by this fix.
- All 13 packages under `packages/` have both a `lib/` and a `test/`
  directory (verified via `ls`), so a bare `packages/*/lib
  packages/*/test` glob covers every package uniformly with no dangling
  literal-glob edge case.
- Institutional gotcha (`segno-ffigen-format-drift` memory): ffigen
  regeneration in `packages/segno_engine/lib/src/generated/` is a known
  recurring source of format drift; this fix is what would have caught it in
  CI going forward.

## MVP

Two-part change:

1. **`.github/workflows/main.yaml`** — add `format_directories` and
   `analyze_directories` inputs to the `build` job's `with:` block:

   ```yaml
   build:
     uses: VeryGoodOpenSource/very_good_workflows/.github/workflows/flutter_package.yml@v1
     with:
       flutter_version: "3.47.x"
       run_bloc_lint: true
       format_directories: "lib test packages/*/lib packages/*/test"
       analyze_directories: "lib test packages/*/lib packages/*/test"
       # Keep the 90% gate for real logic, but exclude platform / entrypoint glue
       # that can't be meaningfully unit-tested: the custom window chrome
       # (window_manager), the desktop_multi_window output-waveform sub-window,
       # and the app bootstrap/entrypoint. Coverage on the remainder stays ~91%.
       min_coverage: 90
       coverage_excludes: "**/window_chrome.dart **/waveform_window*.dart **/run_segno.dart **/bootstrap.dart **/session_directory.dart"
   ```

   A short comment above the two new inputs should explain why they exist
   (extends format/analyze to packages/*, since the reusable workflow's
   defaults only cover the root app) so a future reader doesn't mistake it
   for redundant boilerplate.

2. **`packages/looper_repository/test/looper_repository_test.dart`** — run
   `dart format` to fix the one existing violation (pure whitespace/line-wrap
   change around the `'a reconnect re-applies the remembered rig (lanes +
   monitors)'` test's `test(...)` call — trailing-comma multi-line style).
   No semantic change; purely mechanical so the new gate is green at merge.

No other files change. No new CI job. No change to `test_recursion`,
`min_coverage`, `coverage_excludes`, or `license_check.yaml`.

## References

- Issue evidence: `.github/workflows/main.yaml` build job passes only
  `flutter_version`/`run_bloc_lint`/`min_coverage`/`coverage_excludes` to
  `flutter_package.yml@v1`; that reusable workflow's own defaults are
  `format_directories="lib test"`, `analyze_directories="lib test"`,
  `working_directory="."`.
- Upstream reusable workflow source (fetched during brainstorming):
  `https://raw.githubusercontent.com/VeryGoodOpenSource/very_good_workflows/main/.github/workflows/flutter_package.yml`
- Brainstorm doc: `docs/brainstorm/2026-07-13-ci-package-format-analyze-coverage-brainstorm-doc.md`

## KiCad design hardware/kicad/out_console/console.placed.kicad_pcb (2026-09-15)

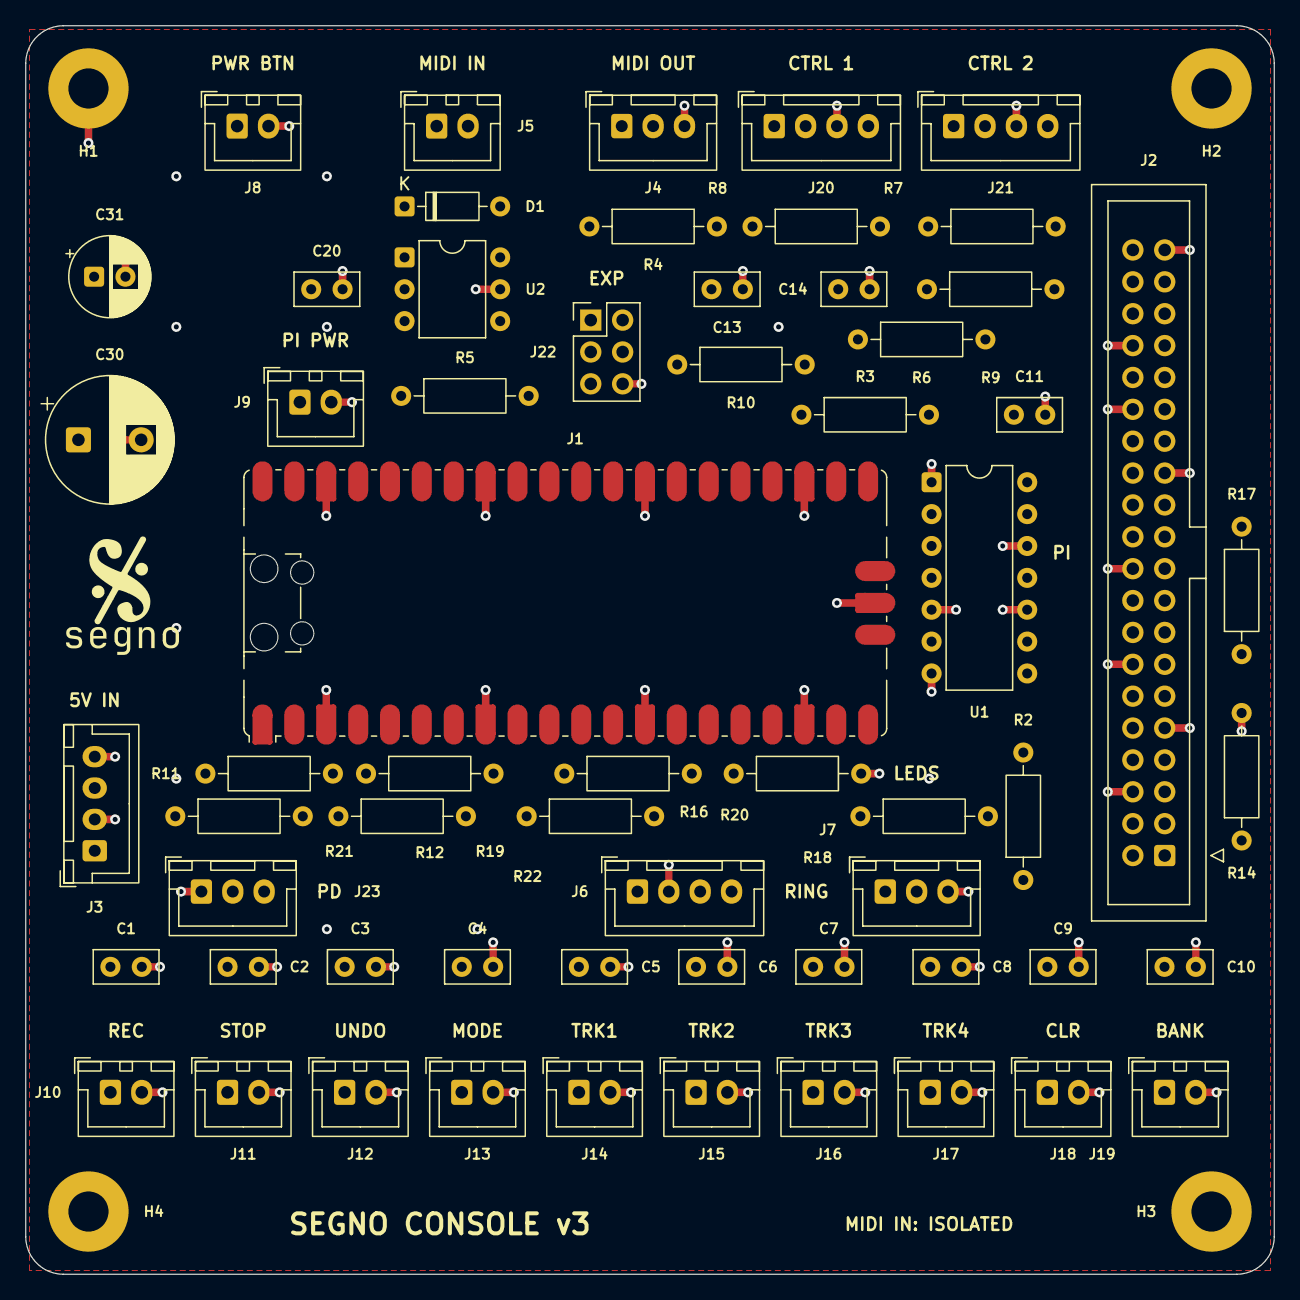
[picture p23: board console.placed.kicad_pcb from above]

Board: 2 copper layers, 99.5 x 99.5 mm, 65 parts (0 on the bottom side), 48 nets.

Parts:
C1, C2, C3, C4, C5, C6, C7, C8, C9, C10, C11, C13, C14, C20: C_Disc_D5.0mm_W2.5mm_P2.50mm
C30: CP_Radial_D10.0mm_P5.00mm
C31: CP_Radial_D6.3mm_P2.50mm
D1: D_DO-35_SOD27_P7.62mm_Horizontal
H1, H2, H3, H4: MountingHole_3.2mm_M3_Pad
J1: RaspberryPi_Pico_SMD_HandSolder
J2: IDC-Header_2x20_P2.54mm_Vertical
J3, J6, J20, J21: JST_XH_B4B-XH-A_1x04_P2.50mm_Vertical
J4, J7, J23: JST_XH_B3B-XH-A_1x03_P2.50mm_Vertical
J5, J8, J9, J10, J11, J12, J13, J14, J15, J16, J17, J18, J19: JST_XH_B2B-XH-A_1x02_P2.50mm_Vertical
J22: PinHeader_2x03_P2.54mm_Vertical
R2, R3, R4, R5, R6, R7, R8, R9, R10, R11, R12, R14, R16, R17, R18, R19, R20, R21, R22: R_Axial_DIN0207_L6.3mm_D2.5mm_P10.16mm_Horizontal
U1: DIP-14_W7.62mm
U2: DIP-6_W7.62mm

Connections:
+3V3: C20.1, J2.1, J2.17, J22.1, R6.1, R7.1, R8.1, R9.1, R10.1, R11.1, R12.1, U2.6
+5V: C11.1, C30.1, C31.1, J1.39, J3.1, J3.3, J6.1, J7.1, J22.2, R4.1, U1.4, U1.13, U1.14
CTRL1_PRESENT: J1.25, R21.2
CTRL1_RING: J1.26, R19.2
CTRL1_TIP: C13.1, J1.31, J20.1, R8.2
CTRL2_PRESENT: J1.29, R22.2
CTRL2_RING: J1.27, R20.2
CTRL2_TIP: C14.1, J1.32, J21.1, R10.2
EXP_GP12: J1.16, J22.3
EXP_GP15: J1.20, J22.4
EXP_GP28: J1.34, J22.5
GND: C1.2, C2.2, C3.2, C4.2, C5.2, C6.2, C7.2, C8.2, C9.2, C10.2, C11.2, C13.2, C14.2, C20.2, C30.2, C31.2, H1.1, J1.3, J1.8, J1.13, J1.18, J1.23, J1.28, J1.33, J1.38, J1.D2, J2.6, J2.9, J2.14, J2.20, J2.25, J2.30, J2.34, J2.39, J3.2, J3.4, J4.3, J6.2, J7.3, J8.2, J9.2, J10.2, J11.2, J12.2, J13.2, J14.2, J15.2, J16.2, J17.2, J18.2, J19.2, J20.3, J21.3, J22.6, J23.1, R14.2, R16.2, U1.1, U1.5, U1.7, U1.10, U1.12, U2.5
IND_DATA: J1.24, R16.1, U1.2
IND_DATA_BUF: R2.1, U1.3
IND_DATA_OUT: J7.2, R2.2
J20_REF: J20.2, R7.2, R19.1
J20_TN: J20.4, R21.1
J21_REF: J21.2, R9.2, R20.1
J21_TN: J21.4, R22.1
LINK_RX: J1.22, R18.2
LINK_RX_PI: J2.24, R18.1
LINK_TO_CONSOLE: J1.19, J6.4, R12.2
LINK_TO_RING: J1.17, J6.3, R11.2
LINK_TX: J1.21, R17.1
LINK_TX_PI: J2.21, R17.2
MIDI_OUT_BUF: R3.1, U1.8
MIDI_RX: J2.10, R6.2, U2.4
MIDI_TX: J2.8, R14.1, U1.9
unnamed: J4.1, R3.2
unnamed: J4.2, R4.2
unnamed: J5.1, R5.1
unnamed: D1.1, R5.2, U2.1
unnamed: D1.2, J5.2, U2.2
PD_SCL: J1.2, J23.3
PD_SDA: J1.1, J23.2
PWR_BTN: J8.1, J9.1
SWCLK: J1.D1, J2.18
SWDIO: J1.D3, J2.22
SW_BANK: C10.1, J1.15, J19.1
SW_CLEAR: C9.1, J1.14, J18.1
SW_MODE: C4.1, J1.7, J13.1
SW_RECPLAY: C1.1, J1.4, J10.1
SW_STOP: C2.1, J1.5, J11.1
SW_TRACK1: C5.1, J1.9, J14.1
SW_TRACK2: C6.1, J1.10, J15.1
SW_TRACK3: C7.1, J1.11, J16.1
SW_TRACK4: C8.1, J1.12, J17.1
SW_UNDO: C3.1, J1.6, J12.1

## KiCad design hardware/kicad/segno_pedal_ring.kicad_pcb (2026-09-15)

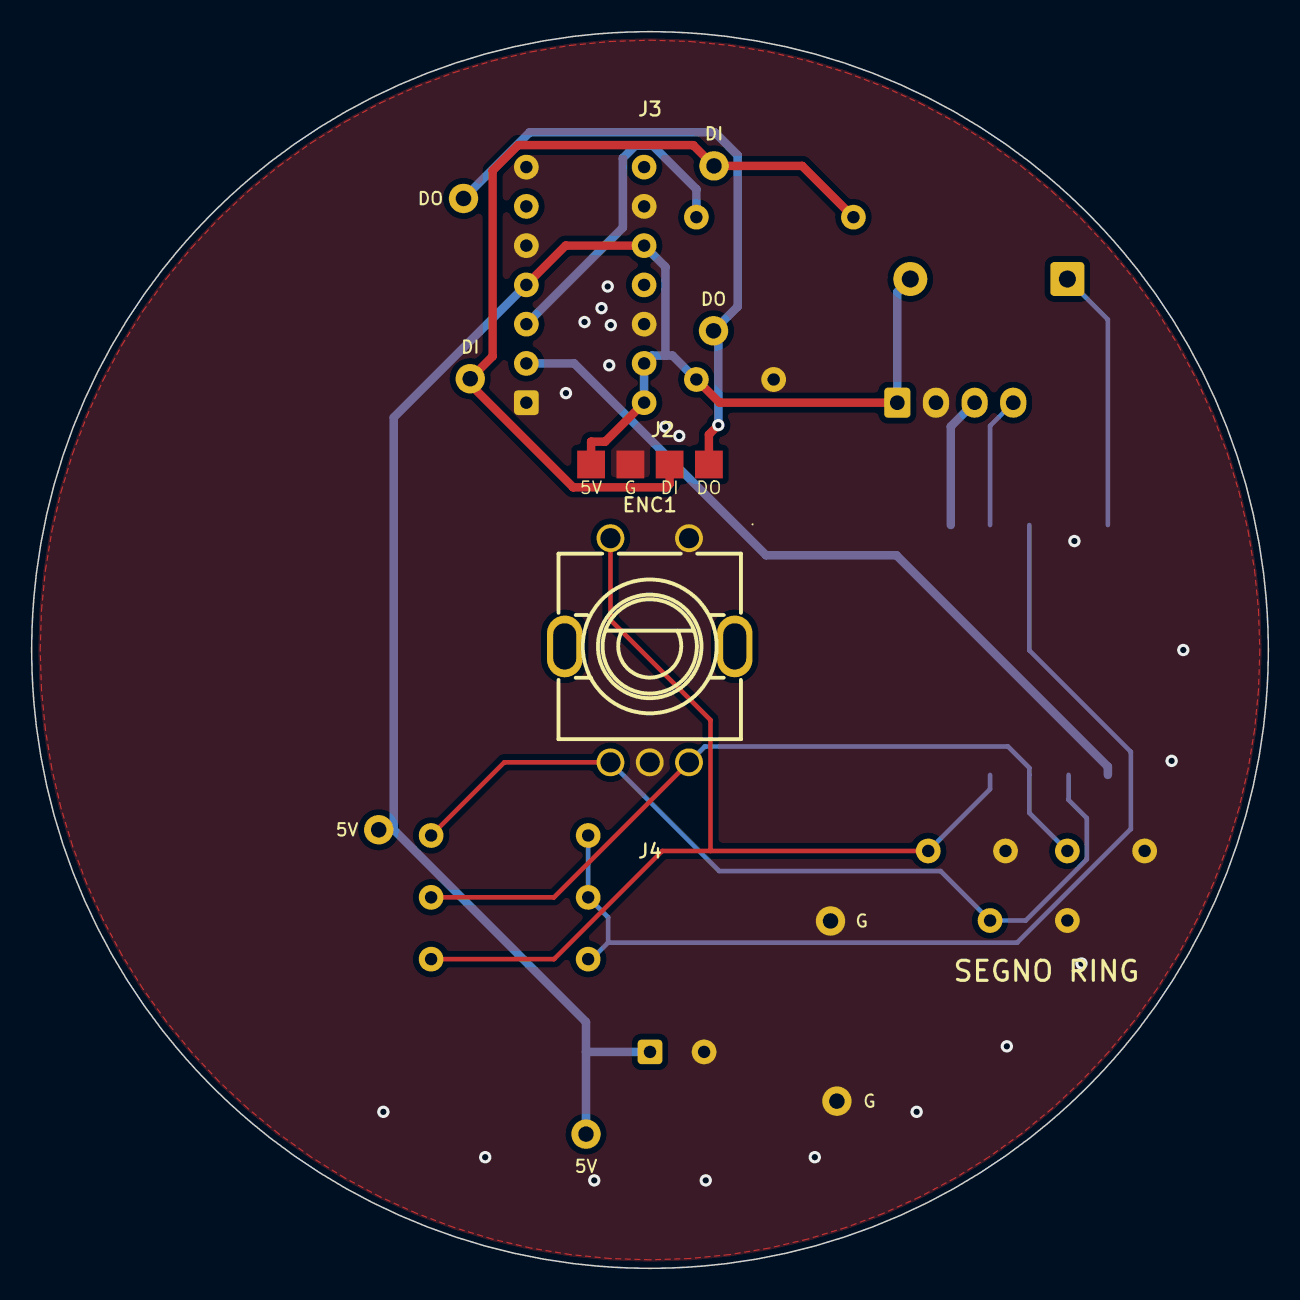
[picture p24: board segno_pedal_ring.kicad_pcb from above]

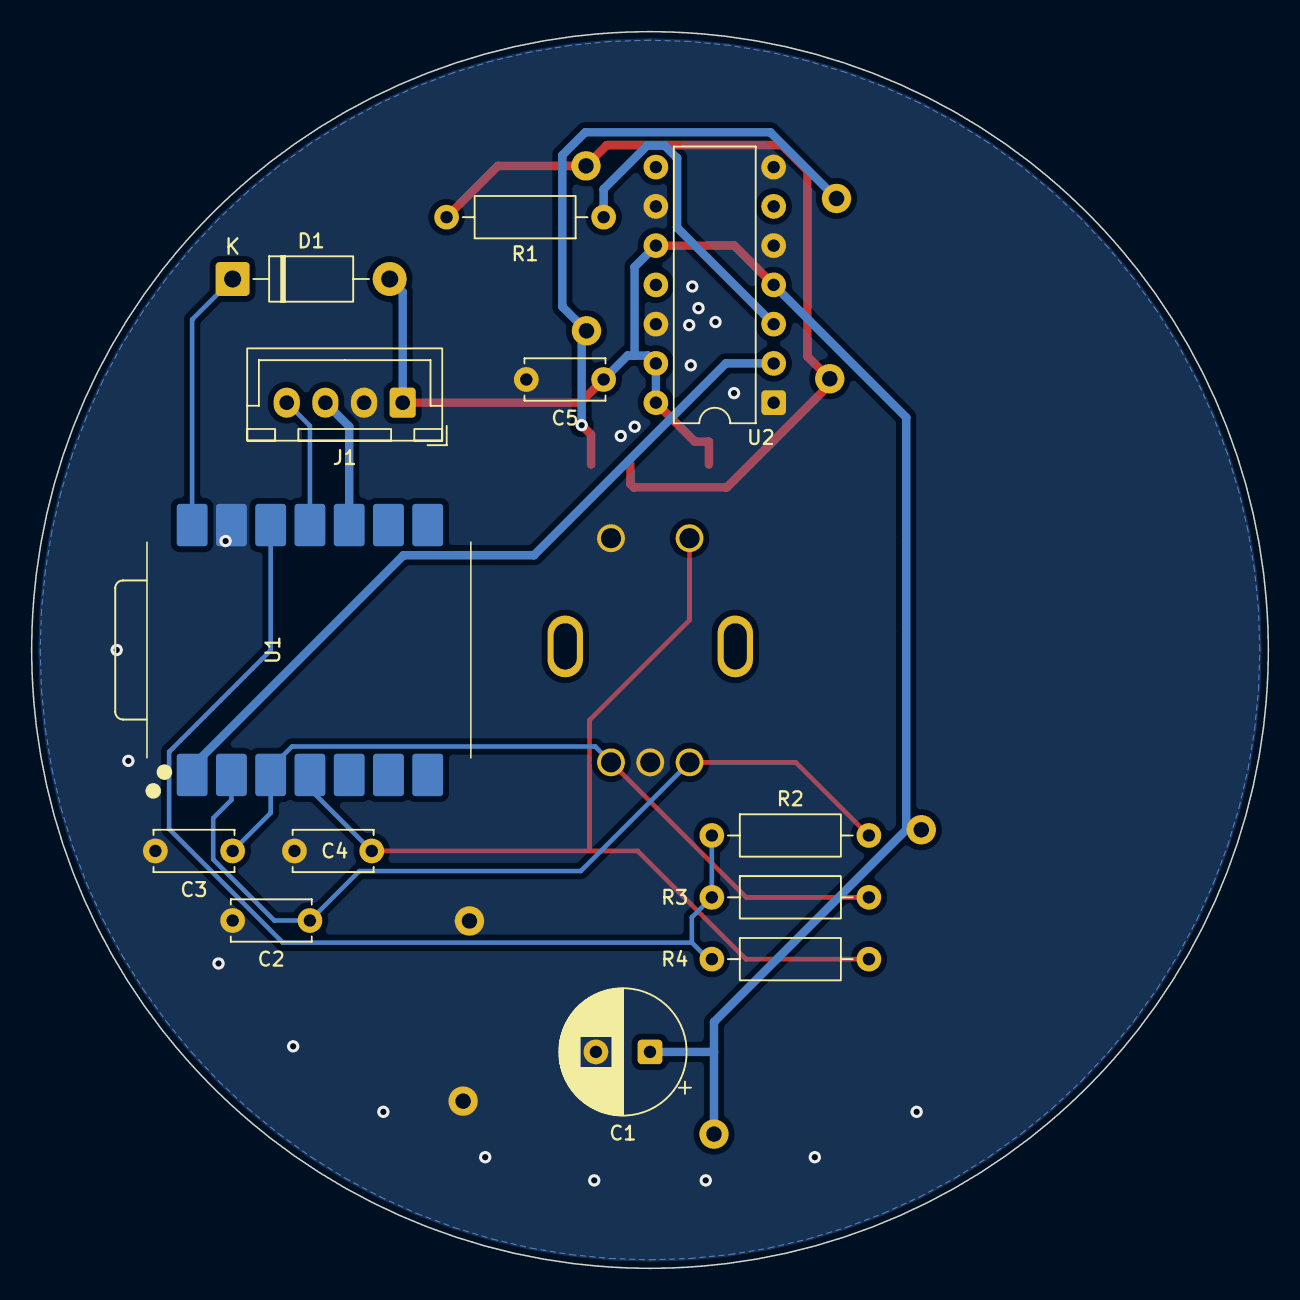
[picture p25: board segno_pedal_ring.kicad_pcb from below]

Board: 2 copper layers, 80.0 x 80.0 mm, 18 parts (13 on the bottom side), 13 nets.

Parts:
C1: 470uF 16V low-ESR <=0.15R; CP_Radial_D8.0mm_P3.50mm
C2, C3, C4, C5: 100nF; C_Disc_D5.0mm_W2.5mm_P5.00mm
D1: 1N5819; D_DO-41_SOD81_P10.16mm_Horizontal
ENC1: RotaryEncoder_Switch; RotaryEncoder_EC11
J1: Conn_01x04; JST_XH_B4B-XH-A_1x04_P2.50mm_Vertical
J2: NEOPIXEL; WirePads_1x04
J3: RINGPINS24; ModuleMountPads_Ring24
J4: RINGPINS16; ModuleMountPads_4
R1: 330; R_Axial_DIN0207_L6.3mm_D2.5mm_P10.16mm_Horizontal
R2, R3, R4: 10k; R_Axial_DIN0207_L6.3mm_D2.5mm_P10.16mm_Horizontal
RING1: NeoPixel24; NeoPixel_Ring24
U1: XIAO-RP2350; XIAO_RP2350_SMD
U2: 74AHCT125N; DIP-14_W7.62mm

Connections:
+3V3: R2.1, R3.1, R4.1, U1.12
+5V_LED: C1.1, C5.1, D1.2, J1.1, J2.1, J3.2, J4.2, U2.4, U2.10, U2.13, U2.14
+5V_MCU: D1.1, U1.14
ENC_A: C2.1, ENC1.A, R2.2, U1.2
ENC_B: C3.1, ENC1.B, R3.2, U1.3
ENC_SW: C4.1, ENC1.S1, R4.2, U1.4
GND: C1.2, C2.2, C3.2, C4.2, C5.2, ENC1.C, ENC1.S2, J1.2, J2.2, J3.3, J4.3, U1.13, U2.1, U2.5, U2.7, U2.9, U2.12
LINK_TO_CONSOLE: J1.4, U1.11
LINK_TO_RING: J1.3, U1.10
RING_DATA: J2.3, J3.1, J4.1, R1.2
RING_DATA_3V3: U1.1, U2.2
RING_DATA_5V: R1.1, U2.3
RING_DOUT: J2.4, J3.4, J4.4

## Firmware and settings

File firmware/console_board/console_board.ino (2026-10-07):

// Segno console board v2 (#747) -- Pico 2 (RP2350) firmware.
//
// A PURE THIN CLIENT, like the pedal it replaces: it holds no looper state. It
// renders the ring and the indicator pills from the last good STATE frame segno
// pushes, and sends raw footswitch / encoder / encoder-switch events. segno runs the behavior
// machine and is the single source of truth.
//
// Link: Serial1 = UART0, GP16 TX / GP17 RX -> the Pi's uart3 (GPIO8/9,
// /dev/ttyAMA3), 115200 8N1. Wire format: pedal_link.h, shared byte for byte
// with packages/pedal_repository and pinned by firmware/test/run_tests.sh.
//
// Half of several circuits on this board is firmware (#752): the footswitches
// and the encoder have no external pull-ups on the Pico side (INPUT_PULLUP is
// mandatory), a release edge is an RC of ~5-8 ms through the 100 nF debounce
// caps, and GP23 high puts the module's SMPS in PWM mode for a quieter ADC.
//
// Build: arduino-pico core + Adafruit NeoPixel + NeoPixelBus (PIO/DMA pills).
//   arduino-cli compile --fqbn rp2040:rp2040:rpipico2 firmware/console_board --output-dir firmware/console_board/build
// Flash from the Pi over SWD: README.md.

#include <Adafruit_NeoPixel.h>
#include <NeoPixelBus.h>

#include "pedal_link.h"

// A colour before gamma; the .ino auto-prototypes need the type declared first.
struct Rgb { uint8_t r, g, b; };

static const uint8_t FW_MAJOR = 1;
static const uint8_t FW_MINOR = 13;

// ---- pin map (console_board.py GPIO table) ---------------------------------
static const uint8_t PIN_LINK_TX = 16, PIN_LINK_RX = 17;
static const uint8_t FSW_PIN[PEDAL_BTN_COUNT] = {2, 3, 4, 5, 6, 7, 8, 9, 10, 11};
static const uint8_t PIN_RING = 12, PIN_ENC_A = 13, PIN_ENC_B = 14, PIN_ENC_SW = 15;
static const uint8_t PIN_IND = 18;
// The CTRL TRS jacks: tip on ADC0/ADC1 with a 10k pull-up, ring feeding 3V3
// through 1k as the pot's top, sleeve to ground.
static const uint8_t CTRL_PIN[PEDAL_CTRL_COUNT] = {26, 27};
// The rings, sensed. On a two-switch pedal on one TRS plug (a BOSS FS-6's A&B
// jack) the second switch shorts the ring to sleeve, which the tip's ADC can
// never see. Board v2 has no trace for it: these are the expansion pads on J22
// (GP20 / GP21, otherwise unused), reached by one wire from each jack's ring
// pin. With the wire, the ring sits at ~3V (an expression pedal's pot top, or
// an open jack) and drops to 0 when that switch closes. WITHOUT the wire the
// internal pull-up holds the pin high and the ring simply never reports, so
// an unmodified board loses nothing.
static const uint8_t CTRL_RING_PIN[PEDAL_CTRL_COUNT] = {20, 21};
// Jack presence, from a switched jack's tip-normal contact (board v3, Neutrik
// NJ6FD-V): the contact ties this pin to the tip -- 3V3 through 10k -- while
// the jack is EMPTY, and opens the moment a plug goes in, so with the internal
// pull-down the pin reads HIGH = empty, LOW = plugged. On board v2 these are
// J22's unpopulated pads: they float, the pull-down wins, and every jack reads
// "plugged" -- which is exactly the v2 behaviour, with the heuristics below
// doing the rest. Present = LOW is chosen so that v2 needs no flag.
static const uint8_t CTRL_PRESENT_PIN[PEDAL_CTRL_COUNT] = {19, 22};
static const uint8_t PIN_SMPS_PWM = 23;

// ---- LEDs --------------------------------------------------------------------
// One continuous 40-pixel GRB WS2812B strip around the encoder, driven by
// the existing v2 GP12/J6 path. Keep the established clockwise index order.
static const uint16_t RING_N = 40;
// Ten eight-pixel pills on J7, in the owner-verified data-chain order.
static const uint8_t PILL_PIXELS = 8, IND_N = PEDAL_BTN_COUNT * PILL_PIXELS;
static const uint8_t PILL_BUTTON[PEDAL_BTN_COUNT] = {
  PEDAL_BTN_TRACK4, PEDAL_BTN_TRACK3, PEDAL_BTN_TRACK2, PEDAL_BTN_TRACK1,
  PEDAL_BTN_MODE, PEDAL_BTN_UNDO, PEDAL_BTN_STOP, PEDAL_BTN_REC_PLAY,
  PEDAL_BTN_CLEAR, PEDAL_BTN_BANK
};
static const uint8_t PILL_PEAK = 191;
static const uint8_t PILL_WEIGHTS[PILL_PIXELS] = {38, 92, 201, 255, 255, 201, 92, 38};
// Limit the whole pill chain to ~471 mA of color-channel current using the
// conservative 20 mA/channel model. The ring's 11520-channel budget adds
// <=904 mA; 120 mA pixel idle +140 mA logic gives ~1.635 A on the old PCB's
// estimated ~1.65 A rail. This is a planning model, not measured consumption.
static const uint32_t PILL_CHANNEL_BUDGET = 6000;
Adafruit_NeoPixel ring(RING_N, PIN_RING, NEO_GRB + NEO_KHZ800);
// DMA keeps interrupts available throughout the 80-pixel transfer.
NeoPixelBus<NeoGrbFeature, Rp2040x4Pio1Ws2812xMethod> ind(IND_N, PIN_IND);
static const uint8_t RING_AMBIENT_BRIGHTNESS = 96;
static const uint32_t RING_CHANNEL_BUDGET = RING_N * 3UL * RING_AMBIENT_BRIGHTNESS;

static uint8_t pillPixelIndex(uint8_t group, uint8_t pixel) {
  return group * PILL_PIXELS + (group < 8 ? PILL_PIXELS - 1 - pixel : pixel);
}


// ---- link ----------------------------------------------------------------------
#define LINK Serial1
static const unsigned long LINK_BAUD = 115200;
// segno answers every HELLO with its current frame; if nothing arrives for
// FRAME_TIMEOUT_MS the app is gone and the panel goes dark rather than
// freezing on a stale frame. Both cadences are the protocol's (pedal_link.h).
static const unsigned long HELLO_MS = PEDAL_LINK_HELLO_MS;
static const unsigned long FRAME_TIMEOUT_MS = PEDAL_LINK_FRAME_TIMEOUT_MS;

static pedal_link_parser g_parser;
static pedal_state g_frame;
static bool g_haveFrame = false;
static unsigned long g_lastFrameMs = 0;
static unsigned long g_lastHelloMs = 0;
// How long the ring shows the master level after the encoder moves it, before
// it goes back to saying what the transport is doing. Armed with a flag rather
// than a deadline in the future: a bare `millis() + N` compared against `now`
// fires on its own initial value once millis() passes the halfway mark.
static const unsigned long GAIN_SHOW_MS = 900;
static unsigned long g_gainShownAt = 0;
static bool g_gainArmed = false;

static void sendFrame(const uint8_t *buf, size_t len) {
  LINK.write(buf, len);
}

static void sendHello() {
  uint8_t buf[PEDAL_LINK_MAX_FRAME];
  sendFrame(buf, pedal_link_encode_hello(FW_MAJOR, FW_MINOR, buf));
}

static void handleMessage(uint8_t type, const uint8_t *payload, uint8_t len) {
  switch (type) {
    case PEDAL_LINK_TYPE_STATE: {
      pedal_state decoded;
      if (pedal_link_decode_state(payload, len, &decoded)) {
        // The encoder is the master volume and has no pill of its own, so the
        // ring becomes the readout for a moment whenever the level moves.
        if (g_haveFrame && decoded.master_gain != g_frame.master_gain) {
          g_gainShownAt = millis();
          g_gainArmed = true;
        }
        g_frame = decoded;
        g_haveFrame = true;
        g_lastFrameMs = millis();
      }
      break;  // a malformed frame is dropped; the last good one is kept
    }
    default:
      break;
  }
}

static void pollLink() {
  while (LINK.available() > 0) {
    uint8_t type, len;
    const uint8_t *payload;
    if (pedal_link_parser_push(&g_parser, (uint8_t)LINK.read(), &type, &payload, &len)) {
      handleMessage(type, payload, len);
    }
  }
}

// ---- inputs -----------------------------------------------------------------------
static const unsigned long DEBOUNCE_MS = 8;
static bool g_btnStable[PEDAL_BTN_COUNT];
static bool g_btnLastRaw[PEDAL_BTN_COUNT];
static unsigned long g_btnRawSinceMs[PEDAL_BTN_COUNT];

static void pollButtons() {
  const unsigned long now = millis();
  for (uint8_t i = 0; i < PEDAL_BTN_COUNT; i++) {
    const bool raw = digitalRead(FSW_PIN[i]) == LOW;  // bare contact to GND
    // Restart the stability timer whenever the raw reading flips, so a change is
    // reported once the line has been steady for DEBOUNCE_MS on either edge.
    if (raw != g_btnLastRaw[i]) {
      g_btnLastRaw[i] = raw;
      g_btnRawSinceMs[i] = now;
      continue;
    }
    if (raw != g_btnStable[i] && now - g_btnRawSinceMs[i] >= DEBOUNCE_MS) {
      g_btnStable[i] = raw;
      uint8_t buf[PEDAL_LINK_MAX_FRAME];
      sendFrame(buf, pedal_link_encode_button(i, raw ? 1 : 0, buf));
    }
  }
}

// The EC11's detent is at BOTH-HIGH (11). One click walks 11 -> 10 -> 00 -> 01
// -> 11 one way and 11 -> 01 -> 00 -> 10 -> 11 the other, so the intermediate
// state seen LAST before returning to the detent names the direction.
//
// Counting all four transitions instead does not survive this board: pushing
// the two LED strips masks interrupts for about a millisecond every 20 ms, and
// a detent turned during that window arrives as a two-step jump, which a
// four-transition counter reads as no movement at all. It stalls forever
// rather than merely lagging — the encoder worked with the panel dark and died
// the moment segno started sending frames (bench, 2026-09-03). Remembering the
// last intermediate state needs to see only ONE of the three, so a masked
// window costs precision, never a whole click. Footswitches were never
// affected: their 8 ms debounce outlives any push.
//
// Sampled from a pin-change interrupt AND from the loop, including either side
// of the LED pushes: whichever sees the edge first records it, and the other
// finds nothing to do.
static const uint8_t ENC_DETENT = 3;      // both lines high, between clicks
static volatile uint8_t g_encLast = ENC_DETENT;
static volatile uint8_t g_encMark = 0;    // last intermediate state, 0 = none
static volatile int8_t g_encDetents = 0;  // whole clicks the link still owes

static void encoderSample() {
  const uint8_t cur = (uint8_t)((digitalRead(PIN_ENC_A) << 1) | digitalRead(PIN_ENC_B));
  if (cur == g_encLast) return;
  g_encLast = cur;
  if (cur == ENC_DETENT) {
    // Saturate rather than wrap: a spin faster than the link drains is worth
    // a lost click, never a reversed one.
    if (g_encMark == 1 && g_encDetents < 127) g_encDetents++;
    if (g_encMark == 2 && g_encDetents > -128) g_encDetents--;
    g_encMark = 0;
    return;
  }
  // 01 and 10 name a direction; 00 is the midpoint and names none, so it
  // leaves the mark alone.
  if (cur == 1 || cur == 2) g_encMark = cur;
}

// Samples from the main loop. The ISR can preempt any instruction of
// encoderSample(), and the two share every variable it touches, so a
// half-applied sample would race an ISR's: one click could be credited twice,
// or the wrong way. Mask for the handful of instructions it takes.
static void encoderSampleFromLoop() {
  noInterrupts();
  encoderSample();
  interrupts();
}

// Drains whole clicks the sampler counted, one ENCODER message each.
static void pollEncoder() {
  encoderSampleFromLoop();
  for (;;) {
    // The common case by far is nothing owed; read it before masking.
    if (!g_encDetents) return;
    noInterrupts();
    const int8_t owed = g_encDetents;
    if (owed > 0) {
      g_encDetents--;
    } else if (owed < 0) {
      g_encDetents++;
    }
    interrupts();
    if (!owed) return;
    uint8_t buf[PEDAL_LINK_MAX_FRAME];
    sendFrame(buf, pedal_link_encode_encoder(owed > 0 ? 1 : -1, buf));
  }
}

// The encoder's push switch: a bare contact to GND like a footswitch, and
// debounced the same way, one ENCODER_BUTTON message per stable edge.
static bool g_encSwStable = false;
static bool g_encSwLastRaw = false;
static unsigned long g_encSwRawSinceMs = 0;

static void pollEncoderButton() {
  const unsigned long now = millis();
  const bool raw = digitalRead(PIN_ENC_SW) == LOW;
  if (raw != g_encSwLastRaw) {
    g_encSwLastRaw = raw;
    g_encSwRawSinceMs = now;
    return;
  }
  if (raw != g_encSwStable && now - g_encSwRawSinceMs >= DEBOUNCE_MS) {
    g_encSwStable = raw;
    uint8_t buf[PEDAL_LINK_MAX_FRAME];
    sendFrame(buf, pedal_link_encode_encoder_button(raw ? 1 : 0, buf));
  }
}

// ---- CTRL jacks --------------------------------------------------------------
// One jack takes an expression pedal OR a footswitch, and nobody tells the
// board which. A switch only ever sits at the rails; a pot passes through the
// middle and stays there. So a jack is unknown until it is caught HOLDING an
// intermediate reading, and from then on it is an expression pedal. Measured
// on the bench (2026-09-03): a BOSS FS-6 reads 10 and 4095, an M-Audio EX-P
// sweeps 385..4095.
//
// Three things used to make plugging in and out weird, and this block is
// shaped around them:
//   * A plug sliding in brushes the tip past the other contacts for tens of
//     ms and reads 0 or 4095 on the way. On an expression jack that was a
//     reported slam to one end. Now a jump of CTRL_JUMP or more between two
//     samples starts a quiet period, and nothing is reported until the reading
//     has held still for CTRL_SETTLE_MS. Feet cannot do that; plugs do.
//   * An EMPTY jack reads 4095 -- exactly full toe. Pulling a pedal out drove
//     its target to 100% and left it there. Now a jump that lands on the top
//     rail and stays there for CTRL_DETACH_MS is reported as KIND_NONE, and the
//     app holds whatever the pedal was doing. (A real toe is reached by
//     motion, not by a jump; a hard kick still moves in steps well under
//     CTRL_JUMP at 10 ms sampling.) With a switched jack (board v3) presence
//     is a wire and none of this guessing is needed for it.
//   * The classification was one-way per boot: once an expression pedal, a
//     jack read a later footswitch as a pedal parked at an end. NONE resets
//     it, and a switch jack only becomes an expression jack once a mid-scale
//     reading has HELD for CTRL_SETTLE_MS -- a plug transient never counts.
//   * Pressing a footswitch IS a rail-to-rail jump, so the quiet period above
//     swallowed it: every press and every release was reported ~210 ms late.
//     A jack only has to wait out a jump while a plug might still be arriving
//     -- while it is unknown or empty. Once the board knows the jack holds a
//     footswitch, an edge on it is a foot, debounced at 8 ms and sent at once.
//     The first press after a plug pays the settle time; no later one does.
//   * The ring contact sees the plug's TIP slide past on the way in and out
//     (the ring contact sits shallower than the tip contact), and with an
//     expression pedal that tip is a pot wiper dragged low while the plug's
//     ring brushes the sleeve spring. Read as a switch, that was "footswitch
//     B pressed" on a jack with no footswitch. So the ring is not a switch
//     until it has EARNED it: while the jack is unknown or empty, a ring
//     closure must hold for CTRL_SETTLE_MS (the first B press is late by
//     that much, the rest are debounced like any switch); a jump on the tip
//     silences the ring for the same quiet period; and a jack that turns out
//     to be an expression pedal has no ring switch at all -- its ring is the
//     pot's supply. On v2 only one hole is left: a jack already known as a
//     switch (a footswitch pulled out unseen) gets a pedal plugged in, and
//     the wiper's brush reports one B press before the pot reclassifies the
//     jack. A v3 jack's presence contact resets the jack to unknown first.
static const uint16_t CTRL_MAX = 4095;
// Below: switch closed. A sixteenth of the way up, well over a footswitch's
// contact (10 raw on a BOSS FS-6) and under the lowest an expression pedal's
// heel reads (385 raw on an M-Audio EX-P) -- otherwise a pedal plugged in at
// its heel was one closed switch until it moved.
static const uint16_t CTRL_LOW = CTRL_MAX / 16;
static const uint16_t CTRL_HIGH = CTRL_MAX - CTRL_MAX / 8;  // above: open / empty
static const uint16_t CTRL_DEADBAND = 24;  // ~0.6%, above the noise floor
static const uint16_t CTRL_JUMP = CTRL_MAX * 2 / 5;   // 40% in one 10 ms sample
static const unsigned long CTRL_SWITCH_DEBOUNCE_MS = 8;
static const unsigned long CTRL_SAMPLE_MS = 10;
static const unsigned long CTRL_SETTLE_MS = 200;      // quiet before trusting
static const unsigned long CTRL_DETACH_MS = 1000;     // at the rail after a jump
static const unsigned long CTRL_PRESENT_DEBOUNCE_MS = 50;

// An expression pedal never uses the whole scale: the tip's 10k pull-up and
// the 1k feeding the pot's top compress both ends, and every pedal's travel
// and range knob differ again (an M-Audio EX-P covers 385..4095 of 0..4095).
// Where the ends really are is NOT decided here. This board forgets everything
// at power-off, so it reports the raw position and segno learns the ends --
// deliberately, from a sweep the user makes -- and keeps them across reboots.
enum { CTRL_UNKNOWN = 0, CTRL_SWITCH, CTRL_EXPRESSION, CTRL_NONE };
static uint8_t g_ctrlKind[PEDAL_CTRL_COUNT];
static uint16_t g_ctrlRaw[PEDAL_CTRL_COUNT];
static uint8_t g_ctrlSent[PEDAL_CTRL_COUNT];
static bool g_ctrlHaveSent[PEDAL_CTRL_COUNT];
static unsigned long g_ctrlQuietUntilMs[PEDAL_CTRL_COUNT];   // settling after a jump
static unsigned long g_ctrlMidSinceMs[PEDAL_CTRL_COUNT];     // mid-scale held since
static unsigned long g_ctrlRailSinceMs[PEDAL_CTRL_COUNT];    // top rail after a jump since
static bool g_ctrlJumped[PEDAL_CTRL_COUNT];                  // the last big move was a jump
static bool g_ctrlPresentRaw[PEDAL_CTRL_COUNT];
static bool g_ctrlPresent[PEDAL_CTRL_COUNT];
static unsigned long g_ctrlPresentSinceMs[PEDAL_CTRL_COUNT];
// One debounced switch per contact: [jack][contact].
static bool g_ctrlSwitchClosed[PEDAL_CTRL_COUNT][PEDAL_CTRL_CONTACT_COUNT];
static bool g_ctrlSwitchRaw[PEDAL_CTRL_COUNT][PEDAL_CTRL_CONTACT_COUNT];
static unsigned long g_ctrlSwitchSinceMs[PEDAL_CTRL_COUNT][PEDAL_CTRL_CONTACT_COUNT];
static unsigned long g_ctrlLastSampleMs = 0;

static uint16_t ctrlSample(uint8_t pin) {
  uint32_t total = 0;
  for (uint8_t i = 0; i < 8; i++) total += analogRead(pin);
  return (uint16_t)(total / 8);
}

static void sendCtrl(uint8_t jack, uint8_t contact, uint8_t kind, uint8_t value) {
  uint8_t buf[PEDAL_LINK_MAX_FRAME];
  sendFrame(buf, pedal_link_encode_ctrl(jack, contact, kind, value, buf));
  if (contact == PEDAL_CTRL_TIP && kind == PEDAL_CTRL_KIND_EXPRESSION) {
    g_ctrlSent[jack] = value;
    g_ctrlHaveSent[jack] = true;
  }
}

// Debounced on both edges like the footswitches. `closed` is the contact at
// ground; reports the edge once it has held for CTRL_SWITCH_DEBOUNCE_MS.
static void pollCtrlSwitch(uint8_t jack, uint8_t contact, bool closed, unsigned long now) {
  if (closed != g_ctrlSwitchRaw[jack][contact]) {
    g_ctrlSwitchRaw[jack][contact] = closed;
    g_ctrlSwitchSinceMs[jack][contact] = now;
    return;
  }
  if (closed != g_ctrlSwitchClosed[jack][contact] &&
      now - g_ctrlSwitchSinceMs[jack][contact] >= CTRL_SWITCH_DEBOUNCE_MS) {
    g_ctrlSwitchClosed[jack][contact] = closed;
    sendCtrl(jack, contact, PEDAL_CTRL_KIND_SWITCH, closed ? 255 : 0);
  }
}

// The jack has nothing on it: say so once, forget what it was, and start
// again from unknown on the next plug.
// The ring: a switch on a two-switch pedal, a supply on an expression pedal,
// and a contact the plug's tip brushes on its way past either way. Only
// reached once the tip is out of its quiet period. On a jack already known
// as a switch an edge is a press, debounced like the tip; anywhere else a
// closure has to hold for CTRL_SETTLE_MS before it counts, and counting makes
// the jack a switch. An expression jack's ring is never a switch.
static void pollCtrlRing(uint8_t jack, unsigned long now) {
  const bool closed = digitalRead(CTRL_RING_PIN[jack]) == LOW;
  if (g_ctrlKind[jack] == CTRL_EXPRESSION) {
    g_ctrlSwitchRaw[jack][PEDAL_CTRL_RING] = closed;
    return;
  }
  if (g_ctrlKind[jack] == CTRL_SWITCH) {
    pollCtrlSwitch(jack, PEDAL_CTRL_RING, closed, now);
    return;
  }
  if (closed != g_ctrlSwitchRaw[jack][PEDAL_CTRL_RING]) {
    g_ctrlSwitchRaw[jack][PEDAL_CTRL_RING] = closed;
    g_ctrlSwitchSinceMs[jack][PEDAL_CTRL_RING] = now;
    return;
  }
  if (closed && !g_ctrlSwitchClosed[jack][PEDAL_CTRL_RING] &&
      now - g_ctrlSwitchSinceMs[jack][PEDAL_CTRL_RING] >= CTRL_SETTLE_MS) {
    g_ctrlKind[jack] = CTRL_SWITCH;
    g_ctrlSwitchClosed[jack][PEDAL_CTRL_RING] = true;
    sendCtrl(jack, PEDAL_CTRL_RING, PEDAL_CTRL_KIND_SWITCH, 255);
  }
}

// A lost source is not a physical release gesture. Reset contact state
// silently; the whole-jack NONE frame retires application obligations.
static void ctrlResetSwitch(uint8_t jack, uint8_t contact) {
  g_ctrlSwitchRaw[jack][contact] = false;
  g_ctrlSwitchClosed[jack][contact] = false;
  g_ctrlSwitchSinceMs[jack][contact] = 0;
}
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
void loop() {
  pollLink();
  pollButtons();
  pollEncoder();
  pollEncoderButton();
  pollCtrl();

  const unsigned long now = millis();
  if (now - g_lastHelloMs >= HELLO_MS) {
    g_lastHelloMs = now;
    sendHello();
    digitalWrite(LED_BUILTIN, !digitalRead(LED_BUILTIN));  // 0.5 Hz heartbeat
  }
  if (g_haveFrame && now - g_lastFrameMs > FRAME_TIMEOUT_MS) {
    g_haveFrame = false;
  }
  if (now - g_lastRenderMs >= RENDER_MS) {
    g_lastRenderMs = now;
    const bool refresh = now - g_lastRefreshMs >= REFRESH_MS;
    if (refresh) g_lastRefreshMs = now;
    const bool ringChanged = renderRing();
    const bool indicatorsChanged = renderIndicators();
    // show() masks interrupts briefly: drain the link and sample the encoder
    // either side of each push so a click turned across one cannot be lost.
    pollLink();
    encoderSampleFromLoop();
    if (ringChanged || refresh) showRing();
    encoderSampleFromLoop();
    if (indicatorsChanged || refresh) {
      if (refresh) ind.Dirty();
      ind.Show();
    }
    encoderSampleFromLoop();
    pollLink();
  }
}

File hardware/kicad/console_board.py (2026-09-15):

"""SKiDL generator for the Segno CONSOLE board v2 (issue #747).

The 10-pedal console's control board. Lies flat on the bottom plate beside the
Raspberry Pi 5 and links to it over a KEYED 2x20 ribbon -- a stock ~10 cm part:
both boards live under the 16" screen with the Pi ~30 mm away, and the five
rear-panel stations the board terminates sit directly above it (the cluster moved
with the boards). See board_mounts() and REAR_IO_U in segno_enclosure.py, which
own the geometry. Carries a **Pico 2 (RP2350)** module, the MIDI front end, and a
JST header for every pedal and every rear-panel connector.

Run (from hardware/kicad/):
    ./.venv/bin/python console_board.py            # netlist + gates
    ./.venv/bin/python console_board.py --selftest # prove the gates bite

Why this board exists
---------------------
The Pi 5's four USB-A ports are exactly consumed -- two touchscreens, two rear
panel couplers -- and a hub is ruled out, so the retired V1 pedal board could not
have one. Its only hardware UART was already the DIN-5 pair, so MIDI moves to the
Pi and the MCU gets a UART of its own. See
docs/brainstorm/2026-08-17-console-board-v2-brainstorm-doc.md.

An MCU still has to exist: rpi_ws281x drives the legacy PWM/PCM+DMA peripherals and
does NOT support Pi 5, whose I/O moved to RP1. The retired RP2040 LED driver already
offloaded WS2812 timing to an MCU for exactly that reason; firmware/console_board/
carries that job now (pedal_link.h is the wire format).

THE PICO DELETED THE LEVEL-SHIFTING PROBLEM
-------------------------------------------
The old plan (the 5 V AVR board of the retired pedal) needed a 1k8/3k3 divider and an AHCT gate on the
MCU link; the RP2350 is **3.3 V, the same as the Pi**, so the link needs no
level shifting in either direction. It is not bare wire, though: R17/R18 put
10 k in series, bounding the current that flows when one power domain is up and
the other is not (see their comment block). segno_wiring.md section 3 carries
the harness-facing version of this story.

The 74AHCT125 is still here, but for the three places that genuinely cross 3.3 -> 5:
  * MIDI OUT   -- the Pi's 3.3 V TX cannot drive a 5 V MIDI current loop
  * ring data  -- WS2812 wants a 5 V logic high
  * indicator data -- same
MIDI IN needs no shifter at all: the H11L1 is a Schmitt LOGIC-output opto, so run
it from 3.3 V and it feeds the Pi directly.

Ref-designator blocks (allocated up front -- the retired V1 generator had to pin ref="C16" to
stop a late addition renumbering C1..C15 and invalidating a started layout):
    J1  Pico 2          J2  Pi ribbon      J3  power in     J4  MIDI OUT
    J5  MIDI IN         J6  ring/encoder   J7  indicators   J8  power button
    J9  Pi power-button pads (through-lead)                 J10..J19 footswitches
    J20/J21 CTRL 1/2    U1  74AHCT125      U2  H11L1
    R14..R16 idle-state pull-downs (U1's inputs)            R17/R18 link series
"""
import json
import os
import re
import sys
import tempfile

import netlist
from skidl import (
    Pin,
    Part, Net, generate_netlist, ERC, POWER, set_default_tool, KICAD8,
    lib_search_paths,
)

set_default_tool(KICAD8)

# SKiDL puts the active circuit in builtins rather than exporting it, and the
# POLARITY gate below wants EVERY part, not a list this file remembers to update.
from builtins import default_circuit          # noqa: E402  (set up by skidl)

_SYMBOL_DIRS = [
    os.environ.get("KICAD_SYMBOL_DIR", ""),
    r"C:\Program Files\KiCad\10.0\share\kicad\symbols",
    r"C:\Program Files\KiCad\9.0\share\kicad\symbols",
    "/Applications/KiCad/KiCad.app/Contents/SharedSupport/symbols",   # KiCad 8+ macOS
    "/Applications/KiCad.app/Contents/SharedSupport/symbols",         # older macOS layout
    "/usr/share/kicad/symbols",
]
for _d in _SYMBOL_DIRS:
    if _d and os.path.isdir(_d):
        lib_search_paths[KICAD8].append(_d)

HERE = os.path.dirname(os.path.abspath(__file__))
STATIONS_JSON = os.path.join(HERE, "..", "enclosure", "out", "rear_io_stations.json")

R_FP = "Resistor_THT:R_Axial_DIN0207_L6.3mm_D2.5mm_P10.16mm_Horizontal"
# 2.50 mm lead pitch, not 5.00. Commodity "104" discs and MLCCs ship on 2.5 mm
# spacing; the 5 mm land would have meant splaying the leads on all 16 of them, or
# hunting an unusual part. Changing the board is cheaper than changing the BOM.
# (C30 is the opposite case and keeps its 10 mm / 5 mm land -- order a 470uF at
# 25 V or 35 V, since the common 16 V part is 8 x 11.5 mm on 3.5 mm pitch and will
# not physically fit.)
C_FP = "Capacitor_THT:C_Disc_D5.0mm_W2.5mm_P2.50mm"
JST = "Connector_JST:JST_XH_B%dB-XH-A_1x%02d_P2.50mm_Vertical"


def R(value, **kw):
    return Part("Device", "R", value=value, footprint=R_FP, **kw)


def C(value, fp=C_FP, **kw):
    return Part("Device", "C", value=value, footprint=fp, **kw)
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

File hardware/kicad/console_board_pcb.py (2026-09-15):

"""pcbnew layout generator for the Segno CONSOLE board v3 (issue #747; v3: #987 ring link, CTRL ring sense).

Consumes `console_board.net` -- the SKiDL netlist is the single source of truth for
what connects to what -- and emits a placed, routed, poured, DRC-clean board plus a
JLCPCB-ready gerber zip.

Run (from hardware/kicad/, with KiCad's own Python, which is the one that has pcbnew):
    /Applications/KiCad/KiCad.app/Contents/Frameworks/Python.framework/Versions/Current/bin/python3 console_board_pcb.py

Modelled on hardware/led_strip/ledstrip_pcb.py, which already does the
place -> pour -> DRC -> kicad-cli -> zip pipeline for the LED strip.

PLACEMENT DRIVES ROUTING
------------------------
No autorouter. The board is laid out so routing is nearly trivial: every connector
sits in the SAME left-to-right order as the Pico pads it serves, so each fan-out
diverges without crossing and routes on one layer. Ordering is a gate, not a hope --
_check() proves no signal net has to cross another before a single track is drawn.

GND is not routed at all: it is a pour on both layers, and every GND pad gets its
own via BESIDE it -- never on it, since a via on a plated hole is a second drill hit
at the same coordinate and a via in an SMD pad starves the joint.
"""
import json
import math
import os
import shutil
import subprocess
import sys

import pcbnew

from netlist import parse_netlist

FromMM, ToMM = pcbnew.FromMM, pcbnew.ToMM
HERE = os.path.dirname(os.path.abspath(__file__))
NETLIST = os.path.join(HERE, "console_board.net")
OUT = os.path.join(HERE, "out_console")
BOARD_PATH = os.path.join(OUT, "segno_console_board.kicad_pcb")   # ROUTED: the
# deliverable, written only by the routing pipeline. build() does NOT touch it --
# it writes PLACED_PATH, and route_console_board.sh copies that over BOARD_PATH
# before importing the session. Placement used to write the deliverable directly,
# so running the generator on its own quietly replaced a routed, DRC-clean board
# with an unrouted one, and the next thing to read it (a fab check, a commit) was
# looking at a different board than the one that passed.
PLACED_PATH = os.path.join(OUT, "console.placed.kicad_pcb")       # PLACED only
KICAD_CLI = "/Applications/KiCad/KiCad.app/Contents/MacOS/kicad-cli"
KICAD_FP = "/Applications/KiCad/KiCad.app/Contents/SharedSupport/footprints"
LOCAL_FP = os.path.join(HERE, "segno.pretty")

ORIGIN = (100.0, 60.0)          # board origin on the KiCad page
# 99.5 square, and the number is the whole point: every prototype fab prices
# 2-layer boards in a cheap tier that stops at 100 x 100 mm, and 115 mm of width was
# over it for no structural reason -- the enclosure bay is 342 x 193, so nothing
# mechanical wanted those 15 mm.
#
# 99.5 rather than 100.0 because Edge.Cuts is drawn with a 0.1 mm line, so a 100.0
# outline measures 100.1 across the OUTSIDE of it. Most fabs quote from the line
# centre and would not care; the half millimetre costs nothing here and means no
# CAM operator has to make that call on our behalf.
#
# The width is now set by ONE thing: the footswitch row. Ten JST XH at an 8.5 mm
# courtyard plus the 0.8 mm keepout is 92.2 mm of the 100, which is why the pitch
# below is at its floor and why the row is the first thing to check if this board
# ever has to get smaller again. (It cannot, without giving up one connector per
# pedal.) Everything else fits inside that with room: the widest other row is
# J3 + the module + U1 + the ribbon, at 80.5 mm.
BW, BH = 99.5, 99.5             # see FLOORPLAN below
EDGE_R = 3.0                    # corner radius
MOUNT_INSET = 5.0               # mounting-hole centres, in from each corner.
# The holes are NOT synthesised here any more: H1..H4 come out of the netlist like
# every other part, because one of them carries GND. A chassis bond is a connection,
# so it belongs in the netlist, and placing them from PLACEMENT below means the
# auto-placer sees them before it looks for slots -- which is what stopped a passive
# landing on H2 back when they were added afterwards.
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

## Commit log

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2026-08-14 fix(engine): the track meter shows the track, not lane 0 (#657)
    le_fill_track_snapshot read lanes[0]'s rms/peak and reported them as the
    TRACK's, so a track playing several layers was metered by whichever one
    happened to be lane 0. Worst case: lane 0 quiet or cleared while the other
    lanes carry the loop, and the meter reads near-silent on an audibly loud track.
    There was no track-level mixed meter to read instead -- frame_trk_peak exists
    but is a max across lanes for the visualizer, not a mix. So this measures the
    real thing: the lanes summed per frame, accumulated over the block exactly the
    way the per-lane figures already are, published on new per-track atomics.
    Sums the same dry loopsam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
    [engine_private.h]
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2026-08-16 feat(engine): the inputs gain a conditioning stage (#700)
    * feat(engine): the inputs gain a conditioning stage
    Input conditioning S1 (#697): a fixed per-input utility stage — 2nd-order
    Butterworth HPF, up to 8 fixed-Q mains-hum notches, and a no-lookahead
    downward expander — run once per block into a preallocated conditioned
    copy of the interleaved input, upstream of BOTH the lane fan-out and the
    monitor split (WYSIWYG: the performer hears exactly what records).
    Metering, the clip path, and the latency harness keep reading the RAW
    buffer; loopback-excluded channels are never conditioned; the
    sound-activated record trigger deliberately switches to the conditioned
    magnitude so hum cannot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
    [engine_core.h, engine_private.h]
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2026-08-16 fix(engine): dropped capture periods get counted and flagged (#715)
    * fix(engine): dropped capture periods get counted and flagged
    The capture path substitutes silence in exactly one place —
    `le_pd_catch_up` in perf_drain.c, which tops each capture file up to the
    engine's elapsed frame count when the audio that should have filled it
    never arrived. Nothing counted it: `a_perf_overruns` only sees frames the
    AUDIO thread failed to enqueue, so a take could carry period-exact runs of
    digital silence and still report `overrun_count: 0`, which is how the
    completion dialog's hadGlitch banner stayed dark through audible flickers
    (#710).
    Honesty: a new `a_perf_zero_filled_frames` atomic counts the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
    [engine_private.h]
2026-08-16 fix(engine): the x86 include path and the macOS forwarders CI needs (#720)
    Two independent breaks on master, both invisible on an arm64 dev machine:
    - x86 hosts pull rnnoise's vec_avx.h, whose x86/x86cpu.h includes
    "common.h" relative to src/x86/ and misses the header one level up.
    Upstream builds with src/ on the include path; now so do the CMake
    target and the native test runner. Broke native-tests, native-tests-asan
    and build-linux from #699 onward — the ARM dev path never reaches it.
    - The macOS SPM and CocoaPods forwarder sets never gained engine_cond.c
    (#700), restore_declip.c or restore_halfband.c (#708), so build-macos
    failed to link _le_cond_*. plugin_disabled.c stay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
    [segno_pedal_base_gauge.dxf]
2026-08-16 fix(appliance): the ALSA-only pin reaches device enumeration (#723)
    * fix(appliance): the ALSA-only pin reaches device enumeration
    Device enumeration and loopback detection opened their transient probe
    contexts with ma_context_init(NULL, 0, ...), which walks miniaudio's whole
    default backend list in ma_backend enum order — and that order puts
    ma_backend_pulseaudio ahead of ma_backend_alsa. The SEGNO_ALSA_ONLY pin
    reached only le_engine_start, so on the appliance (no PulseAudio server in
    the image) every enumeration poll attempted a Pulse connection that could
    only fail.
    Each failed attempt leaked a file descriptor: miniaudio's
    ma_init_pa_mainloop_and_pa_context__pulse frees the mainloop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
    [engine_private.h]
2026-08-17 fix(engine): every loop seam gets the crossfade, not just the first take (#732)
    * fix(engine): every loop seam gets the crossfade, not just the first take
    The engine had exactly one crossfade and it only ever applied to the defining
    master's own take: `request_master_finalize` defers that finalize by ~10 ms to
    capture the performance past the loop point, and `finalize_master_xfade` folds
    that overlap into the head so the wrap is continuous. Every OTHER track goes
    through `finalize_new_track`, which never crossfaded anything — its head holds
    the moment the take started and its tail the moment it ended, a whole lap
    apart, so the wrap splices once per loop cycle for as long as the take lives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
    [engine_private.h]
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2026-08-17 feat(engine): the audio callback finally reports its own lateness (#724)
    * feat(engine): the audio callback finally reports its own lateness
    Part of #722. Observation only: no audio behaviour changes.
    The appliance clicks only while a performance capture is armed, and
    nothing measured whether the audio callback was missing its deadline —
    le_snapshot.xrun_count was fed solely by the Windows ASIO overload
    notification, so on Linux/macOS it read a flat 0 forever.
    Three instruments, all inside the miniaudio data callback:
    - per-callback duration against the period budget (buffer_frames /
    sample_rate): running max, mean, an over-budget tally, and an
    eight-bucket histogram in eighths of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
    [engine_private.h]
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2026-08-18 feat(enclosure): fit-test jig for the pedal's base screw holes (#717)
    * feat(enclosure): fit-test jig for the pedal's base screw holes
    The WTB-006's underside carries four M3-ish holes we want to bolt the pedal
    down through, retiring the pedestal's provisional gravity+pocket retention.
    The holes sit under the anti-slip pad, so both rows are dimensioned off the
    side screw axis -- the only datum findable without pulling the pad.
    Before those numbers get cut into the real pedestal decks as insert bores,
    prove them on a throwaway print: a plate carrying only the four locating pins
    and the two side columns that capture the horizontal screw bosses (the same
    SKIRT_BOSS_CH_* channel idiom the tray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
    [segno_assembly.step, segno_base.dxf, segno_corner_bracket_rear.dxf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]
2026-08-18 feat(hardware): console_board.py — the console board v2 netlist, gated (#749)
    * feat(hardware): console_board.py — the v2 netlist, gated
    Part 3 of #747. 49 components, 39 nets, ZERO ERC errors and zero warnings.
    Six negative controls, each biting its own gate.
    THE PICO DELETED THE LEVEL-SHIFTING PROBLEM. segno_wiring.md section 2b
    specifies a 1k8/3k3 divider plus an AHCT gate on the MCU link. That was
    written for a Pro Micro at 5 V against a Pi that is not 5 V tolerant. The
    RP2350 is 3.3 V, the SAME as the Pi, so the link is a direct wire both ways
    -- no divider, no buffer, nothing to get wrong. Choosing the Pico dissolved
    the problem rather than solving it, and I nearly implemented th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
    [console.placed.kicad_pcb, segno_assembly.step, segno_base.dxf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]
2026-08-18 fix(hardware): console board v2 review follow-ups -- idle states, gate gaps, doc drift (#756)
    * fix(hardware): the gates learn the resistive failure, and _check() stops repeating itself
    Review follow-ups on the v2 board (#747), the checking half:
    RING_LEVELS is new. PICO_LEVELS and PI_LEVELS check nets that TOUCH 5 V
    directly -- but the failure that motivated them (ring_board's 10k pull-ups to
    its 5 V rail, 1.4 V over the RP2350's absolute maximum) bridges two nets
    through a resistor, which keeps them separate and both gates green. And
    RING_CONTRACT cannot see it either: a re-added pull-up changes no pin's net,
    so the positional map stays clean. The new gate walks ring_board.net for a
    resi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
    [console.placed.kicad_pcb, segno_combined_bom_lcsc.csv, segno_console_board.kicad_pcb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]
2026-08-18 feat(enclosure): the rear I/O panel comes off again, centred on the 16in screen (#757)
    * feat(enclosure): the rear I/O panel comes off again, centred on the 16in screen
    Re-land of c2f9ab06 (reverted with the Fusion CAD-flat experiment, not on its
    merits), adapted to everything that landed since: the PD-era station list
    (PD_IN's D punch supersedes the 9 V barrel), the two-buck BUCK_SPLIT gates,
    and the review-loop's grounding-doc edits -- the stud list now carries BOTH
    the panel's single-bolt bond rule and the 20 V PD / buck-shell items, and the
    bench audit checks the panel's masked bolt alongside the buck shells.
    Original design, unchanged: the wall gets a window and a bolt-on panel
    carrie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
    [segno_assembly.step, segno_base.dxf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]
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2026-08-20 fix(enclosure): lid development fixes -- pedal apertures, front wall knuckle, lid seat (#760) (#761)
    * fix(enclosure): pedal apertures get the lid development offset (#760)
    The platform stack converts lid-v to plan as v*cos(SLOPE), but the
    developed lid's content v=0 lands at plan -(DEV90+T)+DD_LIP*cos, not 0
    (rear-seam solver, #237). Raw-v apertures therefore cut ~2.6mm forward
    of the pedals the floor actually places, and the pedal rear edge fouls
    the slot. PEDAL_AP_DEV carries the correction on the 10 slot cuts only;
    labels, LED pills, screens and the whole platform stack keep the frozen
    approved layout. Outputs regenerated.
    * fix(enclosure): drop the front wall below the lip-fold knuckl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
    [screen7_module_measured.step, segno_assembly.step, segno_base.dxf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]
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2026-08-20 chore(enclosure): make the verifiers check the real metal (#767) (#771)
    Items 1-4 of the 2026-08-19 review sweep -- the verifier-integrity debt the
    owner wants closed BEFORE the metal order. All four are the same disease: a
    verifier checking a frozen copy instead of the geometry it is meant to police.
    No fab dimension changes except POST_H, and that moves 0.026 mm.
    1. _fold_from_dxf: the ring stack (lid_ring / lid_ringmetal / lid_knob) was
    placed at PEDAL_ROW2_V, but faceplate_holes() cuts RING/ENCODER at ENC_V --
    the encoder deliberately does NOT follow CLEAR/BANK rearward. The fold
    render and the collision audit were checking the ring 35.5 mm from its own
    hole. Moved to ENC_V.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
    [segno_assembly.step, segno_base.dxf, segno_corner_bracket_rear.dxf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]
2026-08-21 fix(enclosure): the fold audit's 28 collisions were two verifier bugs (#767) (#772)
    The revived fold audit (#771) reported 28 ERRORs nobody had ever seen. None
    of them is real interference -- the metal is fine. Both causes were in the
    verifier itself:
    1. The pedal stand-in was built in WORLD axes but placed in the PEDESTAL
    frame, missing the 90-degree spin the ring and sled under it get. So
    PEDAL_D (109.87) lay across u, where the pedals are pitched 101.14 apart:
    ten placeholders each 8.73 too wide, overlapping their neighbours and
    ploughing into their own tub walls. That is the whole pedal<->pedal
    (16591 mm^3 x9) and ring<->pedal (6329 mm^3 x10) population. The metal
    disa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
    [segno_assembly.step, segno_base.dxf, segno_corner_bracket_rear.dxf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]
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2026-08-21 feat(hardware): Cherub silent switch platform, exported from Fusion (#729) (#769)
    The part is hand-authored in the Fusion document 'Cherub WTB-006 silent
    switch platform'; this commits its STEP + STL exports (66.85 x 57.38 x
    10.60 mm) as the deliverable, with a README pinning the source of truth and
    the re-export recipe.
    Supersedes the abandoned CadQuery generator (PR #764, closed): its default
    PIN_CLEARANCE built a 12.1 mm box whose stem overshot the pedal interior by
    ~3 mm so the lid could not close, and the clearance question was never
    settled. The Fusion part solves it at 10.60 mm. Refs #729 -- the issue stays
    open until a printed platform is confirmed in the shell (blocked-verify).
    [switch_platform.step, switch_platform.stl]
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2026-08-21 fix(enclosure): the drawings hid 127 vent louvres and called the steel post aluminium (#775) (#777)
    The #775 DFM sweep found six RED items, and all six live in the document path,
    not the geometry engine. `_check()` gates the geometry hard; nothing gated the
    drawings or the vendor packages at all.
    - R1 `dxf_to_pdf` forced only `CUT` black, so `VENT` (ACI 7) rendered white on a
    white sheet: 127 louvres, 18 425 mm2, ~5.6 m of cut path invisible on every
    PDF ever generated. `_force_pdf_layer_colours()` now blackens every declared
    through-cut layer and asserts that no geometry layer is left at ACI 7.
    Measured at 300 dpi in the DXF's own vent fields, same calibration both runs
    (1.9816 p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
    [segno_assembly.step, segno_base.dxf, segno_corner_bracket_rear.dxf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]
2026-08-21 feat(enclosure): the drawings speak Spanish, and every sheet states its tolerances (#780)
    The parts are fabricated in Argentina. Every instruction on the drawing package
    was English, and a fold direction read off a flat pattern is exactly the kind of
    sentence a shop cannot afford to half-understand. All of it is now Spanish, and
    every sheet-metal sheet carries a general tolerance block it never had.
    Translated (everything a fabricator reads and acts on):
    - per-part NOTE strings on all seven flat patterns, plus the small in-drawing
    labels (buck bricks, Pi risers, support-post feet);
    - the layer legend, the bend-table heading, its column headers, every fold-line
    name and fold direction, a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
    [segno_assembly.step, segno_base.dxf, segno_corner_bracket_rear.dxf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]
2026-08-21 fix(enclosure): front-lip fit spec, in Spanish on the lid drawing (#775) (#781)
    The lid's front lip is drawn landing FLAT against the front wall -- measured
    lid-to-base minimum distance 0.0000 mm. Both are outside faces and everything
    is coated (no masking), so as drawn the joint is ~0.16 mm of interference
    before any tolerance, on the one seam that cannot be reworked after finishing.
    Fixed as a FIT, not a dimension. Moving it in geometry was tried and reverted:
    _cfy sets the flange LENGTH, not its standoff (raising it pushes the lip tip
    below the base floor). Real standoff would mean shifting the floor's front bend
    line -- re-basing every feature on the base flat -- or lengthening the lid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
    [segno_assembly.step, segno_base.dxf, segno_corner_bracket_rear.dxf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]
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2026-08-21 feat(hardware): the console board wears its own score -- silkscreen art (#784)
    Replaces #758, rebased onto master and with the gerbers regenerated so the
    repo can actually rebuild the boards that were already manufactured.
    The console board's silkscreen becomes a composition, generated from the
    project's own faces (Bravura's segno mark, SMuFL U+E047; JetBrains Mono).
    Front: the segno mark over the wordmark, in the clear pocket left of the 5V
    header. Back: a five-line staff with repeat dots running the full width,
    broken around the pads; a 32 mm segno centrepiece with the pad keep-outs
    boolean-carved out of the glyph (+0.8 mm clearance) so the mark flows around
    the through-holes; a generati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
    [segno_console_board-B_Cu.gbr, segno_console_board-B_Mask.gbr, segno_console_board-B_Paste.gbr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]
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2026-08-27 feat(engine): log perf-render facts — arm anchor, transport hold, per-take id (v4) (#874)
    * feat(engine): log perf-render facts — arm anchor, transport hold, per-take id (v4)
    Replace the offline renderer's two inferred anchors with two engine facts
    logged at the exact audio-thread frame, per the approved
    docs/plan/2026-08-25-fix-render-anchor-facts-plan.md design (#262 + #819).
    - LE_PLOG_PERF_ARMED (315): pushed when LE_CMD_PERF_ARM applies, carrying the
    master loop phase at capture frame 0 (position + master length + loop
    iteration). The renderer's arm-image anchor and its no-lock RECORD_END phase
    math now read this instead of the race-stale armSnapshot.clockFrame the
    control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
    [engine_private.h]
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2026-08-29 feat(engine): offline loop-close restoration worker (#697 S9) (#881)
    * feat(engine): offline loop-close restoration worker (#697 S9)
    Adds the S9 half of #697's restoration: a background worker that repairs a
    track's captured lanes after a loop closes and publishes the result as one
    lockstep undo layer, so a plain undo reverts to the raw take and the RT audio
    thread is untouched.
    - engine_restore.c/.h: a single-job worker mirroring engine_cache.c's [R2]
    contract (copy-at-enqueue with rev-bump abort, SPSC job, join-before-free at
    the three seams). Pipeline per opted lane: de-clip (restore_declip.c) then
    optional RNNoise denoise (48k passthrough / 96k half-band resample).
    - le_engine_re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
    [engine_private.h]
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2026-08-29 refactor(engine): tighten the resumable YIN contract and skip a dead memcpy
    Third review round on #912. Round 2's six items came back confirmed; these are
    what that pass turned up.
    le_yin_finish guarded the unlikely misuse (a caller ignoring le_yin_begin's
    return) and left the likelier one open: finishing before le_yin_step has
    reported done reads dp[tau..maxlag] uninitialised for exactly the same garbage
    period. The guard now covers both, and le_psola_detect_band checks
    le_yin_step's return rather than assuming it — a negative budget always
    completes, so the check can only pass; it is there so the one-shot path states
    the precondition instead of relying on it.
    le_yin_pass.n was write-on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
    [engine_private.h]
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2026-08-29 fix(hardware): the pedal name tiles are trapezoids, because the pad is (#923)
    * fix(hardware): the pedal name tiles are trapezoids, because the pad is (#922)
    54.45 was a transcribed constant. It entered #795 as a given -- "the WTB-006's
    top pad has a 54.55 x 20 window" -- and nothing ever derived it. The rule the
    owner actually gave is 5 mm of pad each side, ALWAYS, and the WTB-006 is a wedge
    IN PLAN as well as in height. A constant width can therefore only be right at one
    station along the tile's length, and is wrong at both of its ends.
    That is not cosmetic. The fit is a 0.05/side press into compliant rubber -- a
    clearance chosen in #795 precisely because 0.25/side let the pedal's own ca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
    [segno_pedal_tile_BANK.step, segno_pedal_tile_BANK.stl, segno_pedal_tile_CLEAR.step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]
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2026-09-04 feat(hardware): CTRL jacks are Neutrik NJ6FD-V, and the pre-order re-review fixes (#994)
    Closes #993
    CTRL jacks: Neutrik NJ6FD-V through a O12 hole; rear panel 1.5 mm 1050. Re-review fixes: corner-bracket rivets RI higher (bracket floats on the bend's inside radius), O3.3 rivet holes, post flat developed from outer lengths with the bolts 5 mm in from the foot edges, ring diffuser plate 1.2 mm with the disc lip attached, 1050 on every shop-facing string, readable shop notes on every sheet. Both Fusion docs rebuilt; every fastener hole coaxial; two independent reviews with all findings closed.
    [segno_assembly.step, segno_base.dxf, segno_corner_bracket_rear.dxf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]
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2026-09-05 fix(hardware): the drawings printed the part too small and the bend lines solid (#1002)
    Keep parts readable on shop sheets, preserve visible bend and mask patterns, wrap file notes, and separate tile dimensions and captions. Complete the rear-panel coating instructions and fail requested PDF rendering before packaging.
    Integrated the corrected tray dependency from #1005. Protected fabrication geometry is unchanged across 19 DXFs. All 19 PDFs / 22 pages were visually inspected, 44 focused CAD/PDF checks passed, all five independent reviews are clean, and all 20 checks passed on 72f3c24b.
    Closes #1001
    [segno_base.dxf, segno_corner_bracket_rear.dxf, segno_faceplate.dxf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]
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2026-09-09 fix(console): act on the slice-1 review findings
    Engine: configure drops the crown with the tracks it empties, a
    non-defining finalize reconciles the crown, and the snapshot publishes
    what a pending arm waits for (pending_trigger).
    Stage: the queued cue reads the engine's trigger (Sound / Loop start /
    grid) and names punch-out and section arms; the footer shows the
    count-in; the clip cap retires on a timer; wave rows and the second
    display read a waveform once per content change; the bar ruler paints
    in its own layer; the readout gate ignores a growing take and follows
    the cursor, not only the label.
    Package lint infos that failed CI are cleared.
    [engine_private.h]
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2026-09-09 fix(engine): close the slice-2a review findings
    A cancelled take that captured nothing acks its state command once; the
    cancel's control side no longer pre-zeroes the published length, since
    the audio thread declines a cancel that raced a finalize; a late cancel
    report is ignored after a clear or a fresh take; an undo queued behind a
    freezing clear restores the frozen take instead of peeling a layer; a
    freezing clear on a take with nothing captured keeps nothing.
    Multi's gate measures whole multiples of the shortest take (what Multi
    itself records); both threads measure against one base-channel helper;
    the switch into a shared-clock mode re-establishes the tempo grid.
    The remembered and pe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
    [engine_private.h]
2026-09-09 fix(engine): close the second slice-2a review round
    A record pressed behind a cancel in flight resets the grid the cancel
    would have set; an undo tapped behind a freezing clear on a recording
    take waits for the restore point; a clear right behind a queued restore
    measures the length the restore will publish and keeps a restore point;
    a declined or void cancel still reports so its flag never lingers; an
    empty track never shows peelable layers on the wire (the depth is held
    while a frozen point is pending or a restore is in flight, republished
    once applied — the fuzz suite's depths-sane invariant); a fresh capture
    drops the frozen take's layers with its pending point.
    The repository takes c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
    [engine_private.h]
2026-09-09 fix(engine): close the third slice-2a review round
    A clear right behind a queued restore records the master grid that
    restore re-establishes, not the wire's 0; a cancel of a take that
    captured nothing empties the track without the clear handler's
    layer-generation bump (only a control-side clear matches it, and a
    mismatch dropped every later retired layer on the track), and the
    count-in grace abort takes the same path; the repository keeps
    unconfirmed frozen members apart from the clear-all group and drops one
    whose capture held nothing instead of ending the group; the restart
    replay of the looper mode is armed as a request so the first report
    after a start cannot overwrite the remembered mod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
    [engine_private.h]
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2026-09-10 fix(engine): seven defects an adversarial review round confirmed
    Free and Song now put the shared master dormant whether or not anything is
    recorded. Undo-to-empty deliberately keeps the master so redo can restore
    through it, so an empty-looking rig still carries a live clock; the mode
    switch returned before the reset, and the next Free take was rounded up to
    the erased take's length and played on its clock instead of its own. The
    grid the master measured goes with it, as it does at a clear; the tempo and
    its source survive.
    The mode gate measures what the audio thread will find. A restore that is
    posted and not yet applied does not publish its length, so the gate read the
    track as empty an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
    [engine_private.h]
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

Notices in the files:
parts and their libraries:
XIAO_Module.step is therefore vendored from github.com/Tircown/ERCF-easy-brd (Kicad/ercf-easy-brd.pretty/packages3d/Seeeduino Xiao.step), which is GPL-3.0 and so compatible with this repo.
